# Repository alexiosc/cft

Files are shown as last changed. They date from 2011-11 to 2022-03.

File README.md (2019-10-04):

CFT Logo

# The CFT Home-Brew 16-bit Mini-Computer

The CFT is a home-designed, home-built mini-computer made from
scratch.

I've designed and built the instruction set, data path, processor,
computer, software stack, cross-assembler, emulator, software
toolchain and even some of the tools needed to do all this. You can
call this a ‘fantasy mini’.

This project has been going since approximately 2001, in my Copious
Free Time.

## Audience

There isn't one, so I couldn't tell you what it's like. This project
has been online since 2005 and it's been noticed by four or five
people. Not quite enough for statistics.

**This is a personal project, and the repository is made public as a
curiosity. Expect everything to be wrong, broken, or dangerous.**

## Why?

Because it's fun.

To see how it's done.

To recall Those Heady Times.

To prove to myself I can do this.

## What?

The CFT is a long-term project built in my Copious Free Time. (a term used, as
always, sarcastically, hence the name) It's a homebrew, self-designed,
self-built Sixties-style 16-bit mini computer built out of 74-family integrated
circuits. Check out the
[ChangeLog](https://github.com/alexiosc/cft/blob/master/Changelog) for the
current status.

There may possibly be more stuff to look at, at https://www.bedroomlan.org/cft.

The project consists of:

* The CFT processor.
* Peripherals and cards, some implementing extensions to the CFT instruction set.
* A front panel with blinkenlights.
* A case for the lot.
* Documentation for everything, including the website and this.
* A cross-toolchain for working on the computer from a PC.

### The CFT Processor

* A 4 MHz clock. (250ns processor cycle)
* 16-bit word length. No byte access.
* 24-bit memory address bus.
* 16-bit I/O bus shared with the address bus. (the lower 1,024 addresses are easier to use)
* All instructions are exactly one 16-bit word long.
* Some instructions follow the PDP-8 ‘microcoded’ format with bitfields cotrolling combinations of actions. Bitwise negation, two's complement negation and incrementation are the same instruction with slightly different options.
* A relatively simple instruction set inspired by the PDP-8. This has moved on
  to something slightly more reminiscent of a modern processor.
* Microcoded design.
* Accumulator based architecture.
* Four user-accessible 16-bit registers with increment and decrement. Only the
  Accumulator (AC) is general purpose.
* PDP-8 style magic addresses working like auto-increment or auto-decrement
  index registers, or stack pointers.

### Peripherals

I originally sat down with Eagle CAD and went *crazy* with it. I had 50 sheets
of schematics for boards, all with a three-letter designator:

* MEM: A memory board with 512 KWords of RAM and 512 KWords of ROM.
* TTY: A quadruple serial board including both DCE and DTE
  connections, and a TTL one for an FTDI USB adaptor.
* INT: 8-interrupt controller board.
* IDE: Twin IDE bus interface for up to four drives.
* RTC: A real-time card with some NVRAM and three or six programmable timers.
* ETH: An offloaded Ethernet interface using the WIZ812 chip.
* KBD: A PS/2 Keyboard interface in pure discrete logic.
* PSG: A sound board with one or two AY-3-8910 chips and a SpeakJet® speech synthesiser.
* PFP: A Programmer's Front Panel capable of debugging microcode as well as full machine code.
* DEB: A DEBugging card to help diagnose problems with the hardware
  using a remote controller. (this was basically a simple, slow, specialised logic analyser)
* FDC: A Floppy Drive Controller for up to four drives, including 8-inch 50-pin ones.
* GIO: General Purpose I/O board including some digital I/O, two
  Atari-style digital joystick ports, a unidirectional parallel
  printer port, four user-controllable LEDs on the front panel (the
  PFP already had 16) and (on a whim) a cassette tape interface.
* MBU: processor extension to allow 21-bit memory addressing (up to 2 MWords).
* µCB: processor extension to allow multiple versions of microcode to co-exist. (I had spare space in the Microcode ROMs)
* VDU: a graphics card that does text at 80×25 and 40×25, and graphics
  at combinations of 160, 320, 640 columns and 100, 200, 400 rows with
  64 colours.

The currently planned peripherals are much more modest in scope, but
they also morphed quite a bit. The processor can now do 24-bit
addressing natively, the current microcode uses all of the available
ROM space and a bunch of cards have joined forces. The current state
of affairs looks like this:

* MEM: (tentative design) 512 kWords or 1 MWord of RAM, 512 KWords of
  ROM. Multiple cards can be installed. If density allows, there'll be
  more chip sockets for RAM.
* INT: 8 interrupt controller board.
* DFP: a big card containing both a remote debugging system and front panel drivers.
* TTY: serial port card, possibly colocated with…
* IDE: one or two IDE sockets for two or four IDE drives. (or CF
  cards, but I like the possibility of having some clunky old drive)
* SND: MIDI sound output. Possibly collocated with…
* VDU: a graphics card that does text at 80×30 and 40×30, and graphics
  at combinations of 160, 320, 640 columns and 120, 240, 480 rows
  using 64 colours. The new VDU card fits inside a CPLD and also
  includes a PS/2 interface.
* RTC: Real-time clock, timers.

I've built the MEM and DFP boards to pre-2019 specs and the computer was
working on them.

The 2019 redesign goes for proper PCBs for everything, so things are
taking a little extra time.

### Front Panel

I was really proud of the front panel before the 2019 redesign, it
worked great and showed the computer's entire status. There's support
for up to 160 lights, 31 switches and two keylocks for that PDP-8
feel.

The downside was the wiring: there were no fewer than *five* 50-wire
ribbon cables going to this crazy bastard.

The 2019 redesign keeps the layout, but can no longer display as much
of the computer's status on the front panel. I'm working on it. On the
upside, it now serialises data transmission and only a single 40-pin
cable is needed.

To cut costs, the original front panel was made out of eight modules,
each with up to 20 LEDs. The new front panel is made out of four
modules, each with up to 40 LEDs. Each module daisy-chains to the
next.

Switches are mounted on a separate plate and wired to a break-out
board, or the closest front panel modules on the 2019 version.

### The Case

Two words: wood paneling. Well, and a black acrylic front piece. The
rest will depend on how big the card cage gets, but I'll scratch make
the case out of sheet aluminium and wood.

### Documentation

There's just too much of it. The documentation was initially in LaTeX
and got up to 500 pages before I gave that up and started converting
it to HTML.

The 2019 redesign will need a redo of most of this, sadly, but the
current documents for hardware that's currently around are available
at https://www.bedroomlan.org/hardware/cft/book/.

### Software and Hardware Tools

I had to make my own tools for some of this, and *wanted* to make my
own for some other parts.

Hardware tools include
[Flashprog](https://www.bedroomlan.org/hardware/flashprog/), a
zero-parts flash programmer with a modern serial interface. The
interface formed the basis of the DEB and DFP cards' remote debugging
interface and I'm quite happy with it.

Software tools include:

*  The [Microcode Assembler](https://www.bedroomlan.org/projects/mcasm/),
   also available on Github as https://github.com/alexiosc/mcasm.
*  The CFT Assembler, written purely in Python and roughly based on
   PDP-8 Assemblers, but with some modern extras like namespaces and
   simple macros.
*  Too many emulators to speak of!
   * A basic microcode-level emulator in Python to verify the original
          design. This one is dead and buried, but still in the repository.
   * A Verilog emulator used to verify the hardware.
   * A C emulator that's fast enough to run software on.
   * A [Javascript microcode-level emulator](https://www.bedroomlan.org/hardware/cft/microcode-emulator/)
          that runs on the web. It's very slow, but it shows how the front
          panel works.
   * A newer JS-based emulator meant to me much faster. Still
          largely in the works, because I prefer the C-based emulator for
          testing.
* A testing framework that can run test suites on any emulator we can use.
* A basic Operating System for the CFT.
* A self-documenting Forth interpreter written in Assembly and Forth.

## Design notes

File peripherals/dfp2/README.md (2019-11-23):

# DFP: Debugging Front Panel Version 2

This is the DFP 2, a combination of the Debugging Board (DEB) and
Programmer's Front Panel Board (PFP). It provides two-way bridging
between:

1. The CFT Computer or *parts* of the computer.
2. The Front Panel.
3. A remote computer (or human) performing tests and diagnostics.

The third component is optional.



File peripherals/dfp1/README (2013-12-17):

CFT COMBINATION FRONT PANEL AND REMOTE DEBUGGING / TESTING BOARD

==NAME/DESIGNATION==

To be decided.

==FEATURES==

The PFP combines and acts on instructions coming from three sources:

* The front panel switches.
* The debugging serial port.
* The CFT processor itself.

There are two modes of operation:

* Processor mode: the processor is present and is mostly used as the
  bus master by driving its control signals directly.

* Standalone mode: the processor is absent. The board drives the
  address and data buses directly.

==STATE==

===Power On State===

* Start on power on?
  - If FPRAM# switch in RAM position, start halted
  - Otherwise, start running

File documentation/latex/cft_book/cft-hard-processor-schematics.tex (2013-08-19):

The following page shows the full schematic drawings of the three processor boards.

\cleardoublepage
\phantomsection\stepcounter{section}%
\addcontentsline{toc}{section}{\protect\numberline{\thesection} Processor Board A Schematics}

\includeschns{2}{Clock Generation and control}{sch:clock}
\includeschns{3}{Reset Handling and Sequencing}{sch:reset}
\includeschns{4}{Microcode Sequencer}{sch:useq}
\includeschns{5}{Microcode Sequencer Signal Hold}{sch:useq-hold}
\includeschns{7}{Read and Write Unit Decoding}{sch:unit-decoders}
\includeschns{8}{Skip and Branch Logic}{sch:sbu}
\includeschns{9}{Address Generation Logic}{sch:agl}
\includeschns{10}{Instruction Register}{sch:ir}
\includeschns{11}{Interrupt State Machine}{sch:intsm}
\includeschns{12}{Data Bus Driver and Bus Termination}{sch:databus}
\includeschns{6}{Microcode Sequencer Front Panel Buffers and Connectors}{sch:useq-fp}

\phantomsection\stepcounter{section}%
\addcontentsline{toc}{section}{\protect\numberline{\thesection} Processor Board B Schematics}

\includeschns{13}{Address Register, Address Bus Drivers \& Termination, Autoindex Logic and Device Decoder}{sch:ar}
\includeschns{14}{Program Counter}{sch:pc}
\includeschns{15}{Data Register}{sch:dr}
\includeschns{16}{Accumulator, Zero Flag and Negative Flag}{sch:ac}

\phantomsection\stepcounter{section}%
\addcontentsline{toc}{section}{\protect\numberline{\thesection} Processor Board C Schematics}

\includeschns{17}{Link Register}{sch:l}
\includeschns{18}{Arithmetic/Logic Unit: Decoders and Buffers}{sch:aludecoder}
\includeschns{19}{ALU Binary Operators}{sch:alub}
\includeschns{20}{ALU Unary Operators and Constant Store}{sch:aluu}
\includeschns{21}{8 kW Bank Switching Memory Controller}{sch:mbu}

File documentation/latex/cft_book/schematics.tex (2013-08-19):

This chapter collects the full CFT schematics, in their latest
revision, including all peripherals. Please note that many schematics
are in various stages of incompleteness.

The state of each sheet of the schematics, including other details can
be found according to the key on the first sheet:

\begin{figure}[h!]
  \centering
  
  \caption{\label{fig:schematic-legend}Schematic legend, explaining
    various markings and notation.}
\end{figure}

\newpage

\phantomsection\stepcounter{section}%
\addcontentsline{toc}{section}{\protect\numberline{\thesection} Processor Board A Schematics}

%% %\includesch{1}{Schematic cover page}{sch2:cover}
%% \includesch{2}{Clock Generation and control}{sch2:clock}
%% \includesch{3}{Reset Handling and Sequencing}{sch2:reset}
%% \includesch{4}{Microcode Sequencer}{sch2:useq}
%% \includesch{5}{Microcode Sequencer Signal Hold}{sch2:useq-hold}
%% \includesch{6}{Microcode Sequencer Front Panel Buffers}{sch2:useq-fp}
%% \includesch{7}{Read and Write Unit Decoding}{sch2:unit-decoders}
%% \includesch{8}{Skip and Branch Logic}{sch2:sbu}
%% \includesch{9}{Address Generation Logic}{sch2:agl}
%% \includesch{10}{Instruction Register}{sch2:ir}
%% \includesch{11}{Interrupt State Machine}{sch2:intsm}
%% \includesch{12}{Data Bus Driver and Bus Termination}{sch2:databus}

\phantomsection\stepcounter{section}%
\addcontentsline{toc}{section}{\protect\numberline{\thesection} Processor Board B Schematics}

%% \includesch{13}{Address Register, Address Bus Drivers \& Termination, Autoindex Logic and Device Decoder}{sch2:ar}
%% \includesch{14}{Program Counter}{sch2:pc}
%% \includesch{15}{Data Register}{sch2:dr}
%% \includesch{16}{Accumulator, Zero Flag and Negative Flag}{sch2:ac}

\phantomsection\stepcounter{section}%
\addcontentsline{toc}{section}{\protect\numberline{\thesection} Processor Board C Schematics}

%% \includesch{17}{Link Register}{sch2:l}
%% \includesch{18}{Arithmetic/Logic Unit: Decoders and Buffers}{sch2:aludecoder}
%% \includesch{19}{ALU Binary Operators}{sch2:alub}
%% \includesch{20}{ALU Unary Operators and Constant Store}{sch2:aluu}
%% \includesch{21}{8 kW Bank Switching Memory Controller}{sch2:mbu}

\phantomsection\stepcounter{section}%
\addcontentsline{toc}{section}{\protect\numberline{\thesection} Peripheral Schematics}

\includesch{22}{Interrupt Controller}{sch2:intc}
\includesch{23}{Control Bus Connectors}{sch2:cbus}
%%%\includesch{24}{Memory (RAM and ROM)}{sch2:memory}
\includesch{25}{RS-232 and TTL Serial Ports}{sch2:tty}
\includesch{26}{IDE Bus Interface}{sch2:ide}
\includesch{27}{Clock, Timers and NVRAM}{sch2:rtc}
\includesch{28}{Ethernet Interface}{sch2:eth}
\includesch{29}{PS/2 Keyboard Controller}{sch2:kbd}
\includesch{30}{Audio Device, bus interface and SpeakJet™}{sch2:sjs}
\includesch{31}{Audio Device, AY-3-8910 PSG}{sch2:psg}
%%%\includesch{42}{Debugging Board}{sch2:deb}

\phantomsection\stepcounter{section}%
\addcontentsline{toc}{section}{\protect\numberline{\thesection} Front Panel Schematics}

\includesch{32}{Front Panel: LEDs}{sch2:fp-leds}
\includesch{33}{Front Panel: Switch Register and Switches}{sch2:fp-switches}
%\includesch{34}{Front Panel: Switch Register and Switches}{sch2:fp-switches2}
\includesch{35}{Front Panel: Step switch auto-repeat}{sch2:fp-step-autorepeat}
%\includesch{36}{Front Panel: Switch Register and Switches}{sch2:fp-switches3}
%\includesch{37}{Front Panel: LEDs}{sch2:fp-leds2a}
\includesch{38}{Front Panel: Multi-Function Display Buffers}{sch2:fp-mfd}
\includesch{39}{Front Panel: Interrupt LED}{sch2:fp-irq-led-delay}
\includesch{40}{Front Panel: Connectors}{sch2:fp-con}
\includesch{41}{Front Panel: System Device}{sch2:pfp}

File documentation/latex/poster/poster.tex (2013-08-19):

% -*- latex -*-
\documentclass[12pt,a4paper]{article}
\usepackage[a4paper,CJKbookmarks,bookmarks=true,bookmarksopen=true,pdfpagelabels,pdfstartpage=1]{hyperref}
\usepackage{pdftricks}
\usepackage{pdfpages}
\usepackage{ifthen}
\usepackage[includefoot]{geometry}
\usepackage{color}
\usepackage[absolute]{textpos}
\usepackage{fontspec}
\usepackage{layout}
\usepackage{calc}
\usepackage{rotating}
\usepackage{tikz}
\usetikzlibrary{arrows,positioning,automata,shadows,fit,shapes}
\usepackage{tikz-timing}[2009/07/28]
\usetikztiminglibrary{either}[2009/07/28]
\tikzset{timing/z/.append style={black},}
\tikzset{timing/.append style={x=1ex, y=2ex, line cap=round, line join=round, line width=1.3pt}}
\tikzset{timing/slope=0.33}
%\usepackage[tocindentauto]{tocstyle}

%\usepackage[cam,a4,center]{crop}

\definecolor{r0}{rgb}{0.33, 0.1, 0.1}
\definecolor{r1}{rgb}{1, 0.3, 0.3}

\definecolor{g0}{rgb}{0.1, 0.33, 0.1}
\definecolor{g1}{rgb}{0.3, 1, 0.3}

\definecolor{cftdark}{cmyk}{0,0.42,0.72,0.84}
\definecolor{cftoutline}{cmyk}{0,0.43,0.72,0.53}
\definecolor{cftlight}{cmyk}{0,0.43,0.72,0.22}
\definecolor{cfthl}{rgb}{.89,.698,.529}
\newcommand{\zebrarow}[1]{\rowcolors{#1}{cfthl!50}{cfthl!25}}
\newcommand\zebra{\zebrarow{2}}
\newcommand\zebrahdr{\zebrarow{1}}
%\newcommand\zebra*[1]{\rowcolors{#1}{gray!10}{white}}

\definecolor{darkblue}{RGB}{0,0,128}
\hypersetup{
    pdftitle={CFT Minicomputer Programming Guide},
    pdfauthor={Alexios Chouchoulas},
    pdfkeywords={},
    bookmarksnumbered,
    pagebackref=true,
    breaklinks=true,
%    pdfview=FitH,       % Or try pdfstartview={FitV}, This lead to uncorrect bookmarks
    urlcolor=darkblue,
    colorlinks=true,
    citecolor=cftoutline,          %citeref's color
    linkcolor=cftoutline,
        }

\geometry{a4paper, landscape, hoffset=0in, left=0mm, right=0mm,
  top=0mm, bottom=0mm, includefoot, footskip=0pt}

\setmainfont{Minion Pro}
\setsansfont{Myriad Pro}
\setmonofont[]{Inconsolata}

\begin{document}
\thispagestyle{empty}
\pagestyle{empty}

\definecolor{cff0000}{RGB}{255,0,0}
\definecolor{bgcolor}{RGB}{64, 64, 64}
\definecolor{ltcolor}{RGB}{128, 128, 128}
\definecolor{shcolor}{RGB}{0, 0, 0}
\color{ltcolor}
\sf

\newcommand\shadowtext[2]{%
  \foreach \n in {0,...,5}{
    \begin{scope}[xshift=1 * \n pt, yshift=-1 * \n pt, opacity=0.5 - 0.1 * \n]
      \node[#1]{#2};
    \end{scope}
  }
  \node[#1]{#2};
}

\begin{tikzpicture}[remember picture,overlay]
  \node[yshift=-\paperheight, draw opacity=0] at (current page.north west)
       {\begin{tikzpicture}[remember picture, overlay]
           \draw[fill=bgcolor] (0,0) rectangle
           (\paperwidth,\paperheight);
           \node[anchor=north west, xshift=0.05\textwidth,yshift=0.9\textheight]
                {};
                %
           \shadowtext{xshift=0.5\textwidth, yshift=0.5\textheight}{%
             \scalebox{2}{\Large\rm The CFT Project in Numbers}}
%           \shadowtext{xshift=0.5\textwidth, yshift=0.5\textwidth}{%
%             \scalebox{2}{\Large\rm\color{red}{The CFT Project in Numbers}}}

                %% \draw[fill=cftoutline] (0,1cm) rectangle
                %% (\paperwidth,0);
                %% \node[anchor=east,yshift=0.5\paperheight,xshift=.87\paperwidth,rectangle]
                %%      {\scalebox{2}{\color{white}foo bar}};
                %%      \node[anchor=east,yshift=0.43\paperheight,xshift=.87\paperwidth,rectangle]
                %%           {\scalebox{1.5}{\color{white} bar}};
         \end{tikzpicture}
       };
\end{tikzpicture}

\end{document}

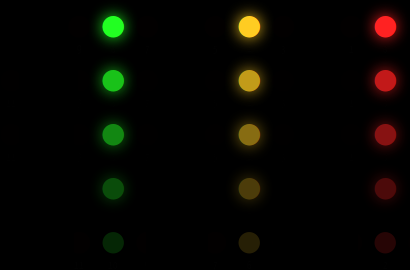
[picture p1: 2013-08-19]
js/v2/images/leds.png

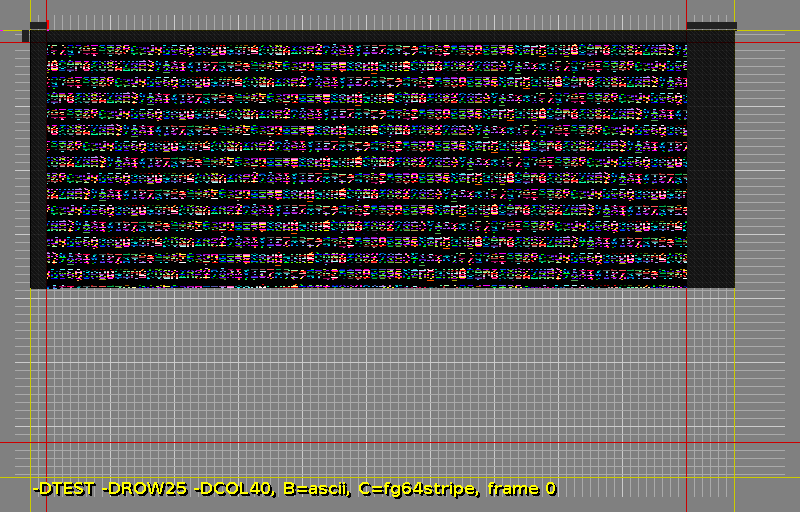
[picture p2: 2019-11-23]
peripherals/vdu/verilog/vdu-0.bmp

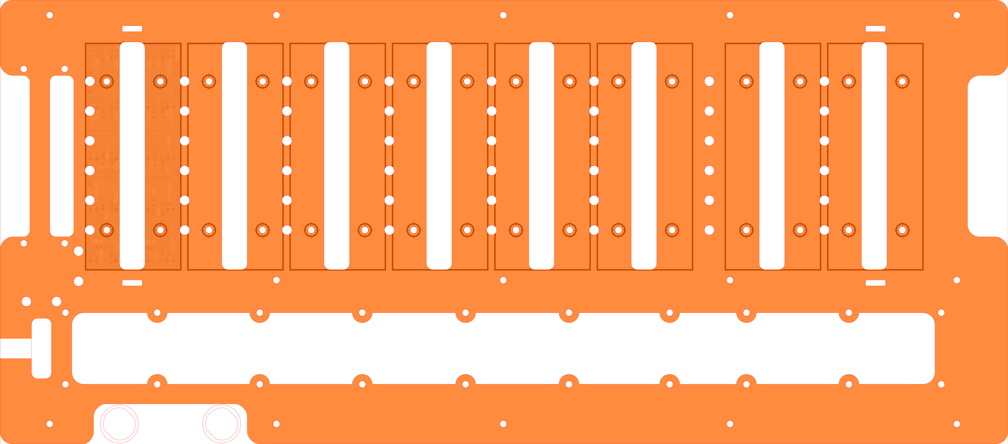
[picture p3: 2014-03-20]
documentation/case/textures/use38783.png

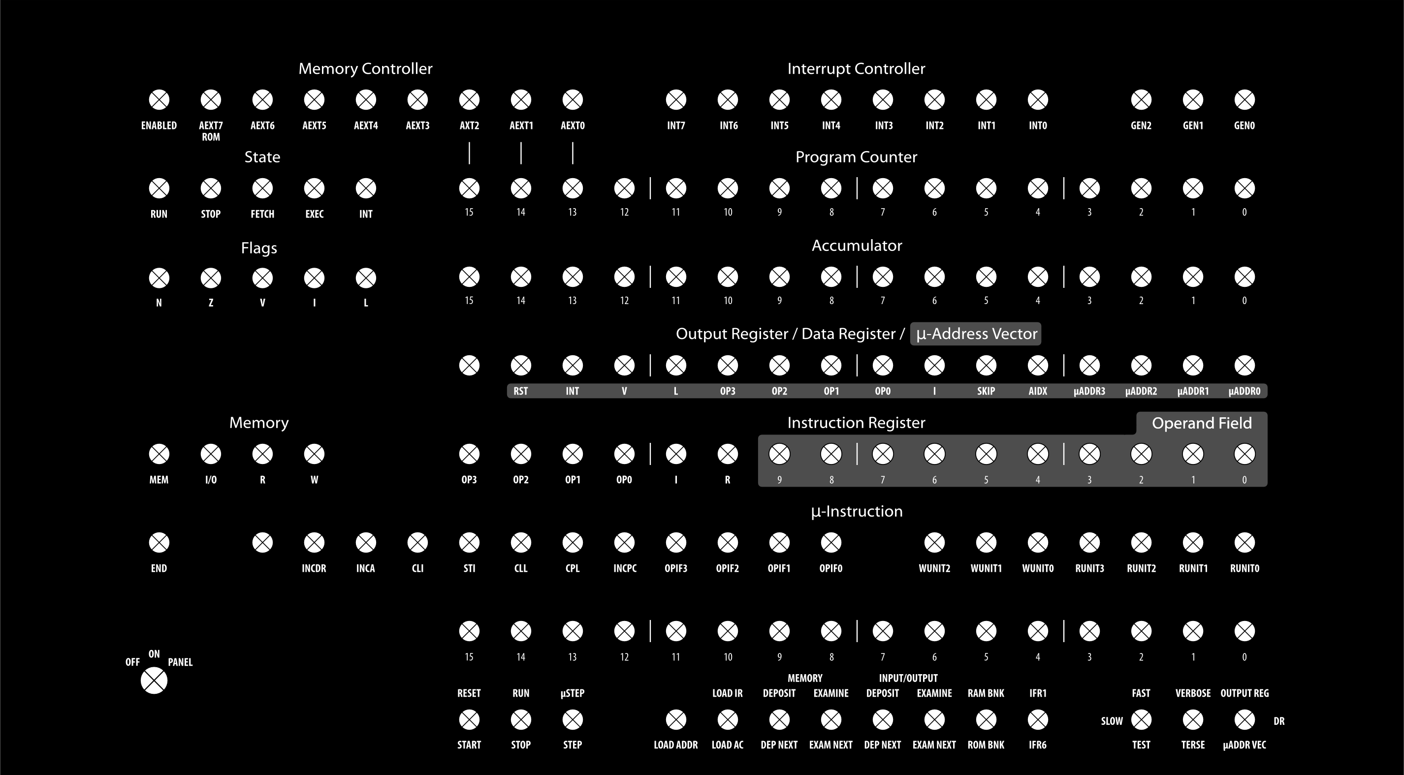
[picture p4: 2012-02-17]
documentation/panel/front-panel-no-lights.png

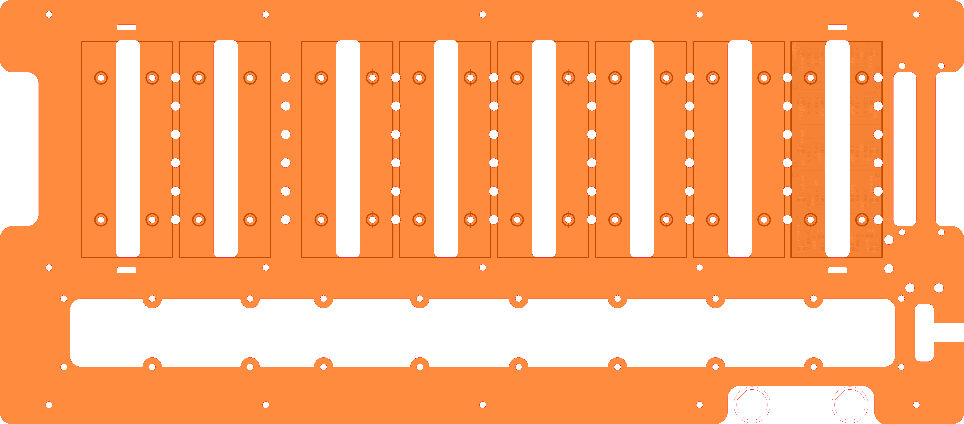
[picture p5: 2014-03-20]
documentation/case/textures/use38783-flipped.png

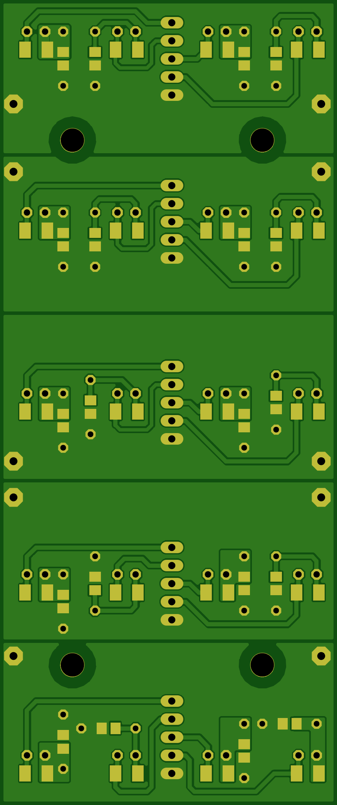
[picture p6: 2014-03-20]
documentation/case/textures/front-panel-module-revC-bottom.png

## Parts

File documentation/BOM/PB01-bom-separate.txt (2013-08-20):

Partlist exported from /home/alexios/eagle/CFT/CFT-PB0-revE-TSSOP.sch at 20 Aug 2013 00:50:35

Qty Value              Device             Parts
-28  0.1uF              C-EUC0805K        
-9   1uF                C-EUC0805K         C4, C8, C10, C15, C23, C32, C35, C36, C37
-17  4k7                R-EU_R0805         R1, R2, R5, R6, R8, R9, R10, R11, R14, R15, R16, R17, R18, R19, R20, R21, R22
-3   29F040             29F040PLCC32       IC4, IC6, IC7
-5   30R                R-EU_R0805         R3, R4, R7, R12, R13
-3   74AC16244DGG       74AC16244DGG       IC20, IC21, IC22
-2   74AHC1G32DBV       74AHC1G32DBV       IC1, IC13
-1   74HC74D            74HC74D            IC17
-3   74HC138D           74HC138D           IC9, IC10, IC14
-1   74HC157D           74HC157/ALT-D      IC18
-3   74HC175D           74HC175D           IC15, IC16, IC19
-2   74HC541DW          74HC541DW          IC11, IC12
-3   2540-5             2540-5             P1, P2, P3
-1   SN74ACT1071D       SN74ACT1071D       IC26
-3   SN74ACT1073        SN74ACT1073        IC23, IC24, IC25

2   47uF               CPOL-EUE2.5-5      667-ECE-A1AKG470

1                      VG96-3K            EXP
3   4k7                CTS742C083         RN12, RN13, RN14
6   10k                CTS742C083         RN16, RN17, RN18, RN19, RN20, RN21
12  30R                CTS742C083         RN1, RN2, RN3, RN4, RN5, RN6, RN7, RN8, RN9, RN10, RN11, RN15
1   74AHC1G00DBV       74AHC1G00DBV       IC5
1   74AHC1G04DBV       74AHC1G04DBV       IC8
1   74AHC1G08DBV       74AHC1G08DBV       IC2
1   74HC161D           74HC161D           IC3

Partlist exported from /home/alexios/eagle/CFT/CFT-PB1-revD-TSSOP.sch at 20 Aug 2013 00:50:49

Qty Value         Device          Parts
-37  0.1uF         C-EUC0805K      C1, C2, C3, C5, C6, C7, ...
-8   1uF           C-EUC0805K      C4, C9, C12, C30, C34, C39, C45, C54
-9   4k7           R-EU_R0805      R1, R2, R4, R5, R11, R12, R13, R40, R48
-1   16.000MHz     XO-08-SOCKET    XTAL1
-3   30R           R-EU_R0805      R14, R41, R51
-3   74AC1G11DBV   74AC1G11DBV     IC20, IC34, IC39
-2   74AHC1G32DBV  74AHC1G32DBV    IC30, IC32
-6   74HC541DW     74HC541DW       IC6, IC7, IC8, IC23, IC24, IC27
-3   2540-5        2540-5          P1, P2, P3
-2   SN74ACT1071D  SN74ACT1071D    IC41, IC42

1                  DIP8 socket   
1   1uF-47uF      CPOL-EUE2.5-5   667-ECE-A1AKG470
2   47uF          CPOL-EUE2.5-5   667-ECE-A1AKG470

3  1N4148         DIODE-SOD123    D1, D2, D3
1                 TAC_SWITCHPTH   611-PTS645SL43LFS
1                 VG96-3K         EXP1
2   4k7           CTS742C083      RN1, RN19
1   50k           R-EU_R0805      R9
1   74AC1G27DBV   74AC1G27DBV     IC38
2   74AC04D       74AC04D         IC9, IC37
1   74AHC1G04DBV  74AHC1G04DBV    IC17
1   74AHC1G08DBV  74AHC1G08DBV    IC29
1   74AHC1G14DBV  74AHC1G14DBV    IC4
1   74AHC1G86DBV  74AHC1G86DBV    IC15
1   74HC08D       74HC08D         IC13
2   74HC32D       74HC32D         IC14, IC16
3   74HC74D       74HC74D         IC21, IC33, IC40
1   74HC112D      74HC112D        IC31
1   74HC139D      74HC139D        IC3
1   74HC193D      74HC193D        IC2
2   74HC245DW     74HC245DW       IC35, IC36
2   74HC251D      74HC251D        IC18, IC19
1   74HC253D      74HC253D        IC1
2   74HC573D      74HC573D        IC25, IC26
1   74HC574D      74HC574D        IC22
1   74HC590D      74HC590D        IC5
4   330R          R-EU_R0805      R3, R10, R49, R50
4   LED-5MM-GREEN LEDCHIPLED_0805 LED1, LED2, LED3, LED4

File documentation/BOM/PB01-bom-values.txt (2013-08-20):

-65  0.1uF         C-EUC0805K      C1, C2, C3, C5, C6, C7, ...
-17  1uF           C-EUC0805K      C4, C9, C12, C30, C34, C39, C45, C54
-26  4k7           R-EU_R0805      R1, R2, R4, R5, R11, R12, R13, R40, R48
-1   16.000MHz     XO-08-SOCKET    XTAL1
-3   30R           R-EU_R0805      R14, R41, R51
-3   74AC1G11DBV   74AC1G11DBV     IC20, IC34, IC39
-4   74AHC1G32DBV  74AHC1G32DBV    IC30, IC32
-8   74HC541DW     74HC541DW       IC6, IC7, IC8, IC23, IC24, IC27
-6   2540-5        2540-5          P1, P2, P3
-3   SN74ACT1071D  SN74ACT1071D    IC41, IC42
-3   SN74ACT1073        SN74ACT1073        IC23, IC24, IC25

-3   29F040             29F040PLCC32       IC4, IC6, IC7
-5   30R                R-EU_R0805         R3, R4, R7, R12, R13
-3   74AC16244DGG       74AC16244DGG       IC20, IC21, IC22
-4   74HC74D            74HC74D            IC17
-3   74HC138D           74HC138D           IC9, IC10, IC14
-1   74HC157D           74HC157/ALT-D      IC18
-3   74HC175D           74HC175D           IC15, IC16, IC19

-------------------------------------------------------------------------------

1  +5   1uF-47uF      CPOL-EUE2.5-5   667-ECE-A1AKG470
     47uF          CPOL-EUE2.5-5   667-ECE-A1AKG470
     47uF          CPOL-EUE2.5-5   667-ECE-A1AKG470
2  +2                 VG96-3K         EXP
3  +5   4k7                CTS742C083         RN12, RN13, RN14
4  +6   10k                CTS742C083         RN16, RN17, RN18, RN19, RN20, RN21
5  +12  30R                CTS742C083         *** 33R
6  +4   330R          R-EU_R0805      R3, R10, R49, R50
7  +4   LED-5MM-GREEN LEDCHIPLED_0805 LED1, LED2, LED3, LED4
8  +3  1N4148         DIODE-SOD123    D1, D2, D3
9  +1                  DIP8 socket   
10 +1   74AHC1G00DBV       74AHC1G00DBV       *** LVC
11 +2   74AHC1G04DBV       74AHC1G04DBV       IC8
12 +2   74AHC1G08DBV       74AHC1G08DBV       IC2
13 +1   74HC161D           74HC161D           IC3
14 +1                 TAC_SWITCHPTH   611-PTS645SL43LFS
15 +1   50k           R-EU_R0805      ** 47k
16 +1   74AC1G27DBV   74AC1G27DBV     IC38
17 +2   74AC04D       74AC04D         IC9, IC37
18 +1   74AHC1G14DBV  74AHC1G14DBV    IC4
19 +1   74AHC1G86DBV  74AHC1G86DBV    IC15
20 +1   74HC08D       74HC08D         IC13
21 +2   74HC32D       74HC32D         IC14, IC16
22 +1   74HC112D      74HC112D        IC31
23 +1   74HC139D      74HC139D        IC3
24 +1   74HC193D      74HC193D        IC2
25 +2   74HC245DW     74HC245DW       IC35, IC36
26 +2   74HC251D      74HC251D        IC18, IC19
27 +1   74HC253D      74HC253D        IC1
28 +2   74HC573D      74HC573D        IC25, IC26
29 +1   74HC574D      74HC574D        IC22
30 +1   74HC590D      74HC590D        IC5

com 12  vkdg olympic isogeia ikea  8-13

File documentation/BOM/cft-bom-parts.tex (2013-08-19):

\schpt{C1}–\schpt{C3} & 0.1μF ceramic capacitor & Farnell US 1694337 (£0.019@100), RS 721-5240 (£0.051@50), Farnell 1694337 (£0.019@100) &  \\
\schpt{C4} & 10 µF electrolytic capacitor & Farnell 1902928 (£0.033), RS 440-6547 (£0.026@50) &  \\
\schpt{C5} & 0.1μF ceramic capacitor & Farnell US 1694337 (£0.019@100), RS 721-5240 (£0.051@50), Farnell 1694337 (£0.019@100) &  \\
\schpt{C6} & 10nF Ceramic Capacitor & Farnell US 1694335 (£0.016@10), Farnell 9411852 (£0.059@25) &  \\
\schpt{C7} & 1μF capacitor & Farnell US 1600879 (£0.041@25), Farnell 3322210 (£0.148), RS 538-1578 (£0.292), Farnell 1100398 (£0.38) &  \\
\schpt{C8} & 0.1μF ceramic capacitor & Farnell US 1694337 (£0.019@100), RS 721-5240 (£0.051@50), Farnell 1694337 (£0.019@100) &  \\
\schpt{C9} & 10 µF electrolytic capacitor & Farnell 1902928 (£0.033), RS 440-6547 (£0.026@50) &  \\
\schpt{C10} & 10nF Ceramic Capacitor & Farnell US 1694335 (£0.016@10), Farnell 9411852 (£0.059@25) &  \\
\schpt{C11}–\schpt{C16} & 0.1μF ceramic capacitor & Farnell US 1694337 (£0.019@100), RS 721-5240 (£0.051@50), Farnell 1694337 (£0.019@100) &  \\
\schpt{C17} & 1μF capacitor & Farnell US 1600879 (£0.041@25), Farnell 3322210 (£0.148), RS 538-1578 (£0.292), Farnell 1100398 (£0.38) &  \\
\schpt{C18}–\schpt{C23} & 0.1μF ceramic capacitor & Farnell US 1694337 (£0.019@100), RS 721-5240 (£0.051@50), Farnell 1694337 (£0.019@100) &  \\
\schpt{C24}–\schpt{C27} & 1μF capacitor & Farnell US 1600879 (£0.041@25), Farnell 3322210 (£0.148), RS 538-1578 (£0.292), Farnell 1100398 (£0.38) &  \\
\schpt{C28}–\schpt{C31} & 0.1μF ceramic capacitor & Farnell US 1694337 (£0.019@100), RS 721-5240 (£0.051@50), Farnell 1694337 (£0.019@100) &  \\
\schpt{C32} & 1μF capacitor & Farnell US 1600879 (£0.041@25), Farnell 3322210 (£0.148), RS 538-1578 (£0.292), Farnell 1100398 (£0.38) &  \\
\schpt{C33}–\schpt{C40} & 0.1μF ceramic capacitor & Farnell US 1694337 (£0.019@100), RS 721-5240 (£0.051@50), Farnell 1694337 (£0.019@100) &  \\
\schpt{C41} & 1μF capacitor & Farnell US 1600879 (£0.041@25), Farnell 3322210 (£0.148), RS 538-1578 (£0.292), Farnell 1100398 (£0.38) &  \\
\schpt{C42}–\schpt{C44} & 0.1μF ceramic capacitor & Farnell US 1694337 (£0.019@100), RS 721-5240 (£0.051@50), Farnell 1694337 (£0.019@100) &  \\
\schpt{C45} & 1μF capacitor & Farnell US 1600879 (£0.041@25), Farnell 3322210 (£0.148), RS 538-1578 (£0.292), Farnell 1100398 (£0.38) &  \\
\schpt{C46}–\schpt{C49} & 0.1μF ceramic capacitor & Farnell US 1694337 (£0.019@100), RS 721-5240 (£0.051@50), Farnell 1694337 (£0.019@100) &  \\
\schpt{C50} & 1μF capacitor & Farnell US 1600879 (£0.041@25), Farnell 3322210 (£0.148), RS 538-1578 (£0.292), Farnell 1100398 (£0.38) &  \\
\schpt{C51}–\schpt{C55} & 0.1μF ceramic capacitor & Farnell US 1694337 (£0.019@100), RS 721-5240 (£0.051@50), Farnell 1694337 (£0.019@100) &  \\
\schpt{C56} & 1μF capacitor & Farnell US 1600879 (£0.041@25), Farnell 3322210 (£0.148), RS 538-1578 (£0.292), Farnell 1100398 (£0.38) &  \\
\schpt{C57}–\schpt{C61} & 0.1μF ceramic capacitor & Farnell US 1694337 (£0.019@100), RS 721-5240 (£0.051@50), Farnell 1694337 (£0.019@100) &  \\
\schpt{C62} & 1μF capacitor & Farnell US 1600879 (£0.041@25), Farnell 3322210 (£0.148), RS 538-1578 (£0.292), Farnell 1100398 (£0.38) &  \\
\schpt{C63}–\schpt{C71} & 0.1μF ceramic capacitor & Farnell US 1694337 (£0.019@100), RS 721-5240 (£0.051@50), Farnell 1694337 (£0.019@100) &  \\
\schpt{C72} & 1μF capacitor & Farnell US 1600879 (£0.041@25), Farnell 3322210 (£0.148), RS 538-1578 (£0.292), Farnell 1100398 (£0.38) &  \\
\schpt{C73}–\schpt{C80} & 0.1μF ceramic capacitor & Farnell US 1694337 (£0.019@100), RS 721-5240 (£0.051@50), Farnell 1694337 (£0.019@100) &  \\
\schpt{C81} & 1μF capacitor & Farnell US 1600879 (£0.041@25), Farnell 3322210 (£0.148), RS 538-1578 (£0.292), Farnell 1100398 (£0.38) &  \\
\schpt{C82}–\schpt{C89} & 0.1μF ceramic capacitor & Farnell US 1694337 (£0.019@100), RS 721-5240 (£0.051@50), Farnell 1694337 (£0.019@100) &  \\
\schpt{C90} & 1μF capacitor & Farnell US 1600879 (£0.041@25), Farnell 3322210 (£0.148), RS 538-1578 (£0.292), Farnell 1100398 (£0.38) &  \\
\schpt{C91}–\schpt{C100} & 0.1μF ceramic capacitor & Farnell US 1694337 (£0.019@100), RS 721-5240 (£0.051@50), Farnell 1694337 (£0.019@100) &  \\
\schpt{C101} & 1μF capacitor & Farnell US 1600879 (£0.041@25), Farnell 3322210 (£0.148), RS 538-1578 (£0.292), Farnell 1100398 (£0.38) &  \\
\schpt{C102}–\schpt{C105} & 0.1μF ceramic capacitor & Farnell US 1694337 (£0.019@100), RS 721-5240 (£0.051@50), Farnell 1694337 (£0.019@100) &  \\
\schpt{C106} & 1μF capacitor & Farnell US 1600879 (£0.041@25), Farnell 3322210 (£0.148), RS 538-1578 (£0.292), Farnell 1100398 (£0.38) &  \\
\schpt{C107}–\schpt{C110} & 0.1μF ceramic capacitor & Farnell US 1694337 (£0.019@100), RS 721-5240 (£0.051@50), Farnell 1694337 (£0.019@100) &  \\
\schpt{C111} & 1μF capacitor & Farnell US 1600879 (£0.041@25), Farnell 3322210 (£0.148), RS 538-1578 (£0.292), Farnell 1100398 (£0.38) &  \\
\schpt{C112}–\schpt{C116} & 0.1μF ceramic capacitor & Farnell US 1694337 (£0.019@100), RS 721-5240 (£0.051@50), Farnell 1694337 (£0.019@100) &  \\
\schpt{C117}–\schpt{C120} & 1μF capacitor & Farnell US 1600879 (£0.041@25), Farnell 3322210 (£0.148), RS 538-1578 (£0.292), Farnell 1100398 (£0.38) &  \\
\schpt{C121}–\schpt{C123} & 0.1μF ceramic capacitor & Farnell US 1694337 (£0.019@100), RS 721-5240 (£0.051@50), Farnell 1694337 (£0.019@100) &  \\
\schpt{C124}–\schpt{C127} & 1μF capacitor & Farnell US 1600879 (£0.041@25), Farnell 3322210 (£0.148), RS 538-1578 (£0.292), Farnell 1100398 (£0.38) &  \\
\schpt{C128}–\schpt{C142} & 0.1μF ceramic capacitor & Farnell US 1694337 (£0.019@100), RS 721-5240 (£0.051@50), Farnell 1694337 (£0.019@100) &  \\
\schpt{C143} & 1μF capacitor & Farnell US 1600879 (£0.041@25), Farnell 3322210 (£0.148), RS 538-1578 (£0.292), Farnell 1100398 (£0.38) &  \\
\schpt{C144}–\schpt{C155} & 0.1μF ceramic capacitor & Farnell US 1694337 (£0.019@100), RS 721-5240 (£0.051@50), Farnell 1694337 (£0.019@100) &  \\
\schpt{C156} & 1μF capacitor & Farnell US 1600879 (£0.041@25), Farnell 3322210 (£0.148), RS 538-1578 (£0.292), Farnell 1100398 (£0.38) &  \\
\schpt{C157}–\schpt{C162} & 0.1μF ceramic capacitor & Farnell US 1694337 (£0.019@100), RS 721-5240 (£0.051@50), Farnell 1694337 (£0.019@100) &  \\
\schpt{C163}–\schpt{C167} & 1μF capacitor & Farnell US 1600879 (£0.041@25), Farnell 3322210 (£0.148), RS 538-1578 (£0.292), Farnell 1100398 (£0.38) &  \\
\schpt{C168}–\schpt{C169} & 0.1μF ceramic capacitor & Farnell US 1694337 (£0.019@100), RS 721-5240 (£0.051@50), Farnell 1694337 (£0.019@100) &  \\
\schpt{C170} & 1μF capacitor & Farnell US 1600879 (£0.041@25), Farnell 3322210 (£0.148), RS 538-1578 (£0.292), Farnell 1100398 (£0.38) &  \\
\schpt{C171} & 0.1μF ceramic capacitor & Farnell US 1694337 (£0.019@100), RS 721-5240 (£0.051@50), Farnell 1694337 (£0.019@100) &  \\
\schpt{C172}–\schpt{C173} & 1μF capacitor & Farnell US 1600879 (£0.041@25), Farnell 3322210 (£0.148), RS 538-1578 (£0.292), Farnell 1100398 (£0.38) &  \\
\schpt{C174}–\schpt{C185} & 1 μF electrolytic capacitor & Farnell 1236655 (£0.034) & Through hole \\
\schpt{C186}–\schpt{C188} & 10 µF electrolytic capacitor & Farnell 1902928 (£0.033), RS 440-6547 (£0.026@50) &  \\
\schpt{C189}–\schpt{C193} & 0.1μF ceramic capacitor & Farnell US 1694337 (£0.019@100), RS 721-5240 (£0.051@50), Farnell 1694337 (£0.019@100) &  \\
\schpt{C194}–\schpt{C195} & 1μF capacitor & Farnell US 1600879 (£0.041@25), Farnell 3322210 (£0.148), RS 538-1578 (£0.292), Farnell 1100398 (£0.38) &  \\
\schpt{C196}–\schpt{C210} & 0.1μF ceramic capacitor & Farnell US 1694337 (£0.019@100), RS 721-5240 (£0.051@50), Farnell 1694337 (£0.019@100) &  \\
\schpt{C211}–\schpt{C212} & 22 pF ceramic capacitor & Farnell 9411674 (£0.035@25) &  \\
\schpt{C213} & 1μF capacitor & Farnell US 1600879 (£0.041@25), Farnell 3322210 (£0.148), RS 538-1578 (£0.292), Farnell 1100398 (£0.38) &  \\
\schpt{C214}–\schpt{C221} & 0.1μF ceramic capacitor & Farnell US 1694337 (£0.019@100), RS 721-5240 (£0.051@50), Farnell 1694337 (£0.019@100) &  \\
\schpt{C222} & 1μF capacitor & Farnell US 1600879 (£0.041@25), Farnell 3322210 (£0.148), RS 538-1578 (£0.292), Farnell 1100398 (£0.38) &  \\
\schpt{C223}–\schpt{C229} & 0.1μF ceramic capacitor & Farnell US 1694337 (£0.019@100), RS 721-5240 (£0.051@50), Farnell 1694337 (£0.019@100) &  \\
\schpt{C230} & 1μF capacitor & Farnell US 1600879 (£0.041@25), Farnell 3322210 (£0.148), RS 538-1578 (£0.292), Farnell 1100398 (£0.38) &  \\
\schpt{C231} & 10 µF electrolytic capacitor & Farnell 1902928 (£0.033), RS 440-6547 (£0.026@50) &  \\
\schpt{C232}–\schpt{C236} & 0.1μF ceramic capacitor & Farnell US 1694337 (£0.019@100), RS 721-5240 (£0.051@50), Farnell 1694337 (£0.019@100) &  \\
\schpt{C237} & 100nF electrolytic capacitor & Farnell 1902938 (£0.033@10) &  \\
\schpt{C238}–\schpt{C240} & 0.1μF ceramic capacitor & Farnell US 1694337 (£0.019@100), RS 721-5240 (£0.051@50), Farnell 1694337 (£0.019@100) &  \\
\schpt{C241} & 10nF Ceramic Capacitor & Farnell US 1694335 (£0.016@10), Farnell 9411852 (£0.059@25) &  \\
\schpt{C242}–\schpt{C243} & 0.1μF ceramic capacitor & Farnell US 1694337 (£0.019@100), RS 721-5240 (£0.051@50), Farnell 1694337 (£0.019@100) &  \\
\schpt{C244} & 1μF capacitor & Farnell US 1600879 (£0.041@25), Farnell 3322210 (£0.148), RS 538-1578 (£0.292), Farnell 1100398 (£0.38) &  \\
\schpt{C245}–\schpt{C248} & 0.1μF ceramic capacitor & Farnell US 1694337 (£0.019@100), RS 721-5240 (£0.051@50), Farnell 1694337 (£0.019@100) &  \\
\schpt{C249} & 10 µF electrolytic capacitor & Farnell 1902928 (£0.033), RS 440-6547 (£0.026@50) &  \\
\schpt{C250}–\schpt{C253} & 0.1μF ceramic capacitor & Farnell US 1694337 (£0.019@100), RS 721-5240 (£0.051@50), Farnell 1694337 (£0.019@100) &  \\
\schpt{C254} & 1μF capacitor & Farnell US 1600879 (£0.041@25), Farnell 3322210 (£0.148), RS 538-1578 (£0.292), Farnell 1100398 (£0.38) &  \\
\schpt{C255}–\schpt{C256} & 0.1μF ceramic capacitor & Farnell US 1694337 (£0.019@100), RS 721-5240 (£0.051@50), Farnell 1694337 (£0.019@100) &  \\
\schpt{C257}–\schpt{C258} & 1 μF electrolytic capacitor & Farnell 1236655 (£0.034) & Through hole \\
\schpt{C259}–\schpt{C260} & 0.1μF ceramic capacitor & Farnell US 1694337 (£0.019@100), RS 721-5240 (£0.051@50), Farnell 1694337 (£0.019@100) &  \\
\schpt{C261} & 10 µF electrolytic capacitor & Farnell 1902928 (£0.033), RS 440-6547 (£0.026@50) &  \\
\schpt{C262} & 47nF ceramic capacitor & Farnell 1100530 (£0.055@5) &  \\
\schpt{C263} & 220µF electrolytic capacitor & Farnell 1902883 (£0.042@10) &  \\
\schpt{C264}–\schpt{C265} & 0.1μF ceramic capacitor & Farnell US 1694337 (£0.019@100), RS 721-5240 (£0.051@50), Farnell 1694337 (£0.019@100) &  \\
\schpt{C266} & 10 µF electrolytic capacitor & Farnell 1902928 (£0.033), RS 440-6547 (£0.026@50) &  \\
\schpt{C267} & 47nF ceramic capacitor & Farnell 1100530 (£0.055@5) &  \\
\schpt{C268} & 220µF electrolytic capacitor & Farnell 1902883 (£0.042@10) &  \\
\schpt{C269}–\schpt{C272} & 0.1μF ceramic capacitor & Farnell US 1694337 (£0.019@100), RS 721-5240 (£0.051@50), Farnell 1694337 (£0.019@100) &  \\
\schpt{C273} & 1μF capacitor & Farnell US 1600879 (£0.041@25), Farnell 3322210 (£0.148), RS 538-1578 (£0.292), Farnell 1100398 (£0.38) &  \\
\schpt{C274}–\schpt{C277} & 1μF electrolytic capacitor & Farnell 1236655 (£0.034) &  \\
\schpt{C278}–\schpt{C279} & 1μF capacitor & Farnell US 1600879 (£0.041@25), Farnell 3322210 (£0.148), RS 538-1578 (£0.292), Farnell 1100398 (£0.38) &  \\
\schpt{C280} & 0.1μF ceramic capacitor & Farnell US 1694337 (£0.019@100), RS 721-5240 (£0.051@50), Farnell 1694337 (£0.019@100) &  \\
\schpt{C281}–\schpt{C282} & 47µF electrolytic capacitor & Farnell 1902909 (£0.041@10) &  \\
\schpt{C283}–\schpt{C285} & 0.1μF ceramic capacitor & Farnell US 1694337 (£0.019@100), RS 721-5240 (£0.051@50), Farnell 1694337 (£0.019@100) &  \\
\schpt{C286}–\schpt{C293} & 1μF electrolytic capacitor & Farnell 1236655 (£0.034) &  \\
\schpt{C294}–\schpt{C295} & 0.1μF ceramic capacitor & Farnell US 1694337 (£0.019@100), RS 721-5240 (£0.051@50), Farnell 1694337 (£0.019@100) &  \\
\schpt{C296}–\schpt{C299} & 1μF electrolytic capacitor & Farnell 1236655 (£0.034) &  \\
\schpt{C300}–\schpt{C302} & 0.1μF ceramic capacitor & Farnell US 1694337 (£0.019@100), RS 721-5240 (£0.051@50), Farnell 1694337 (£0.019@100) &  \\
\schpt{C303} & 1μF capacitor & Farnell US 1600879 (£0.041@25), Farnell 3322210 (£0.148), RS 538-1578 (£0.292), Farnell 1100398 (£0.38) &  \\
\schpt{C304} & 0.1μF ceramic capacitor & Farnell US 1694337 (£0.019@100), RS 721-5240 (£0.051@50), Farnell 1694337 (£0.019@100) &  \\
\schpt{C305} & 1 μF electrolytic capacitor & Farnell 1236655 (£0.034) & Through hole \\
\schpt{C306}–\schpt{C312} & 0.1μF ceramic capacitor & Farnell US 1694337 (£0.019@100), RS 721-5240 (£0.051@50), Farnell 1694337 (£0.019@100) &  \\
\schpt{C313} & 1μF capacitor & Farnell US 1600879 (£0.041@25), Farnell 3322210 (£0.148), RS 538-1578 (£0.292), Farnell 1100398 (£0.38) &  \\
\schpt{C314}–\schpt{C317} & 0.1μF ceramic capacitor & Farnell US 1694337 (£0.019@100), RS 721-5240 (£0.051@50), Farnell 1694337 (£0.019@100) &  \\
\schpt{C318} & 1μF capacitor & Farnell US 1600879 (£0.041@25), Farnell 3322210 (£0.148), RS 538-1578 (£0.292), Farnell 1100398 (£0.38) &  \\
\schpt{C319}–\schpt{C322} & 10nF Ceramic Capacitor & Farnell US 1694335 (£0.016@10), Farnell 9411852 (£0.059@25) &  \\
\schpt{C323}–\schpt{C326} & 1 μF electrolytic capacitor & Farnell 1236655 (£0.034) & Through hole \\
\schpt{C327}–\schpt{C330} & 10nF Ceramic Capacitor & Farnell US 1694335 (£0.016@10), Farnell 9411852 (£0.059@25) &  \\
\schpt{C331}–\schpt{C334} & 1 μF electrolytic capacitor & Farnell 1236655 (£0.034) & Through hole \\
\schpt{C335} & 10μF/10V Electrolytic capacitor & \href{http://uk.farnell.com/jsp/search/productdetail.jsp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\%2FglobalsearchE14.jsp}{Farnell 1902928} &  \\
\schpt{C336}–\schpt{C345} & 0.1μF ceramic capacitor & Farnell US 1694337 (£0.019@100), RS 721-5240 (£0.051@50), Farnell 1694337 (£0.019@100) &  \\
\schpt{C346} & 1μF capacitor & Farnell US 1600879 (£0.041@25), Farnell 3322210 (£0.148), RS 538-1578 (£0.292), Farnell 1100398 (£0.38) &  \\
\schpt{C347}–\schpt{C351} & 0.1μF ceramic capacitor & Farnell US 1694337 (£0.019@100), RS 721-5240 (£0.051@50), Farnell 1694337 (£0.019@100) &  \\
\schpt{C352} & 1μF capacitor & Farnell US 1600879 (£0.041@25), Farnell 3322210 (£0.148), RS 538-1578 (£0.292), Farnell 1100398 (£0.38) &  \\
\schpt{C353}–\schpt{C362} & 0.1μF ceramic capacitor & Farnell US 1694337 (£0.019@100), RS 721-5240 (£0.051@50), Farnell 1694337 (£0.019@100) &  \\
\schpt{C363} & 1μF capacitor & Farnell US 1600879 (£0.041@25), Farnell 3322210 (£0.148), RS 538-1578 (£0.292), Farnell 1100398 (£0.38) &  \\
\schpt{C364}–\schpt{C367} & 10nF Ceramic Capacitor & Farnell US 1694335 (£0.016@10), Farnell 9411852 (£0.059@25) &  \\
\schpt{C368}–\schpt{C372} & 1 μF electrolytic capacitor & Farnell 1236655 (£0.034) & Through hole \\
\schpt{C373}–\schpt{C377} & 0.1μF ceramic capacitor & Farnell US 1694337 (£0.019@100), RS 721-5240 (£0.051@50), Farnell 1694337 (£0.019@100) &  \\
\schpt{C378}–\schpt{C379} & 33pF ceramic capacitor & Farnell 9411682 (£0.04@25) &  \\
\schpt{C380} & 1μF capacitor & Farnell US 1600879 (£0.041@25), Farnell 3322210 (£0.148), RS 538-1578 (£0.292), Farnell 1100398 (£0.38) &  \\
\schpt{C381} & 0.1μF ceramic capacitor & Farnell US 1694337 (£0.019@100), RS 721-5240 (£0.051@50), Farnell 1694337 (£0.019@100) &  \\
\schpt{C382} & 33pF ceramic capacitor & Farnell 9411682 (£0.04@25) &  \\
\schpt{C383} & 0.1μF ceramic capacitor & Farnell US 1694337 (£0.019@100), RS 721-5240 (£0.051@50), Farnell 1694337 (£0.019@100) &  \\
\schpt{C384}–\schpt{C385} & 22 pF ceramic capacitor & Farnell 9411674 (£0.035@25) &  \\
\schpt{C386} & 0.1μF ceramic capacitor & Farnell US 1694337 (£0.019@100), RS 721-5240 (£0.051@50), Farnell 1694337 (£0.019@100) &  \\
\schpt{C387} & 1 μF electrolytic capacitor & Farnell 1236655 (£0.034) & Through hole \\
\schpt{CON1}–\schpt{CON10} & 8x1 pin 2.54mm centre header & Farnell 1756826 (£0.122@10) + Farnell 3991271 (£0.179@10) & Molex KK® series header \\
\schpt{CON11}–\schpt{CON12} & DB9 male or 2×5 pin header & Farnell 1099289 (£0.48@5) &  \\
\schpt{CON13} & DB9 female or 2×5-pin header & Farnell 1099294 (£0.48@5) &  \\
\schpt{CON14}–\schpt{CON15} & 2x20 pin shrouded header & RS 670-1825 (£0.972@5), Farnell 1099261 (£1.07), Farnell US 1258972 (£0.66), Farnell US 2067726 (£0.913) & IDE socket \\
\schpt{CON16}–\schpt{CON22} & 8x1 pin 2.54mm centre header & Farnell 1756826 (£0.122@10) + Farnell 3991271 (£0.179@10) & Molex KK® series header \\
\schpt{CON23} & 9x1 pin 2.54mm centre header & \href{http://uk.farnell.com/jsp/search/productdetail.jsp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\%2FglobalsearchE14.jsp}{Farnell 1756827} & Molex KK® series header \\
\schpt{CON24}–\schpt{CON28} & 8x1 pin 2.54mm centre header & Farnell 1756826 (£0.122@10) + Farnell 3991271 (£0.179@10) & Molex KK® series header \\
\schpt{D1} & 1N5817 Schottky barrier rectifier & Farnell 1843507 (£0.023) &  \\
\schpt{D2} & 1N4002 diode & Farnell US 1924512 (£0.022@10), Farnell 1651083 (£0.056), Farnell 1651083 (£0.053@25) &  \\
\schpt{D3}–\schpt{D5} & 1N4148 diode & Farnell 9565124 (£0.011), RS 436-7341 (£0.003@100) & Or any fast signal diode \\
\schpt{EXP} & 96-pin (A+B+C) DIN-41612 Bauform ‘C’ plug & Farnell 1656159 (£1.84) & Right angle through hole \\
\schpt{EXP1} & 96-pin (A+B+C) DIN-41612 Bauform ‘C’ plug & Farnell 1656159 (£1.84) & Right angle through hole \\
\schpt{IC1} & LM556N Dual timer & Farnell 9488260 (£1.18), RS 536-0947 (£0.77@10) & May replace with 2×555 + 1×decoupling cap \\
\schpt{IC2} & Dual 4-to 1 line data SELECTOR/MULTIPLEXER, 3-state & Farnell 1740166 (£0.40) &  \\
\schpt{IC3} & 74HC253 Dual 4:1 multiplexer, 3-state & Farnell 1753491 (£0.28), RS 709-3046 (£0.147@10) &  \\
\schpt{IC4} & Presettable Synchronous Binary Up/Down Counter & Farnell 1470793 (£0.34), RS 527-372 (£0.29@25) &  \\
\schpt{IC5} & Dual 2-line to 4-line DECODER/DEMULTIPLEXER & Farnell 380556 (£0.35) &  \\
\schpt{IC6} & 74HC14N Hex inverting Schmitt trigger & Farnell 7455513 (£0.133@10), RS 714-0899 (£0.164@20) &  \\
\schpt{IC7} & 74HC05 6× open drain inverter & Farnell 1470855 (£0.54), RS 442-921 (£0.52) &  \\
\schpt{IC8} & 74HC590 8-bit registered binary counter & Farnell 1652001 (£0.52), RS 709-2523 (£0.236@5) &  \\
\schpt{IC9}–\schpt{IC10} & 74HC541N Octal 3-state buffer & RS 714-0953 (£0.18@20), Farnell 1470755 (£0.25@10) &  \\
\schpt{IC11} & 74HC00 4× NAND gate & RS 169-6012 (£0.26), Farnell 9590889 (£0.38) &  \\
\schpt{IC12} & 41xx DEVICE & Farnell 380600 (£0.48), 380600 (£0.36@10), RS 709-2113 (£0.143@10) &  \\
\schpt{IC13}–\schpt{IC15} & 29x040 4 MBit (512k x 8) Flash RAM & Farnell 8749493 (£2.84@1), Farnell 8749493 (£2.33@10), Farnell 1565992 (£1.18@10) & Socket: Farnell 1103872 (£0.48@10) \\
\schpt{IC16}–\schpt{IC21} & 74HC541N Octal 3-state buffer & RS 714-0953 (£0.18@20), Farnell 1470755 (£0.25@10) &  \\
\schpt{IC22}–\schpt{IC23} & 74HC540N Octal 3-state inverting buffer & Farnell US 1163595 (£0.482), Farnell 1753515 (£0.60), Farnell 1753515 (£0.46@10), RS 714-7932 (£0.195@20), RS 443-249 (£0.61) &  \\
\schpt{IC24} & 74HC04N Hex inverter & Farnell US 2374080 (£0.086), Farnell 9590951 (£0.38), Farnell 9590951 (£0.23@10), RS 714-0877 (£0.149@20), RS 662-9997 (£0.233@10) &  \\
\schpt{IC25}–\schpt{IC26} & 74HC138N 3-to-8 line Decoder & Farnell US 1318508 (£0.172@10), RS 663-0036 (£0.267@10), Farnell 1826779 (£0.29) &  \\
\schpt{IC27}–\schpt{IC28} & 74HC541N Octal 3-state buffer & RS 714-0953 (£0.18@20), Farnell 1470755 (£0.25@10) &  \\
\schpt{IC29} & 74HC32 4× OR gate & RS 709-3021 (£0.201@10), Farnell 1739939 (£0.27@10) &  \\
\schpt{IC30} & 74HC08 4× AND gate & RS 709-2845 (£0.201@10), Farnell 9665803 (£0.22@10) &  \\
\schpt{IC31} & Quad 2-input EXCLUSIVE-OR (XOR) gate & Farnell US 1075957 (£0.169), RS 169-7380 (£0.26) &  \\
\schpt{IC32} & 74HC32 4× OR gate & RS 709-3021 (£0.201@10), Farnell 1739939 (£0.27@10) &  \\
\schpt{IC33} & 74HC00 4× NAND gate & RS 169-6012 (£0.26), Farnell 9590889 (£0.38) &  \\
\schpt{IC34}–\schpt{IC35} & 1 of 8 data SELECTOR/MULTIPLEXER, 3-state & Farnell 9591320 (£0.22), Farnell 9591320 (£0.151@10), RS 663-0203 (£0.423@10) &  \\
\schpt{IC36} & Dual D type positive edge triggered FLIP FLOP, preset and clear & Farnell 1013916 (£0.103), RS 714-0975 (£0.15@20) &  \\
\schpt{IC37} & 74HC374 Octal D-type transparent latch, positive edge triggered & RS 714-0931 (£0.191@20), RS 169-6141 (£0.38), Farnell 380763 (£0.57), Farnell 380763 (£0.38@10) &  \\
\schpt{IC38}–\schpt{IC39} & 74HC541N Octal 3-state buffer & RS 714-0953 (£0.18@20), Farnell 1470755 (£0.25@10) &  \\
\schpt{IC40}–\schpt{IC41} & Octal D type FLIP FLOP, clear & Farnell 9591397 (£0.34), RS 714-0925 (£0.175@20) &  \\
\schpt{IC42}–\schpt{IC43} & 74HC541N Octal 3-state buffer & RS 714-0953 (£0.18@20), Farnell 1470755 (£0.25@10) &  \\
\schpt{IC44} & 74HC08 4× AND gate & RS 709-2845 (£0.201@10), Farnell 9665803 (£0.22@10) &  \\
\schpt{IC45} & 74HC32 4× OR gate & RS 709-3021 (£0.201@10), Farnell 1739939 (£0.27@10) &  \\
\schpt{IC46} & Dual J-K negative edge triggered FLIP FLOP, preset and clear & RS 663-1893 (£0.219@10), Farnell 1749804 (£0.39) &  \\
\schpt{IC47} & Dual D type positive edge triggered FLIP FLOP, preset and clear & Farnell 1013916 (£0.103), RS 714-0975 (£0.15@20) &  \\
\schpt{IC48} & 74HC08 4× AND gate & RS 709-2845 (£0.201@10), Farnell 9665803 (£0.22@10) &  \\
\schpt{IC49}–\schpt{IC50} & 74HC245 Octal bus transceiver, 3-state & RS 714-0916 (£0.18@20), RS 169-6113 (£0.38), Farnell 380714 (£0.49) &  \\
\schpt{IC51} & 74HC32 4× OR gate & RS 709-3021 (£0.201@10), Farnell 1739939 (£0.27@10) &  \\
\schpt{IC52} & 74HC04N Hex inverter & Farnell US 2374080 (£0.086), Farnell 9590951 (£0.38), Farnell 9590951 (£0.23@10), RS 714-0877 (£0.149@20), RS 662-9997 (£0.233@10) &  \\
\schpt{IC53}–\schpt{IC54} & 74HC541N Octal 3-state buffer & RS 714-0953 (£0.18@20), Farnell 1470755 (£0.25@10) &  \\
\schpt{IC55} & 74HC08 4× AND gate & RS 709-2845 (£0.201@10), Farnell 9665803 (£0.22@10) &  \\
\schpt{IC56}–\schpt{IC57} & Octal D type FLIP FLOP, clear & Farnell 9591397 (£0.34), RS 714-0925 (£0.175@20) &  \\
\schpt{IC58}–\schpt{IC59} & 74HC541N Octal 3-state buffer & RS 714-0953 (£0.18@20), Farnell 1470755 (£0.25@10) &  \\
\schpt{IC60} & 74HC688 8-bit magnitude/identity comparator & RS 709-2179 (£0.168@5), Farnell 9591672 (£0.67@10) &  \\
\schpt{IC61}–\schpt{IC62} & 74HC541N Octal 3-state buffer & RS 714-0953 (£0.18@20), Farnell 1470755 (£0.25@10) &  \\
\schpt{IC63} & Dual D type positive edge triggered FLIP FLOP, preset and clear & Farnell 1013916 (£0.103), RS 714-0975 (£0.15@20) &  \\
\schpt{IC64} & 74HC688 8-bit magnitude/identity comparator & RS 709-2179 (£0.168@5), Farnell 9591672 (£0.67@10) &  \\
\schpt{IC65} & 74HC138N 3-to-8 line Decoder & Farnell US 1318508 (£0.172@10), RS 663-0036 (£0.267@10), Farnell 1826779 (£0.29) &  \\
\schpt{IC66} & 74HC04N Hex inverter & Farnell US 2374080 (£0.086), Farnell 9590951 (£0.38), Farnell 9590951 (£0.23@10), RS 714-0877 (£0.149@20), RS 662-9997 (£0.233@10) &  \\
\schpt{IC67}–\schpt{IC70} & Presettable Synchronous Binary Up/Down Counter & Farnell 1470793 (£0.34), RS 527-372 (£0.29@25) &  \\
\schpt{IC71}–\schpt{IC74} & 74HC541N Octal 3-state buffer & RS 714-0953 (£0.18@20), Farnell 1470755 (£0.25@10) &  \\
\schpt{IC75}–\schpt{IC78} & Presettable Synchronous Binary Up/Down Counter & Farnell 1470793 (£0.34), RS 527-372 (£0.29@25) &  \\
\schpt{IC79}–\schpt{IC82} & 74HC541N Octal 3-state buffer & RS 714-0953 (£0.18@20), Farnell 1470755 (£0.25@10) &  \\
\schpt{IC83}–\schpt{IC86} & Presettable Synchronous Binary Up/Down Counter & Farnell 1470793 (£0.34), RS 527-372 (£0.29@25) &  \\
\schpt{IC87}–\schpt{IC88} & 74HC541N Octal 3-state buffer & RS 714-0953 (£0.18@20), Farnell 1470755 (£0.25@10) &  \\
\schpt{IC89}–\schpt{IC90} & 74HC688 8-bit magnitude/identity comparator & RS 709-2179 (£0.168@5), Farnell 9591672 (£0.67@10) &  \\
\schpt{IC91} & 74HC04N Hex inverter & Farnell US 2374080 (£0.086), Farnell 9590951 (£0.38), Farnell 9590951 (£0.23@10), RS 714-0877 (£0.149@20), RS 662-9997 (£0.233@10) &  \\
\schpt{IC92}–\schpt{IC93} & 74HC541N Octal 3-state buffer & RS 714-0953 (£0.18@20), Farnell 1470755 (£0.25@10) &  \\
\schpt{IC94} & 74HC08 4× AND gate & RS 709-2845 (£0.201@10), Farnell 9665803 (£0.22@10) &  \\
\schpt{IC95} & 74HC00 4× NAND gate & RS 169-6012 (£0.26), Farnell 9590889 (£0.38) &  \\
\schpt{IC96} & 74HC32 4× OR gate & RS 709-3021 (£0.201@10), Farnell 1739939 (£0.27@10) &  \\
\schpt{IC97} & Dual J-K negative edge triggered FLIP FLOP, preset and clear & RS 663-1893 (£0.219@10), Farnell 1749804 (£0.39) &  \\
\schpt{IC98}–\schpt{IC99} & 74HC574 8-bit D Flip Flop bus driver & RS 714-0950 (£0.18@20), Farnell 380830 (£0.42@10) &  \\
\schpt{IC100} & 74HC32 4× OR gate & RS 709-3021 (£0.201@10), Farnell 1739939 (£0.27@10) &  \\
\schpt{IC101} & 74HC253 Dual 4:1 multiplexer, 3-state & Farnell 1753491 (£0.28), RS 709-3046 (£0.147@10) &  \\
\schpt{IC102} & 74HC138N 3-to-8 line Decoder & Farnell US 1318508 (£0.172@10), RS 663-0036 (£0.267@10), Farnell 1826779 (£0.29) &  \\
\schpt{IC103}–\schpt{IC104} & 74HC541N Octal 3-state buffer & RS 714-0953 (£0.18@20), Farnell 1470755 (£0.25@10) &  \\
\schpt{IC105}–\schpt{IC107} & 29x040 4 MBit (512k x 8) Flash RAM & Farnell 8749493 (£2.84@1), Farnell 8749493 (£2.33@10), Farnell 1565992 (£1.18@10) & Socket: Farnell 1103872 (£0.48@10) \\
\schpt{IC108} & 74HC253 Dual 4:1 multiplexer, 3-state & Farnell 1753491 (£0.28), RS 709-3046 (£0.147@10) &  \\
\schpt{IC109} & Dual D type positive edge triggered FLIP FLOP, preset and clear & Farnell 1013916 (£0.103), RS 714-0975 (£0.15@20) &  \\
\schpt{IC110}–\schpt{IC112} & 29x040 4 MBit (512k x 8) Flash RAM & Farnell 8749493 (£2.84@1), Farnell 8749493 (£2.33@10), Farnell 1565992 (£1.18@10) & Socket: Farnell 1103872 (£0.48@10) \\
\schpt{IC113} & 74HC32 4× OR gate & RS 709-3021 (£0.201@10), Farnell 1739939 (£0.27@10) &  \\
\schpt{IC114}–\schpt{IC115} & 74HC138N 3-to-8 line Decoder & Farnell US 1318508 (£0.172@10), RS 663-0036 (£0.267@10), Farnell 1826779 (£0.29) &  \\
\schpt{IC116} & Dual D type positive edge triggered FLIP FLOP, preset and clear & Farnell 1013916 (£0.103), RS 714-0975 (£0.15@20) &  \\
\schpt{IC117}–\schpt{IC124} & 74HC574 8-bit D Flip Flop bus driver & RS 714-0950 (£0.18@20), Farnell 380830 (£0.42@10) &  \\
\schpt{IC125}–\schpt{IC127} & 74HC541N Octal 3-state buffer & RS 714-0953 (£0.18@20), Farnell 1470755 (£0.25@10) &  \\
\schpt{IC128} & Dual J-K negative edge triggered FLIP FLOP, preset and clear & RS 663-1893 (£0.219@10), Farnell 1749804 (£0.39) &  \\
\schpt{IC129} & 74HC138N 3-to-8 line Decoder & Farnell US 1318508 (£0.172@10), RS 663-0036 (£0.267@10), Farnell 1826779 (£0.29) &  \\
\schpt{IC130} & Dual J-K negative edge triggered FLIP FLOP, preset and clear & RS 663-1893 (£0.219@10), Farnell 1749804 (£0.39) &  \\
\schpt{IC131} & 74HC540N Octal 3-state inverting buffer & Farnell US 1163595 (£0.482), Farnell 1753515 (£0.60), Farnell 1753515 (£0.46@10), RS 714-7932 (£0.195@20), RS 443-249 (£0.61) &  \\
\schpt{IC132}–\schpt{IC134} & Dual J-K negative edge triggered FLIP FLOP, preset and clear & RS 663-1893 (£0.219@10), Farnell 1749804 (£0.39) &  \\
\schpt{IC135} & 74HC574 8-bit D Flip Flop bus driver & RS 714-0950 (£0.18@20), Farnell 380830 (£0.42@10) &  \\
\schpt{IC136} & 74HC08 4× AND gate & RS 709-2845 (£0.201@10), Farnell 9665803 (£0.22@10) &  \\
\schpt{IC137} & 74HC541N Octal 3-state buffer & RS 714-0953 (£0.18@20), Farnell 1470755 (£0.25@10) &  \\
\schpt{IC138} & 74HC08 4× AND gate & RS 709-2845 (£0.201@10), Farnell 9665803 (£0.22@10) &  \\
\schpt{IC139} & 74HC541N Octal 3-state buffer & RS 714-0953 (£0.18@20), Farnell 1470755 (£0.25@10) &  \\
\schpt{IC140} & 74HC138N 3-to-8 line Decoder & Farnell US 1318508 (£0.172@10), RS 663-0036 (£0.267@10), Farnell 1826779 (£0.29) &  \\
\schpt{IC141} & 29x040 4 MBit (512k x 8) Flash RAM & Farnell 8749493 (£2.84@1), Farnell 8749493 (£2.33@10), Farnell 1565992 (£1.18@10) & Socket: Farnell 1103872 (£0.48@10) \\
\schpt{IC142} & 4 MBit (512k x 8) Static RAM & Farnell 1562900 (£4.71) &  \\
\schpt{IC143} & 29x040 4 MBit (512k x 8) Flash RAM & Farnell 8749493 (£2.84@1), Farnell 8749493 (£2.33@10), Farnell 1565992 (£1.18@10) & Socket: Farnell 1103872 (£0.48@10) \\
\schpt{IC144} & 4 MBit (512k x 8) Static RAM & Farnell 1562900 (£4.71) &  \\
\schpt{IC145} & 74HC540N Octal 3-state inverting buffer & Farnell US 1163595 (£0.482), Farnell 1753515 (£0.60), Farnell 1753515 (£0.46@10), RS 714-7932 (£0.195@20), RS 443-249 (£0.61) &  \\
\schpt{IC146} & 74HC138N 3-to-8 line Decoder & Farnell US 1318508 (£0.172@10), RS 663-0036 (£0.267@10), Farnell 1826779 (£0.29) &  \\
\schpt{IC147} & 74HC05 6× open drain inverter & Farnell 1470855 (£0.54), RS 442-921 (£0.52) &  \\
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

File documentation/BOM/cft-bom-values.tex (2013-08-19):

250$\times$ & 0.1μF ceramic capacitor & \schpt{C1}–\schpt{C3}, \schpt{C5}, \schpt{C8}, \schpt{C11}–\schpt{C16}, \schpt{C18}–\schpt{C23}, \schpt{C28}–\schpt{C31}, \schpt{C33}–\schpt{C40}, \schpt{C42}–\schpt{C44}, \schpt{C46}–\schpt{C49}, \schpt{C51}–\schpt{C55}, \schpt{C57}–\schpt{C61}, \schpt{C63}–\schpt{C71}, \schpt{C73}–\schpt{C80}, \schpt{C82}–\schpt{C89}, \schpt{C91}–\schpt{C100}, \schpt{C102}–\schpt{C105}, \schpt{C107}–\schpt{C110}, \schpt{C112}–\schpt{C116}, \schpt{C121}–\schpt{C123}, \schpt{C128}–\schpt{C142}, \schpt{C144}–\schpt{C155}, \schpt{C157}–\schpt{C162}, \schpt{C168}–\schpt{C169}, \schpt{C171}, \schpt{C189}–\schpt{C193}, \schpt{C196}–\schpt{C210}, \schpt{C214}–\schpt{C221}, \schpt{C223}–\schpt{C229}, \schpt{C232}–\schpt{C236}, \schpt{C238}–\schpt{C240}, \schpt{C242}–\schpt{C243}, \schpt{C245}–\schpt{C248}, \schpt{C250}–\schpt{C253}, \schpt{C255}–\schpt{C256}, \schpt{C259}–\schpt{C260}, \schpt{C264}–\schpt{C265}, \schpt{C269}–\schpt{C272}, \schpt{C280}, \schpt{C283}–\schpt{C285}, \schpt{C294}–\schpt{C295}, \schpt{C300}–\schpt{C302}, \schpt{C304}, \schpt{C306}–\schpt{C312}, \schpt{C314}–\schpt{C317}, \schpt{C336}–\schpt{C345}, \schpt{C347}–\schpt{C351}, \schpt{C353}–\schpt{C362}, \schpt{C373}–\schpt{C377}, \schpt{C381}, \schpt{C383}, \schpt{C386} & Farnell US 1694337 (£0.019@100), RS 721-5240 (£0.051@50), Farnell 1694337 (£0.019@100) &  \\
53$\times$ & 1μF capacitor & \schpt{C7}, \schpt{C17}, \schpt{C24}–\schpt{C27}, \schpt{C32}, \schpt{C41}, \schpt{C45}, \schpt{C50}, \schpt{C56}, \schpt{C62}, \schpt{C72}, \schpt{C81}, \schpt{C90}, \schpt{C101}, \schpt{C106}, \schpt{C111}, \schpt{C117}–\schpt{C120}, \schpt{C124}–\schpt{C127}, \schpt{C143}, \schpt{C156}, \schpt{C163}–\schpt{C167}, \schpt{C170}, \schpt{C172}–\schpt{C173}, \schpt{C194}–\schpt{C195}, \schpt{C213}, \schpt{C222}, \schpt{C230}, \schpt{C244}, \schpt{C254}, \schpt{C273}, \schpt{C278}–\schpt{C279}, \schpt{C303}, \schpt{C313}, \schpt{C318}, \schpt{C346}, \schpt{C352}, \schpt{C363}, \schpt{C380} & Farnell US 1600879 (£0.041@25), Farnell 3322210 (£0.148), RS 538-1578 (£0.292), Farnell 1100398 (£0.38) &  \\
15$\times$ & 10nF Ceramic Capacitor & \schpt{C6}, \schpt{C10}, \schpt{C241}, \schpt{C319}–\schpt{C322}, \schpt{C327}–\schpt{C330}, \schpt{C364}–\schpt{C367} & Farnell US 1694335 (£0.016@10), Farnell 9411852 (£0.059@25) &  \\
4$\times$ & 22 pF ceramic capacitor & \schpt{C211}–\schpt{C212}, \schpt{C384}–\schpt{C385} & Farnell 9411674 (£0.035@25) &  \\
3$\times$ & 33pF ceramic capacitor & \schpt{C378}–\schpt{C379}, \schpt{C382} & Farnell 9411682 (£0.04@25) &  \\
2$\times$ & 47nF ceramic capacitor & \schpt{C262}, \schpt{C267} & Farnell 1100530 (£0.055@5) &  \\
16$\times$ & 1μF electrolytic capacitor & \schpt{C274}–\schpt{C277}, \schpt{C286}–\schpt{C293}, \schpt{C296}–\schpt{C299} & Farnell 1236655 (£0.034) &  \\
29$\times$ & 1 μF electrolytic capacitor & \schpt{C174}–\schpt{C185}, \schpt{C257}–\schpt{C258}, \schpt{C305}, \schpt{C323}–\schpt{C326}, \schpt{C331}–\schpt{C334}, \schpt{C368}–\schpt{C372}, \schpt{C387} & Farnell 1236655 (£0.034) & Through hole \\
9$\times$ & 10 µF electrolytic capacitor & \schpt{C4}, \schpt{C9}, \schpt{C186}–\schpt{C188}, \schpt{C231}, \schpt{C249}, \schpt{C261}, \schpt{C266} & Farnell 1902928 (£0.033), RS 440-6547 (£0.026@50) &  \\
2$\times$ & 47µF electrolytic capacitor & \schpt{C281}–\schpt{C282} & Farnell 1902909 (£0.041@10) &  \\
2$\times$ & 220µF electrolytic capacitor & \schpt{C263}, \schpt{C268} & Farnell 1902883 (£0.042@10) &  \\
1$\times$ & 100nF electrolytic capacitor & \schpt{C237} & Farnell 1902938 (£0.033@10) &  \\
1$\times$ & 10μF/10V Electrolytic capacitor & \schpt{C335} & \href{http://uk.farnell.com/jsp/search/productdetail.jsp?\_dyncharset=UTF-8&searchTerms=1902928&\_D%3AsearchTerms=+&%2Fpf%2Fsearch%2FTextSearchFormHandler.search=GO&\_D%3A%2Fpf%2Fsearch%2FTextSearchFormHandler.search=+&s=&%2Fpf%2Fsearch%2FTextSearchFormHandler.suggestions=false&\_D%3A%2Fpf%2Fsearch%2FTextSearchFormHandler.suggestions=+&%2Fpf%2Fsearch%2FTextSearchFormHandler.ref=globalsearch&\_D%3A%2Fpf%2Fsearch%2FTextSearchFormHandler.ref=+&\_D%3ArohsVal=+&%2Fpf%2Fsearch%2FTextSearchFormHandler.onlyRoHSProductsActive=true&\_D%3A%2Fpf%2Fsearch%2FTextSearchFormHandler.onlyRoHSProductsActive=+&\_DARGS=%2Fjsp%2Fcommonfragments\%2FglobalsearchE14.jsp}{Farnell 1902928} &  \\
22$\times$ & 8x1 pin 2.54mm centre header & \schpt{CON1}–\schpt{CON10}, \schpt{CON16}–\schpt{CON22}, \schpt{CON24}–\schpt{CON28} & Farnell 1756826 (£0.122@10) + Farnell 3991271 (£0.179@10) & Molex KK® series header \\
1$\times$ & 9x1 pin 2.54mm centre header & \schpt{CON23} & \href{http://uk.farnell.com/jsp/search/productdetail.jsp?\_dyncharset=UTF-8&searchTerms=1756827&\_D%3AsearchTerms=+&%2Fpf%2Fsearch%2FTextSearchFormHandler.search=GO&\_D%3A%2Fpf%2Fsearch%2FTextSearchFormHandler.search=+&s=&%2Fpf%2Fsearch%2FTextSearchFormHandler.suggestions=false&\_D%3A%2Fpf%2Fsearch%2FTextSearchFormHandler.suggestions=+&%2Fpf%2Fsearch%2FTextSearchFormHandler.ref=globalsearch&\_D%3A%2Fpf%2Fsearch%2FTextSearchFormHandler.ref=+&\_D%3ArohsVal=+&%2Fpf%2Fsearch%2FTextSearchFormHandler.onlyRoHSProductsActive=true&\_D%3A%2Fpf%2Fsearch%2FTextSearchFormHandler.onlyRoHSProductsActive=+&\_DARGS=%2Fjsp%2Fcommonfragments\%2FglobalsearchE14.jsp}{Farnell 1756827} & Molex KK® series header \\
1$\times$ & DB9 female or 2×5-pin header & \schpt{CON13} & Farnell 1099294 (£0.48@5) &  \\
2$\times$ & 2x20 pin shrouded header & \schpt{CON14}–\schpt{CON15} & RS 670-1825 (£0.972@5), Farnell 1099261 (£1.07), Farnell US 1258972 (£0.66), Farnell US 2067726 (£0.913) & IDE socket \\
2$\times$ & DB9 male or 2×5 pin header & \schpt{CON11}–\schpt{CON12} & Farnell 1099289 (£0.48@5) &  \\
3$\times$ & 1N4148 diode & \schpt{D3}–\schpt{D5} & Farnell 9565124 (£0.011), RS 436-7341 (£0.003@100) & Or any fast signal diode \\
1$\times$ & 1N5817 Schottky barrier rectifier & \schpt{D1} & Farnell 1843507 (£0.023) &  \\
1$\times$ & 1N4002 diode & \schpt{D2} & Farnell US 1924512 (£0.022@10), Farnell 1651083 (£0.056), Farnell 1651083 (£0.053@25) &  \\
2$\times$ & 96-pin (A+B+C) DIN-41612 Bauform ‘C’ plug & \schpt{EXP}, \schpt{EXP1} & Farnell 1656159 (£1.84) & Right angle through hole \\
2$\times$ & 16C2550 Dual 16550 UART & \schpt{IC148}–\schpt{IC149} & Farnell 1294794 (£4.21) &  \\
2$\times$ & 4 MBit (512k x 8) Static RAM & \schpt{IC142}, \schpt{IC144} & Farnell 1562900 (£4.71) &  \\
11$\times$ & 29x040 4 MBit (512k x 8) Flash RAM & \schpt{IC13}–\schpt{IC15}, \schpt{IC105}–\schpt{IC107}, \schpt{IC110}–\schpt{IC112}, \schpt{IC141}, \schpt{IC143} & Farnell 8749493 (£2.84@1), Farnell 8749493 (£2.33@10), Farnell 1565992 (£1.18@10) & Socket: Farnell 1103872 (£0.48@10) \\
1$\times$ & 74HC161 & \schpt{IC12} & Farnell 380600 (£0.48), 380600 (£0.36@10), RS 709-2113 (£0.143@10) &  \\
9$\times$ & 74HC00 4× NAND gate & \schpt{IC11}, \schpt{IC33}, \schpt{IC95}, \schpt{IC182}, \schpt{IC191}, \schpt{IC237}–\schpt{IC238}, \schpt{IC240}, \schpt{IC242} & RS 169-6012 (£0.26), Farnell 9590889 (£0.38) &  \\
2$\times$ & 74HC02N & \schpt{IC164}–\schpt{IC165} & Farnell US 1163587 (£0.322), Farnell 9665781 (£0.33) &  \\
2$\times$ & 74HC03N Quad 2-input NAND gate, open collector output & \schpt{IC203}, \schpt{IC213} & Farnell 1282849 (£0.17) &  \\
9$\times$ & 74HC04N Hex inverter & \schpt{IC24}, \schpt{IC52}, \schpt{IC66}, \schpt{IC91}, \schpt{IC194}, \schpt{IC204}, \schpt{IC209}–\schpt{IC210}, \schpt{IC212} & Farnell US 2374080 (£0.086), Farnell 9590951 (£0.38), Farnell 9590951 (£0.23@10), RS 714-0877 (£0.149@20), RS 662-9997 (£0.233@10) &  \\
5$\times$ & 74HC05 6× open drain inverter & \schpt{IC7}, \schpt{IC147}, \schpt{IC158}, \schpt{IC179}, \schpt{IC255} & Farnell 1470855 (£0.54), RS 442-921 (£0.52) &  \\
7$\times$ & 74HC08 4× AND gate & \schpt{IC30}, \schpt{IC44}, \schpt{IC48}, \schpt{IC55}, \schpt{IC94}, \schpt{IC136}, \schpt{IC138} & RS 709-2845 (£0.201@10), Farnell 9665803 (£0.22@10) &  \\
8$\times$ & 74HC112N & \schpt{IC46}, \schpt{IC97}, \schpt{IC128}, \schpt{IC130}, \schpt{IC132}–\schpt{IC134}, \schpt{IC239} & RS 663-1893 (£0.219@10), Farnell 1749804 (£0.39) &  \\
2$\times$ & 74HC125N & \schpt{IC247}–\schpt{IC248} & Farnell 9591036 (£0.48), RS 709-2009 (£0.21@10), RS 169-7403 (£0.32) &  \\
22$\times$ & 74HC138N 3-to-8 line Decoder & \schpt{IC25}–\schpt{IC26}, \schpt{IC65}, \schpt{IC102}, \schpt{IC114}–\schpt{IC115}, \schpt{IC129}, \schpt{IC140}, \schpt{IC146}, \schpt{IC153}, \schpt{IC157}, \schpt{IC160}, \schpt{IC171}, \schpt{IC175}, \schpt{IC184}–\schpt{IC186}, \schpt{IC215}, \schpt{IC227}, \schpt{IC230}–\schpt{IC231}, \schpt{IC252} & Farnell US 1318508 (£0.172@10), RS 663-0036 (£0.267@10), Farnell 1826779 (£0.29) &  \\
1$\times$ & 74HC139N & \schpt{IC5} & Farnell 380556 (£0.35) &  \\
5$\times$ & 74HC14N Hex inverting Schmitt trigger & \schpt{IC6}, \schpt{IC156}, \schpt{IC202}, \schpt{IC208}, \schpt{IC211} & Farnell 7455513 (£0.133@10), RS 714-0899 (£0.164@20) &  \\
2$\times$ & 74HC153N & \schpt{IC167}–\schpt{IC168} & RS 443-075 (£0.50), Farnell 1753485 (£0.56) &  \\
2$\times$ & 74HC164N & \schpt{IC180}–\schpt{IC181} & Farnell 1201282 (£0.46) &  \\
2$\times$ & 74HC166N & \schpt{IC192}–\schpt{IC193} & Farnell 1287502 (£0.39) &  \\
2$\times$ & 74HC174N & \schpt{IC187}, \schpt{IC196} & Farnell 1287531 (£0.32) &  \\
14$\times$ & 74HC193N & \schpt{IC4}, \schpt{IC67}–\schpt{IC70}, \schpt{IC75}–\schpt{IC78}, \schpt{IC83}–\schpt{IC86}, \schpt{IC190} & Farnell 1470793 (£0.34), RS 527-372 (£0.29@25) &  \\
2$\times$ & 74HC21N & \schpt{IC234}, \schpt{IC241} & Farnell 1740011 (£0.23), RS 709-2665 (£0.163@20) &  \\
5$\times$ & 74HC245 Octal bus transceiver, 3-state & \schpt{IC49}–\schpt{IC50}, \schpt{IC154}–\schpt{IC155}, \schpt{IC172} & RS 714-0916 (£0.18@20), RS 169-6113 (£0.38), Farnell 380714 (£0.49) &  \\
2$\times$ & 74HC251N & \schpt{IC34}–\schpt{IC35} & Farnell 9591320 (£0.22), Farnell 9591320 (£0.151@10), RS 663-0203 (£0.423@10) &  \\
3$\times$ & 74HC253 Dual 4:1 multiplexer, 3-state & \schpt{IC3}, \schpt{IC101}, \schpt{IC108} & Farnell 1753491 (£0.28), RS 709-3046 (£0.147@10) &  \\
4$\times$ & 74HC273N & \schpt{IC40}–\schpt{IC41}, \schpt{IC56}–\schpt{IC57} & Farnell 9591397 (£0.34), RS 714-0925 (£0.175@20) &  \\
8$\times$ & 74HC32 4× OR gate & \schpt{IC29}, \schpt{IC32}, \schpt{IC45}, \schpt{IC51}, \schpt{IC96}, \schpt{IC100}, \schpt{IC113}, \schpt{IC163} & RS 709-3021 (£0.201@10), Farnell 1739939 (£0.27@10) &  \\
1$\times$ & 74HC373 Octal D-type transparent latch, negative edge triggered & \schpt{IC205} & RS 714-0922 (£0.182@20), Farnell 1607705 (£0.52@10) &  \\
5$\times$ & 74HC374 Octal D-type transparent latch, positive edge triggered & \schpt{IC37}, \schpt{IC159}, \schpt{IC161}–\schpt{IC162}, \schpt{IC178} & RS 714-0931 (£0.191@20), RS 169-6141 (£0.38), Farnell 380763 (£0.57), Farnell 380763 (£0.38@10) &  \\
5$\times$ & 74HC540N Octal 3-state inverting buffer & \schpt{IC22}–\schpt{IC23}, \schpt{IC131}, \schpt{IC145}, \schpt{IC176} & Farnell US 1163595 (£0.482), Farnell 1753515 (£0.60), Farnell 1753515 (£0.46@10), RS 714-7932 (£0.195@20), RS 443-249 (£0.61) &  \\
52$\times$ & 74HC541N Octal 3-state buffer & \schpt{IC9}–\schpt{IC10}, \schpt{IC16}–\schpt{IC21}, \schpt{IC27}–\schpt{IC28}, \schpt{IC38}–\schpt{IC39}, \schpt{IC42}–\schpt{IC43}, \schpt{IC53}–\schpt{IC54}, \schpt{IC58}–\schpt{IC59}, \schpt{IC61}–\schpt{IC62}, \schpt{IC71}–\schpt{IC74}, \schpt{IC79}–\schpt{IC82}, \schpt{IC87}–\schpt{IC88}, \schpt{IC92}–\schpt{IC93}, \schpt{IC103}–\schpt{IC104}, \schpt{IC125}–\schpt{IC127}, \schpt{IC137}, \schpt{IC139}, \schpt{IC177}, \schpt{IC189}, \schpt{IC216}–\schpt{IC221}, \schpt{IC228}–\schpt{IC229}, \schpt{IC235}–\schpt{IC236}, \schpt{IC249} & RS 714-0953 (£0.18@20), Farnell 1470755 (£0.25@10) &  \\
15$\times$ & 74HC574 8-bit D Flip Flop bus driver & \schpt{IC98}–\schpt{IC99}, \schpt{IC117}–\schpt{IC124}, \schpt{IC135}, \schpt{IC188}, \schpt{IC197}, \schpt{IC232}–\schpt{IC233} & RS 714-0950 (£0.18@20), Farnell 380830 (£0.42@10) &  \\
1$\times$ & 74HC590 8-bit registered binary counter & \schpt{IC8} & Farnell 1652001 (£0.52), RS 709-2523 (£0.236@5) &  \\
5$\times$ & 74HC688 8-bit magnitude/identity comparator & \schpt{IC60}, \schpt{IC64}, \schpt{IC89}–\schpt{IC90}, \schpt{IC174} & RS 709-2179 (£0.168@5), Farnell 9591672 (£0.67@10) &  \\
7$\times$ & 74HC74N & \schpt{IC36}, \schpt{IC47}, \schpt{IC63}, \schpt{IC109}, \schpt{IC116}, \schpt{IC199}, \schpt{IC253} & Farnell 1013916 (£0.103), RS 714-0975 (£0.15@20) &  \\
1$\times$ & 74HC85N 4-bit Magnitude Comparator & \schpt{IC222} & Farnell US 1387859 (£0.543), Farnell 380489 (£0.61), RS 527-801 (£0.544@25) &  \\
1$\times$ & 74HC86N & \schpt{IC31} & Farnell US 1075957 (£0.169), RS 169-7380 (£0.26) &  \\
3$\times$ & 74HCT00N Quad 2-input NAND gate & \schpt{IC207}, \schpt{IC245}–\schpt{IC246} & RS 217-5702 (£0.14), Farnell US 2373749 (£0.125), Farnell 9591745 (£0.24) &  \\
1$\times$ & 74HCT253N & \schpt{IC2} & Farnell 1740166 (£0.40) &  \\
2$\times$ & 82C54 & \schpt{IC169}–\schpt{IC170} & Farnell 1018175 (£6.69), RS 496-688 (£6.71) &  \\
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

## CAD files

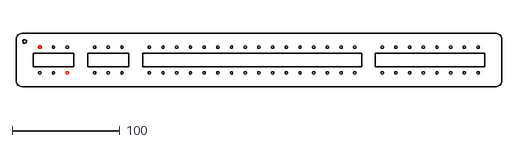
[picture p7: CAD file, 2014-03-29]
documentation/panel/panel-assembly-to-export-switches.dxf
450.0 x 50.0

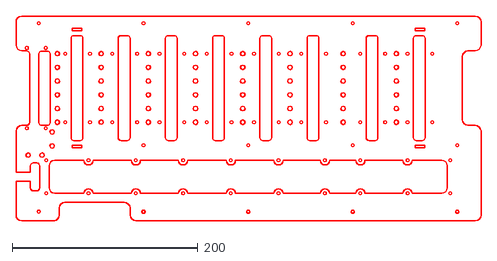
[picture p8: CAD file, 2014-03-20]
documentation/panel/panel-assembly-to-export.dxf
500.0 x 220.0

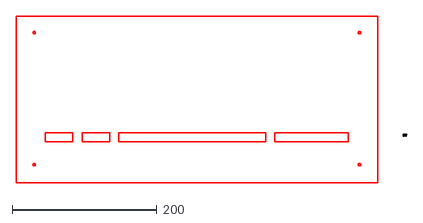
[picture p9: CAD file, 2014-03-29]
documentation/panel/front-panel-v6-export.dxf
539.7 x 230.0

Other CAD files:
documentation/case/PSU-ATX.skp

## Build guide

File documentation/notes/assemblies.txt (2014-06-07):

CFT ASSEMBLIES AND PARTS

* Power supply
  * PSU Fixing kit
* Backplane
  * 8× (?) M5 (?) spacers, nylon
  * 8× (?) M5 (?) screws, nylon
  * Power supply harness
    * 3× GND wires
    * +5V wire
    * +12V wire
    * +3.3V wire
    * 6× wire terminals, thick
  * DFP board 1
    * Serial connector
      * 3 way cable
      * Ferrite ring
      * 2× 5-pin 2.54mm connector
      * TTL-to-USB module
    * PSU connector: DONE
      * 2-5 way cable
      * 5-pin 2.54mm connector
      * 2× wire terminals, thin
  * DFP board 2
    * Cable to DFP board 1
      * 40-way ribbon cable
      * 2× 40-pin connectors
  * PB0 (Processor Board 0)
    * Cable to DFP board 1
      * 40-way ribbon cable
      * 2× 40-pin IDC connectors
  * PB1 (Processor Board 0)
    * Cable to DFP board 1
      * 40-way ribbon cable
      * 2× 40-pin IDC connectors
  * PB2 (Processor Board 0)
    * Cable #1 to DFP board 1
      * 40-way ribbon cable
      * 2× 40-pin IDC connectors
    * Cable #2 to DFP board 1
      * 40-way ribbon cable
      * 2× 40-pin IDC connectors
  * PB3 (Processor Board 0)
    * Cable to DFP board 1
      * 20-way ribbon cable
      * 2× 20-pin IDC connectors
* Control Bus part 1
    * 40-pin ribbon cable
    * 5× 40-pin connectors (DFP board 2, PB0–PB3)
* Control Bus part 2
    * 40-pin ribbon cable
    * 5× 40-pin connectors (DFP board 2, PB0–PB3)
* Front Panel
  * Base plastic
  * 8× LED modules
    * 4× spacers
    * 4× screws
  * Switch assembly
    * spacers
    * screws
    * 30× switches
      * 2× screws
      * 2× spacers (?)
    * 2× key switches
      * 1× key
      * 1× washer
    * Breakout board
    * Switch assembly cable
      * 50-pin ribbon cable
      * 2× 50-pin connectors
  * Light assembly cabling
    * 4× cables
      * 50-pin ribbon cable
      * 50-pin connector
      * 10× (max) 5-pin 2.54mm plugs
  * Fascia (laser-engraved acryllic)
    * 4–6× spacers (base to fascia)
    * 4–6× Thumb screws fitting spacers
* Base panel
  * 8× (?) M5 (?) screws for backplane
* Rear panel
  * Connector plates (modular?)
    * 2× USB (serial, panel)
    * 2× DCE RS232 (DB9)
    * DTE RS232 (DB9)
    * Parallel printer port (25-pin)
    * PS/2 keyboard
    * PS/2 mouse
    * Sun keyboard/mouse
    * Video out (DE15)
    * Audio out
    * Cassette Tape I/O
    * 50-pin floppy connector
    * 34-pin floppy connector
    * 2× joystick connector (DB9)
    * User I/O connector (to be decided)
    * Ethernet port
  * 3× fan grilles
    * 4× screws (self tapping?)
    * 4× nuts (?)
* 2× Side panels
  * 2× screws, black
* Top panel
  * TODO: 2× speaker assembly
    * Speaker
    * Fixings (?)
    * Speaker harness
  * Acryllic Window
  * 4× thumbscrews
* Card bar (notched, secures tops of cards)
* 3× 12cm fans (12V)
  * Wiring harness
* 2× 3.5" Disk bays (remove from old PC case)
* 4× case feet
* Internal frame (wood? To be decided)

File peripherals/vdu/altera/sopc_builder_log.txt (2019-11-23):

Info: Saving your IP search path in /home/alexios/.altera.quartus/ip/12.1/ip_search_path/user_components.ipx
Info: Using factories: CuspFactory, ImportFactory, DSPBuilderFactory, JarFactory, QvarFactory, TclModuleFactory, MegaVariationFactory, BeanElementFactory, LegacyFactory, DDRLegacyFactory, PresetFactory, EmbeddedSwTclDriverFactory, QsysFactory
Progress: (0) searching /home/alexios/PROJECTS/HARDWARE/cft/video-board/altera/12.1 (command line switch)
Info: /home/alexios/PROJECTS/HARDWARE/cft/video-board/altera/12.1 matched 1 files in 0.00 seconds
Info: Found 0 components

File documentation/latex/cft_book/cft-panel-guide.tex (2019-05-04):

\HtmlMetaDescription{How to use the CFT's Front Panel to operate, diagnose
and program the computer and its peripherals.}
%\HtmlMetaGoogleDescription{}
%\HtmlMetaBanner{}
%\HtmlMetaTags{}

%% \label{chap:pfp}
%%   \section*{History of Changes}

%%   {\bfseries 2011-12-19} Initial revision.

%%   {\bfseries 2012-01-04} Listed briefly the signal connections between front
%%   panel and processor boards.

%%   {\bfseries 2012-01-09} Added revision B schematics, bill of materials and parts index.

%%   {\bfseries 2012-01-15} Minor modifications to the schematics and matching
%%   description. Added discussion on configuring and tuning the front
%%   panel.

%%   {\bfseries 2012-01-18} Added front panel controller and started section of the
%%   front panel's theory of operation.

%%   {\bfseries 2012-01-20} Added theory of operation of sequencer and system device and
%%   updated rendered images of boards, schematics and bills of materials.

\section{Introduction}

The CFT minicomputer is intended to be similar to a 1960s
minicomputer, and it could never be similar enough without a
programmer's front panel.

The front panel is serves two purposes: to inspect the state of the
computer, and to modify the state of the computer. State inspection is
made possible via a number of lights corresponding to the binary state
of most of the computer's crucial signals. State modification is via a
number of switches which control the operation of the computer's main
units and provide user input.

The CFT front panel is expected to provide a number of services.

\begin{itemize}
\item During construction, it will provide a means of testing most of
  the computer's individual units on their own. With some rewiring or
  reconfiguration, all of the computer's features can be tested.

\item After construction, it will allow microcode to be inspected and
  thereby debugged.

\item It will also allow the computer to be programmed without a
  ROM. A front panel was usually the only built-in means of
  programming a minicomputer, and in many cases was the only way the
  computer could be booted up.

\item It will allow debugging of software and hardware by allowing the
  computer to be stopped, its state inspected and perhaps changed, and
  then resuming execution.

\item Finally, it will allow the state of the running computer to be
  inspected with varying degrees of success.\footnote{The human eye
    is, of course, incapable of registering light pulses with MHz
    frequencies, but the panel lights register these with varying
    intensities of light.}

\end{itemize}

\section{Layout of the Front Panel}

\begin{figure}[t]
\centering
\includelarge[width=0.8\textwidth]{../../panel/front-panel-v2-small.jpg}\\
\caption{\label{fig-panel}A first draft of the CFT front panel.}
\end{figure}

The CFT minicomputer is intended to be built into a 19-inch rack-mount case, 6U
in height, making it approximately 19" by 10.5" (482.6mm by 266.7mm) in size.

The panel displays the state of the computer on 118 console lights. For lower
consumption, convenience and longevity, these are light-emitting diodes (LEDs).

30 toggle switches allow the computer's state to be modified, and user input to
be provided.

Computer power and panel locking is controlled by a three-position key switch.

All lights and switches are displaying multi-bit quantities are arranged with
the most significant bit to the right, in the conventional notation of binary
numbers. Bit numbers start at 0, which is the least significant bit or
rightmost light. This follows the conventional notation of powers-of-two.

\subsection{Console Lights}

The console lights are arranged in six rows.

\subsubsection{Memory Controller}

The leftmost bank of lights on the top row displays the status of the banking
memory controller, if it is installed.

If banking has been enabled, a green light marked \lt{ENABLED} indicates
this. Eight yellow lights marked \lt{AEXT7}–\lt{AEXT0} indicate the bank
currently selected.

Conventionally, the memory controller addresses up to one MWord of ROM mapped
in the top MWord of the 21-bit address space (physical addresses
\hex{20:0000}–\hex{3F:FFFF}). Thus, light \lt{AEXT7} also indicates that a ROM
bank may be selected (this depends on the particular configuration of the
memory board or boards: please refer to~\ccf{chap:mem} for detailed
information). The light is thus marked \lt{AEXT7/ROM}).

If the memory controller board is not installed, these lights remain off.

\subsubsection{Interrupt Controller}

The middle bank of lights on the top row indicates the status of the optional
interrupt controller on eight lights marked \lt{INT7}–\lt{INT0}.

Each of these lights will indicate a number of different conditions depending
on its colour.

\begin{itemize}
  \item {\bfseries Off}: the computer is ignoring this interrupt line, and there is
    no interrupt activity.
  \item {\bfseries Green}: the interrupt line is being used by the computer, but
    there is no interrupt activity.
  \item {\bfseries Orange}: the interrupt line is being used by
    the computer, with interrupt activity.
  \item {\bfseries Red}: there is interrupt activity, but it is being ignored
    by the computer.
\end{itemize}

Because interrupt pulses are too short and relatively rare, in order to make
them visible to the naked eye, each interrupt pulse will illuminate the light
red or orange for approximately one tenth of a second.

\subsubsection{Miscellaneous Lights}

Three green lights marked \lt{GEN2}–\lt{GEN0} are located at the right of the
topmost row. These are reserved for generic use. Hardware may indicate its
status on any of them via physical two-wire connections.

\subsubsection{State}

The leftmost bank of lights on the second row from the top indicates the
processor's major operating states.

\begin{itemize}
\item \lt{RUN} (green) indicates the processor clock is running.
\item \lt{STOP} (red) when the \lt{RUN} light is off and this light is
  on, the processor clock is stopped and the front panel switches are
  active (provided the front panel is unlocked). When the \lt{RUN}
  light is on and this light flashes briefly, some device is
  introducing wait states by briefly halting the processor.
\item \lt{FETCH} (yellow) indicates the processor is in the Fetch state,
  retrieving its next instruction from memory.
\item \lt{EXEC} (yellow) indicates the processor is in the Execute state,
  performing the task identified by the previously retrieved instruction.
\item \lt{INT} (yellow) indicates the processor is handling a previously
  retrieved interrupt. Because interrupt states are too short and relatively
  rare, in order to make them visible to the naked eye, each interrupt pulse
  will illuminate this light for approximately one tenth of a second.
\end{itemize}

\subsubsection{Program Counter}

Sixteen red lights on the second row from the top indicate the current value of
the \PC. When the \lt{FETCH} light is illuminated, the \PC{} contains the
address in memory of the instructing being fetched. When the \lt{EXEC} light is
illuminated, the \PC{} indicates the address of the {\em next\/} instruction to
be executed (as long as no branching takes place in the current instruction).

\subsubsection{Flags}

Five green lights indicate the state of the five minor registers (flags) of the
processor.

\begin{itemize}
\item \lt{N} indicates bit 15 of the \A{} is set.
\item \lt{Z} indicates the \A{} is zero.
\item \lt{V} indicates an arithmetic overflow has been detected by the \ALU.
\item \lt{I} indicates that the processor allows interrupts.
\item \lt{L} indicates the state of the \Lreg{} register.
\end{itemize}

\subsubsection{Accumulator}

Immediately to the right of the \lt{L} light, on the second row from the top,
are 16 red lights representing the current value of the \A{} register. The
placement is such that the $(L,A)$ pair is easy to inspect when adding or
rotating.

\subsubsection{Multi-Function Display}

The Multi-Function Display occupies the third row of lights. Using a switch,
the user may choose to display the value of the Front Panel Output Register,
the Data Register (\DR), and the current micro-Address vector. In the latter
case, the meanings of each bit are marked below each light. The most
significant bit is not used in this case.

\subsubsection{Memory}

The status of the memory and I/O sequencing is shown on a bank of four lights,
on the fourth row from the top (second row from the bottom). The meanings of
these lights are as follows:

\begin{itemize}
\item \lt{MEM} (yellow) indicates memory space is being accessed.
\item \lt{IO} (yellow) indicates Input/Output space is being accessed.
\item \lt{R} (green) indicates a read cycle is in progress.
\item \lt{W} (red) indicates a write cycle is in progress.
\end{itemize}

These lights are pairwise mutually exclusive. The four combinations of them
describe the nature of the memory or I/O access (memory read, memory write, I/O
read, I/O write). Please note that these lights are, in essence, part of the
micro-instruction as described below.

\subsubsection{Instruction Register}

The contents of the \IR{} are displayed to the right of the memory lights. The
instruction fields (operation, I, R, and operand field) are indicated below the
lights. Alternating yellow and red lights are used for each field to aid
reading the IR.

Please note that the \lt{L} light indicates {\em exactly\/} the corresponding
field in an instruction: register mode is active when the light is {\em off}.

\subsubsection{Micro-Instruction}

The bottom row of lights indicates most of the control signals emanating from
the Microcode ROM (the memory control signals, described above, are the only
exception). These are useful in debugging the machine at the microcode level.

\subsection{Switches}

There are 30 switches and a key switch arranged in two rows below the
bottom-most row of lights. The top row is the Switch Register (16
switches), while the 

\subsubsection{Key Lock}

The key lock operates computer power and controls access to the front
panel.

Computer power is off with the key in the \sw{OFF} position.

Computer power is on with the key in the \sw{ON} position. In this position,
most panel switches are locked. These are the exceptions:

\begin{itemize}
\item The key switch may be operated.
\item The 16 Switch Register switches may be used to register 16-bit values
  read by the computer via the Front Panel System Device.
\item The \sw{VERBOSE}/\sw{TERSE} switch may be operated to enable or disable
  some front panel lights.
\item The Multi-Function Display Selector may be operated to change what is
  displayed on the Multi-Function Display.
\end{itemize}

With the key switch in the \sw{PANEL} position, all panel switches are unlocked
and enabled.

\subsubsection{Switch Register}

The switch register comprises 16 toggle switches located below the bottom-most
row of lights. These may be used to provide instructions or values to be stored
in processor registers when the computer is halted, or read directly by
computer programs via the Front Panel System Device when the computer is
running. This is the only form of user input of the unexpanded computer.

The switches are aligned with the corresponding bits of the various red
register lights and numbered in the same power-of-two convention as register
display lights. Switches are grouped in four four-bit groups for easier
reading.

Push a switch up to set the corresponding bit. Push it down to clear it.

\subsubsection{Run Control}

The Run Control switch group is located on the bottom row of switches,
below the Switch Register switches. It comprises three momentary
action switches with six functions. Switches may be pushed up or down
momentarily to activate their corresponding functions. These are:

\begin{description}
\item{\bfseries\sw{RESET}} Push the leftmost switch up to reset the
computer.
\item{\bfseries\sw{START}} Push the leftmost switch down to reset the
computer and start the processor clock.
\item{\bfseries\sw{RUN}} Push the middle switch up to enable the computer
  clock and allow the computer to continue executing.
\item{\bfseries\sw{STOP}} Push the middle switch down to disable the
  computer clock. This halts the computer and activates the controls
  of the front panel. Please note that the clock is halted
  immediately, possibly in the middle of executing a
  microprogram. Examine the \lt{FETCH}, \lt{EXEC} and
  \lt{μADDR3}–\lt{μADDR0} lights to determine exactly where the
  machine stopped.
\item{\bfseries\sw{uSTEP}} Push the rightmost switch up to trigger a single
  clock pulse, advancing to the next microinstruction.
\item{\bfseries\sw{STEP}} Push the rightmost switch down to advance to the
  first execution clock of the next instruction. The computer's clock
  is briefly enabled until the end of the first fetch cycle
  encountered after the activation of the switch, and immediately
  halted. At that point, the Instruction Register will display the
  instruction about to be executed and the Program Counter will
  display the address of the {\em next\/} instruction to be executed
  (barring jumps or skips). An optional auto-repeat mechanism allows
  the computer to step over multiple instructions while the \sw{STEP}
  switch is depressed. To activate the auto-repeat, press and hold the
  switch. A single step will be performed. Approximately two seconds
  after, and approximately every second after that, further step
  operations will be performed.
\end{description}

\subsubsection{State modification}

The state modification group resides centred below the switch
register. It comprises seven momentary action action switches and one
on-on toggle switch performing 15 actions:

\begin{description}
\item{\bfseries\sw{LOAD ADDR}} Operate the leftmost switch up or down to load the
  contents of the Switch Register into the Program Counter.
\item{\bfseries\sw{LOAD IR}} Push the second switch up to load the contents
  of the Switch Register into the Instruction Register.
\item{\bfseries\sw{LOAD AC}} Push the second switch up to load the contents
  of the Switch Register into the \gls{Accumulator}.
\item{\bfseries\sw{MEMORY DEPOSIT}} Push the third switch up to store the
  contents of the Switch Register onto the memory address displayed in
  the address (Program Counter) bank of lights.
\item{\bfseries\sw{MEMORY DEP NEXT}} Push the third switch down to store the
  contents of the Switch Register onto the memory address displayed in
  the address (Program Counter) bank of lights. The Program Counter
  address is incremented by one after this. Repeated activations of
  this switch can fill a region of memory with the value of the Switch
  Register.
\item{\bfseries\sw{MEMORY EXAMINE}} Push the fourth switch up to load a
  value from memory into the \gls{Accumulator}. The memory address used is
  that of the Program Counter (address) lights.
\item{\bfseries\sw{MEMORY EXAM NEXT}} Push the fourth switch down to load a
  value from memory, and increment the Program Counter by
  one. Repeated activations of this switch allow regions of memory to
  be examined one word at a time.
\item{\bfseries\sw{INPUT/OUTPUT DEPOSIT}} Push the fifth switch up to
  perform the same function as the \sw{MEMORY DEPOSIT} switch, but for
  I/O space.
\item{\bfseries\sw{INPUT/OUTPUT DEP NEXT}} Push the fifth switch down to
  perform the same function as the \sw{MEMORY DEP NEXT} switch, but
  for I/O space.
\item{\bfseries\sw{INPUT/OUTPUT EXAMINE}} Push the sixth switch up to
  perform the same function as the \sw{MEMORY EXAMINE} switch, but for
  I/O space.
\item{\bfseries\sw{INPUT/OUTPUT EXAM NEXT}} Push the sixth switch down to
  perform the same function as the \sw{MEMORY EXAM NEXT} switch, but
  for I/O space.

\item{\bfseries\sw{RAM BNK}} The seventh switch is an on-on toggle switch,
  not a momentary action switch. When in the upper (\sw {RAM BNK})
  position, it maps 32 kWords of RAM to the top of the CFT address
  space. This is useful when the computer must be booted from the
  control panel. This setting is only valid while the \lt{ENABLED}
  light of the Memory Controller group is extinguished. Once the
  computer activates banking, the mapping is under its control and the
  position of this switch is ignored.
\item{\bfseries\sw{ROM BNK}} Likewise, when the switch is in the \sw{ROM
  BNK} position, 32 kWords of ROM are mapped to the top of the CFT
  address space. This position is required to execute the ROM
  bootstrap code directly after starting the machine.

\item{\bfseries\sw{IFR1}} Push the eighth switch up to send an interrupt 1
  (relatively high priority) pulse to the interrupt controller. This
  is used to provide asynchronous input to the computer, as long as
  the monitor software is aware of it.
\item{\bfseries\sw{IFR6}} Likewise, push the eighth switch down to send an
  interrupt 6 (relatively low priority) pulse to the interrupt
  controller.

\end{description}

All of the above functions, including the {\sw{RAM BNK}/\sw{ROM BNK}}
switch but {\em excluding\/} the \sw{IFR1}/\sw{IFR6} switch, are
locked out unless the key switch is in the \sw{PANEL} position, and
the clock is halted (\lt{RUN} light off; \lt{STOP} light on).

\subsubsection{Convenience and Panel Control Switches}

The rightmost group provides convenience functions:

\begin{description}
\item{\bfseries\sw{FAST}/\sw{SLOW}/\sw{TEST}} This three position toggle
  switch controls the speed of the system clock. In the \sw{FAST}
  position, the clock runs at its nominal speed. In the \sw{SLOW}
  position, the processor executes at a significantly increased clock
  period, in the order of one microsecond\footnote{The exact clock
    speed depends on the system clock and an internally configured
    clock divider.}). This executes approximately 1,000 clock ticks a
  second, or (very approximately) 100 instructions per second, making
  instructions visible on the panel lights. In the \sw{TEST} position,
  the clock period is increased even further, so that
  microinstructions become visible and approximately 10 instructions
  per second are executed. This is intended to allow testing
  microcode. In order to avoid potential glitches that would
  destabilise the system, the setting of this switch is ignored if the
  system is running or if front panel is locked via the key switch.

\item{\bfseries\sw{VERBOSE}/\sw{TERSE}} In the upper position, this switch
  enables all front panel lights for full diagnostics. In the interest
  of reducing light pollution and visual overloading, the lower
  position (\sw{TERSE}) disables a number of lights:
\begin{itemize}
\item The Memory Controller group,
\item The Interrupt Controller Controller group,
\item The Instruction Register,
\item The Flag Display,
\item The Memory Display, and
\item The μ-Instruction Display.
\end{itemize}

Some of these displays may be excluded from terse mode using jumpers
on the LED board. A mock-up of the panel in \sw{TERSE} mode is
available as~\fcf{fig-panel-terse}. Please note that the terms
‘verbose’ and ‘terse’ are under review.

\item{\bfseries Multi-Function Display Selector Switch} The rightmost switch
  on the bottom row of the front panel selects what is displayed on
  the Multi-Function Display bank. There are three options:
  \begin{description}
  \item{\bfseries\sw{OUTPUT REG}} Displays the contents of the Output Register
    on the Multi-Function Display. This register is provided by the
    Front Panel System Device and may be written to
    programmatically. It is the main form of user output available to
    an unexpanded CFT computer. On an expanded computer, the monitor
    program may use this register to display its high-level state,
    error codes, et cetera.
  \item{\bfseries\sw{DR}} Displays the Data Register on the Multi-Function
    Display.
  \item{\bfseries\sw{uADDR VEC}} Displays the 15-bit microcode address
    vector on the Multi-Function Display. The vector is made up of a
    number of components (conditions), each of which is marked under
    the corresponding light of the Multi-Function Display. This
    setting is intended to allow microcode testing.
  \end{description}
\end{description}

\begin{figure}
\centering
\includelarge[width=0.8\columnwidth]{figs/front-panel-v2-terse-small.jpg}\\
\caption{\label{fig-panel-terse}A mock-up of the front panel running in \sw{TERSE} mode.}
\end{figure}

\subsection{Power}

A key switch at the lower right controls power. At the leftmost position, the
computer is off. When the key is turned one position to the right, the computer
is activated with most panel switches locked. With the key int he rightmost
position, all panel switches are unlocked and the panel may be used in its
entirety.

\section{Using the Front Panel}

This section describes how to use the computer via the front panel.

\subsection{Power}

Insert the key in the key switch. Turn the key to the \sw{PANEL}
position. The computer activates, performs power supply diagnostics,
goes through a reset cycle, and halts itself. The \lt{STOP} light
should illuminate at this point, and the Program Counter will indicate
a binary address of \bin{1111·1111·1111·0000}, or \hex{FFF0}.

\subsection{Boot from ROM}

With the computer freshly powered up and halted, or halted and reset,
move the \sw{ROM BNK}/\sw{RAM BNK} switch to the \sw{ROM BNK}
position.

Depress the \sw{RUN} or \sw{START} switch.

The computer boots from ROM address \hex{FFF0} and begins execution.

You may now secure the front panel by turning the key switch to the
\sw{ON} position.

\subsection{Toggle in Boot Code}

Ensure the computer is freshly powered up and halted, or halted and reset.

Set the Switch Register for a low value such as \bin{0000·0100·0000·0000}
(1kWord from start of memory). Depress \sw{SET ADDR}.

Set the Switch Register for the first value of the bootstrap
code. Depress \sw{MEMORY DEP NEXT}. Repeat as required.

Reset the Switch Register for the initial address of the bootstrap
program. Depress \sw{SET ADDR}.

Depress \sw{RUN}. The computer starts execution of the code from the
specified address.

You may now secure the front panel by turning the key switch to the
\sw{ON} position.

\subsection{Halting the Computer Forcibly}

With the key switch in the \sw{PANEL} position, depress \sw{STOP}. The
computer halts.

\subsection{Resetting the Computer}

With the key switch in the \sw{PANEL} position, depress \sw{RESET} or
\sw{START}. The computer resets. If the computer is running, ROM must
be fitted and the \sw{ROM BNK}/\sw{RAM BNK} switch must be in the
\sw{ROM BNK} position.

\subsection{Debugging with the Front Panel}

The front panel may be used to interrupt normal computer operation and
inspect or modify its state for debugging purposes. The computer can
then resume operation. The user should, however, be aware of a number
of considerations when using the front panel to do this:

\begin{itemize}
\item Operating the \sw{STOP} switch halts the computer
  mid-instruction. With a microprogram in execution, registers and
  control units may change. If necessary, the \sw{uSTEP} switch should
  be operated to complete the microprogram, that is until the
  \lt{FETCH} light illuminates. After which, if desired, the
  \sw{uSTEP} switch may be operated repeatedly until the \lt{EXECUTE}
  light illuminates, at which point an instruction has just been
  fetched and is about to be executed. It is safe to use the front
  panel for macro-debugging at this point.
\item Using the \sw{SET ADDR} switch modifies the \PC. When the
  computer resumes operation, this will effectively jump to the
  address set via the front panel. If this is not desired, the user
  must note the value of the \PC and manually restore it before
  continuing.
\item Using the memory and I/O functions also cause the \MAR{} to
  change. This is safe to do when using the \sw{STEP} switch, but not
  mid-microprogram.
\item Obviously, modifying the \IR{}, memory or I/O devices can have
  side effects on the running of the computer, but this is a desired
  feature of any control panel.
\end{itemize}

\section{Hardware Description}

\begin{figure*}
\centering
\includelarge[width=0.8\textwidth]{figs/front-panel-controller-dip.jpg}\\
\caption[Rendered view of an assembled Front Panel
  Controller board]{\label{fig-rendered-fpc-dip}Rendered view of an assembled Front Panel
  Controller board. This is the original, \abbr{DIP} attempt and is shown here for
  historical reasons.}
\end{figure*}

\begin{figure*}
\centering
\includelarge[width=0.8\textwidth]{figs/front-panel-controller-smd.jpg}\\
\caption{\label{fig-rendered-fpc-smd}Rendered view of the \abbr{SMD} revision of the
  Front Panel Controller board.}
\end{figure*}

The Front Panel comprises three distinct parts (though parts 2 and 3
may be implemented on the same physical board):

\begin{enumerate}
\item{\bfseries The Front Panel Controller Card} contains most of the front
  panel logic.
\item{\bfseries The Front Panel Driver and LED Board} hosts the LEDs and
  their drivers, as well as the Multi-Function display logic. The LED
  banks are connected directly to the corresponding processor hardware
  (e.g. the register card) using 8 or 9-conductor flat cables.
\item{\bfseries The Front Panel Debounce and Switch Board} hosts the switches
  and their debounce circuitry.
\end{enumerate}

\subsection{Connectors}

The Front Panel Controller Card connects to the switch and LED boards
via six 8-conductor cables.

\begin{table}[tb]
  \caption{\label{tab-connectors}Connections between the front panel
    and the processor.}
  \footnotesize
  \centering
  \zebra
  \begin{tabular}{llcll}
    \noalign{\smallskip}\hline\noalign{\smallskip}
    Function & Name & Conductors & From & To \\
    \noalign{\smallskip}\hline\noalign{\smallskip}
    Switch Register Low      & CON1  & 8 & Switch board & Front Panel Controller \\
    Switch Register High     & CON2  & 8 & Switch board & Front Panel Controller \\
    Memory Banking Status    & CON3  & 9 & Memory Banking board & Front Panel LED board \\
    \A{} Low                 & CON4  & 8 & Register or ALU board & Front Panel LED board \\
    \A{} High                & CON5  & 8 & Register or ALU board & Front Panel LED board \\
    \PC{} Low                & CON6  & 8 & Register board & Front Panel LED board \\
    \PC{} High               & CON7  & 8 & Register board & Front Panel LED board \\
    \IR{} Low                & CON8  & 8 & Control board & Front Panel LED board \\
    \IR{} High               & CON9  & 8 & Control board & Front Panel LED board \\
    Microcode Vector Low     & CON10 & 8 & Control board & Front Panel LED board \\
    Microcode Vector Medium  & CON11 & 8 & Control board & Front Panel LED board \\
    Microcode Vector High    & CON12 & 8 & Control board & Front Panel LED board \\
    Flags                    & CON13 & 5 & Control board \& ALU & Front Panel LED board \\
    Output Register Low      & CON14 & 8 & Front Panel Controller & Front Panel LED board \\
    Output Register High     & CON15 & 8 & Front Panel Controller & Front Panel LED board \\
    \DR{} Low                & CON16 & 8 & Register board & Front Panel LED board \\
    \DR{} High               & CON17 & 8 & Register board & Front Panel LED board \\
    Microcode Address Low    & CON18 & 8 & Control board & Front Panel LED board \\
    Microcode Address High   & CON19 & 7 & Control board & Front Panel LED board \\
    Interrupt Flag Status    & CON20 & 8 & Interrupt Controller board & Front Panel LED board \\
    Interrupt Enable Status  & CON21 & 8 & Interrupt Controller board & Front Panel LED board \\
    Control switches 1       & CON22 & 8 & Switch board & Front Panel Controller \\
    Control switches 2       & CON23 & 8 & Switch board & Front Panel Controller \\
    Miscellaneous signals    & CON24 & 9 & Switch board & (various cards) \\
    Miscellaneous LEDs (×3)  & SV1   & 6 & Any required & Front Panel LED board \\
    \noalign{\smallskip}\hline\noalign{\smallskip}
  \end{tabular}
\end{table}

\subsection{Front Panel Configuration}

The front panel is configurable using jumpers and trimmers.

\subsubsection{\sw{STEP} Autorepeat Tuning}

The autorepeat delay and repeat rate may be modified by varying the
trimmers \schpt{R1} (autorepeat delay) and \schpt{R4} (repeat
rate). Please ensure that the autorepeat rate is not faster than the
slowest CPU clock, otherwise the instruction stepping mechanism will
break.

\subsubsection{Fetch/Execute Decoder}

The fetch/execute decoder is used to control the \lt{FETCH} and
\lt{EXEC}. It also provides input to the Front Panel Controller so
that instruction stepping stops immediately after a fetch cycle. Fetch
decoding compares the least significant bits of the 4-bit μPC register
(the high order bit is assumed to be 0, since no microcode ROM is
expected to have an 8-step fetch cycle). The \abbr{DIP} switch block
\schpt{SW1} encodes (in binary) the value of the μPC for the first
step of the {\em Execute\/} cycle. For Microcodes up to version 3,
this value is 3 (\bin{011}).

\subsubsection{Light Control Jumpers}

A number of three-pin jumpers on the front panel control the behaviour
of many banks of console lights depending on the position of the
\sw{VERBOSE}/\sw{TERSE} switch. A jumper shunt may be placed across
pins 1–2 to leave a bank on regardless of the setting of the switch,
or across pins 2–3 to allow the bank to be turned off when the
\sw{VERBOSE}/\sw{TERSE} switch is in the \sw{TERSE} position.

If non-CMOS technology is used for the front panel LED buffers (e.g. 74LS541N
instead of 74HC541N), removing the jumper shunt altogether disables the light
bank. \caution{This setting can cause erratic behaviour and/or damage to CMOS
  light buffers.}

This is a list of light control jumpers:

\begin{description}
\item{\schpt{JP1}} — the Memory Banking display. 
\item{\schpt{JP2}} — the Instruction Register display.
\item{\schpt{JP3}} — the Microcode Vector display.
\item{\schpt{JP4}} — the Flag display.
\item{\schpt{JP5}} — the Interrupt Status display.
\end{description}

\subsection{Connections}

The front panel boards connect to the processor by means of numerous
8-way connectors, shown in~\tcf{tab-connectors}.

\section{Theory of Operation}

The front panel is an unexpectedly complex device with a number of
interwoven parts, and merits some description.

\subsection{Switches}

In their most general form, front panel switches connect between ground and the
input pin of a CMOS device. When switches are closed, they provide a logic 0 to
the attached circuitry. When they are opened, they float — this necessitates a
pull-up resistor for each switch to provide a logic 1. The pull-ups are placed
nearest the IC inputs, especially in cases where the switches are connected via
connectors that may malfunction or break.

\subsection{Switch Lock-Out}

Many switches can be secured against accidental or malicious operation. There
are two mechanisms to provide this feature:

\begin{itemize}
  \item The \ns{LOCK} signal. This is at +0V when the panel is unlocked, and a
    high-impedance line when the panel is locked.  The panel key switch
    physically connects the \ns{LOCK} signal to ground when the panel is
    unlocked, so the fan-out of this signal is not an issue.  Switches
    connecting to this signal rather than ground will only register when the
    \ns{LOCK} is at ground level, which will only happen when the key lock is
    in the \sw{PANEL} position.  This is used by the asynchronous action
    switches in the system, namely \sw{RUN}, \sw{STOP}, \sw{IFR1} and
    \sw{IFR6}.

  \item The \ns{SAFE} signal. This is generated by an open-drain NAND gate
    which combines the \ns{SWINHIBIT} and \ns{LOCK} signals. \ns{SWINHIBIT} is
    an input from the Front Panel Controller card, and is low when the system
    is running. When either \ns{SWINHIBIT} or \ns{LOCK} are low, the open drain
    NAND gate is in the high-Z state, effectively disconnecting \ns{SAFE} and
    rendering useless those switches that use it. When both \ns{SWINHIBIT} and
    \ns{LOCK} are high (inactive), the open drain NAND gate sinks current, and
    any switches using \ns{SAFE} can be operated. This is used for switches
    that should have no effect while the system is running, or the panel is
    locked.
\end{itemize}

Please consult~\tcf{tab-swlockout} for a listing of front panel switches and
how they are locked out.

\subsection{Switch Debouncing}

Switches are debounced using the fairly standard circuit illustrated
in~\fcf{fig-switch-debounce}. The passive components smooth the effect of the
switch bouncing and provide a fairly sluggish ramp up (or down). The Schmitt
trigger inverter converts this to the appropriate logic value. The values of
the resistors and capacitor may be changed to accommodate various types of
switch pathology. This debouncer is purposefully slow, since the front panel is
not meant to have sub-millisecond responses.

\begin{figure}
\centering
\includeimage[width=0.85\columnwidth]{figs/debouncing}\\
\caption{\label{fig-switch-debounce}Switch debouncing.}
\end{figure}

\begin{table}[tb]
  \footnotesize
  \caption[Front Panel switch lock-out]{\label{tab-swlockout}Switch lock-out. Switches locked out with
    \ns{SAFE} are enabled with the panel unlocked and the processor
    stopped. Switches locked out with \ns{LOCK} are enable with the panel
    unlocked.}  \centering
  \zebra
  \begin{tabular}{lp{0.4\textwidth}p{0.3\textwidth}}
    \noalign{\smallskip}\hline\noalign{\smallskip}
    Switch & Function & Lock out \\
    \noalign{\smallskip}\hline\noalign{\smallskip}
    \schpt{S1–S16} & Switch Register bits 0–15 & Not locked out. Read by software or actuation of other switches) \\
    \schpt{S17} & Key switch & Not locked out. Provides lock-out mechanism to other switches. \\
    \schpt{S18} & \sw{VERBOSE}\ /\ \sw{TERSE}       & Not locked out, only modifies front panel output.\\
    \schpt{S19} & \sw{ROM HI}\ /\ \sw{RAM HI}       & \ns{SAFE}.\\
    \schpt{S20} & \sw{FAST}\ /\ \sw{SLOW}\ /\ \sw{TEST} & \ns{SAFE}.\\
    \schpt{S21} & \sw{uSTEP}\ /\ \sw{STEP}          & \ns{SAFE}.\\
    \schpt{S22} & \sw{START}\ /\ \sw{RESET}         & \ns{LOCK}.\\
    \schpt{S23} & \sw{LOAD ADDR}                & \ns{SAFE}.\\
    \schpt{S24} & \sw{LOAD IR}\ /\ \sw{LOAD AC}      & \ns{SAFE}.\\
    \schpt{S25} & \sw{MEMORY DEPOSIT}\ /\ \sw{MEMORY DEP NEXT} & \ns{SAFE}.\\
    \schpt{S26} & \sw{MEMORY EXAMINE}\ /\ \sw{MEMORY EXAM NEXT} & \ns{SAFE}.\\
    \schpt{S27} & \sw{I/O DEPOSIT}\ /\ \sw{I/O DEP NEXT} & \ns{SAFE}.\\
    \schpt{S28} & \sw{I/O EXAMINE}\ /\ \sw{I/O EXAM NEXT} & \ns{SAFE}.\\
    \schpt{S29} & \sw{OUTPUT REG}\ /\ \sw{DR}\ /\ \sw{uADDR VEC} & Not locked out, only modifies front panel output.\\
    \schpt{S30} & \sw{RUN}\ /\ \sw{STOP}            & \ns{LOCK}.\\
    \schpt{S31} & \sw{IFR6}\ /\ \sw{IFR1}           & \ns{LOCK}.\\
    \noalign{\smallskip}\hline\noalign{\smallskip}
  \end{tabular}
\end{table}

\subsection{Sequencing}

A simple sequencer based on two dual 74LS123 multivibrator chips is used to
provide timing for the front panel's memory and I/O functionality. The
waveforms are neither as accurate nor as fast as the ones generated by the
control unit itself, but the front panel is a human interface device, so this
is not a requirement. The waveforms {\em are\/} properly interlocked to allow
read and write access to memory and I/O-space locations. 

The sequencer starts when any of the ‘exam’ or ‘deposit’ switches are actuated,
in either the normal or increment (‘next’) position. This includes eight
functions: \sw{MEMORY DEPOSIT}, \sw{MEMORY DEP NEXT}, \sw{MEMORY EXAMINE},
\sw{MEMORY EXAM NEXT}, \sw{INPUT/OUTPUT DEPOSIT}, \sw {INPUT/OUTPUT DEP NEXT},
\sw{INPUT/OUTPUT EXAMINE} and \sw{INPUT/OUTPUT EXAM NEXT}.

\begin{table}[tb]
  \caption[Internal wiring of the Memory and I/O switches]{\label{tab-fpcycles}The internal wiring of the eight memory and I/O
    switches (provided by four physical momentary switches with momentary up
    and down positions).}  \centering
  \footnotesize
  \zebra
  \begin{tabular}{lccccc}
    \noalign{\smallskip}\hline\noalign{\smallskip}
    Switch & \ns{FPWMEM} & \ns{FPRMEM} & \ns{FPWIO} & \ns{FPRIO} & \ns{FPINCADDR} \\
    \noalign{\smallskip}\hline\noalign{\smallskip}
    \sw{MEMORY DEPOSIT} & Assert & & & & \\
    \sw{MEMORY DEP NEXT} & Assert & & & & Assert \\
    \sw{MEMORY EXAMINE} & & Assert & & & \\
    \sw{MEMORY EXAM NEXT} & & Assert & & & Assert \\
    \sw{INPUT/OUTPUT DEPOSIT} & & & Assert & & \\
    \sw{INPUT/OUTPUT DEP NEXT} & & & Assert & & Assert \\
    \sw{INPUT/OUTPUT EXAMINE} & & & & Assert & \\
    \sw{INPUT/OUTPUT EXAM NEXT} & & & & Assert & Assert \\
    \noalign{\smallskip}\hline\noalign{\smallskip}
  \end{tabular}
\end{table}

Depending on whether it was a \sw{MEMORY} or \sw{INPUT/OUTPUT} switch, whether
it was a \sw{EXAMINE} (read) or \sw{DEPOSIT} (write) switch, and whether or not
the \sw{NEXT} (increment address) function was selected, the sequencer connects
its four outputs to appropriate bus lines to perform the requested cycle. 

consists of a tri-state buffer and
a pull-up resistor. The buffer's enable line is connected to the \ps{RUN}
signal. When the processor is running, the buffer tri-states its output. The
pull-up resistor ensures

The raw sequencer outputs are shown in~\fcf{fig-panel-mc}. Please note that, in
order to show the relationships of the timing rather than the widths of the
pulses, the waveforms are not to scale.

The sequencer starts on the falling edge of \ns{MCSTART}, obtained by ANDing
the front panel signals \ns{FPWMEM}, \ns{FPRMEM}, \ns{FPWIO} and \ns{FPRIO}.

Signals \ns{MC0} and \ns{MC1} are synchronised with the falling edge of
\ns{MCSTART}. Signals \ns{MC2} and \ns{MC3} are synchronised with the rising
edge of \ns{MC1}. This forms two separate sub-cycles in the waveform. The first
sub-cycle is used to load the \MAR{} register with the current address stored
in the \PC{} register. The second sub-cycle is responsible for the memory or
I/O operation, and is also responsible for incrementing \PC{} if the
\ns{FPINCADDR} signal has been asserted.

When the sequencer is idle, all of its outputs are tri-stated to avoid
contending with the control unit. The sequencer must not be started with the
processor operating. To avoid this, a safety interlock is in place. The buffer
lies between the output of the And gate and the \ps{MCSTART} signal. With the
buffer tri-stated, the pull-up resistor pulls \ps{MCSTART} high, disabling the
sequencer. When the buffer is enabled, the And gate is allowed to drive
\ps{MCSTART} low, starting the sequencer.

Please refer to~\fcf{fig-panel-mcw} for the write cycle waveform
and~\fcf{fig-panel-mcr} for the read cycle waveform. Both apply to memory and
I/O operations. \ns{INCPC} is only strobed if the respective switch was
operated in the ‘next’ position, i.e.\ \ns{FPINCADDR} strobed. Control signals
are tri-stated when \ns{MCSTART} is high, which implies that the front panel
switch must be held active by the operator until the end of the cycle. This is
not expected to be a problem, as the entire cycle typically lasts approximately
180–900~ns.

\subsubsection{Wait States and the Front Panel}

For simplicity, the front panel's sequencer ignores the \ns{WS} signal
entirely. Memory and I/O cycles cannot be prolonged
externally. However, since the front panel is operated by humans, its
memory and I/O cycles have a period in the order of milliseconds,
three orders of magnitude slower than the processor's otherwise
equivalent cycles. This accommodates even the slowest devices.

There may be exotic exceptions and subtle ways of abusing the
\gls{Wait State} mechanism which the front panel fails to activate or
take advantage of. This is a limitation of the design, but it keeps
the chip count low.

\subsubsection{Sequencer Glitch}

Due to the design of the sequencer, a cycle will be {\em aborted\/}
should the actuating switch be released during the course of the
cycle. This is an unlikely occurrence, since the cycle period is in
the order of milliseconds, but is worth noting.

\begin{figure}[tb]
\centering
\inputfigure{figure-panel-mc}
\caption[Waveforms generated by the front panel
  sequencer]{\label{fig-panel-mc}Waveforms generated by the front panel
  sequencer. The front panel controller connects these waveforms to different
  control unit signals to allow read and write access to memory and I/O space
  locations.}
\end{figure}

\begin{figure}[t]
\centering
\inputfigure{figure-panel-mcr}
\caption[Memory (or I/O) read cycle]{\label{fig-panel-mcr}
  Memory (or I/O) read cycle. \ns{INCPC} is only
  strobed if \ns{FPINCADDR} has been asserted.}
\end{figure}

\begin{figure}[t]
\centering
\inputfigure{figure-panel-mcw}
\caption[Memory (or I/O) write cycle]{\label{fig-panel-mcw} Memory (or
  I/O) write cycle. \ns{INCPC} is only strobed if \ns{FPINCADDR} has
  been asserted.}
\end{figure}

\subsection{The Front Panel System Device}

The front panel contains a System Device: hardware attached to the computer's
expansion bus and addressable by the processor by means of I/O
operations. System devices occupy I/O space addresses between
\hex{0000}–\hex{00FF} (inclusive). The processor provides the convenient signal \ns{SYSDEV}
on the bus, driven low when I/O addresses in this range are selected.

The Front Panel Controller uses this to decode I/O space addresses
\hex{0008}-\hex{000F} using a 74x688 comparator and two 74x138 demultiplexers
(one for reading, one for writing). Of the total sixteen control lines, four
are used to provide the following four CFT I/O addresses:

%% \extcmd{SR0}{IN R \&8}{4408}{-r-vehf}{008}%
%%        {PFP, Read Switch Register}%
%%        {%
%%          Reads 16 bits from the front panel Switch Register into the
%%          \gls{Accumulator}. This allows a program to read input from the panel operator.

%%          Verilog support for this is rudimentary.
%%        }

\extcmd{SR1}{IN R \&9}{4409}{-r-vehf}{009}%
       {PFP, Read DIP Switch Register}%
       {%
         Reads 16 bits from the Front Panel Controller DIP
         switches. This is used to provide a set of ‘turn-key’
         settings to the operating system, such as the address of a
         boot block, the base address of a console, serial parameters,
         et cetera. The semantics of the DIP switches have not yet
         been decided on. Two or three of them may be hard-wired to
         allow autodetection of the CFT platform (Verilog, Emulation
         or Hardware).

         Verilog support for this is rudimentary.
       }

\extcmd{FPOR}{OUT R \&a}{540a}{-r-vehf}{00a}%
       {PFP, Write Front Panel Output Register}%
       {%
         Writes 16 bits from the \gls{Accumulator} to the front panel
         Output Register. This may be used to output data to the panel operator.

         Verilog support for this is rudimentary.
       }

\extcmd{HALT}{OUT R \&a}{540a}{c-wvehf}{00a}%
       {PFP, Halt Processor}%
       {%
         Stops the computer, simulating the actuation of the front
         panel \sw{STOP} switch. The computer can only be resumed from
         the front panel.
       }

Most normal peripherals attach themselves to the Address Bus and Data Bus,
relying on the processor to connect the latter to the \IBUS{} when a memory or
I/O operation is taking place. The Front Panel System Device attaches to the
Address Bus and {\em \IBUS{}\/} instead. \caution{Note: this is a bug. It must
  be fixed, or bus contention may occur.}

\section{Front Panel Assembly Construction}

The following sections contain bills of materials, part indexes and schematics
for the Front Panel Assembly which contains the lights and switches of the
front panel.

%% \subsection{Bill of Materials}

%% This section provides a bill of materials for the front panel assembly. This
%% is meant for personal reference, and is not exhaustive by any means.

%% This project is not endorsed, funded or supported by Farnell or RS Components
%% in any way.

%% \bomv{front-panel}

%% \subsection{Part Index}

%% This section provides an index of parts used on the front panel. It is
%% provided for reference only, and is not necessarily correct.

%% This project is not endorsed, funded or supported by Farnell or RS Components
%% in any way.

%% \bomp{front-panel}

%
% Controller
%

\section{Front Panel Controller}

The following sections contain bills of materials, part indexes and schematics
for the Front Panel Controller board which interfaces the Front Panel Assembly
to the processor and computer at large.

%% \subsection{Bill of Materials}

%% This section provides a bill of materials for the front panel controller. This
%% is meant for personal reference, and is not exhaustive by any means.

%% This project is not endorsed, funded or supported by Farnell or RS Components
%% in any way.

%% \bomv{front-panel-controller}

%% \subsection{Part Index}

%% This section provides an index of parts used on the front panel controller. It is
%% provided for reference only, and is not necessarily correct.

%% This project is not endorsed, funded or supported by Farnell or RS Components
%% in any way.

%% \bomp{front-panel-controller}

%%  LocalWords:  documentclass CFT Alexios PDP autoindexing Von LSI Chouchoulas
%%  LocalWords:  Neumann microprograms microprogram microinstructions Bauform
%%  LocalWords:  et cetera kiloword KWord kilowords KWords Autoindex rp GND CLC
%%  LocalWords:  SUBRET JSR TRAPRET ISRRET ISR autoindex th FC FFF tl RSTIN tri
%%  LocalWords:  FFFF pagerel vlgrey linewidth fillstyle fillcolor de GPULSE lp
%%  LocalWords:  addr FFFE IOT LIA JMP bitwise ORred asm bitfield CLA DMA IRQ
%%  LocalWords:  CLL RBL RBR RNL RNR NOP linearc SNA SZA SSL SNN SNZ LEDs
%%  LocalWords:  SCL CLI STI SNP lll RET RTT SBL SBR SNL SNR TTY AEXT Debounce
%%  LocalWords:  disjuncted conjuncted ANDed MWord MEM uSTEP DEP BNK Autorepeat
%%  LocalWords:  microinstruction kWords IFR uADDR VEC kWord llcll SV SWINHIBIT
%%  LocalWords:  ALU Microcodes CMOS HC Farnell swlockout Debouncing

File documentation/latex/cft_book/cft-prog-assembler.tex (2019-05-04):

\HtmlMetaDescription{This chapter describes the CFT's Standard
  Assembler language, and how to use its advanced symbolic features to
  code complex projects in CFT Assembly.}
%\HtmlMetaGoogleDescription{}
%\HtmlMetaBanner{}
%\HtmlMetaTags{}

\section{Introduction}

  This document discusses the design and operation of the CFT Standard
  Assembler, introduced as the first and main implementation tool for
  writing CFT software. The CFT is a solid-state, 16-bit, microcoded
  architecture reminiscent, among others, of the DEC PDP-8. The
  computer incorporates a 16-bit word width with separate memory and
  input/output addressing spaces and a minimal, orthogonal instruction
  set that is still particularly versatile. The design includes
  separate internal (processor) and external (peripheral) buses and is
  extensible both via processor extensions and peripherals. The
  instruction set is extensible in the style of the PDP-8 using
  instruction-level aliasing (instruction macros) and assembler macros.

  The Standard Assembler is capable of producing optimised code for
  the CFT that takes advantage of the architecture's idiosyncrasies,
  and avoids the pitfalls of its many peculiarities.

  The Standard Assembler is a cross-compilation tool, written in
  Python to run on Unix and Unix-like computers. A possibly simplified
  version of the Standard Assembler is intended to be included as part
  of the CFT Forth Operating System, and possibly as a more
  full-featured stand-alone, native version.

\section{Architecture}

The Standard Assembler is a text-book multiple pass assembler with a
simple macro facility. It includes a ‘permanent’ symbol table with
macro definitions for the standard CFT instruction set as outlined in
the Programming Guide, in \cf{prog-guide}.

\subsection{The Cross Assembler}

The Cross Assembler is implemented in Python 2.6, but will probably run on
Python 2.4 or newer. It compiles the current version of ROM Forth in under two
seconds, which is quite acceptable performance. The choice of language also
makes it very easy to modify the assembler as necessary without much effort.

\section{Syntax}

Assembler syntax is simpler than the average assembler, to match the
simpler structure of the CFT.

Lines consisting of white space are ignored. Every other line must
contain one or more of the following:

\begin{itemize}
\item Comments.
\item Instructions.
\item Origin specifications.
\item Label declarations.
\item Assembler directives.
\item Macros.
\end{itemize}

\subsection{Comments}

Comments are introduced with the slash (\f{/}) or semicolon (\f{;})
characters. Conventional comments follow a C++-style (\f{//}) or Assembly
(\f{;;}) conventions, but this is not mandatory.

Any text after the first comment character is ignored, as expected.

\subsection{Instructions}

An instruction is one 16-bit value.

Each 16-bit instruction must be composed of one or more ‘fields’, each
separated by one or more spaces. All the values specified on a line get ORred
together to form an aggregate which is then assembled at the current address.

Each field must be one of the following things:

\begin{itemize}
  \item Symbols.
  \item Literal values.
  \item Expressions involving symbols and/or literal values.
\end{itemize}

\subsubsection{Symbols}

A symbol is a sequence of one or more symbol characters. The first character
must be an alphabetic character or an underscore (\f{\_}). Subsequent characters
may be alphanumeric or underscores.

Any symbol in the symbol table may be used as an instruction field, no matter
what its semantics are. Examples include opcodes such as \op{LOAD}, simple
field values such as \op{R}, labels, or other symbols.

Labels are treated specially if included in an instruction: the label's value (its
address), is masked by ANDing with value \hex{3FF}$_{16}$. In this format, a label
will fill the instruction's 10-bit operand field.

\subsubsection{Literal Values}

CFT Assembly supports 16-bit literal values in three formats:

\begin{description}
\item{\bfseries Decimal} A plain numerical value consisting of one to five digits
  between \f{0} and \f{9}.
\item{\bfseries Hexadecimal} The character \f{\&} or sequence \f{0x} followed by 1–4 digits,
  each between \f{0}–\f{9} or \f{A}–\f{F}. Lower case letters may also be used.
\item{\bfseries Binary} The character \f{\#} followed by 1–16 binary digits (\f{0} or
  \f{1}). To aid in defining readable bitfields, single quotes \f{'} and commas
  \f{,} are ignored. Additionally, dashes (\f{-}), periods (\f{.}) and
  underscores (\f{\_}) are treated as \f{0}. This allows bitfields to be
  defined as \f{\#----'0010}, clearly indicating ‘don't-care’ bits.
\end{description}

\subsubsection{Expressions}

Expressions perform simple arithmetic at assembly time. They come in three basic
formats:

\begin{description}

\item{\bfseries Current address}: \f{@}. A single at-sign (\f{@}) is replaced by the
  current address.

\item{\bfseries Relative address}: \f{@+{\bfseries value}} or \f{@-{\bfseries value}}. The value
  (which may be any parseable field value) is added or subtracted from the
  current address, and the result replaces the expression.

\item{\bfseries Full expression}: \f{@{\bfseries a op b}}. The operator {\bfseries op} is one of
  \f{+}, \f{-}, \f{*} (multiplication), \f{/} (division), \f{|} (bitwise OR),
  \f{\&} (bitwise AND), or \f{\char`\^} (bitwise XOR). There should {\em no space
    between the operator and the two operands}. For example, \f{@someLabel+\&80}
  is valid, while \f{@someLabel + \&80} is invalid. The two operands {\bfseries a} and
  {\bfseries b} are any parseable fields.

\end{description}

\subsection{Setting the Origin}

The origin is the next address to be assembled at. To set the origin, include a
literal value followed by a colon (\f{:}). For example, this sets the origin to
the CFT Reset vector at address \hex{FFF0}:

\begin{cftasmcode}
&FFF0:       ;; The CFT Reset Vector address
\end{cftasmcode}

\subsection{Labels}

Labels name a new symbol after the current address, so that the address can
then be referred to by name. Labels are essential in Assembly languages. They
simplify flow control and many other advanced tasks. A label is declared by
typing its name followed by a colon character (\f{:}). Multiple labels may be
set for the same address, one to a line. The origin may also be set. This is a
common idiom:

\begin{cftasmcode}
&FFF0:       ;; The CFT Reset Vector address
reset_vec:
reboot:
\end{cftasmcode}

Although declaring multiple labels for the same address is wasteful, it can
often lead to better readability.

\subsection{Directives}

A sequence of letters starting with a period (\f{.}) is a directive. Directives
control the asssembly process in a number of ways. They generally come in two
types: non-assembling directives modify the behaviour of the assembler by
defining new symbols, including files, declaring namespaces, etc. Assembling
directives cause one or more words to be assembled at the current location.

Conventionally, assembling directives are indented along with
code. Non-assembling directives are not indented, and are aligned with label
definitions.

\subsection{Namespaces}

Large assembly programs tend to define large numbers of symbols, and
this can lead to reduced code clarity, symbol naming clashes and bugs.

Namespaces help organise symbols into units, and aid in modular coding.

A namespace is defined by enclosing it in \f{.pushns} and \f{.popns}
directives:

\begin{cftasmcode}
.pushns foo
.equ bar &FFFF ; A definition
; ...
.popns
\end{cftasmcode}

All symbol definitions inside the namespaces are prefixed by the name
of the namespace (‘foo’ in this example), followed by a period. Inside
the namespace, \f{bar} can be used as is. Outside the namespace,
\f{foo.bar} must be used.

Namespaces can be nested. Code inside a namespace can access symbols
in nested namespaces, but not code outside its namespace.

\subsection{Scoping}

Most high level languages have the concept of scopes, which allows for
local variable definitions.

The Standard Assembler lacks local variables, and its scopes are very
similar to namespaces. In fact, scopes are essentially anonymous
namespaces. Their main purpose is to allow scope-local labels which
makes code significantly more readable. Scoping identify units
of functionality like algorithms.

Scopes can be used like this:

\begin{cftasmcode}
.scope
		LIA vectable
		STORE R &80
		LIA R ramvectable
		STORE R &81
loop:		LOAD I R &80
		SNZ
		JMP done
		STORE I R &81
		JMP loop
done:		
.endscope
\end{cftasmcode}

The labels \f{loop} and \f{again} will be undefined outside the scope.

Like namespaces and scopes in other languages, CFT Assembly scopes can
be nested. Symbols defined in a scope will be visible inside all
scopes nested within it.

\subsection{Defining Symbols}

\subsubsection{Defining Arbitrary Symbols with \f{.equ}}

The \f{.equ} directive defines a new symbol with an arbitrary value. The syntax is:

\begin{cftasmcode}
.equ symbol value
\end{cftasmcode}

Any valid symbol may be named, and any parseable value may be used:
instruction, label, or literal. The most common uses of \f{.equ} are in
defining instructions or constants. The following definitions are actually part
of the permanent symbol table of the CFT Standard Assembler and cover the basic
instruction set:

\begin{cftasmcode}
.equ TRAP  &0000
.equ IOT   &1000
.equ LOAD  &2000
.equ STORE &3000
.equ IN    &4000
.equ OUT   &5000
.equ JMP   &6000
.equ JSR   &7000
.equ ADD   &8000
.equ AND   &9000
.equ OR    &A000
.equ XOR   &B000
.equ OP1   &C000
.equ OP2   &D000
.equ ISZ   &E000
.equ LIA   &F000

.equ R     &0400
.equ I     &0800
\end{cftasmcode}

After definition, symbols may be used wherever parseable values may be used,
including in subsequent \f{.equ definitions}:

\begin{cftasmcode}
.equ LIA   &F000
.equ LI    LIA  R   ; &F000 | &0400
\end{cftasmcode}

This is exactly how the assembler defines the standard instruction macros, of
which \op{LI} is one.

\subsubsection{Declaring Registers with \f{.reg}}

The \f{.reg} directive works like the \f{.equ} directive, with one exception:
it declares a location in memory (usually Page 0) to be used as a register. For
example:

\begin{cftasmcode}
.reg  R0   R &10
.reg  R1   R &11
.reg  R2   R &12
.reg  R3   R &13

.reg  I0   R &80 ; Autoincrement registers
.reg  I1   R &81
.reg  I2   R &82
.reg  I3   R &83
\end{cftasmcode}

The difference between \f{.equ} and \f{.reg} is mainly one of semantics:
\f{.equ} can define such diverse entities as I/O locations, addresses, labels,
constants, flags, instructions, bit masks, et cetera — this sometimes makes it
difficult to divine the purpose of a symbol, even if good coding practices are
used. In contrast, \f{.reg} is meant only for register declaration, and this is
reflected in the various output files (map, symbol tables and graphical maps).

It is almost always useful to define registers with the \asm{R} field
set, as is done in the example above. This makes it simpler to
reference the registers without having to use \asm{R}, and reduces
bugs caused by the \asm{R} left out\footnote{Empirical evidence has
  shown that this is a very common and potentially insidious problem
  with CFT Assembly code.}.

\subsubsection{Declaring Register Arrays with \f{.regfill}}

Sometimes blocks of registers need to be declared — for example, to account for
a memory-mapped device with arrays of mapped values (such as a
framebuffer). The \op{.regfill} directive is used for that. It works exactly
like \op{.fill}, but also marks the filled area as a register array.

\subsection{Including Files}

The \f{.include} directive instructs the Assembler to read, process and
assemble an external file. It is used like this:

\begin{cftasmcode}
.include "some_file.asm"
\end{cftasmcode}

This (along with namespaces) may be used to break large programs into
manageable, semantically distinct blocks, or to allow libraries of
definitions or code to be defined and shared among programs.

\subsection{Directives that Assemble Data}

\subsubsection{Assembling Arbitrary Data with \f{.word}}

The \f{.word} directive assembles an arbitrary word at the current
address. Some examples of its syntax:

\begin{cftasmcode}
.word some_label  ; label address
.word @           ; assemble current address
.word @+10        ; current address + 10
.word STORE       ; assemble an instruction
.word 1 #10 &4 8  ; assemble decimal value 15
\end{cftasmcode}

Any parseable value may be assembled using the \f{.word} directive, including
instructions.

Unlike plain instruction assembly, \f{.word} does not treat labels specially:
when assembling the value of a label in an instruction, only the lower 10 bits
are used. With \f{.word}, all 16 bits are used. This makes \f{.word} invaluable
in generating vector tables and aiding in indirection.

\subsubsection{Filling Regions with a Value with \f{.fill}}

The \f{.fill} directive assembles a value and uses it to fill a block in the
object code starting with the current address. It syntax is:

\begin{cftasmcode}
.fill COUNT VALUE
\end{cftasmcode}

The \op{COUNT} must be a literal value. The \op{VALUE} may be any parseable
value, including symbols and instructions. For example, to assemble 50 copies
of the value \hex{0000}:

\begin{cftasmcode}
.fill 50 &0000
\end{cftasmcode}

To fill a region with an instruction:

\begin{cftasmcode}
.fill &10 HALT
\end{cftasmcode}

Please note that the value is calculated {\em once}, so relative addressing and
expressions will not have the expected effect. The following directive will
assemble 10 copies of the instruction \op{JMP 0}, {\em not\/} a chain of jumps
with increasing addresses, despite the use of \op{@}.

\begin{cftasmcode}
&1000:  .fill 10 JMP @
\end{cftasmcode}

\subsubsection{Unpacked Strings with \f{.str}}

An unpacked string is a block of memory which represents character text. Each
character occupies an entire word and has a 16-bit range. Unpacked strings can
contain Unicode characters in UCS-2 or UTF-16 encodings. They can, of course,
contain ASCII characters as well. Since the CFT is a word-addressed machine,
these are the easiest strings for the computer to handle.

The \f{.str} directive assembles a string of values starting at the current
address:

\begin{cftasmcode}
.str "Hello World!" 10 0
\end{cftasmcode}

Character data are enclosed in double quotes, but \f{.str} can handle multiple
fields including any parseable value from literals to instructions (of course,
the utility of assembling instructions with \f{.str} is very limited). This may
be used to embed non-printable values (and double quotes) in strings. In the
example above, there is an ASCII 10 (line feed, return or new line) after the
exclamation point, followed by an ASCII 0 (NUL), which is conventionally used
to terminate variable-length strings.

\subsubsection{Arbitrary Data Blocks with \f{.data}}

The \f{.data} directive works in exactly the same way as the \f{.str}
directive. They differ only in semantics. The latter is expected to be used for
character strings, the former for arbitrary data, which {\em does\/} include
character data. An example:

\begin{cftasmcode}
.data &1234 &5678 &9abc &def0 "ABCDEFG"
\end{cftasmcode}

\subsubsection{Negative-Terminated Strings with \f{.strn}}

Negative-terminated strings are unpacked strings in which end of string is
indicated by setting bit 15 on the last character. This allows characters with
codepoints between 0–32,767 to be used. If the upper 32,768 codepoints are not
necessary, this representation saves one word per string. The \f{.strn}
directive works in exactly the same way as the \f{.str} directive:

\begin{cftasmcode}
.strn "Hello World!" 10
\end{cftasmcode}

However, the last character of the string will be ORred with the value
\hex{8000}, to produce this sequence of values in memory:

\begin{intrcode}
0048 0065 006c 006c 006f 0020 0057 006f
0072 006c 0064 0021 800a
\end{intrcode}

Note that the terminating null conventionally added to the end of \f{.str}
directives is unnecessary here.

\subsubsection{Packed Strings with \f{.strp}}
\label{sec:asm-pstring}

Packed strings are the most compact means of encoding strings of 8-bit
characters (or Unicode characters encoded in UTF-8) on the CFT
architecture. Two characters are assembled per word, with the first character
in the lower eight bits. This byte order mirrors the way little-endian
byte-addressable machines work when dealing with strings, which makes CFT
binary files easier to examine on other computers\footnote{That is, the
  majority of computers owned by the author.}. The syntax of the \f{.strp} is
identical to that of \f{.str}:

\begin{cftasmcode}
.strp "Hello World!" 10 0
\end{cftasmcode}

This will generate the following sequence of words:

\begin{intrcode}
6548 6c6c 206f 6f57 6c72 2164 000a
\end{intrcode}

Obviously, strings with odd length will have 8 unused bits in the last
position. This string is even-length (the terminating null counts). This,
however, still makes the string much more compact than the equivalent unpacked
string. Unfortunately, it also makes it more difficult to handle in machine
code. CFT Forth makes heavy use of packed strings to keep the size of the
dictionary down.

\subsubsection{Multi-line Packed Strings with \f{.longstring}}
\label{sec:asm-longstring}

Packed strings spanning multiple lines of Assembly source code must be
declared as long strings. This mitigates the need for each line of a
multi-line string to contain even characters. Not doing that inserts
\hex{00} as the last character, since \f{.strp} must produce an integer
number of words. This inadvertently terminates the packed
string. Consider this (contrived) example:

\begin{cftasmcode}
.strp       "Hello"    ; 5 characters
.strp       " World!"  ; 7 characters
.strp       10         ; 1 character
\end{cftasmcode}

This will assemble to the following words, shown here broken up into
three lines corresponding to the \f{.strp} directives:

\begin{intrcode}
6548 6c6c 006f
5720 726f 646c 0021
000a
\end{intrcode}

Note the \hex{00} packed string terminator in the high order bits of
the last word of every line. To avoid this, use the \f{.longstring}
and \f{.endstring} directives like this:

\begin{cftasmcode}
.longstring "Hello "
.strp       "World!"
.strp       10
.endstring
\end{cftasmcode}

This will have the desired effect. The first line of the string may be
included on the \f{.longstring} line for brevity, or in subsequent
\f{.strp} lines for cleaner code. The \f{.endstring} directive accepts
no parameters.

\subsection{Controlling Paging}

Since the CFT is unable to reference ‘far’ addresses (across page
boundaries) without indirection, the vast majority of loops must not
cross page boundaries. Take this trivial loop, for example:

\begin{cftasmcode}
        LI 50
        NEG
        STORE R &10
loop:   ISZ R &10
        JMP loop
\end{cftasmcode}

Since addresses in instructions are 10 bits long, only the lower 10 bits of the
address of label \op{loop} are assembled in the \op{JMP} instruction. The upper
six bits are populated using the upper six bits of the current address
(i.e. the page). Now, assume \op{loop} is at address \hex{1FFF}. This places
\op{JMP} at address \hex{2000}, crossing a page boundary. The address in
\op{JMP} is still \hex{3FF} (the lower 10 bits of \hex{1FFF}, the address of
\op{loop}). However, the upper six bits are no longer \hex{1C00} (shifted) —
they are now \hex{2000}. Thus, the machine will jump to address \hex{23FF} and
the loop will fail. This is a problem common to all paged instruction sets.

The CFT Standard Assembler refuses to fix this automatically, instead producing a warning:

\begin{intrcode}
source.asm:5:warning: Label 'loop' on page 1c00,
  but page 2000 accessed instead.
\end{intrcode}

To solve this issue, code must be rearranged so that the loop does not cross
the page boundary. While developing, the easiest way to do this is to force
crossing the page boundary by changing the origin. This is the purpose of the
\f{.page} directive: it changes the origin to the first address of the next
page.

Please note that this should not be done inside subroutines, since a block of
unassembled values will be introduced. It should, instead, be placed just
before the entry point of a subroutine preceding the problem addresses.

The syntax is trivial:

\begin{cftasmcode}
.page
\end{cftasmcode}

A common issue is for \f{.page} directives to be left in the code while
developing, leading to large amounts of unused space. The assembler will let
the programmer know about potential cases of unnecessary \f{.page} directives
by issuing a warning:

\begin{intrcode}
file.asm:924:warning: .page generated 865 words of slack space.
\end{intrcode}

In such case, it is standard practice to comment out the directive (since
further coding is likely to push the problem code across another page boundary,
so the \f{.page} could be needed again).

\subsection{Instruction Macros}

The CFT instruction set contains sixteen main instructions, of which two allow
combinations of dozens of minor operations. Because of both the small size of
the instruction set and its versatility, many new instructions a programmer
would expect to have may be formed as combinations (or special cases) of other
instructions that are still technically one instruction.

For example, the CFT instruction set lacks shifts, but has rolls which rotate
the bits in the \AC{} register through the single-bit \Lreg{} register. An
unsigned shift may be implemented by clearing \Lreg{} before rolling, so that
the new instruction \op{SBL} is implemented by \op{OP1 CLL RBL}.

These instruction macros are defined inside the Standard Assembler using the
\f{.equ} directive and can be treated as {\em single} instructions. For example:

\begin{cftasmcode}
.equ   SBL   OP1 CLL RBL   ; Shift bit left
.equ   SBR   OP1 CLL RBR   ; Shift bit right
\end{cftasmcode}

\subsection{Assembler Macros}

In addition to defining instruction macros which expand the CFT {\em
  instruction set}, the Assembler also provides Assembler Macros which expand
the {\em assembly language}. Unlike instruction macros, assembler macros can
incorporate multiple instructions and are parametric. They are invaluable in
simplifying assembly listings and maintaining consistency.

\subsubsection{Defining New Macros}

New macros are defined with the \f{.macro} and \f{.end} directives. This is an
example of an ‘add with carry’ macro to provide addition with carry-in (which
cannot be implemented as a single CFT instruction):

\begin{cftasmcode}
.macro ADC (addr)
    OP1 IFL INC    ; Inc AC if L is set
    ADD %addr
.end
\end{cftasmcode}

The name of the macro is \op{ADC}, and this is how it will be called after its
definition. It accepts a single argument named \op{addr}. Please note that
macros without parameters {\em still} require the open and closing parentheses,
in the same way as C function definitions do.

Multiple arguments may be specified, separated by commas.

The code between \f{.macro} and \f{.end} is not assembled immediately — it is
stored for inclusion later.

Argument values may be used by prefixing their names with \f{\%}, hence the use
of \f{\%addr}.

\subsubsection{Calling Macros}

To call the \f{ADC()} macro, use this syntax:

\begin{cftasmcode}
ADC(R &10)
\end{cftasmcode}

The presence of the parentheses in an instruction line trigger a search for the
macro nominated before the opening parentheses. White space may be used between
the name and open parenthesis, but is not recommended to keep the code compact
and allow longer macro names.

Multiple argument values must be separated by commas.

The same number of values must be specified as there are arguments in the macro
definition. Macro calls may not have variable arguments lists. In the case of
\f{ADC}, exactly one argument may be specified. The value of the argument
depends on its use in the macro definition, but the vast majority are parseable
values.

\subsubsection{Unique Labels}

If a macro contains loops or declares labels and the macro is expanded multiple
times, some or all of those labels may need to be made unique. This may be done
by including the magic argument \f{\%\_} in any label names:

\begin{cftasmcode}
.macro MINILOOP(n, loopreg, op)
    LI %n
    NEG
    STORE %loopreg
miniloop%_:
    %op
    ISZ %loopreg
    JMP miniloop%_
.end
\end{cftasmcode}

Note the idiom of appending \f{\%\_} to the labels. The \f{\%\_} argument will
expand to a number to each macro expansion, making the label unique across the
assembly process. This is generally not recommended. If loops are necessary, it
may be better to implement them as subroutines.

\subsubsection{Advanced Use Patterns}

Because of the generality of the macro mechanism, some commonly performed
advanced tasks may be simplified greatly by using macros. A common use pattern
is to \asm{LOAD} a value, operate on it, then \asm{STORE} it back. This is a
side-effect of having a single-operand instruction set. Using advanced macros,
CFT Assembly may be expanded from single-operand to a more compact, more
readable three-operand format:

\begin{cftasmcode}
.macro RMOV(tgt, src) ; Move one register to another
	LOAD %src
	STORE %tgt
.end

.macro _RAPPLY(op, tgt, a, b) ; Apply an operation to a register
	LOAD %a
	%op %b
	STORE %tgt
.end

.macro RADD(tgt, a, b)
	_RAPPLY(ADD, %tgt, %a, %b)
.end

.macro RAND(tgt, a, b)
	_RAPPLY(AND, %tgt, %a, %b)
.end
\end{cftasmcode}

This now allows code to be written in this two- and three-operand idiom, very
reminiscent of RISC Assemblies like that of the MIPS Rx000.

\begin{cftasmcode}
        RMOV(R1, R3)            ;; mem[R1] = mem[R3]
        RMOV(R2, R4)            ;; mem[R2] = mem[R4]
        RADD(R0, R1, R2)        ;; mem[R0] = mem[R1] + mem[R2]
        RAND(R5, R1, R2)        ;; mem[R5] = mem[R1] & mem[R2]
\end{cftasmcode}

This is significantly more readable than the equivalent code without macros:

\begin{cftasmcode}
        LOAD R3                 ;; mem[R1] = mem[R3]
        STORE R1
        LOAD R4                 ;; mem[R2] = mem[R4]
        STORE R2
        LOAD R1                 ;; mem[R1] = mem[R2] + mem[R3]b
        ADD R2
        STORE R0
        LOAD R1                 ;; mem[R1] = mem[R2] + mem[R3]b
        AND R2
        STORE R5
\end{cftasmcode}

\section{Features}

The CFT Assembler includes various features to aid in debugging the object
code, simulating its execution in the CFT Emulator, as well as locating and
fixing issues with the Assembler itself.

\begin{figure}
\begin{cftasmcode}
&c000: &0cf7 ;         .word &0cf7             ; Magic (CFT)
&c001: &c000 ;         .word @-1               ; Origin addr.
&c002: &0001 ;         .word 1                 ; Number of programs
&c003: &0000 ;         .word 0                 ; Reserved
&c004:       ;         .strp "CFT Forth ROM 0.1            " 0
&c004: &4643 ; "CF" (U+0043 U+0046)
&c005: &2054 ; "T " (U+0054 U+0020)
&c006: &6f46 ; "Fo" (U+0046 U+006f)
&c007: &7472 ; "rt" (U+0072 U+0074)
&c008: &2068 ; "h " (U+0068 U+0020)
&c009: &4f52 ; "RO" (U+0052 U+004f)
&c00a: &204d ; "M " (U+004d U+0020)
&c00b: &2e30 ; "0." (U+0030 U+002e)
&c00c: &2031 ; "1 " (U+0031 U+0020)
&c00d: &2020 ; "  " (U+0020 U+0020)
&c00e: &2020 ; "  " (U+0020 U+0020)
&c00f: &2020 ; "  " (U+0020 U+0020)
&c010: &2020 ; "  " (U+0020 U+0020)
&c011: &2020 ; "  " (U+0020 U+0020)
&c012: &0020 ; " ." (U+0020 U+0000)
&c013: &c014 ;         .word init              ; Entry point
&c014: &70a1 ;         JSR init_tables
&c015: &707b ;         JSR init_serial
&c016: &707f ;         JSR init_isr
\end{cftasmcode}
\caption[Preprocessed Assembly Output Example]{\label{fig:pasm-file} Example of
  a Preprocessed Assembly file (\texttt{.pasm}). It shows the beginning of the
  ROM Forth, with ROM boilerplate and the beginning of the code. The file can
  be fed back to the assembler: it contains address/assembled value pairs with
  corresponding code in comments.}
\end{figure}

\begin{figure}
\begin{intrcode}
v_TFORTH                  0200  _generated_tables.asm:16
_vector_table             0200  forth.asm:66
v__NEXT                   0201  _generated_tables.asm:17
v__doLIST                 0202  _generated_tables.asm:18
v__doCOL                  0203  _generated_tables.asm:19
v__doVAR                  0204  _generated_tables.asm:20
v__doCONST                0205  _generated_tables.asm:21
v__do2CONST               0206  _generated_tables.asm:22
v__doUSER                 0207  _generated_tables.asm:23
v__doVOC                  0208  _generated_tables.asm:24
v__doDOES                 0209  _generated_tables.asm:25
v__EXIT                   020a  _generated_tables.asm:26
_vector_table_end         020b  forth.asm:71
_does_table               020b  forth.asm:72
_does_table_end           0300  forth.asm:74
UP0                       0300  forth.asm:211
user_area                 0400  forth.asm:224
data_stack                0500  forth.asm:227
\end{intrcode}
\caption[Map File Example]{\label{fig:map-file} Example of a Map File
  (\texttt{.map}). It shows labels, their values and the location of their
  definition in the source code.}
\end{figure}

\begin{figure}
\begin{intrcode}
Name                      Val   Type    Defined in
----------------------------------------------------------
PANEL                     0408  symbol  ../asm/io.asm:4
LSR                       4408  symbol  ../asm/io.asm:5
LDSR                      4409  symbol  ../asm/io.asm:6
SOR                       540a  symbol  ../asm/io.asm:7
HALT                      540f  symbol  ../asm/io.asm:8
TTY0                      0460  symbol  ../asm/io.asm:17
TTY1                      0468  symbol  ../asm/io.asm:18
TTY2                      0470  symbol  ../asm/io.asm:19
TTY3                      0478  symbol  ../asm/io.asm:20
TTYRHR                    0000  symbol  ../asm/io.asm:27
TTYTHR                    0000  symbol  ../asm/io.asm:28
\end{intrcode}
\caption[Symbol File Example]{\label{fig:sym-file} Example of a Symbol File
  (\texttt{.sym}). It tabulates the entire symbol table with name, value,
  symbol type, and location of definition.}
\end{figure}

\section{Output}

At the end of the assembly process, the Assembler outputs a number of files,
most of which are both machine and human-readable.

\subsection{Object Files}

The object code generated by the assembler is a pure binary file with no
headers or magic numbers. They are files containing 16-bit words, one per
assembled value, starting at the start address specified to the assembler, and
ending at the end address, also as specified to the assembler.

\subsection{Verilog List Files}

To help using the code with the Verilog-based hardware verification suite, the
Assembler also outputs a pair of {\ttfamily .list} files with suffixes {\ttfamily -00.list}
(low order bits) and {\ttfamily -01.list} (high order bits). These are encoded in
Verilog-compatible human-readable binary and represent low and high ROM images
for the assembled code.

\subsection{The Map File}

The map file is generated with a {\ttfamily .map} suffix, and contains a map of the
labels declared in the source code. It contains three columns:

\begin{enumerate}
\item Label Name.
\item Address in zero-padded hexadecimal.
\item Location of definition in the source code in {\ttfamily filename:line} format.
\end{enumerate}

Part of the map file for ROM Forth is shown in~\fcf{fig:map-file}.

\subsection{The Symbol Table File}

Similar to the map file, this file (with a {\ttfamily .sym} suffix) contains a dump
of the entire symbol table, not just labels. It has a two-line header for human
readability, and contains lines arranged in four columns:

\begin{enumerate}
\item Symbol Name.
\item Value in zero-padded hexadecimal.
\item Symbol type:
  \begin{itemize}
  \item \f{symbol}: a symbol declared by \f{.equ}.
  \item \f{label}: a label.
  \item \f{register}: a register declared by \f{.reg} or \f{.regfill}.
  \end{itemize}
  \item The location of the symbol definition in the source code in {\ttfamily filename:line} format.
\end{enumerate}

A partial example of a symbol file for ROM Forth is shown in~\fcf{fig:sym-file}.

\subsection{The Preprocessed Assembly File}

Files with a {\ttfamily .pasm} suffix are ‘preprocessed assembly’ files. They contain
a digested form of the program, which is valid input to the CFT assembler, but
much less human-readable. Each line contains an explicit address followed by
the exact hexadecimal value at that address. The original assembly line leading
to that value follows as a comment. Strings and other multi-word directives are
expanded to show what is assembled. Include directives and macros are
expanded. No labels or other symbols are used (but remain in the
comments). Lines without assembled values are excluded. For example, label
declarations on their own lines will be left out.

These files may be used as a kind of assembly-annotated hex dump of the object
file, and are also used by the CFT emulator to print out the assembly source it
is executing.

Part of the preprocessed output for ROM Forth is shown in~\fcf{fig:pasm-file}.

\subsection{Graphical Memory Maps}

These are bitmap images useful in visualising the memory map of the program,
and the layout of the object file. They are output in the {\ttfamily .xpm} format,
which {\em is\/} human readable, although these files are too large for a human
to visualise without software. Like all {\ttfamily .xpm} files, this file is also
valid C code. It may be viewed with most image viewers or converted to a binary
bitmap file to save space.

The memory map displays the 65,536 word address space of the CFT as an array of
256×256 locations, with rows representing higher order bits of the address, so
that address \hex{0000} is at the upper left, and address \hex{FFFF} is at the
lower right.

Grey represents unused locations. Black represents slack space left by
\f{.page} directives. Magenta areas are those declared with \f{.reg}, and those
are expected to be at or near the top, on page 0. Red represents assembled
instructions. Orange represents packed strings. Green is for unpacked
strings. Blue represents \f{.word} values, and cyan marks \f{.fill} areas.

\begin{figure}[t]
\centering
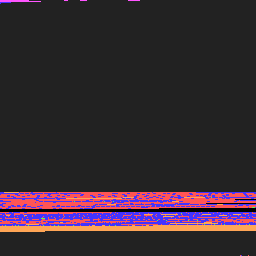
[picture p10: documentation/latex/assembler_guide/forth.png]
\\
\caption{\label{fig-graphical-map}A graphical memory map of a CFT assembly program.}
\end{figure}

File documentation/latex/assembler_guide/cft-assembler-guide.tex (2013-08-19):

\documentclass[11pt,a4paper,twocolumns]{article}
\usepackage[table]{xcolor}
\newcommand\zebra{\rowcolors{2}{gray!20}{white}}
%\newcommand\zebra*[1]{\rowcolors{#1}{gray!10}{white}}
\usepackage[all]{xy}
\usepackage{pdftricks}
\usepackage{epsfig}
\usepackage{lipsum}
\usepackage{float}
\usepackage{verbatim}
\usepackage{geometry}
\usepackage{graphicx}
\usepackage{color}
\usepackage{epic}
\usepackage{eepic}
\usepackage{fontspec}
\usepackage[a4paper,CJKbookmarks,bookmarks=true,bookmarksopen=true]{hyperref}
\begin{psinputs}
\usepackage{color}
\usepackage{pstcol}
\usepackage{pstricks}
\usepackage{pst-plot}
\usepackage{pst-tree}
\usepackage{pst-eps}
\usepackage{multido}
\usepackage{pst-node}
\usepackage{pst-eps}
\end{psinputs}

\usepackage{tikz}
\usetikzlibrary{arrows}

\definecolor{darkblue}{RGB}{0,0,128}
\hypersetup{
    pdftitle={CFT Minicomputer Assembler Guide},
    pdfauthor={Alexios Chouchoulas},
    pdfkeywords={},
    bookmarksnumbered,
    pagebackref=true,
    breaklinks=true,
%    pdfview=FitH,       % Or try pdfstartview={FitV}, This lead to uncorrect bookmarks
    urlcolor=darkblue,
    colorlinks=true,
    citecolor=blue,          %citeref's color
    linkcolor=blue,
        }
% Fonts
%\defaultfontfeatures{Mapping=tex-text}
\setmainfont{Minion Pro}
\setsansfont{Myriad Pro}
\setmonofont[]{Inconsolata}

%\renewcommand{\rmdefault}{put}

\geometry{a4paper, hoffset=0in, voffset=-.25in, left=1.5cm, right=1.5cm,
  top=2.5cm, bottom=2.5cm}
\sloppy

% Use hyperlinking when renderind PDFs
\newcommand{\cf}[2][section]{\hyperref[#2]{#1 \ref*{#2} (p.~\pageref*{#2})}}
\newcommand{\npcf}[2][section]{\hyperref[#2]{#1 \ref*{#2}}}
\newcommand{\appcf}[1]{\cf[appendix]{#1}}
\newcommand{\ccf}[1]{\cf[chapter]{#1}}
\newcommand{\fcf}[1]{\cf[figure]{#1}}
\newcommand{\tcf}[1]{\cf[table]{#1}}
\newcommand{\ecf}[1]{\cf[equation]{#1}}
\newcommand{\algcf}[1]{\cf[algorithm]{#1}}
\newcommand{\npappcf}[1]{\npcf[appendix]{#1}}
\newcommand{\npccf}[1]{\npcf[chapter]{#1}}
\newcommand{\npfcf}[1]{\npcf[figure]{#1}}
\newcommand{\nptcf}[1]{\npcf[table]{#1}}
\newcommand{\npecf}[1]{\npcf[equation]{#1}}
\newcommand{\npalgcf}[1]{\npcf[algorithm]{#1}}

\setlength\columnsep{7mm}

\newcommand\hyperemail[1]{\sf\href{mailto:#1}{#1}}
\newcommand\link[1]{\sf\href{http://#1}{#1}}

\newcommand\op[1]{\texttt{#1}}
\newcommand\f[1]{{\color{black}\texttt{#1}}}
\newcommand\hex[1]{\textsf{#1}}
\newcommand\bus[1]{{#1}}
\newcommand\unit[1]{{#1}}
\newcommand\IBUS{\bus{IBUS}}
\newcommand\ALU{\unit{ALU}}
\newcommand\AGL{\unit{AGL}}
\newcommand\register[1]{\textsf{#1}}
\newcommand\A{\register{AC}}
\newcommand\Areg{\A}
\newcommand\Lreg{\register{L}}
\newcommand\Ireg{\register{I}}
\newcommand\Zreg{\register{Z}}
\newcommand\Vreg{\register{V}}
\newcommand\Nreg{\register{N}}
\newcommand\AR{\register{AR}}
\newcommand\MAR{\AR}
\newcommand\DR{\register{DR}}
\newcommand\PC{\register{PC}}
\newcommand\IR{\register{IR}}

\begin{document}
\thispagestyle{empty}
\pagestyle{plain}
\twocolumn[
\centering
\vspace{2em}\\
{\LARGE\bf CFT Minicomputer Assembler Guide}
\vspace{10pt}

{\Large Alexios Chouchoulas}\\\vspace{5pt}
{\large \hyperemail{alexios@bedroomlan.org}}

\vspace{20pt}

\begin{minipage}{.75\textwidth}
  \begin{abstract}
    \small
    
  This document discusses the design and operation of the CFT Standard
  Assembler, introduced as the first and main implementation tool for
  writing CFT software. The CFT is a solid-state, 16-bit, microcoded
  architecture reminiscent, among others, of the DEC PDP-8. The
  computer incorporates a 16-bit word width with separate memory and
  input/output addressing spaces and a minimal, orthogonal instruction
  set that is still particularly versatile. The design includes
  separate internal (processor) and external (peripheral) buses and is
  extensible both via processor extensions and peripherals. The
  instruction set is extensible in the style of the PDP-8 using
  instruction-level aliasing (instruction macros) and assembler macros.

  The Standard Assembler is capable of producing optimised code for
  the CFT that takes advantage of the architecture's idiosyncrasies,
  and avoids the pitfalls of its many peculiarities.
    
  \end{abstract}
  
  \section*{History of Changes}
  \small

  {\bf 2012-05-16} First draft outline.

  \vspace{5ex}
  
\end{minipage}
] % End of \twocolumn

%% \tikzset{boxes/.style={line width=2pt}}
%% \begin{figure*}[t!]
%%   \centering
%%   \begin{tikzpicture}[boxes]
%%     \begin{scope}[yshift=0cm]
%%       \draw[boxes, fill=red!30](0,0) rectangle (8,1);
%%       \draw (4,0.5) node {Microcode};
%%     \end{scope}

%%     \begin{scope}[yshift=1cm]
%%       \draw[boxes, fill=orange!30](0,0) rectangle (8,1);
%%       \draw (4,0.5) node {Instruction Set};
%%     \end{scope}

%%     \begin{scope}[yshift=2cm]
%%       \draw[boxes, fill=orange!30](0,0) rectangle (8,1);
%%       \draw (4,0.5) node {Instruction Macros and Extensions};
%%     \end{scope}

%%     \begin{scope}[yshift=3cm]
%%       \draw[boxes, fill=yellow!30](0,0) rectangle (8,1);
%%       \draw (4,0.5) node {Assembler Macros};
%%     \end{scope}

%%     \begin{scope}[yshift=4cm]
%%       \draw[boxes, fill=yellow!30](0,0) rectangle (8,1);
%%       \draw (4,0.5) node {Assembly Sub-programs};
%%     \end{scope}

%%     \begin{scope}[yshift=5cm]
%%       \draw[boxes, fill=green!30](0,0) rectangle (8,1);
%%       \draw (4,0.5) node {Forth Code Words};
%%     \end{scope}

%%     \begin{scope}[yshift=6cm]
%%       \draw[boxes, fill=cyan!30](0,0) rectangle (8,1);
%%       \draw (4,0.5) node {Native Forth Words};
%%     \end{scope}

%%     %% \begin{scope}[yshift=7cm]
%%     %%   \draw[boxes, fill=blue!30](0,0) rectangle (8,1);
%%     %%   \draw (4,0.5) node {Forth Applications};
%%     %% \end{scope}

%%     %% \begin{scope}[yshift=8cm]
%%     %%   \draw[boxes, fill=magenta!30](0,0) rectangle (8,1);
%%     %%   \draw (4,0.5) node {Higher Levels...};
%%     %% \end{scope}

%%   \end{tikzpicture}

%%   \caption{\label{fig-progmodel}Various levels of the CFT Programming Model.}

%% \end{figure*}

\section{Introduction}

  This document discusses the design and operation of the CFT Standard
  Assembler, introduced as the first and main implementation tool for
  writing CFT software. The CFT is a solid-state, 16-bit, microcoded
  architecture reminiscent, among others, of the DEC PDP-8. The
  computer incorporates a 16-bit word width with separate memory and
  input/output addressing spaces and a minimal, orthogonal instruction
  set that is still particularly versatile. The design includes
  separate internal (processor) and external (peripheral) buses and is
  extensible both via processor extensions and peripherals. The
  instruction set is extensible in the style of the PDP-8 using
  instruction-level aliasing (instruction macros) and assembler macros.

  The Standard Assembler is capable of producing optimised code for
  the CFT that takes advantage of the architecture's idiosyncrasies,
  and avoids the pitfalls of its many peculiarities.

  The Standard Assembler is a cross-compilation tool, written in
  Python to run on Unix and Unix-like computers. A possibly simplified
  version of the Standard Assembler is intended to be included as part
  of the CFT Forth Operating System, and possibly as a more
  full-featured stand-alone, native version.

\section{Architecture}

The Standard Assembler is a text-book multiple pass assembler with a
simple macro facility. It includes a ‘permanent’ symbol table with
macro definitions for the standard CFT instruction set as outlined in
the Programming Guide, in \cf{prog-guide}.

\subsection{The Cross Assembler}

The Cross Assembler is implemented in Python 2.6, but will probably
run on Python 2.4 or newer. 

\section{Syntax}

Assembler syntax is simpler than the average assembler, to match the
simpler structure of the CFT.

Lines consisting of white space are ignored. Every other line must
contain one or more of the following:

\begin{itemize}
\item Comments.
\item Instructions.
\item Origin specifications.
\item Label declarations.
\item Assembler directives.
\item Macros.
\end{itemize}

\subsection{Comments}

Comments are introduced with the slash (\f{/}) or semicolon (\f{;})
characters. Conventional comments follow a C++-style (\f{//}) or Assembly
(\f{;;}) conventions, but this is not mandatory.

Any text after the first comment character is ignored, as expected.

\subsection{Instructions}

An instruction is one 16-bit value.

Each 16-bit instruction must be composed of one or more ‘fields’, each
separated by one or more spaces. All the values specified on a line get ORred
together to form an aggregate which is then assembled at the current address.

Each field must be one of the following things:

\begin{itemize}
  \item Symbols.
  \item Literal values.
  \item Expressions involving symbols and/or literal values.
\end{itemize}

\subsubsection{Symbols}

A symbol is a sequence of one or more symbol characters. The first character
must be an alphabetic character or an underscore (\f{\_}). Subsequent characters
may be alphanumeric or underscores.

Any symbol in the symbol table may be used as an instruction field, no matter
what its semantics are. Examples include opcodes such as \op{LOAD}, simple
field values such as \op{R}, labels, or other symbols.

Labels are treated specially if included in an instruction: the label's value (its
address), is masked by ANDing with value \hex{3FF}$_{16}$. In this format, a label
will fill the instruction's 10-bit operand field.

\subsubsection{Literal Values}

CFT Assembly supports 16-bit literal values in three formats:

\begin{description}
\item{\bf Decimal} A plain numerical value consisting of one to five digits
  between \f{0} and \f{9}.
\item{\bf Hexadecimal} The character \f{\&} or sequence \f{0x} followed by 1–4 digits,
  each between \f{0}–\f{9} or \f{A}–\f{F}. Lower case letters may also be used.
\item{\bf Binary} The character \f{\#} followed by 1–16 binary digits (\f{0} or
  \f{1}). To aid in defining readable bitfields, single quotes \f{'} and commas
  \f{,} are ignored. Additionally, dashes (\f{-}), periods (\f{.}) and
  underscores (\f{\_}) are treated as \f{0}. This allows bitfields to be
  defined as \f{\#----'0010}, clearly indicating ‘don't-care’ bits.
\end{description}

\subsubsection{Expressions}

Expressions perform simple arithmetic at assembly time. They come in three basic
formats:

\begin{description}

\item{\bf Current address}: \f{@}. A single at-sign (\f{@}) is replaced by the
  current address.

\item{\bf Relative address}: \f{@+{\bf value}} or \f{@-{\bf value}}. The value
  (which may be any parseable field value) is added or subtracted from the
  current address, and the result replaces the expression.

\item{\bf Full expression}: \f{@{\bf a op b}}. The operator {\bf op} is one of
  \f{+}, \f{-}, \f{*} (multiplication), \f{/} (division), \f{|} (bitwise OR),
  \f{\&} (bitwise AND), or \f{\^} (bitwise XOR). There should {\em no space
    between the operator and the two operands}. For example, \f{@someLabel+\&80}
  is valid, while \f{@someLabel + \&80} is invalid. The two operands {\bf a} and
  {\bf b} are any parseable fields.

\end{description}

\subsection{Setting the Origin}

The origin is the next address to be assembled at. To set the origin, include a
literal value followed by a colon (\f{:}). For example, this sets the origin to
the CFT Reset vector at address \hex{FFF0}:

\begin{verbatim}
&FFF0:       ;; The CFT Reset Vector address
\end{verbatim}

\subsection{Labels}

Labels name a new symbol after the current address, so that the address can
then be referred to by name. Labels are essential in Assembly languages. They
simplify flow control and many other advanced tasks. A label is declared by
typing its name followed by a colon character (\f{:}). Multiple labels may be
set for the same address, one to a line. The origin may also be set. This is a
common idiom:

\begin{verbatim}
&FFF0:       ;; The CFT Reset Vector address
reset_vec:
reboot:
\end{verbatim}

Although declaring multiple labels for the same address is wasteful, it can
often lead to better readability.

\subsection{Directives}

A sequence of letters starting with a period (\f{.}) is a directive. Directives
assemble special values and modify the behaviour of the assembler. They are
similar in spirit to C preprocessor directives.

\subsubsection{Defining Arbitrary Symbols with \f{.equ}}

The \f{.equ} directive defines a new symbol with an arbitrary value. The syntax is:

\begin{verbatim}
.equ symbol value
\end{verbatim}

Any valid symbol may be named, and any parseable value may be used:
instruction, label, or literal. The most common uses of \f{.equ} are in
defining instructions or constants. The following definitions are actually part
of the permanent symbol table of the CFT Standard Assembler and cover the basic
instruction set:

\begin{verbatim}
.equ TRAP  0x0000
.equ IOT   0x1000
.equ LOAD  0x2000
.equ STORE 0x3000
.equ IN    0x4000
.equ OUT   0x5000
.equ JMP   0x6000
.equ JSR   0x7000
.equ ADD   0x8000
.equ AND   0x9000
.equ OR    0xA000
.equ XOR   0xB000
.equ OP1   0xC000
.equ OP2   0xD000
.equ ISZ   0xE000
.equ LIA   0xF000

.equ R     0x0400
.equ I     0x0800
\end{verbatim}

After definition, symbols may be used wherever parseable values may be used,
including in subsequent \f{.equ definitions}:

\begin{verbatim}
.equ LIA   &F000
.equ LI    LIA  R   ; &F000 | &0400
\end{verbatim}

This is exactly how the assembler defines the standard instruction macros, of
which \op{LI} is one.

\subsubsection{Declaring Registers with \f{.reg}}

The \f{.reg} directive works like the \f{.equ} directive, with one exception:
it declares a location in memory (usually Page 0) to be used as a register. For
example:

\begin{verbatim}
.reg  R0   R &10
.reg  R1   R &11
.reg  R2   R &12
.reg  R3   R &13

.reg  I0   R &81 ; Autoincrement registers
.reg  I1   R &82
.reg  I2   R &83
.reg  I3   R &84
\end{verbatim}

The difference between \f{.equ} and \f{.reg} is mainly one of semantics:
\f{.equ} can define such diverse entities as I/O locations, addresses, labels,
constants, flags, instructions, bit masks, et cetera — this sometimes makes it
difficult to divine the purpose of a symbol, even if good coding practices are
used. In contrast, \f{.reg} is meant only for register declaration, and this is
reflected in the various output files (map, symbol tables and graphical maps).

\subsubsection{Including Assembly Files with \f{.include}}

The \f{.include} directive instructs the Assembler to read, process and
assemble an external file. It used like this:

\begin{verbatim}
.include "some_file.asm"
\end{verbatim}

This may be used to break large programs into manageable, semantically distinct
blocks, or to allow libraries of definitions or code to be defined and shared
among programs.

\subsubsection{Assembling Arbitrary Data with \f{.word}}

The \f{.word} directive assembles an arbitrary word at the current
address. Some examples of its syntax:

\begin{verbatim}
.word some_label  ; label address
.word @           ; assemble current address
.word @+10        ; current address + 10
.word STORE       ; assemble an instruction
.word 1 #10 &4 8  ; assemble decimal value 15
\end{verbatim}

Any parseable value may be assembled using the \f{.word} directive, including
instructions.

Unlike plain instruction assembly, \f{.word} does not treat labels specially:
when assembling the value of a label in an instruction, only the lower 10 bits
are used. With \f{.word}, all 16 bits are used. This makes \f{.word} invaluable
in generating vector tables and aiding in indirection.

\subsubsection{Filling Regions with a Value with \f{.fill}}

The \f{.fill} directive assembles a value and uses it to fill a block in the
object code starting with the current address. It syntax is:

\begin{verbatim}
.fill COUNT VALUE
\end{verbatim}

The \op{COUNT} must be a literal value. The \op{VALUE} may be any parseable
value, including symbols and instructions. For example, to assemble 50 copies
of the value \hex{0000}:

\begin{verbatim}
.fill 50 &0000
\end{verbatim}

To fill a region with an instruction:

\begin{verbatim}
.fill &10 HALT
\end{verbatim}

Please note that the value is calculated {\em once}, so relative addressing and
expressions will not have the expected effect. The following directive will
assemble 10 copies of the instruction \op{JMP 0}, {\em not\/} a chain of jumps
with increasing addresses, despite the use of \op{@}.

\begin{verbatim}
&1000:  .fill 10 JMP @
\end{verbatim}

\subsubsection{Declaring Register Arrays with \f{.regfill}}

Sometimes blocks of registers need to be declared — for example, to account for
a memory-mapped device with arrays of mapped values (such as a
framebuffer). The \op{.regfill} directive is used for that. It works exactly
like \op{.fill}, but also marks the filled area as a register array.

\subsubsection{Unpacked Strings with \f{.str} or \f{.data}}

An unpacked string is a block of memory which represents character text. Each
character occupies an entire word and has a 16-bit range. Unpacked strings can
contain Unicode characters in UCS-2 or UTF-16 encodings. They can, of course,
contain ASCII characters as well. Since the CFT is a word-addressed machine,
these are the easiest strings for the computer to handle.

The \f{.str} directive assembles a string of values starting at the current
address:

\begin{verbatim}
.str "Hello World!" 10 0
\end{verbatim}

Character data are enclosed in double quotes, but \f{.str} can handle multiple
fields including any parseable value from literals to instructions (of course,
the utility of assembling instructions with \f{.str} is very limited). This may
be used to embed non-printable values (and double quotes) in strings. In the
example above, there is an ASCII 10 (line feed, return or new line) after the
exclamation point, followed by an ASCII 0 (NUL), which is conventionally used
to terminate variable-length strings.

\subsubsection{Negative-Terminated Strings with \f{.strn}}

Negative-terminated strings are unpacked strings in which end of string is
indicated by setting bit 15 on the last character. This allows characters with
codepoints between 0–32,767 to be used. If the upper 32,767 codepoints are not
necessary, this representation saves one word per string. The \f{.strn}
directive works in exactly the same way as the \f{.str} directive:

\begin{verbatim}
.strn "Hello World!" 10
\end{verbatim}

However, the last character of the string will be ORred with the value
\hex{8000}, to produce this sequence of values in memory:

\begin{verbatim}
0048 0065 006c 006c 006f 0020 0057 006f
0072 006c 0064 0021 800a
\end{verbatim}

Note that the terminating null conventionally added to the end of \f{.str}
directives is unnecessary here.

\subsubsection{Packed Strings with \f{.strp}}

Packed strings are the most compact means of encoding strings of 8-bit
characters (or Unicode characters encoded in UTF-8) on the CFT
architecture. Two characters are assembled per word, with the first character
in the lower eight bits. This byte order mirrors the way byte-addressable
machines work when dealing with strings, which makes CFT binary files easier to
examine on other computers. The syntax of the \f{.strp} is identical to that of \f{.str}:

\begin{verbatim}
.strp "Hello World!" 10 0
\end{verbatim}

This will generate the following sequence of words:

\begin{verbatim}
6548 6c6c 206f 6f57 6c72 2164 000a
\end{verbatim}

Obviously, strings with odd length will have 8 unused bits in the last
position. This string is even-length (the terminating null counts). This,
however, still makes the string much more compact than the equivalent unpacked
string. Unfortunately, it also makes it more difficult to handle in machine
code. CFT Forth makes heavy use of packed strings to keep the size of the
dictionary down.

\subsubsection{Skipping to the Next Page with \f{.page}}

Since CFT is unable to reference ‘far’ addresses (across page boundaries)
without indirection, the vast majority of loops must not cross page
boundaries. Take this trivial loop, for example:

\begin{verbatim}
        LI 50
        NEG
        STORE R &10
loop:   ISZ R &10
        JMP loop
\end{verbatim}

Since addresses in instructions are 10 bits long, only the lower 10 bits of the
address of label \op{loop} are assembled in the \op{JMP} instruction. The upper
six bits are populated using the upper six bits of the current address
(i.e. the page). Now, assume \op{loop} is at address \hex{1FFF}. This places
\op{JMP} at address \hex{2000}, crossing a page boundary. The address in
\op{JMP} is still \hex{3FF} (the lower 10 bits of \hex{1FFF}, the address of
\op{loop}). However, the upper six bits are no longer \hex{1C00} (shifted) —
they are now \hex{2000}. Thus, the machine will jump to address \hex{23FF} and
the loop will fail. This is a problem common will all paged instruction sets.

The CFT Standard Assembler refuses to fix this automatically, instead producing a warning:

\begin{verbatim}
source.asm:5:warning: Label 'loop' on
  page 1c00, but page 2000 accessed instead.
\end{verbatim}

To solve this issue, code must be rearranged so that the loop does not cross
the page boundary. While developing, the easiest way to do this is to force
crossing the page boundary by changing the origin. This is the purpose of the
\f{.page} directive: it changes the origin to the first address of the next
page.

Please note that this should not be done inside subroutines, since a block of
unassembled values will be introduced. It should, instead, be placed just
before the entry point of a subroutine preceding the problem addresses.

The syntax is trivial:

\begin{verbatim}
.page
\end{verbatim}

A common issue is for \f{.page} directives to be left in the code while
developing, leading to large amounts of unused space. The assembler will let
the programmer know about potential cases of unnecessary \f{.page} directives
by issuing a warning:

\begin{verbatim}
file.asm:924:warning: .page generated
  865 words of slack space.
\end{verbatim}

In such case, it is standard practice to comment out the directive (since
further coding is likely to push the problem code across another page boundary,
so the \f{.page} could be needed again).

\subsection{Instruction Macros}

The CFT instruction set contains sixteen main instructions, of which two allow
combinations of up to 24 minor operations. Because of both the small size of
the instruction set and its versatility, many new instructions a programmer
would expect to have may be formed as combinations (or special cases) of other
instructions that are still technically one instruction.

For example, the CFT instruction set lacks shifts, but has rolls which roll the
bits in the \Areg register through the single-bit \Lreg register. A shift may
be implemented by clearing \Lreg before rolling, so that the new instruction
\op{SBL} is implemented by \op{OP1 CLL RBL}.

These instruction macros are defined inside the Standard Assembler using the
\f{.equ} directive and can be treated as {\em single} instructions. For example:

\begin{verbatim}
.equ   SBL   OP1 CLL RBL   ; Shift bit left
.equ   SBR   OP1 CLL RBR   ; Shift bit right
\end{verbatim}

\subsection{Assembler Macros}

In addition to defining instruction macros which expand the CFT {\em
  instruction set}, the Assembler also provides Assembler Macros which expand
the {\em assembly language}. Unlike instruction macros, assembler macros can
incorporate multiple instructions and are parametric. They are invaluable in
simplifying assembly listings and maintaining consistency.

\subsubsection{Defining New Macros}

New macros are defined with the \f{.macro} and \f{.end} directives. This is an
example of an ‘add with carry’ macro to provide addition with carry-in (which
cannot be implemented as a single CFT instruction):

\begin{verbatim}
.macro ADC (addr)
    OP1 IFL INC    ; Inc AC if L is set
    ADD %addr
.end
\end{verbatim}

The name of the macro is \op{ADC}, and this is how it will be called after its
definition. It accepts a single argument named \op{addr}. Please note that
macros without parameters {\em still} require the open and closing parentheses,
in the same way as C function definitions do.

Multiple arguments may be specified, separated by commas.

The code between \f{.macro} and \f{.end} is not assembled immediately — it is
stored for inclusion later.

Argument values may be used by prefixing their names with \f{\%}, hence the use
of \f{\%addr}.

\subsubsection{Calling Macros}

To call the \f{ADC()} macro, use this syntax:

\begin{verbatim}
ADC(R &10)
\end{verbatim}

The presence of the parentheses in an instruction line trigger a search for the
macro nominated before the opening parentheses. White space may be used between
the name and open parenthesis, but is not recommended to keep the code compact
and allow longer macro names.

Multiple argument values must be separated by commas.

The same number of values must be specified as there are arguments in the macro
definition. Macro calls may not have variable arguments lists. In the case of
\f{ADC}, exactly one argument may be specified. The value of the argument
depends on its use in the macro definition, but the vast majority are parseable
values.

\subsubsection{Unique Labels}

If a macro contains loops or declares labels and the macro is expanded multiple
times, some or all of those labels may need to be made unique. This may be done
by including the magic argument \f{\%\_} in any label names:

\begin{verbatim}
.macro MINILOOP(n, loopreg, op)
    LI %n
    NEG
    STORE %loopreg
miniloop%_:
    %op
    ISZ %loopreg
    JMP miniloop%_
.end
\end{verbatim}

Note the idiom of appending \f{\%\_} to the labels. The \f{\%\_} argument will
expand to a number to each macro expansion, making the label unique across the
assembly process. This is generally not recommended. If loops are necessary, it
may be better to implement them as subroutines.

\section{Features}

The CFT Assembler includes various features to aid in debugging the object
code, simulating its execution in the CFT Emulator, as well as locating and
fixing issues with the Assembler itself.

\section{Output}

At the end of the assembly process, the Assembler outputs a number of files,
most of which are both machine and human-readable.

\subsection{Object Files}

The object code generated by the assembler is a pure binary file with no
headers or magic numbers. They are files containing 16-bit words, one per
assembled value, starting at the start address specified to the assembler, and
ending at the end address, also as specified to the assembler.

\subsection{Verilog List Files}

To help using the code with the Verilog-based hardware verification suite, the
Assembler also outputs a pair of {\tt .list} files with suffixes {\tt -00.list}
(low order bits) and {\tt -01.list} (high order bits). These are encoded in
Verilog-compatible human-readable binary and represent low and high ROM images
for the assembled code.

\subsection{The Map File}

The map file is generated with a {\tt .map} suffix, and contains a map of the
labels declared in the source code. It contains three columns:

\begin{enumerate}
\item Label Name.
\item Address in zero-padded hexadecimal.
\item Location of definition in the source code in {\tt filename:line} format.
\end{enumerate}

\subsection{The Symbol Table File}

Similar to the map file, this file (with a {\tt .sym} suffix) contains a dump
of the entire symbol table, not just labels. It has a two-line header for human
readability, and contains lines arranged in four columns:

\begin{enumerate}
\item Symbol Name.
\item Value in zero-padded hexadecimal.
\item Symbol type:
  \begin{itemize}
  \item \f{symbol}: a symbol declared by \f{.equ}.
  \item \f{label}: a label.
  \item \f{register}: a register declared by \f{.reg} or \f{.regfill}.
  \end{itemize}
  \item The location of the symbol definition in the source code in {\tt filename:line} format.
\end{enumerate}

\subsection{The Preprocessed Assembly File}

Files with a {\tt .pasm} suffix are ‘preprocessed assembly’ files. They contain
a digested form of the program, which is valid input to the CFT assembler, but
much less human-readable. Each line contains an explicit address followed by
the exact hexadecimal value at that address. The original assembly line leading
to that value follows as a comment. Strings and other multi-word directives are
expanded to show what is assembled. Include directives and macros are
expanded. No labels or other symbols are used (but remain in the
comments). Lines without assembled values are excluded. For example, label
declarations on their own lines will be left out.

These files may be used as a kind of assembly-annotated hex dump of the object
file, and are also used by the CFT emulator to print out the assembly source it
is executing.

\subsection{Graphical Memory Maps}

These are bitmap images useful in visualising the memory map of the program,
and the layout of the object file. They are output in the {\tt .xpm} format,
which {\em is\/} human readable, although these files are too large for a human
to visualise without software. Like all {\tt .xpm} files, this file is also
valid C code. It may be viewed with most image viewers or converted to a binary
bitmap file to save space.

The memory map displays the 65,536 word address space of the CFT as an array of
256×256 locations, with rows representing higher order bits of the address, so
that address \hex{0000} is at the upper left, and address \hex{FFFF} is at the
lower right.

Grey represents unused locations. Black represents slack space left by
\f{.page} directives. Magenta areas are those declared with \f{.reg}, and those
are expected to be at or near the top, on page 0. Red represents assembled
instructions. Orange represents packed strings. Green is for unpacked
strings. Blue represents \f{.word} values, and cyan marks \f{.fill} areas.

\begin{figure}[t]
\centering
\\
\caption{\label{fig-graphical-map}A graphical memory map of a CFT assembly program.}
\end{figure}

\section{Further reading}

For further information on the CFT computer, please consult the
following URL:

\begin{center}
\link{www.bedroomlan.org/hardware/cft}
\end{center}

\end{document}

%%  LocalWords:  documentclass CFT Alexios PDP autoindexing Von LSI prog equ
%%  LocalWords:  Neumann microprograms microprogram microinstructions ANDing
%%  LocalWords:  et cetera kiloword KWord kilowords KWords Autoindex bitfields
%%  LocalWords:  SUBRET JSR TRAPRET ISRRET ISR autoindex th FC FFF tl regfill
%%  LocalWords:  FFFF pagerel vlgrey linewidth fillstyle fillcolor de str UCS
%%  LocalWords:  addr FFFE IOT LIA JMP bitwise ORred asm bitfield CLA UTF NUL
%%  LocalWords:  CLL RBL RBR RNL RNR NOP linearc SNA SZA SSL SNN SNZ parseable
%%  LocalWords:  SCL CLI STI SNP lll RET RTT SBL SBR SNL SNR TTY someLabel sym
%%  LocalWords:  disjuncted conjuncted ANDed preprocessor framebuffer strn xpm
%%  LocalWords:  codepoints strp Verilog filename Preprocessed pasm
%%  LocalWords:  preprocessed

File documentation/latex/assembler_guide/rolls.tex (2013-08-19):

  \begin{tikzpicture}
    \newcommand\xxroll[2]{
      \begin{scope}[#1]
        
        \foreach \x in {0, -2} {
          \begin{scope}[yshift=\x cm]
            \draw[line width=2pt](0,0) rectangle (6,0.6);
            \draw[line width=2pt](-0.25,0) rectangle (-0.625,0.6);
            \foreach \x in {0.375, 0.75, ..., 5.625} {
              \draw[thin] (\x cm, 0) -- (\x cm, 0.6cm);
            }
          \end{scope}
        }
        
        \fill (-0.4375, 0.3) circle (1.5pt);
        \foreach \x in { 0.1875, 0.5625, ..., 5.8125 } \fill (\x, 0.3) circle (1.5pt);
        \draw (5.75, 0.6) node[above] { \op{#2}};
        \draw (-0.4375, 0.6) node[above] { \Lreg };
        \draw (-0.1, 0.6) node[above right=0/0.25cm] { \Areg };
        \draw (6,-2) node[below] { \footnotesize 0 };
        \draw (0,-2) node[below right] { \footnotesize 15 };
      \end{scope}
    }

    % RBL
    \begin{scope}
      \xxroll{}{RBL}
      \draw[thick, -stealth] (.1875, 0.3) -- (-.4375, -1.7);
      \foreach \x in {0.1875, 0.5625, ..., 5.4375} {
        \draw[thick, -stealth] (\x + 0.375, 0.3) -- (\x, -1.7);
      }
      \draw[thick, -stealth, rounded corners=3mm] (-0.4375, 0.3) -- (-0.4375, -0.7) -- (5.8125, -0.7) -- (5.8125, -1.7);
    \end{scope}

    % RBR
    \begin{scope}[yshift=-4cm]
      \xxroll{}{RBR}
      \draw[thick, -stealth] (-0.4375, 0.3) -- (.1875, -1.7);
      \foreach \x in {0.1875, 0.5625, ..., 5.4375} {
        \draw[thick, -stealth] (\x, 0.3) -- (\x + 0.375, -1.7);
      }
      \draw[thick, -stealth, rounded corners=3mm] (5.8125, 0.3) -- (5.8125, -0.7) -- (-0.4375, -0.7) -- (-0.4375, -1.7);
    \end{scope}

    % RNL
    \begin{scope}[xshift=8cm]
      \xxroll{}{RNL}
      \begin{scope}[thick,-stealth]
        \draw (0.1875 + 3 * 0.375, 0.3) -- (-.4375, -1.7);
        \foreach \x in {4, ..., 15} {
          \draw (0.1875 + 0.375 * \x, 0.3) -- ++(-4 * 0.375, -2);
        }
        \begin{scope}[rounded corners=3mm]
          \draw (-.4375, 0.3) -- (-.4375, -.25 - .18 * 4) -- 
          ( 0.1875 + 0.375 * 12, -.25 - .18 * 4) -- (0.1875 + 0.375 * 12, -1.7);
          \draw (0.1875, 0.3) -- (0.1875, -.25 - .18 * 3) -- 
          ( 0.1875 + 0.375 * 13, -.25 - .18 * 3) -- (0.1875 + 0.375 * 13, -1.7);
          \draw (0.1875 + 0.375, 0.3) -- (0.1875 + 0.375, -.25 - .18 * 2) -- 
          ( 0.1875 + 0.375 * 14, -.25 - .18 * 2) -- (0.1875 + 0.375 * 14, -1.7);
          \draw (0.1875 + 0.375 * 2, 0.3) -- (0.1875 + 0.375 * 2, -.25 - .18) -- 
          ( 0.1875 + 0.375 * 15, -.25 - .18) -- (0.1875 + 0.375 * 15, -1.7);
        \end{scope}
      \end{scope}
    \end{scope}

    % RNR
    \begin{scope}[xshift=8cm, yshift=-4cm]
      \xxroll{}{RNR}
      \begin{scope}[thick,-stealth]
        \draw (-.4375, 0.3) -- (0.1875 + 3 * 0.375, -1.7);
        \foreach \x in {0, ..., 11} {
          \draw (0.1875 + 0.375 * \x, 0.3) -- ++(4 * 0.375, -2);
        }
        \begin{scope}[rounded corners=3mm]
          \draw (0.1875 + 0.375 * 12, 0.3) -- (0.1875 + 0.375 * 12, -.25 - .18 * 1) -- ( -.4375, -.25 - .18 * 1) -- (-.4375, -1.7);
          \draw (0.1875 + 0.375 * 13, 0.3) -- (0.1875 + 0.375 * 13, -.25 - .18 * 2) -- ( 0.1875, -.25 - .18 * 2) -- (0.1875, -1.7);
          \draw (0.1875 + 0.375 * 14, 0.3) -- (0.1875 + 0.375 * 14, -.25 - .18 * 3) -- ( 0.1875 + 0.375, -.25 - .18 * 3) -- (0.1875 + 0.375, -1.7);
          \draw (0.1875 + 0.375 * 15, 0.3) -- (0.1875 + 0.375 * 15, -.25 - .18 * 4) -- ( 0.1875 + 0.375 * 2, -.25 - .18 * 4) -- (0.1875 + 0.375 * 2, -1.7);
        \end{scope}
      \end{scope}
    \end{scope}
  \end{tikzpicture}

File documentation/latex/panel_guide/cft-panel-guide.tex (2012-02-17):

\documentclass[11pt,a4paper,twocolumns]{article}
\usepackage[table]{xcolor}
\newcommand\zebra{\rowcolors{2}{gray!10}{white}}
\newcommand\zebrarow[1]{\rowcolors{#1}{gray!10}{white}}
\usepackage[all]{xy}
\usepackage{tikz-timing}[2009/07/28]
\usetikztiminglibrary{either}[2009/07/28]
\tikzset{timing/z/.style={black},}
\usepackage{pdftricks}
\usepackage{epsfig}
\usepackage{lipsum}
\usepackage{float}
\usepackage{verbatim}
\usepackage{geometry}
\usepackage{graphicx}
\usepackage{afterpage}
\usepackage{color}
\usepackage{epic}
\usepackage{eepic}
\usepackage{fontspec}
\usepackage[dvipdfm,a4paper,CJKbookmarks,bookmarks=true,bookmarksopen=true]{hyperref}
\usepackage{colortbl}
\usepackage{longtable}
\usepackage{array}
%\usepackage{layout}
\newcolumntype{P}[1]{>{\raggedright\arraybackslash}p{#1}}

\begin{psinputs}
\usepackage{color}
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
\newcommand\UOE{\ns{UOE}}
\newcommand\SKIP{\ns{SKIP}}
\newcommand\AINDEX{\ps{AINDEX}}
\newcommand\CLL{\ns{CLL}}
\newcommand\CPL{\ns{CPL}}
\newcommand\CLI{\ns{CLI}}
\newcommand\STI{\ns{STI}}
\newcommand\IRn[1]{\ps{IR{#1}}}
\newcommand\PCn[1]{\ps{PC{#1}}}
\newcommand\IBUSn[1]{\ps{IBUS#1}}
\newcommand\DBUSn[1]{\ps{DB#1}}
\newcommand\ABUSn[1]{\ps{AB#1}}
\newcommand\AEXTn[1]{\ps{AEXT#1}}
\newcommand\ISROLL{\ps{ISROLL}}
\newcommand\RAC{\ns{RAC}}
\newcommand\RAGL{\ns{RAGL}}
\newcommand\RDR{\ns{RDR}}
\newcommand\RPC{\ns{RPC}}
\newcommand\INCAC{\ns{INCAC}}
\newcommand\INCDR{\ns{INCDR}}
\newcommand\INCPC{\ns{INCPC}}
\newcommand\MEM{\ns{MEM}}
\newcommand\IO{\ns{IO}}
\newcommand\R{\ns{R}}
\newcommand\WRITE{\ns{W}}
\newcommand\READ{\ns{R}}
\newcommand\FL{\ps{FL}}
\newcommand\FV{\ps{FV}}
\newcommand\FZERO{\ps{FZERO}}
\newcommand\FNEG{\ps{FNEG}}
\newcommand\RESET{\ns{RESET}}
\newcommand\abbr[1]{#1}

\newcommand\caution[1]{\textcolor{caution}{\bf{#1}}}

\newcommand\NB{\textbf{Nota Bene:\ }}

%%%%%%%%%%%%%%%%%%%%%%%%%%%%%%%%%%%%%%%%%%%%%%%%%%%%%%%%%%%%%%%%%%%%%%%%%%%%%%%
%
% BILL OF MATERIALS (AUTOMATICALLY GENERATED)
%
%%%%%%%%%%%%%%%%%%%%%%%%%%%%%%%%%%%%%%%%%%%%%%%%%%%%%%%%%%%%%%%%%%%%%%%%%%%%%%%

\newcommand\bomv[1]{%
  \footnotesize
  \zebrarow{10}
  \begin{longtable}{r%
      %@{{\scriptsize(line \number\rownum)\ }}%
      P{0.2\textwidth}P{0.2\textwidth}P{0.15\textwidth}P{0.2\textwidth}}
    %
    % First header
    %
    \hiderowcolors
    \noalign{\smallskip}\hline\noalign{\smallskip}
    {\bf Qty} & {\bf Description} & {\bf Parts} & {\bf Order No} & {\bf Notes} \\
    \noalign{\smallskip}\hline\noalign{\smallskip}
    \noalign{\global\rownum 0\relax}\showrowcolors
    \endfirsthead
    %
    % Subsequent headers
    %
    \hiderowcolors
    \multicolumn{5}{l}{\em Continued from previous page.}\\
    \noalign{\smallskip\smallskip}\hline\noalign{\smallskip}
    {\bf Qty} & {\bf Description} & {\bf Parts} & {\bf Order No} & {\bf Notes} \\
    \noalign{\smallskip}\hline\noalign{\smallskip}
    \noalign{\global\rownum 1\relax}\showrowcolors
    \endhead
    %
    % Footer
    %
    \hiderowcolors
    \noalign{\smallskip\smallskip}
    \multicolumn{5}{l}{\em Continued on next page.}\\
    \endfoot
    %
    % Last footer
    %
    \hiderowcolors
    \noalign{\smallskip}\hline\noalign{\smallskip}
    \endlastfoot
    %
    % Content
    %
    \showrowcolors
    \input{../generated/#1-bom-values}
  \end{longtable}
}

%%%%%%%%%%%%%%%%%%%%%%%%%%%%%%%%%%%%%%%%%%%%%%%%%%%%%%%%%%%%%%%%%%%%%%%%%%%%%%%
%
% INDEX OF PARTS (AUTOMATICALLY GENERATED)
%
%%%%%%%%%%%%%%%%%%%%%%%%%%%%%%%%%%%%%%%%%%%%%%%%%%%%%%%%%%%%%%%%%%%%%%%%%%%%%%%

\newcommand\bomp[1]{%
  \footnotesize
  \zebra
  \begin{longtable}{P{0.15\textwidth}P{0.3\textwidth}P{0.2\textwidth}P{0.2\textwidth}}
    %
    % First header
    %
    \hiderowcolors
    \noalign{\smallskip}\hline\noalign{\smallskip}
    {\bf Part} & {\bf Description} & {\bf Order No} & {\bf Notes}\\
    \noalign{\smallskip}\hline\noalign{\smallskip}
    \noalign{\global\rownum 1\relax}\showrowcolors
    \endfirsthead
    %
    % Subsequent headers
    %
    \hiderowcolors
    \multicolumn{4}{l}{\em Continued from previous page.}\\
    \noalign{\smallskip\smallskip}\hline\noalign{\smallskip}
    {\bf Part} & {\bf Description} & {\bf Order No} & {\bf Notes}\\
    \noalign{\smallskip}\hline\noalign{\smallskip}
    \noalign{\global\rownum 1\relax}\showrowcolors
    \endhead
    %
    % Footer
    %
    \hiderowcolors
    \noalign{\smallskip\smallskip}
    \multicolumn{4}{l}{\em Continued on next page.}\\
    \endfoot
    %
    % Last footer
    %
    \hiderowcolors
    \noalign{\smallskip}\hline\noalign{\smallskip}
    \endlastfoot
    %
    % Content
    %
    \showrowcolors
    \input{../generated/#1-bom-parts}
  \end{longtable}
}

%%%%%%%%%%%%%%%%%%%%%%%%%%%%%%%%%%%%%%%%%%%%%%%%%%%%%%%%%%%%%%%%%%%%%%%%%%%%%%%
%
% DOCUMENT STARTS HERE
%
%%%%%%%%%%%%%%%%%%%%%%%%%%%%%%%%%%%%%%%%%%%%%%%%%%%%%%%%%%%%%%%%%%%%%%%%%%%%%%%

\begin{document}
%\layout
\thispagestyle{empty}
\pagestyle{plain}
\twocolumn[
\centering
\vspace{2em}\\
{\LARGE\bf CFT Minicomputer Front Panel Operation}
\vspace{10pt}

{\Large Alexios Chouchoulas}\\\vspace{5pt}
{\large \hyperemail{alexios@bedroomlan.org}}

\vspace{20pt}

\begin{minipage}{.75\textwidth}
  \begin{abstract}
    \small
    
  This document discusses tentative design and implementational
  details of the CFT computer's front panel and its intended
  operation. The front panel was designed last but is meant to be
  built first to aid in building, testing and operating the CFT
  computer during and after its construction. It also provides a
  traditional minicomputer programming interface, albeit a modernised
  LED-based one.
    
  \end{abstract}
  
  \section*{History of Changes}
  \small

  {\bf 2011-12-19} Initial revision.

  {\bf 2012-01-04} Listed briefly the signal connections between front
  panel and processor boards.

  {\bf 2012-01-09} Added revision B schematics, bill of materials and parts index.

  {\bf 2012-01-15} Minor modifications to the schematics and matching
  description. Added discussion on configuring and tuning the front
  panel.

  {\bf 2012-01-18} Added front panel controller and started section of the
  front panel's theory of operation.

  {\bf 2012-01-20} Added theory of operation of sequencer and system device and
  updated rendered images of boards, schematics and bills of materials.

  \vspace{5ex}
  
\end{minipage}
] % End of \twocolumn
\section{Introduction}

The CFT minicomputer is intended to be similar to a 1960s
minicomputer, and it could never be similar enough without a
programmer's front panel.

The front panel is serves two purposes: to inspect the state of the
computer, and to modify the state of the computer. State inspection is
made possible via a number of lights corresponding to the binary state
of most of the computer's crucial signals. State modification is via a
number of switches which control the operation of the computer's main
units and provide user input.

The CFT front panel is expected to provide a number of services.

\begin{itemize}
\item During construction, it will provide a means of testing most of
  the computer's individual units on their own. With some rewiring or
  reconfiguration, all of the computer's features can be tested.

\item After construction, it will allow microcode to be inspected and
  thereby debugged.

\item It will also allow the computer to be programmed without a
  ROM. A front panel was usually the only built-in means of
  programming a minicomputer, and in many cases was the only way the
  computer could be booted up.

\item It will allow debugging of software and hardware by allowing the
  computer to be stopped, its state inspected and perhaps changed, and
  then resuming execution.

\item Finally, it will allow the state of the running computer to be
  inspected with varying degrees of success.\footnote{The human eye
    is, of course, incapable of registering light pulses with MHz
    frequencies, but the panel lights register these with varying
    intensities of light.}

\end{itemize}

\section{Layout of the Front Panel}

\begin{figure*}[t]
\centering
\\
\caption{\label{fig-panel}A first draft of the CFT front panel.}
\end{figure*}

The CFT minicomputer is intended to be built into a 19-inch rack-mount case, 6U
in height, making it approximately 19" by 10.5" (482.6mm by 266.7mm) in size.

The panel displays the state of the computer on 118 console lights. For lower
consumption, convenience and longevity, these are light-emitting diodes (LEDs).

30 toggle switches allow the computer's state to be modified, and user input to
be provided.

Computer power and panel locking is controlled by a three-position key switch.

All lights and switches are displaying multi-bit quantities are arranged with
the most significant bit to the right, in the conventional notation of binary
numbers. Bit numbers start at 0, which is the least significant bit or
rightmost light. This follows the conventional notation of powers-of-two.

\subsection{Console Lights}

The console lights are arranged in six rows.

\subsubsection{Memory Controller}

The leftmost bank of lights on the top row displays the status of the banking
memory controller, if it is installed.

If banking has been enabled, a green light marked \lt{ENABLED} indicates
this. Eight yellow lights marked \lt{AEXT7}–\lt{AEXT0} indicate the bank
currently selected.

Conventionally, the memory controller addresses up to one MWord of ROM mapped
in the top MWord of the 21-bit address space (physical addresses {\sf
  20:0000}–{\sf 3F:FFFF}). Thus, light \lt{AEXT7} also indicates that a ROM
bank is selected. The light is thus marked \lt{AEXT7/ROM}).

If the memory controller board is not installed, these lights remain off.

\subsubsection{Interrupt Controller}

The middle bank of lights on the top row indicates the status of the optional
interrupt controller on eight lights marked \lt{INT7}–\lt{INT0}.

Each of these lights will indicate a number of different conditions depending
on its colour.

\begin{itemize}
  \item {\bf Off}: the computer is ignoring this interrupt line, and there is
    no interrupt activity.
  \item {\bf Green}: the interrupt line is being used by the computer, but
    there is no interrupt activity.
  \item {\bf Orange}: the interrupt line is being used by
    the computer, with interrupt activity.
  \item {\bf Red}: there is interrupt activity, but it is being ignored
    by the computer.
\end{itemize}

Because interrupt pulses are too short and relatively rare, in order to make
them visible to the naked eye, each interrupt pulse will illuminate the light
red or orange for approximately one tenth of a second.

\subsubsection{Miscellaneous Lights}

Three green lights marked \lt{GEN2}–\lt{GEN0} are located at the right of the
topmost row. These are reserved for generic use. Hardware may indicate its
status on any of them via physical two-wire connections.

\subsubsection{State}

The leftmost bank of lights on the second row from the top indicates the
processor's major operating states.

\begin{itemize}
\item \lt{RUN} (green) indicates the processor clock is running.
\item \lt{STOP} (red) when the \lt{RUN} light is off and this light is
  on, the processor clock is stopped and the front panel switches are
  active (provided the front panel is unlocked). When the \lt{RUN}
  light is on and this light flashes briefly, some device is
  introducing wait states by briefly halting the processor.
\item \lt{FETCH} (yellow) indicates the processor is in the Fetch state,
  retrieving its next instruction from memory.
\item \lt{EXEC} (yellow) indicates the processor is in the Execute state,
  performing the task identified by the previously retrieved instruction.
\item \lt{INT} (yellow) indicates the processor is handling a previously
  retrieved interrupt. Because interrupt states are too short and relatively
  rare, in order to make them visible to the naked eye, each interrupt pulse
  will illuminate this light for approximately one tenth of a second.
\end{itemize}

\subsubsection{Program Counter}

Sixteen red lights on the second row from the top indicate the current value of
the \PC. When the \lt{FETCH} light is illuminated, the \PC{} contains the
address in memory of the instructing being fetched. When the \lt{EXEC} light is
illuminated, the \PC{} indicates the address of the {\em next\/} instruction to
be executed (as long as no branching takes place in the current instruction).

\subsubsection{Flags}

Five green lights indicate the state of the five minor registers (flags) of the
processor.

\begin{itemize}
\item \lt{N} indicates bit 15 of the \A{} is set.
\item \lt{Z} indicates the \A{} is zero.
\item \lt{V} indicates an arithmetic overflow has been detected by the \ALU.
\item \lt{I} indicates that the processor allows interrupts.
\item \lt{L} indicates the state of the \Lreg{} register.
\end{itemize}

\subsubsection{Accumulator}

Immediately to the right of the \lt{L} light, on the second row from the top,
are 16 red lights representing the current value of the \A{} register. The
placement is such that the $(L,A)$ pair is easy to inspect when adding or
rotating.

\subsubsection{Multi-Function Display}

The Multi-Function Display occupies the third row of lights. Using a switch,
the user may choose to display the value of the Front Panel Output Register,
the Data Register (\DR), and the current micro-Address vector. In the latter
case, the meanings of each bit are marked below each light. The most
significant bit is not used in this case.

\subsubsection{Memory}

The status of the memory and I/O sequencing is shown on a bank of four lights,
on the fourth row from the top (second row from the bottom). The meanings of
these lights are as follows:

\begin{itemize}
\item \lt{MEM} (yellow) indicates memory space is being accessed.
\item \lt{IO} (yellow) indicates Input/Output space is being accessed.
\item \lt{R} (green) indicates a read cycle is in progress.
\item \lt{W} (red) indicates a write cycle is in progress.
\end{itemize}

These lights are pairwise mutually exclusive. The four combinations of them
describe the nature of the memory or I/O access (memory read, memory write, I/O
read, I/O write). Please note that these lights are, in essence, part of the
micro-instruction as described below.

\subsubsection{Instruction Register}

The contents of the \IR{} are displayed to the right of the memory lights. The
instruction fields (operation, I, R, and operand field) are indicated below the
lights. Alternating yellow and red lights are used for each field to aid
reading the IR.

Please note that the \lt{L} light indicates {\em exactly\/} the corresponding
field in an instruction: register mode is active when the light is {\em off}.

\subsubsection{Micro-Instruction}

The bottom row of lights indicates most of the control signals emanating from
the Microcode ROM (the memory control signals, described above, are the only
exception). These are useful in debugging the machine at the microcode level.

\subsection{Switches}

There are 30 switches and a key switch arranged in two rows below the
bottom-most row of lights. The top row is the Switch Register (16
switches), while the 

\subsubsection{Key Lock}

The key lock operates computer power and controls access to the front
panel.

Computer power is off with the key in the \sw{OFF} position.

Computer power is on with the key in the \sw{ON} position. In this position,
most panel switches are locked. These are the exceptions:

\begin{itemize}
\item The key switch may be operated.
\item The 16 Switch Register switches may be used to register 16-bit values
  read by the computer via the Front Panel System Device.
\item The \sw{VERBOSE}/\sw{TERSE} switch may be operated to enable or disable
  some front panel lights.
\item The Multi-Function Display Selector may be operated to change what is
  displayed on the Multi-Function Display.
\end{itemize}

With the key switch in the \sw{PANEL} position, all panel switches are unlocked
and enabled.

\subsubsection{Switch Register}

The switch register comprises 16 toggle switches located below the bottom-most
row of lights. These may be used to provide instructions or values to be stored
in processor registers when the computer is halted, or read directly by
computer programs via the Front Panel System Device when the computer is
running. This is the only form of user input of the unexpanded computer.

The switches are aligned with the corresponding bits of the various red
register lights and numbered in the same power-of-two convention as register
display lights. Switches are grouped in four four-bit groups for easier
reading.

Push a switch up to set the corresponding bit. Push it down to clear it.

\subsubsection{Run Control}

The Run Control switch group is located on the bottom row of switches,
below the Switch Register switches. It comprises three momentary
action switches with six functions. Switches may be pushed up or down
momentarily to activate their corresponding functions. These are:

\begin{description}
\item{\bf\sw{RESET}} Push the leftmost switch up to reset the
computer.
\item{\bf\sw{START}} Push the leftmost switch down to reset the
computer and start the processor clock.
\item{\bf\sw{RUN}} Push the middle switch up to enable the computer
  clock and allow the computer to continue executing.
\item{\bf\sw{STOP}} Push the middle switch down to disable the
  computer clock. This halts the computer and activates the controls
  of the front panel. Please note that the clock is halted
  immediately, possibly in the middle of executing a
  microprogram. Examine the \lt{FETCH}, \lt{EXEC} and
  \lt{μADDR3}–\lt{μADDR0} lights to determine exactly where the
  machine stopped.
\item{\bf\sw{uSTEP}} Push the rightmost switch up to trigger a single
  clock pulse, advancing to the next microinstruction.
\item{\bf\sw{STEP}} Push the rightmost switch down to advance to the
  first execution clock of the next instruction. The computer's clock
  is briefly enabled until the end of the first fetch cycle
  encountered after the activation of the switch, and immediately
  halted. At that point, the Instruction Register will display the
  instruction about to be executed and the Program Counter will
  display the address of the {\em next\/} instruction to be executed
  (barring jumps or skips). An optional auto-repeat mechanism allows
  the computer to step over multiple instructions while the \sw{STEP}
  switch is depressed. To activate the auto-repeat, press and hold the
  switch. A single step will be performed. Approximately two seconds
  after, and approximately every second after that, further step
  operations will be performed.
\end{description}

\subsubsection{State modification}

The state modification group resides centred below the switch
register. It comprises seven momentary action action switches and one
on-on toggle switch performing 15 actions:

\begin{description}
\item{\bf\sw{LOAD ADDR}} Activate this leftmost switch up or down to load the
  contents of the Switch Register into the Program Counter.
\item{\bf\sw{LOAD IR}} Push the second switch up to load the contents
  of the Switch Register into the Instruction Register.
\item{\bf\sw{LOAD AC}} Push the second switch up to load the contents
  of the Switch Register into the Accumulator.
\item{\bf\sw{MEMORY DEPOSIT}} Push the third switch up to store the
  contents of the Switch Register onto the memory address displayed in
  the address (Program Counter) bank of lights.
\item{\bf\sw{MEMORY DEP NEXT}} Push the third switch down to store the
  contents of the Switch Register onto the memory address displayed in
  the address (Program Counter) bank of lights. The Program Counter
  address is incremented by one after this. Repeated activations of
  this switch can fill a region of memory with the value of the Switch
  Register.
\item{\bf\sw{MEMORY EXAMINE}} Push the fourth switch up to load a
  value from memory into the Accumulator. The memory address used is
  that of the Program Counter (address) lights.
\item{\bf\sw{MEMORY EXAM NEXT}} Push the fourth switch down to load a
  value from memory, and increment the Program Counter by
  one. Repeated activations of this switch allow regions of memory to
  be examined one word at a time.
\item{\bf\sw{INPUT/OUTPUT DEPOSIT}} Push the fifth switch up to
  perform the same function as the \sw{MEMORY DEPOSIT} switch, but for
  I/O space.
\item{\bf\sw{INPUT/OUTPUT DEP NEXT}} Push the fifth switch down to
  perform the same function as the \sw{MEMORY DEP NEXT} switch, but
  for I/O space.
\item{\bf\sw{INPUT/OUTPUT EXAMINE}} Push the sixth switch up to
  perform the same function as the \sw{MEMORY EXAMINE} switch, but for
  I/O space.
\item{\bf\sw{INPUT/OUTPUT EXAM NEXT}} Push the sixth switch down to
  perform the same function as the \sw{MEMORY EXAM NEXT} switch, but
  for I/O space.
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

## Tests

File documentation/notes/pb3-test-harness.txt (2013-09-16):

Inputs

Name       Src      30Ω When floating
-------------------------------------------------------------------------------
CLK4       PB1/CG    -  Bus hold (PB0)
CLK3       PB1/CG    -  Bus hold (PB0)
CLK1       PB1/CG    -  Bus hold (PB0)
WS#        Bus       -  Pulled up (PB0)
ENDEXT#    Bus       -  Pulled up (PB0)
HALT#      Bus       -  Pulled up (PB0)
RESET#     Bus       -  Pulled up (PB0)
AINDEX#    PB1/AIL   ?  Pulled up (PB0)
SKIP#      PB1/SBL   -  Pulled up (PB0)
IR11-15    PB1/IR    -  Pulled down (PB0)
FL         PB3/L     ?  Pulled down (PB0)
FV         PB3/ALU   ?  Pulled down (PB0)
RSTHOLD#   PB1/RST   ?  Pulled up (PB0)
IRQS#      PB1/ISM   -  -
SYSDEV#    PB1/IOD   -  Bus hold (PB0)
W#         PB1/IOD   -  Bus hold (PB0)
AB0-15     Bus       -  Bus hold (PB0)
-------------------------------------------------------------------------------
FPCLKEN    PFP       -  Pulled up (PB1)
FPUSTEP    PFP       -  Pulled down (PB1)
NFPRESET   PFP       -  Pulled up (PB1), diode AD (OD) -> RESET#
POWEROK    PFP       -  Pulled up (PB1), diode AD (OD) -> RESET#
FNEG       PB2       ?  -
FZERO      PB2       ?  -
FL         PB3       ?  -
FV         PB3       ?  -
SKIPEXT#   Bus       -  Pulled up (PB1)
RAGL#      PB0/RUD   Y  Pulled up (PB0)
END#       PB0/uC    Y  -
WIR#       PB0/WUD   Y  -
STI#       PB0/uC    Y  -
CLI#       PB0/uC    -	-
IRQ#	   Bus	     -	-
WS#	   Bus	     -	-
MEM#	   PB0/uC    Y	-
IO#	   PB0/uC    Y	-
R#	   PB0/uC    Y  -
WEN#	   PB0/uC    Y	-	
T34#	   PB1/CG    -	Bus hold (PB0)	
CLK2	   PB1/CG    -  Bus hold (PB0)
CLK4	   PB1/CG    -  Bus hold (PB0)
-------------------------------------------------------------------------------
-------------------------------------------------------------------------------
RESET#     
-------------------------------------------------------------------------------

Patches required:

* Pull up SKIPMUXLO and SKIPMUXHI via 4.7kΩ resistor.

* Use '125 buffer to ensure W# is at high impedance when UCE# is
  asserted. When UCE# is asserted, WEN# goes high, and write pulses
  should only be generated when WEN# is low. Take advantage of this
  (use WEN# as buffer enable?).

Passive tests:

* High impedance between VCC and GND.
* FPRESET# pulled up.
* POWEROK pulled up.
* RSTHOLD-SHORT# pulled down without a jumper.
* SKIPEXT# pulled up.
* IRQ# pulled up.
* Outputs of JP3 pulled down without a jumper.
* AGL PAGE0-PAGE5 pulled down.

Active tests:

* CLOCK GENERATOR
  * CLK[1-4], T12, T34 waveform is nominal.
  * Clock stops when FPCLKEN is driven low.
  * With FPCLKEN low, strobing FPUSTEP should advance the clock.
  * Clock restarts when FPCLKEN is left floating or driven high.
  * Resetting restarts the clock phase.

* RESET
  * Driving RESET# low resets.
  * Driving FPRESET# low resets.
  * Driving POWEROK low resets.
  * Pressing reset buttont resets.
  * Reset sets RSTHOLD#.
  * RSTHOLD# waveform is nominal.
  * RSTHOLD# goes up in phase with clock.
  * Reset vector is driven onto IBUS while RSTHOLD# is low.

* SBU

  * Difficult to test through harness.
  * TBD.

* AGL

  * TBD.

* ISM

  * Interrupts lights off on reset.
  * Strobing IRQ# does nothing after reset.
  * Strobing STI# turns "interrupts allowed" light on.
  * Strobing IRQ# turns "interrupt seen" light on.
  * Strobing IRQ# drives IRQS# low.
  * Strobing CLI# or RESET# clears IRQS# and extinguishes both lights.

* Wait states

  * Difficult to test.
  * TBD.

* Data bus transceiver

  * TBD.

* Write strobe generator.

  * Calibrate.

Test harness:

  * Pull RESET# up.
  * Pull down IR0-4.
  * Pull down FV.
  * Pull down FNEG.
  * Pull down FZERO.
  * Pull down FL.
  * Pull down FV.
  * Pull up RAGL#.
  * Pull up END#.
  * Pull up WIR#.
  * Pull up STI#.
  * Pull up CLI#.
  * Pull up WS#.
  * Pull up MEM#.
  * Pull up IO#.
  * Pull up R#.
  * Pull up WEN#.
  * Pull up WEN#.

Lights:

  * IR0-3
  * IR4
  * SKIP (for skip experimentation)

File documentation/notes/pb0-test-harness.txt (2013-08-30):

Inputs

Name       Src      Conditioning
-------------------------------------------------------------------------------
CLK4       PB1/CG   Bus hold (PB0)
CLK3       PB1/CG   Bus hold (PB0)
CLK1       PB1/CG   Bus hold (PB0)
WS#        *        Pulled up (PB0)
ENDEXT#    *        Pulled up (PB0)
HALT#      *        Pulled up (PB0)
RESET#     *        Pulled up (PB0)
AINDEX#    PB1/AIL  Pulled up (PB0)
SKIP#      PB1/SBL  Pulled up (PB0)
IR11-15    PB1/IR   Pulled down (PB0)
FL         PB3/L    Pulled down (PB0)
FV         PB3/ALU  Pulled down (PB0)
RSTHOLD#   PB1/RST  Pulled up (PB0)
IRQS#      PB1/ISM  -
SYSDEV#    PB1/IOD  Bus hold (PB0)
W#         PB1/IOD  Bus hold (PB0)
AB0-15     *        Bus hold (PB0)
-------------------------------------------------------------------------------

Passive tests:

* High impedance between VCC and GND.
* RESET# pulled up.
* WS# pulled up.
* ENDEXT# pulled up.
* HALT# pulled up.
* RESET# pulled up.
* [R1]# pulled up.
* RAGL# pulled up.
* RPC# pulled up.
* RDR# pulled up.
* RAC# pulled up.
* [R6]# pulled up.
* [R7]# pulled up.
* [W1]# pulled up.
* WAR# pulled up.
* WPC# pulled up.
* WIR# pulled up.
* WDR# pulled up.
* WAC# pulled up.
* WALU# pulled up.
* RUNIT0-3 pulled down.
* WUNIT0-2 pulled down.
* OPIF0-3 pulled down.
* IR11-15 pulled down.
* FL pulled down.
* FV pulled down.

Active tests:

* UPC: µPC counts up (note: with microcode ROMs installed it will
  reset before it hits 16).
* UPC: µPC stops counting on HALT# or RESET#.
* UPC: µPC resets to zero on RESET#.
* RUNIT: changes to indicate register reads.
* WUNIT: changes to indicate register writes.
* MEM#: should strobe to indicate memory reads.
* R#: should strobe to indicate memory reads.
* UCB: UCB0-3 reset to 0000.
* UCB: UCBA/UCBB# clear on reset.
* UCB0-3: stay at 0000 while the board runs.
* Front panel pins reflect machine state.

Test harness:

11 input signals need to be driven.

* CLK4 ticking clocks toe µPC counter.
* CLK1 = 1 to enable RUNIT decoders.
* CLK3 = 0 to enable WUNIT decoders.
* IR11-IR15 select microprogram to test (optional)
* RSTHOLD# is 0 to test reset microprogram. Disconnect = 1 = instruction test.
* IRQS# = 1.
* SYSDEV# = 1.
* W# = 1.

Lights:

Row 1: uPC
Row 2: LSB to MSB: INCPC#, 0, R#, END#
Row 3: RUNIT
Row 4: WUNIT

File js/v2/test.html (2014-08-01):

# CFT Emulator

## Browser Edition (v.2)

Curious? Got here by accident? Find out more about this emulator and the CFT! (http://www.bedroomlan.org/cft-mini-computer/javascript-emulator)

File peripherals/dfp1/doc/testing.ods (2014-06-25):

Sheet: Sheet1
Signal | Connector & PIN |  | LED | Notes | Status
PB0-DEC# | P4 | 1 | A-2-2 | Inverted | OK
PB0-MEM# | P4 | 2 | A-1-4 | Inverted | OK
PB0-UCB0 | P4 | 3 | E-2-3 |  | OK
PB0-IO# | P4 | 4 | A-2-1 | Inverted | OK
PB0-UCB1 | P4 | 5 | E-2-2 |  | OK
PB0-R# | P4 | 6 | A-1-3 | Inverted | OK
PB0-UCB2 | P4 | 7 | E-2-1 |  | OK
N/A | P4 | 8 |  |  | -
PB0-UCB3 | P4 | 9 | E-1-4 |  | OK
PB0-WEN# | P4 | 10 | A-1-2 | Inverted | OK
PB0-CLI# | P4 | 11 | A-3-2 | Inverted | OK
PB0-END# | P4 | 12 | A-1-1 | Inverted | OK
PB0-CLL# | P4 | 13 | A-3-4 | Inverted | OK
PB0-STI# | P4 | 14 | A-3-3 | Inverted | OK
N/A | P4 | 15 |  |  | -
N/A | P4 | 16 |  |  | -
PB0-INCPC# | P4 | 17 | A-3-1 | Inverted | OK
PB0-STPAC# | P4 | 18 | A-2-3 | Inverted | OK
PB0-STPDR# | P4 | 19 | A-2-4 | Inverted | OK
PB0-CPL# | P4 | 20 | A-4-1 | Inverted | OK
PB0-OPIF3 | P4 | 21 | A-4-2 |  | OK
PB0-OPIF2 | P4 | 22 | A-4-3 |  | OK
PB0-OPIF1 | P4 | 23 | A-4-4 |  | OK
UPC0 | P4 | 24 | D-6-4 | With MFD set to µADDR | OK
UPC1 | P4 | 25 | D-6-3 | With MFD set to µADDR | OK
PB0-RSTHOLD# | P4 | 26 | D-3-2 | With MFD set to µADDR | OK
PB0-IRQSUC# | P4 | 27 | D-3-3 | With MFD set to µADDR | OK
UPC2 | P4 | 28 | D-6-2 | With MFD set to µADDR | OK
PB0-AINDEX# | P4 | 29 | D-5-4 | With MFD set to µADDR | OK
UPC3 | P4 | 30 | D-6-1 | With MFD set to µADDR | OK
WUNIT2 | P4 | 31 | A-5-2 |  | OK
PB0-SKIP# | P4 | 32 | D-5-3 |  | OK
WUNIT1 | P4 | 33 | A-5-3 |  | OK
PB0-FV | P4 | 34 | C-2-1, D-3-4 | Second LED when MFD set to µADDR | OK, OK
PB0-RUNIT3 | P4 | 35 | A-6-1 |  | OK
WUNIT0 | P4 | 36 | A-5-4 |  | OK
PB0-RUNIT2 | P4 | 37 | A-6-2 |  | OK
PB0-OPIF0 | P4 | 38 |  | PB0 bug: not output (see FPOPIF0) | -
PB0-RUNIT0 | P4 | 39 | A-6-4 |  | OK
PB0-RUNIT1 | P4 | 40 | A-6-3 |  | OK
FPIR15 | P5 | 1 | E-3-1, D-4-2 | Second LED when MFD set to µADDR | OK
N/A | P5 | 2 |  |  | -
FPIR14 | P5 | 3 | E-3-2, D-4-3 | Second LED when MFD set to µADDR | OK
N/A | P5 | 4 |  |  | -
FPIR13 | P5 | 5 | E-3-3, D-4-4 | Second LED when MFD set to µADDR | OK
N/A | P5 | 6 |  |  | -
FPIR12 | P5 | 7 | E-3-4, D-5-1 | Second LED when MFD set to µADDR | OK
N/A | P5 | 8 |  |  | -
FPIR11 | P5 | 9 | E-4-1, D-5-2 | Second LED when MFD set to µADDR | OK
N/A | P5 | 10 |  |  | -
FPIR10 | P5 | 11 | E-4-2 |  | OK
N/A | P5 | 12 |  |  | -
FPIR9 | P5 | 13 | E-4-3 |  | OK
N/A | P5 | 14 |  |  | -
FPIR8 | P5 | 15 | E-4-4 |  | OK
N/A | P5 | 16 |  |  | -
FPIR7 | P5 | 17 | E-5-1 |  | OK
N/A | P5 | 18 |  |  | -
FPIR6 | P5 | 19 | E-5-2 |  | OK
FPCLKEN→ | P5 | 20 |  | Full speed clock enable | UNCHECKED
FPIR5 | P5 | 21 | E-5-3 |  | OK
FPUSTEP→ | P5 | 22 |  | Microstep in / slow clock to PB1 | UNCHECKED
FPIR4 | P5 | 23 | E-5-4 |  | OK
N/A | P5 | 24 |  |  | -
FPIR3 | P5 | 25 | E-6-1 |  | OK
N/A | P5 | 26 |  |  | -
FPIR2 | P5 | 27 | E-6-2 |  | OK
FPRESET#→ | P5 | 28 |  | Reset in to PB1 | UNCHECKED
FPIR1 | P5 | 29 | E-6-3 |  | OK
POWEROK→ | P5 | 30 |  | From PSU to PB1 | UNCHECKED
FPIR0 | P5 | 31 | E-6-4 |  | OK
N/A | P5 | 32 |  |  | -
N/A | P5 | 33 |  |  | -
N/A | P5 | 34 |  |  | -
BFIRQ | P5 | 35 | C-2-2 |  | Bad (off)
N/A | P5 | 36 |  |  | -
BFNEG | P5 | 37 | C-1-3 |  | OK
N/A | P5 | 38 |  |  | -
BFZERO | P5 | 39 | C-1-4 |  | OK
N/A | P5 | 40 |  |  | -
N/A | P6 | 1 |  |  | -
N/A | P6 | 2 |  |  | -
N/A | P6 | 3 |  |  | -
N/A | P6 | 4 |  |  | -
N/A | P6 | 5 |  |  | -
N/A | P6 | 6 |  |  | -
N/A | P6 | 7 |  |  | -
N/A | P6 | 8 |  |  | -
N/A | P6 | 9 |  |  | -
N/A | P6 | 10 |  |  | -
N/A | P6 | 11 |  |  | -
N/A | P6 | 12 |  |  | -
N/A | P6 | 13 |  |  | -
N/A | P6 | 14 |  |  | -
N/A | P6 | 15 |  |  | -
N/A | P6 | 16 |  |  | -
N/A | P6 | 17 |  |  | -
N/A | P6 | 18 |  |  | -
N/A | P6 | 19 |  |  | -
N/A | P6 | 20 |  |  | -
FPAC8 | P6 | 21 | C-4-4 |  | OK
FPAC9 | P6 | 22 | C-4-3 |  | OK
FPAC10 | P6 | 23 | C-4-2 |  | OK
FPAC11 | P6 | 24 | C-4-1 |  | OK
FPAC12 | P6 | 25 | C-3-4 |  | OK
FPAC13 | P6 | 26 | C-3-3 |  | OK
FPAC14 | P6 | 27 | C-3-2 |  | OK
FPAC15 | P6 | 28 | C-3-1 |  | OK
FPAC0 | P6 | 29 | C-6-4 |  | OK
FPAC1 | P6 | 30 | C-6-3 |  | OK
FPAC2 | P6 | 31 | C-6-2 |  | OK
FPAC3 | P6 | 32 | C-6-1 |  | OK
FPAC4 | P6 | 33 | C-5-4 |  | OK
FPAC5 | P6 | 34 | C-5-3 |  | OK
FPAC6 | P6 | 35 | C-5-2 |  | OK
FPAC7 | P6 | 36 | C-5-1 |  | OK
N/A | P6 | 37 |  |  | -
N/A | P6 | 38 |  |  | -
N/A | P6 | 39 |  |  | -
N/A | P6 | 40 |  |  | -
DR15 | P7 | 1 | D-3-1 | With MFD set to DR | OK
DR14 | P7 | 2 | D-3-2 | With MFD set to DR | OK
DR13 | P7 | 3 | D-3-3 | With MFD set to DR | OK
DR12 | P7 | 4 | D-3-4 | With MFD set to DR | OK
DR11 | P7 | 5 | D-4-1 | With MFD set to DR | OK
DR10 | P7 | 6 | D-4-2 | With MFD set to DR | OK
DR9 | P7 | 7 | D-4-3 | With MFD set to DR | OK
DR8 | P7 | 8 | D-4-4 | With MFD set to DR | OK
DR0 | P7 | 9 | D-6-4 | With MFD set to DR | OK
DR1 | P7 | 10 | D-6-3 | With MFD set to DR | OK
DR2 | P7 | 11 | D-6-2 | With MFD set to DR | OK
DR3 | P7 | 12 | D-6-1 | With MFD set to DR | OK
DR4 | P7 | 13 | D-5-4 | With MFD set to DR | OK
DR5 | P7 | 14 | D-5-3 | With MFD set to DR | OK
DR6 | P7 | 15 | D-5-2 | With MFD set to DR | OK
DR7 | P7 | 16 | D-5-1 | With MFD set to DR | OK
N/A | P7 | 17 |  |  | -
N/A | P7 | 18 |  |  | -
N/A | P7 | 19 |  |  | -
N/A | P7 | 20 |  |  | -
N/A | P7 | 21 |  |  | -
N/A | P7 | 22 |  |  | -
N/A | P7 | 23 |  |  | -
N/A | P7 | 24 |  |  | -
FPPC15 | P7 | 25 | B-3-1 |  | OK
FPPC14 | P7 | 26 | B-3-2 |  | OK
FPPC13 | P7 | 27 | B-3-3 |  | OK
FPPC12 | P7 | 28 | B-3-4 |  | OK
FPPC11 | P7 | 29 | B-4-1 |  | OK
FPPC10 | P7 | 30 | B-4-2 |  | OK
FPPC9 | P7 | 31 | B-4-3 |  | OK
FPPC8 | P7 | 32 | B-4-4 |  | OK
FPPC7 | P7 | 33 | B-5-1 |  | OK
FPPC6 | P7 | 34 | B-5-2 |  | OK
FPPC5 | P7 | 35 | B-5-3 |  | OK
FPPC4 | P7 | 36 | B-5-4 |  | OK
FPPC3 | P7 | 37 | B-6-1 |  | OK
FPPC2 | P7 | 38 | B-6-2 |  | OK
FPPC1 | P7 | 39 | B-6-3 |  | OK
FPPC0 | P7 | 40 | B-6-4 |  | OK
FPWS | X4 | 9 | D-1-4 |  | OK
FPOPIF0 | X4 | 39 | A-5-1 | Bug fix | OK
FPFL | X4 | 37 | C-2-3, D-4-1 | (D-4-1 when MFD set to µADDR) | OK
BAEXT0 | P9 | 2 | B-1-1 |  | OK
BAEXT1 | P9 | 4 | B-1-2 |  | OK
BAEXT2 | P9 | 6 | B-1-3 |  | OK
BAEXT3 | P9 | 8 | B-1-4 |  | OK
BAEXT4 | P9 | 10 | B-2-1 |  | OK
BAEXT5 | P9 | 12 | B-2-2 |  | OK
BAEXT6 | P9 | 14 | B-2-3 |  | OK
BAEXT7 | P9 | 16 | B-2-4 |  | OK
MBEN | P9 | 18 | C-1-1 |  | OK
FPRAM#→ | P9 | 20 |  | Output from RAM/ROM switch to MBU (PB3) | OK
FPRUN | IC35 | 6 | D-1-1 | Run light from output shift register | OK
FPSTOP | IC35 | 7 | D-1-2 | Stop light from output shift register | OK
FPFETCH | IC37 | 7 | D-1-4 |  | UNCHECKED
FPEXEC | - | - | D-2-1 | Diode logic OR from IC37, pins 5 & 6 | UNCHECKED
PB0-IRQSUC# | IC48 | 12 | D-2-3, D-3-3 | Inverted PB0-IRQSUC# | OK
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

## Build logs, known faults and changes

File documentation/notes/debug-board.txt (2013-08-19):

DEBUG BOARD NOTES

* Serial over USB
* Generic FTDI cable to begin with. Replace with permanently installed,
  custom-programmed cable/module later.

TESTING LANGUAGE

* Based on flashprog code
* Hayes-like ATx commands
* Features
** Drive RESET#, HALT#.
** Read from memory (text/binary)
** Write to memory (text/binary)
** IO from I/O space (text/binary)
** OUT to I/O space (text/binary)
** Set up GPIO #2
** Read from GPIO #2
** Write to GPIO #2
** Test LEDs
** Flash low/high ROM (sector by sector)

TEST PROCESS

* ATR1 (assert RESET#)
* ATA0 (starting address 0)
* ATW65536 (read 65,536 words from serial, write to RAM)
* ATG0 (Go. Deasserts RESET#, waits for HALT#)

Card reports CFT test results asynchronously (even mid-command). ATG0 waits for
HALT# before asserting test success to the testing computer. ATGn waits for
HALT# or a timeout of n seconds.

CFT PROTOCOL

An interrupt (PD2/INT0) indicates the DEB device has been written to. Read the
second port of GPIO #0 (Address Bus low), bits 0–3 to determine the command issued.

Read the first port of GPIOs #0 and #1 (Data Bus low, Data Bus high) to get the
parameter/value sent to the DEB device.

DEBCONT# (PD3) = 0
DEBCONT# (PD3) = 1

CFT WS# is cleared, computer continues execution.

Execute command(parameter) pair or queue it for execution if it reports serial data.

COMMANDS

OPCODES &00–&0F:

Do nothing on the Version 1 hardware DEB board.

OPCODE &10: .equ PRINTA     OUT DEBUG &10	; Print out an address

Send "PRINTA: xxxx\n\r" where xxxx is the command argument in hex.

OPCODE &11: .equ PRINTC     OUT DEBUG &11	; Print out a character

if 32 <= arg <= 96:
  Send "PRINTC: x\n\r" where x is the ASCII character represented by arg.
else;
  Send "PRINTc: xxx\n\r" where x is argument AND &ff in decimal 

OPCODE &12: .equ PRINTD     OUT DEBUG &12	; Print out a decimal number in A

Send "PRINTD: xxxxx\n\r" where xxxxx is the command argument in signed twos
complement decimal (-32768 to 32767)

OPCODE &13: .equ PRINTU     OUT DEBUG &13	; Print out a decimal number in A

Send "PRINTU: xxxxx\n\r" where xxxxx is the command argument in unsigned
decimal (0 to 65535)

OPCODE &14: .equ PRINTH     OUT DEBUG &14	; Print out a hex number in A

Send "PRINTH: xxxx\n\r" where xxxx is the command argument in hex.

OPCODE &15: .equ PRINTB     OUT DEBUG &15	; Print out a binary number in A

Send "PRINTB: xxxx\n\r" where xxxx is the command argument in binary
(zero-padded to 16 characters).

OPCODE &16: .equ PRINTSP    OUT DEBUG &16	; Print out a space

Send "PRINTc: 32\n\r".

OPCODE &17: .equ PRINTNL    OUT DEBUG &17	; Print out a newline

Send "PRINTc: 10\n\r".

OPCODE &18: .equ DEBUGON    OUT DEBUG &18	; Emulator: start debugging
OPCODE &19: .equ DEBUGOFF   OUT DEBUG &19	; Emulator: stop debugging
OPCODE &1A: .equ DUMP       OUT DEBUG &1a	; Emulator: dump current state

Does nothing on the Version 1 hardware DEB board.

OPCODE &1B: .equ PRINTHI    OUT DEBUG &1b	; Set a HI word for later printing.

Stores the command argument in the high word variable.

OPCODE &1C: .equ PRINTLO    OUT DEBUG &1c	; Emulator: print out HI:LO words

Send "PRINTL: xxxxxxxx\n\r" where xxxxxxxx is the 32-bit double-word value made
up of the high word variable (bits 8-15) and the command argument (bits 0-7).

OPCODE &1D:

Reserved.

OPCODE &1E: .equ SUCCESS    OUT DEBUG &1e	; Assert: true

Send "ASSERT: TRUE\n\r". Indicate using light pattern (TBD).

OPCODE &1F: .equ FAIL       OUT DEBUG &1f	; Assert: false

Keep the system in WS (for potential state inspection). Send "ASSERT:
FALSE\n\r". Indicate using light pattern (TBD).

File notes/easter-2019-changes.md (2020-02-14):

## Architecture

### Buses

* 24-bit address bus. Upgraded from 16 bits (and from 21 bits with SMB).
* 16-bit data bus.

### Timing

Timing simplified with more things registered. Clocks are still four phase. The
negative edge of each phase signals the following:

## CLK1

The microcode address vector is loaded from various sources:

* µPC
* IDX[1:0]
* COND
* reserved input
* IR[15:7]
* IRQSUC

RSTHOLD is asynchronous and is not registered. This causes no hazards becausae
the RSTHOLD microprogram takes no other inputs into consideration.

Preconditions:

* µPC has incremented and stabilised before CLK1.
* All control store inputs have stabilised by end of CLK4.

Once the address vector is set, the microcode store fetches the control
vector. This takes 70ns, which is longer than one clock phase.

## CLK2

Control vector fetch continues. Around 70ns after the address vector is set,
the microcode store will have fetched the control vector and the control store
will have valid outputs.

## CLK3

The control vector is registered and output to the processor. Bus transactions
begin here.

This happens ~125ns after the address vector has been set, so enough time for
the control store to fetch the control vector and avoid any chance of
metastability.

## CLK4

Bus transactions continue. The rising edge of CLK4 signals writes. This implies
WSTB and its complex generating circuitry is no longer required and may be
dropped.

## Timing diagram and pipelining

              T4 T1 T2 T3 T4 T1 T2 T3 T4 T1 T2 T3 T4 T1 T2 T3 T4 T1 T2 T3 T4 T1 

µC Address    ---00000000000011111111111122222222222233333333333344444444444455
µC Control    ---------00000000000011111111111122222222222233333333333344444444
Address       ---------000000000---111111111---222222222---333333333---44444444
Read          -----------000000000---111111111---222222222---333333333---444444
Write         ---------------000---------111---------222---------333---------44

### Registers

* PC
* AC
* DR
* Flags
* 8×8-bit bank registers for extending addresses.

### Memory Bank Registers

* MB0:   MBP: program bank.
* MB1:   MBD: data bank.
* MB2:   MBS: stack bank.
* MB3:   MBZ: page zero bank.
* MB4–7: MBZ: user defined.

8-bit address extension. 16 MW total memory space.

* Switch to 1 MW RAM chips, up to 4 per card. We'll never need all of them.
* Allow some devices to be memory mapped. E.g. VDU card should be
  memory mapped too. It'll just take one 64 KW bank anyway.
  
The MBU has very complex access patterns unfortunately:

| Addr | Sel | Notes |
|---|---|---|
| I/O = 008–00F | AB[2:0]  | Read/write registers programmatically |
| WADDR = 0110x | Always 0 | Write MBP from microcode |
| WADDR = 01111, IR=…00:00:00000000 | IR[2:0]  | |

### I/O Space Mapped stuff

A number of units can me moved from microcode to I/O space.

* The bank registers (already there!)
* The SBL minor instructions (use an IN or OUT, not IOT, but modify microcode)
* It would be great if we could do the same for the ALU. ALU unary ops
  can move to I/O space, but not binary ones.
* Load flags (L & V currently. Popping the AC from stack restores N & Z).
* Store flags (L & V currently. Popping the AC from stack restores N & Z).

### Magic Page Zero locations

Magic addresses:

* Some auto-increment
* Some auto-decrement
* Some index based on MB0–MB7.
* Partial overlap of each group.

Current scheme:

* &0080–&00FF: autoindex

Suggested scheme:

* &0000–&003F: page zero ‘registers’.
* &0040–&0080: indexes. &0041 is the Call stack pointer.
* &0080–&00BF: auto-increment.
* &00C0–&00FF: auto-decrement.
* &0b100—&01FF: clear interrupt flag if LJMP I x involves an address in
  this range. No effect on other instructions.

### Boot Vectors

Boot vector &FF:FFF8?
Interrupt vector &FF:FFF0?

If &FF is used, ROM must be mapped *downwards* from bank &ff. But,
really, who cares? We're only ever going to have one ROM bank.

## Microcode

* Add `r_mem` to perform a memory read cycle.
* Add `r_io` to perform an I/O read cyrle.
* Add `w_mem` to perform a memory write cycle.
* Add `w_io` to perform an I/O write cycle.

## Instruction Set

### Issue One: long jumps & re-entrancy

To support both long jumps and re-entrancy, RET can no longer be an
alias of JMP. We need short and long returns with actual
microprograms.

| Instruction | Needs I | Notes |
|---|---|---|
| TRAP | | Replace with LJMP or LJSR |
| TRAP I | | Replace with LJMP or LJSR |
| IOT | | |
| IOT I | | |
| LOAD | | |
| LOAD I | | |
| STORE | | |
| STORE I | | |
| IN | | |
| IN I | | |
| OUT | | |
| OUT I | | |
| JMP | | |
| JMP I | | |
| ADD | | |
| ADD I | | |
| AND | | |
| AND I | | |
| OR | | |
| OR I | | |
| XOR | | |
| XOR I | | |
| OP1 | No | |
| Reserved? | No | |
| OP2 | No | |
| POP | No | |
| JMPII | | Candidate for removal? |

Since RET takes no arguments, we can use OP2 for it. Current state:

| Bitfield | OP2 Instruction | Notes |
|---|---|---|
| -----01--- | SNA — Skip if AC negative (G1) | These can be replaced by an I/O mapped unit. |
| -----0-1-- | SZA — Skip if AC zero (G1) | |
| -----0--1- | SSL — Skip if L set (G1) | |
| -----0---1 | SSV — Skip if V set (G1) | |
| -----10000 | SKIP — Always skip (G2) | |
| -----11--- | SNN — Skip if AC non-negative (G2) | |
| -----1-1-- | SNZ — Skip if AC non-zero (G2) | |
| -----1--1- | SCL — Skip if L clear (G2) | |
| -----1---1 | SCV — Skip if V clear (G2) | |
| --1------- | CLA — Clear AC | Remove |
| ---1------ | asm:CLI — Clear I flag | Relegate to I/O space macros. |
| ----1----- | asm:STI — Set I flag | Keep! |

New state:

| Bitfield | OP2 Instruction | Notes |
|---|---|---|
| 010------- | RET — Return from subroutine | |
| 110------- | LRET — Long return from subroutine | |
| 111------- | RTI — Return from interrupt | |
| 001------- | STI — Set interrupt flag | |
| 100------- | pops from stack onto code bank | |
| -----01--- | SNA — Skip if AC negative (G1) | |
| -----0-1-- | SZA — Skip if AC zero (G1) | |
| -----0--1- | SSL — Skip if L set (G1) | |
| -----0---1 | SSV — Skip if V set (G1) | |
| -----10000 | SKIP — Always skip (G2) | |
| -----11--- | SNN — Skip if AC non-negative (G2) | |
| -----1-1-- | SNZ — Skip if AC non-zero (G2) | |
| -----1--1- | SCL — Skip if L clear (G2) | |
| -----1---1 | SCV — Skip if V clear (G2) | |

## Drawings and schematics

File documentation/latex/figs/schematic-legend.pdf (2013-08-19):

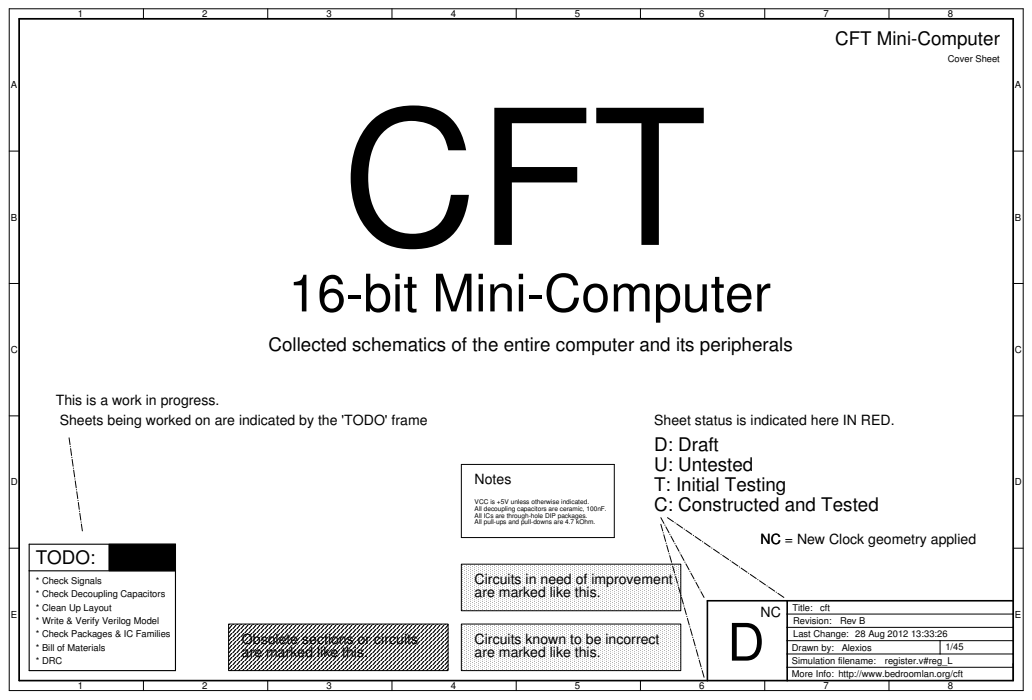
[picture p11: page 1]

Collected schematics of the entire computer and its peripherals

VCC is +5V unless otherwise indicated. Notes

All decoupling capacitors are ceramic, 100nF. All ICs are through-hole DIP packages.

All pull-ups and pull-downs are 4.7 kOhm. Obsolete sections or circuits

NC = New Clock geometry applied

are marked like this. Circuits in need of improvement
are marked like this.

* Check Signals
* Check Decoupling Capacitors
* Clean Up Layout * Write & Verify Verilog Model * Check Packages & IC Families

Circuits known to be incorrect

http://www.bedroomlan.org/cft

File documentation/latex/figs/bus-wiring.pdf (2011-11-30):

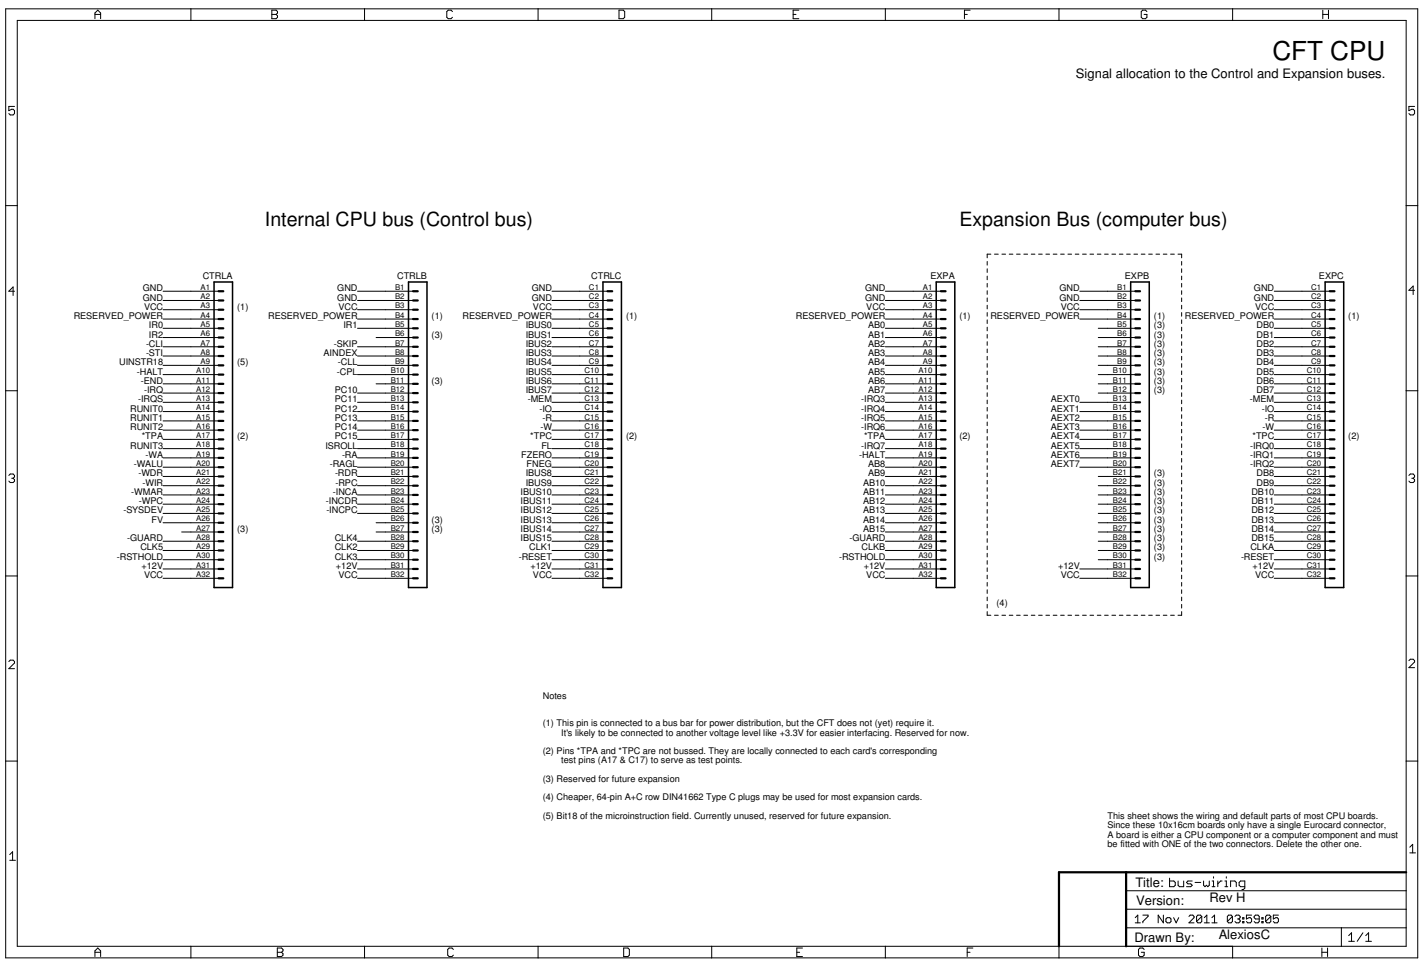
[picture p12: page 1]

Signal allocation to the Control and Expansion buses.

Internal CPU bus (Control bus)

Expansion Bus (computer bus)

(1) This pin is connected to a bus bar for power distribution, but the CFT does not (yet) require it.
It's likely to be connected to another voltage level like +3.3V for easier interfacing. Reserved for now.
(2) Pins *TPA and *TPC are not bussed. They are locally connected to each card's corresponding
test pins (A17 & C17) to serve as test points.
(3) Reserved for future expansion
(4) Cheaper, 64-pin A+C row DIN41662 Type C plugs may be used for most expansion cards.
(5) Bit18 of the microinstruction field. Currently unused, reserved for future expansion.

This sheet shows the wiring and default parts of most CPU boards. Since these 10x16cm boards only have a single Eurocard connector, A board is either a CPU component or a computer component and must be fitted with ONE of the two connectors. Delete the other one.

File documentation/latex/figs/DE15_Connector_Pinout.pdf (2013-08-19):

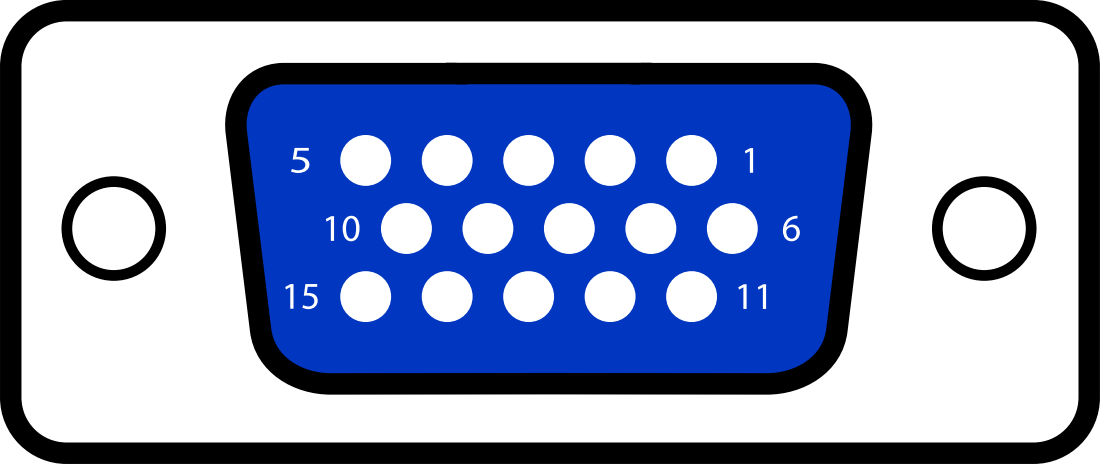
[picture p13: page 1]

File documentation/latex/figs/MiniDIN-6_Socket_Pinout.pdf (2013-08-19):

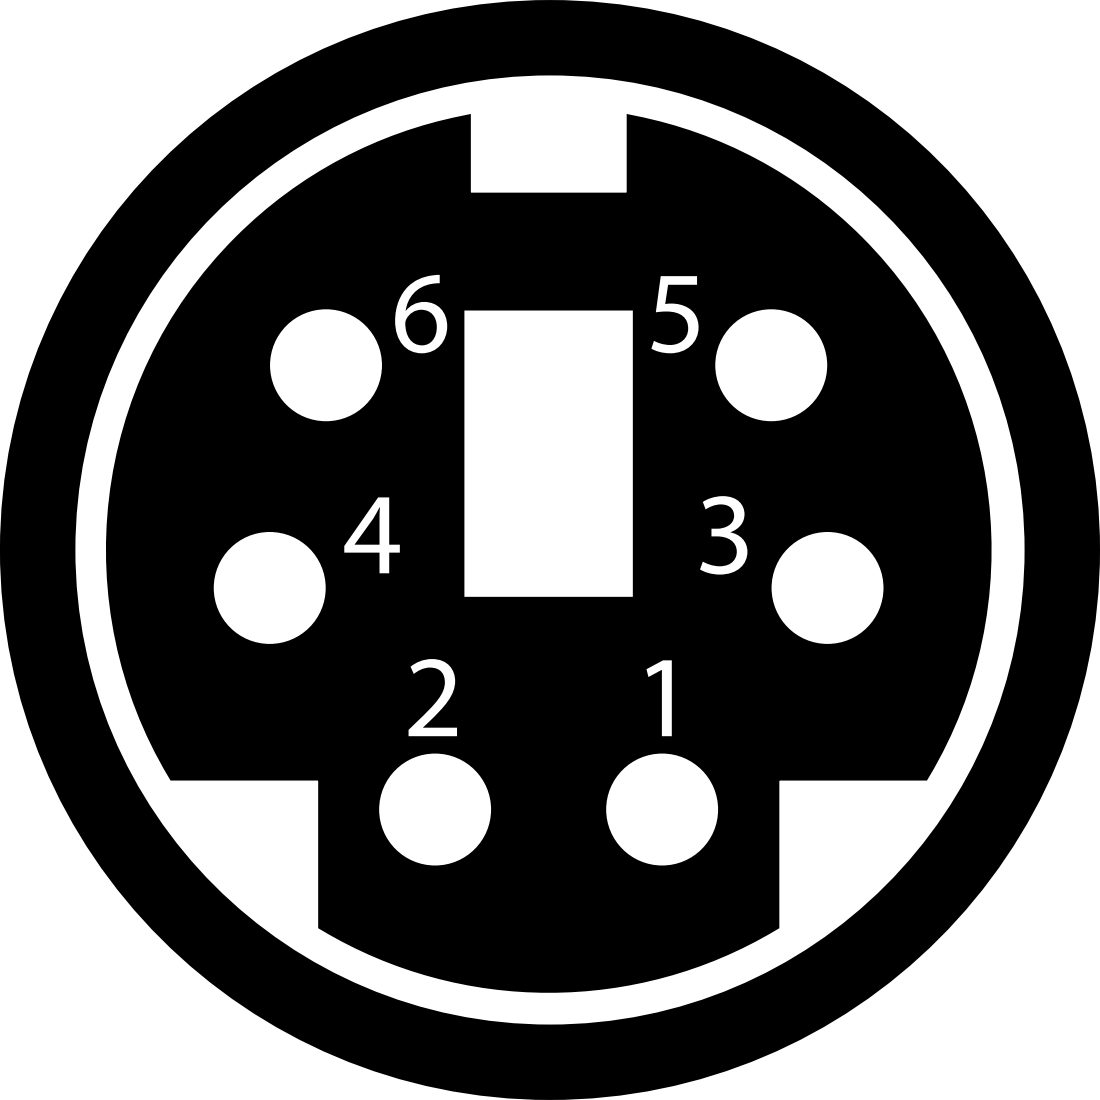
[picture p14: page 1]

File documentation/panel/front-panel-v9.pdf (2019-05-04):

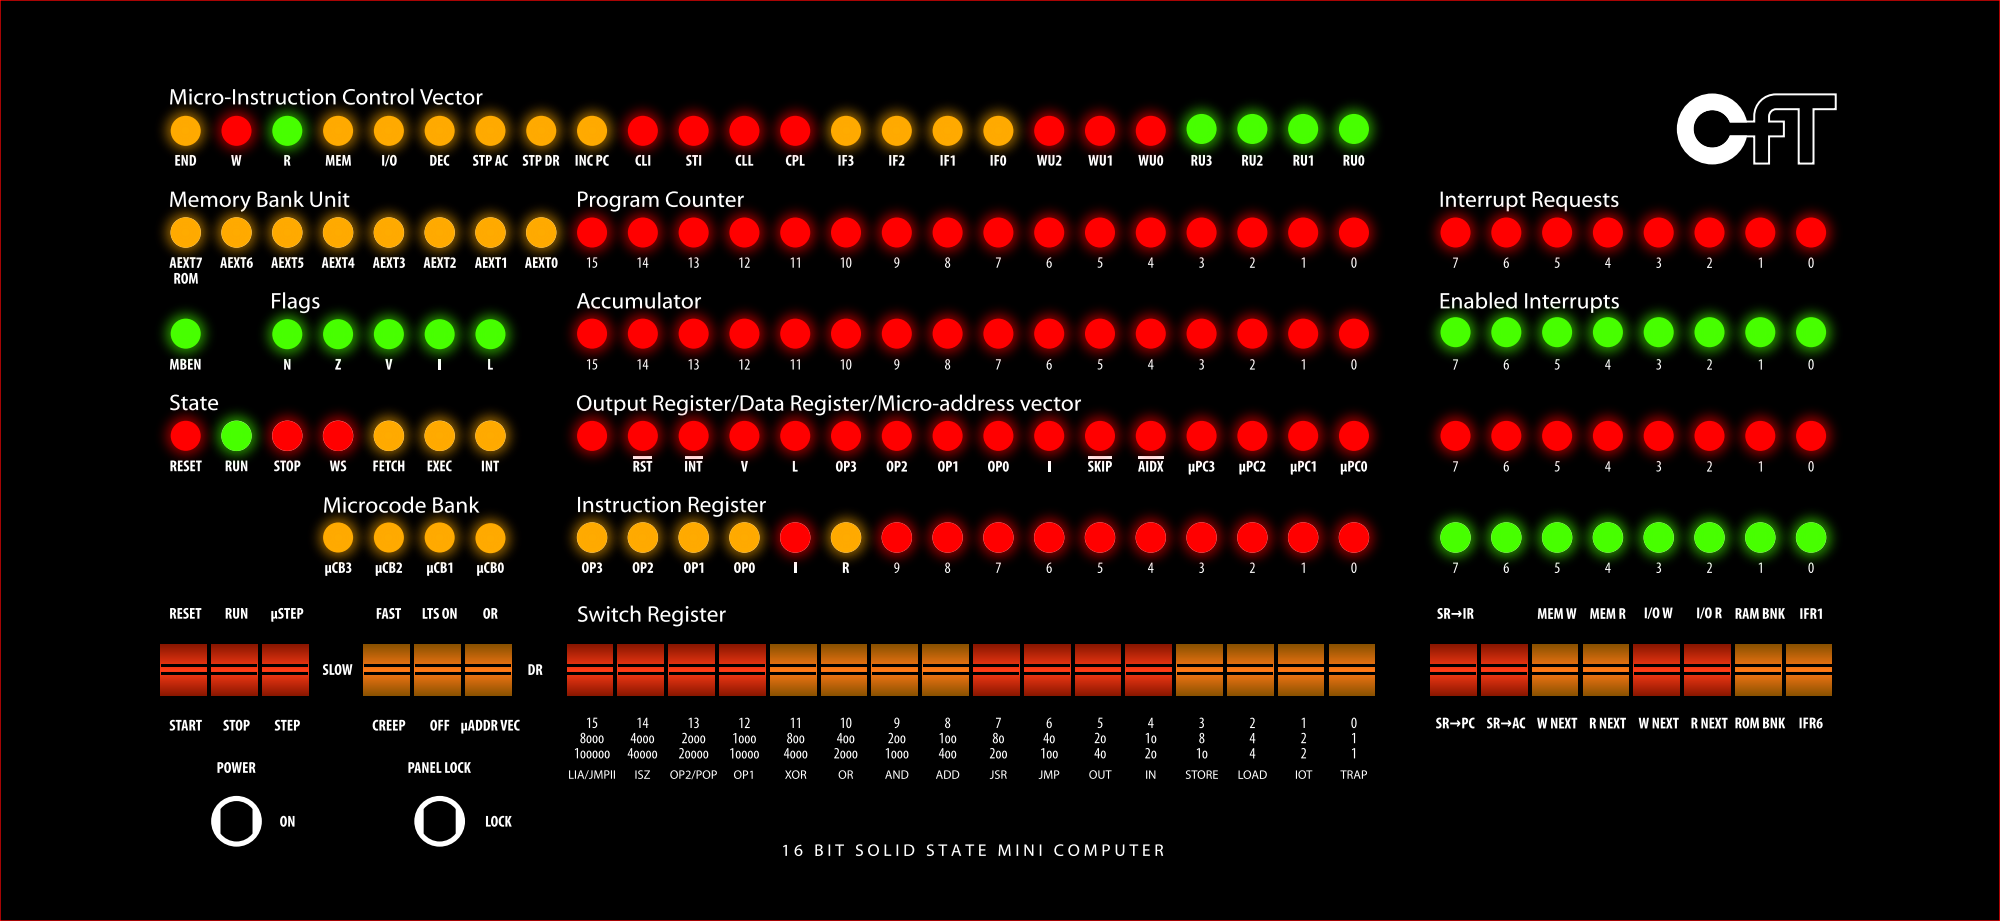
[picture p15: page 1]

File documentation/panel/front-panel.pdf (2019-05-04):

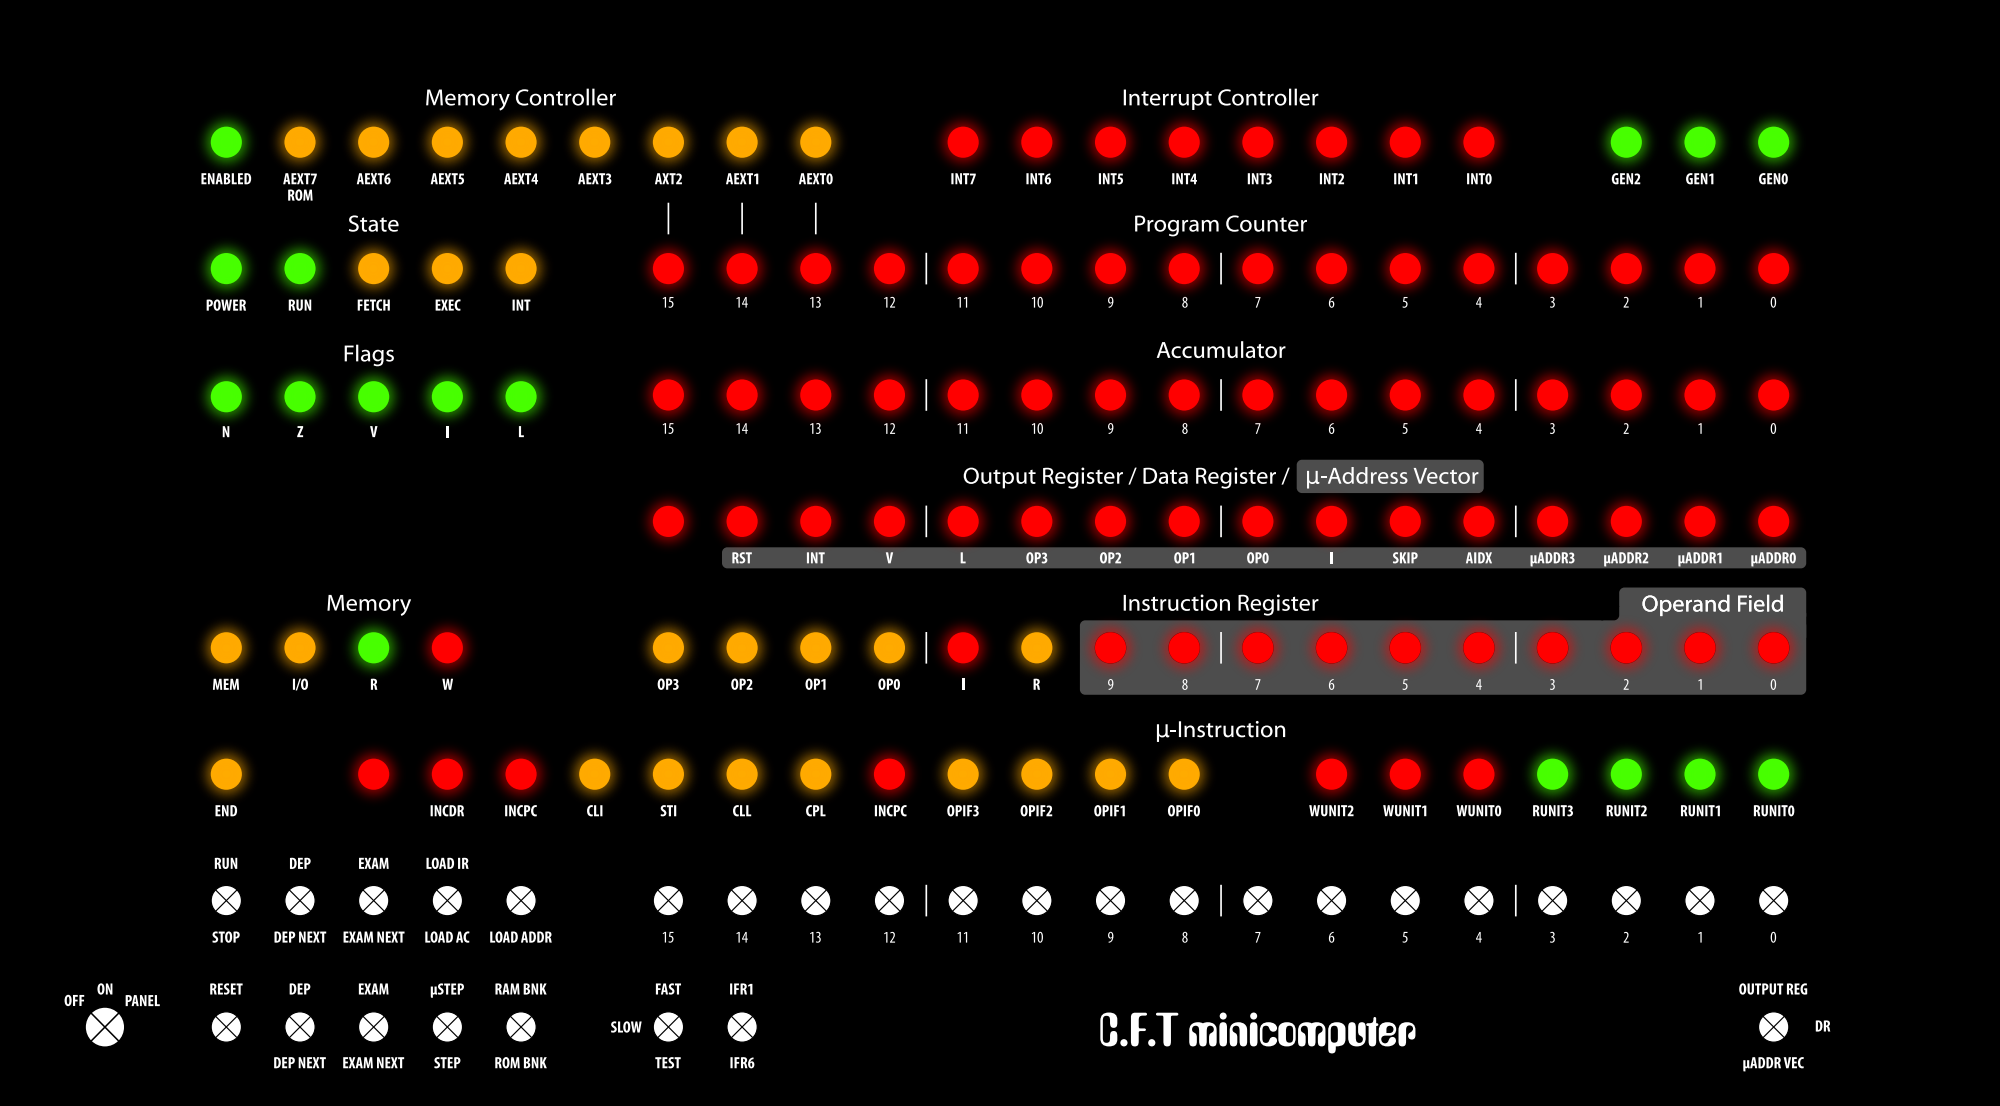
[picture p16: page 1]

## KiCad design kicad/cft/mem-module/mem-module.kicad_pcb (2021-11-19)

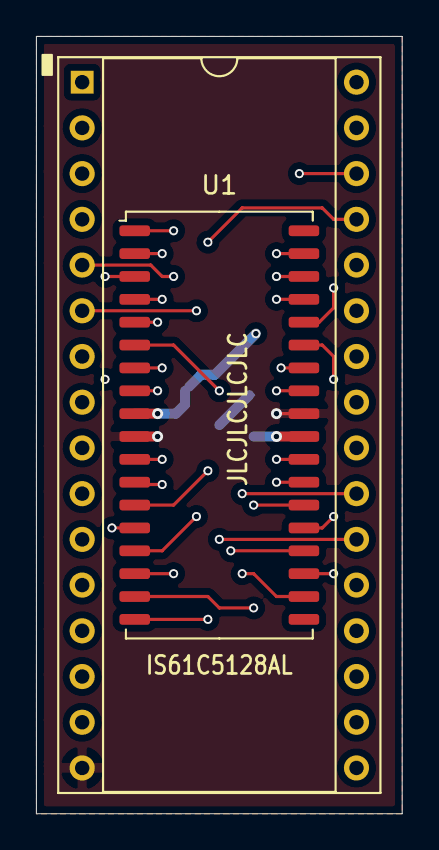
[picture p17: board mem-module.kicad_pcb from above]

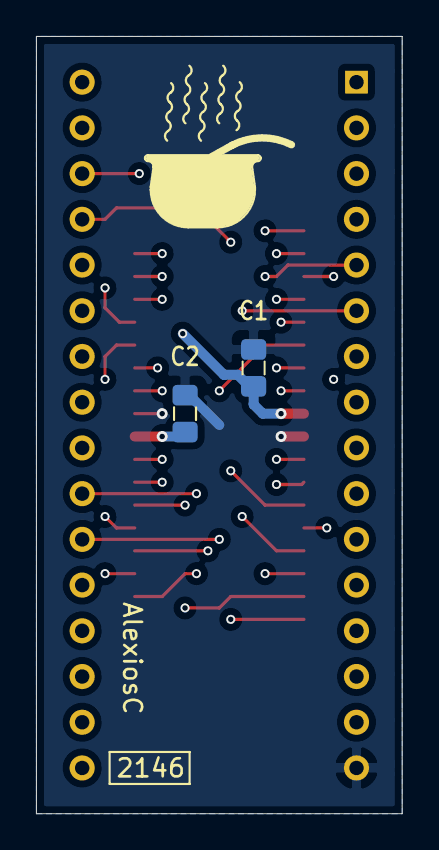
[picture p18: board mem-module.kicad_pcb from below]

Board: 4 copper layers, 20.3 x 43.2 mm, 4 parts (2 on the bottom side), 32 nets.

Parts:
C1, C2: 100nF; SMD_0805_2012Metric_Pad1.15x1.40mm_HandSolder
U1: IS61C5128AL; SOJ-36_10.16x23.49mm_P1.27mm
U2: AS6C4008-55PCN; DIP-32_W15.24mm_Socketed_IC

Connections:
+5V: C1.1, C2.1, U1.9, U1.27, U2.32
/AB0: U1.1, U2.12
/AB1: U1.2, U2.11
/AB2: U1.3, U2.10
/AB3: U1.4, U2.9
/AB4: U1.5, U2.8
/AB5: U1.14, U2.7
/AB6: U1.15, U2.6
/AB7: U1.16, U2.5
/AB8: U1.17, U2.27
/AB9: U1.18, U2.26
/AB10: U1.20, U2.23
/AB11: U1.21, U2.25
/AB12: U1.22, U2.4
/AB13: U1.23, U2.28
/AB14: U1.24, U2.3
/AB15: U1.32, U2.31
/AB16: U1.33, U2.2
/AB17: U1.34, U2.30
/AB18: U1.35, U2.1
/DB8: U1.7, U2.13
/DB9: U1.8, U2.14
/DB10: U1.11, U2.15
/DB11: U1.12, U2.17
/DB12: U1.25, U2.18
/DB13: U1.26, U2.19
/DB14: U1.29, U2.20
/DB15: U1.30, U2.21
/~CE: U1.6, U2.22
/~R: U1.31, U2.24
/~W: U1.13, U2.29
GND: C1.2, C2.2, U1.10, U1.28, U2.16

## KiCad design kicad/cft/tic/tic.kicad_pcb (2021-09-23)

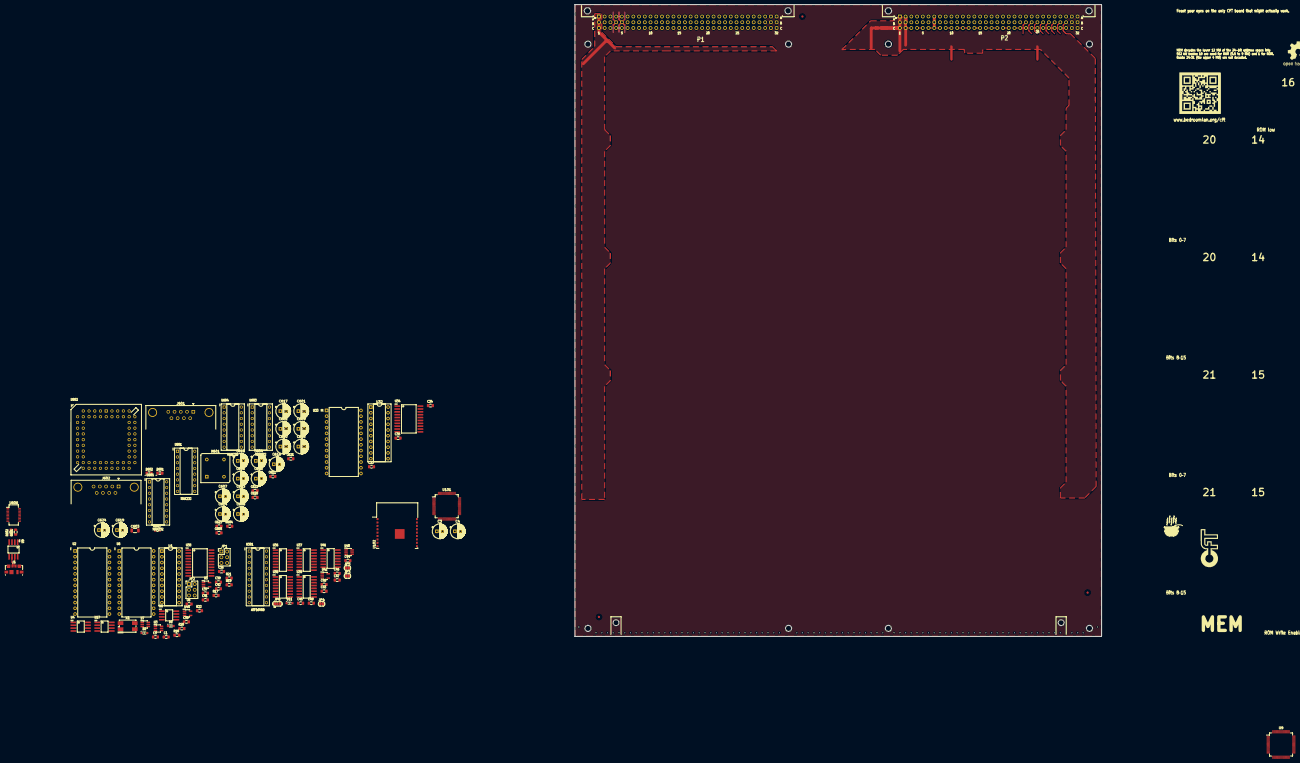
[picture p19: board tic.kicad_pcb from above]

Board: 2 copper layers, 233.4 x 280.0 mm, 105 parts (0 on the bottom side), 175 nets.

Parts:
C1, C5, C6, C33, C34, C35, C36, C37, C38, C39, C41, C42, C43, C44, C45, C46, C47, C48, C49, C605, C611, C620, C621: 100nF; C_SMD_0805_2012Metric_Pad1.15x1.40mm_HandSolder
C3, C4: 47µF; CP_Radial_D6.3mm_P2.50mm
C601, C602, C604, C606, C607, C608, C609, C610, C612, C613, C614, C615, C616, C617, C618, C619: 1μF; CP_Radial_D6.3mm_P2.50mm
C603: 1nF 3kV; C_1206_3216Metric
C622, C623: 47pF; C_SMD_0805_2012Metric_Pad1.15x1.40mm_HandSolder
C624: 4.7µF; CP_Radial_D6.3mm_P2.50mm
D1, D2, D11: CUS520; SOD-323
D601, D602: LED_ALT; LED_0805_2012Metric_Pad1.15x1.40mm_HandSolder
J1: USB_B_Micro; USB_Micro-B_Molex_47346-0001
J601, J602: DE9-Female-with-Shield; DSUB-9_Female_Horizontal_P2.77x2.84mm_EdgePinOffset4.94mm_H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
JP1, JP2: Conn_02x03_Odd_Even; PinHeader_2x03_P2.54mm_Vertical
JP3, JP4, JP5: SolderJumper_2_Open; SolderJumper-2_P1.3mm_Open_RoundedPad1.0x1.5mm
JP6: SolderJumper_3_Open; SolderJumper-3_P1.3mm_Bridged12_RoundedPad1.0x1.5mm
P1, P2: CFT-2021-Processor-Bus; DIN41612_B_3x32_Horizontal
R17, R18, R19, R20, R21, R22: 4.7kΩ; R_SMD_0805_2012Metric_Pad1.15x1.40mm_HandSolder
R601, R602: 27Ω; R_SMD_0805_2012Metric_Pad1.15x1.40mm_HandSolder
R603, R604: 560Ω; R_SMD_0805_2012Metric_Pad1.15x1.40mm_HandSolder
U1: 74HCT245; DIP-20_W7.62mm_Socket
U2, U6: 8254; DIP-24_W15.24mm_socket
U3, U7: 74LVC1G10; SOT-23-6_Handsoldering
U4, U8, U9, U17: USB6B1; SOIC-8
U5, U44: 74LVC1G08; SOT-23-5_HandSoldering
U9#2, U101: W5100; LQFP-80_10x10mm_P0.4mm
U32: 74HC574; DIP-20_W7.62mm_Socket
U33: M48T02-70PC1; eDIP-24_W15.24mm
U34, U35: 74HC541; SOIC-20W
U36, U39: 74HC139; SOIC-16
U37, U38: 74HC138; SOIC-16
U40: 74LVC1G11; SOT-23-6_Handsoldering
U41: 74HC74; SOIC-14
U42: 74LVC1G07; SOT-23-5_HandSoldering
U102: ESP-WROOM-02
U301: ATF16V8B; DIP-20_W7.62mm_Socket
U601, U603, U604, U605: MAX232; DIP-16_W7.62mm_Socket
U602: STC16C554; PLCC68
U606: FT231XS; SSOP-20_3.9x8.7mm_P0.635mm
X1: 32.768 kHz; Crystal_SMD_7050-4Pin_7.0x5.0mm
X601: 7.3728 MHz; Oscillator_DIP-8

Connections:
+5V: C1.1, C3.1, C4.1, C5.1, C6.1, C33.1, C34.1, C35.1, C36.1, C37.1, C38.1, C39.1, C41.1, C42.1, C43.1, C44.1, C45.1, C46.1, C47.1, C48.1, C49.1, C605.1, C611.1, P1.A1, P1.B1, P1.C1, P2.A1, P2.A2, P2.B1, P2.B2, P2.C1, P2.C2, R17.1, R18.1, R19.1, R20.1, R21.1, R22.1, U1.20, U2.24, U3.5, U4.1, U5.5, U6.24, U7.5, U8.1, U17.1, U32.20, U33.19, U33.22, U33.23, U33.24, U34.2, U34.3, U34.4, U34.5, U34.20, U35.2, U35.3, U35.4, U35.5, U35.20, U36.16, U37.16, U38.6, U38.16, U39.16, U40.5, U41.1, U41.13, U41.14, U42.5, U44.5, U601.16, U602.13, U602.30, U602.47, U602.54, U602.64, U603.16, U604.16, U605.16, X1.1, X1.4, X601.1, X601.8
+12V: P2.A7, P2.B7, P2.C7
/AB0: P2.C4, U2.19, U6.19, U602.32
/AB1: P2.A5, U2.20, U6.20, U36.2, U36.14, U39.2, U39.14, U301.1, U602.33
/AB2: P2.A6, U38.1, U301.2, U602.34
/AB3: P2.C6, U38.2, U301.3, U602.20
/AB4: P2.C8, U37.6, U38.3, U301.4, U602.50
/AB5: P2.C9, U37.2, U301.5
/AB6: P2.C10, U37.1, U301.6
/AB7: P2.C11, U37.5, U301.7
/Bus Interface/~IRCCS: U36.3, U36.13, U38.11
/Bus Interface/~SEL: U40.4, U41.2
/CLK3: U41.3, U41.11
/DB0: P2.A15, U1.9, U32.9, U33.9, U602.66
/DB1: P2.A16, U1.8, U32.8, U33.10, U602.67
/DB2: P2.A17, U1.7, U32.7, U33.11, U602.68
/DB3: P2.A18, U1.6, U32.6, U33.13, U602.1
/DB4: P2.A19, U1.5, U32.5, U33.14, U602.2
/DB5: P2.A20, U1.4, U32.4, U33.15, U602.3
/DB6: P2.A21, U1.3, U32.3, U33.16, U602.4
/DB7: P2.A22, U1.2, U32.2, U33.17, U602.5
/Quad Serial Board/CTSC: U602.45, U606.2
/Quad Serial Board/D'+: C623.1, R601.1, U9.2
/Quad Serial Board/D'-: C622.1, R602.1, U9.3
/Quad Serial Board/D+: J1.3, U9.7
/Quad Serial Board/D-: J1.2, U9.6
/Quad Serial Board/DSRC: U602.43, U602.44, U606.1
/Quad Serial Board/DTRC: U602.46, U606.7, U606.8
/Quad Serial Board/RS-CTSA: J601.7, U601.8
/Quad Serial Board/RS-CTSB: J602.7, U604.8
/Quad Serial Board/RS-DCDA: J601.1, U603.8
/Quad Serial Board/RS-DCDB: J602.1, U605.8
/Quad Serial Board/RS-DSRA: J601.6, U603.13
/Quad Serial Board/RS-DSRB: J602.6, U605.13
/Quad Serial Board/RS-DTRA: J601.4, U603.14
/Quad Serial Board/RS-DTRB: J602.4, U605.14
/Quad Serial Board/RS-RIA: J601.9, U603.7
/Quad Serial Board/RS-RIB: J602.9, U605.7
/Quad Serial Board/RS-RTSA: J601.8, U601.7
/Quad Serial Board/RS-RTSB: J602.8, U604.7
/Quad Serial Board/RS-RXA: J601.3, U601.13
/Quad Serial Board/RS-RXB: J602.3, U604.13
/Quad Serial Board/RS-TXA: J601.2, U601.14
/Quad Serial Board/RS-TXB: J602.2, U604.14
/Quad Serial Board/RTSC: U602.48, U606.9
/Quad Serial Board/RX0: U601.12, U602.7
/Quad Serial Board/RX1: U602.29, U604.12
/Quad Serial Board/RXC: U602.41, U606.20
/Quad Serial Board/TX0: U601.11, U602.17
/Quad Serial Board/TX1: U602.19, U604.11
/Quad Serial Board/TXC: U602.51, U606.4
/Quad Serial Board/USBD+: R601.2, U606.11
/Quad Serial Board/USBD-: R602.2, U606.12
/Quad Serial Board/~CD0: U602.9, U603.9
/Quad Serial Board/~CD1: U602.27, U605.9
/Quad Serial Board/~CTS0: U601.9, U602.11
/Quad Serial Board/~CTS1: U602.25, U604.9
/Quad Serial Board/~DSR0: U602.10, U603.12
/Quad Serial Board/~DSR1: U602.26, U605.12
/Quad Serial Board/~DTR0: U602.12, U603.11
/Quad Serial Board/~DTR1: U602.24, U605.11
/Quad Serial Board/~RI0: U602.8, U603.10
/Quad Serial Board/~RI1: U602.28, U605.10
/Quad Serial Board/~RTS0: U601.10, U602.14
/Quad Serial Board/~RTS1: U602.22, U604.10
/Quad Serial Board/~RXLED: R604.1, U606.10
/Quad Serial Board/~TXLED: R603.1, U606.17
/Real Time Clock/DB8: P2.A23, U34.18, U35.18
/Real Time Clock/DB9: P2.A24, U34.17, U35.17
/Real Time Clock/DB10: P2.A25, U34.16, U35.16
/Real Time Clock/DB11: P2.A26, U34.15, U35.15
/Real Time Clock/DB12: P2.A27, U34.14, U35.14
/Real Time Clock/DB13: P2.A28, U34.13, U35.13
/Real Time Clock/DB14: P2.A29, U34.12, U35.12
/Real Time Clock/DB15: P2.A30, U34.11, U35.11
/Real Time Clock/RTCA0: U32.12, U33.8
/Real Time Clock/RTCA1: U32.13, U33.7
/Real Time Clock/RTCA2: U32.14, U33.6
/Real Time Clock/RTCA3: U32.15, U33.5
/Real Time Clock/RTCA4: U32.16, U33.4
/Real Time Clock/RTCA5: U32.17, U33.3
/Real Time Clock/RTCA6: U32.18, U33.2
/Real Time Clock/RTCA7: U32.19, U33.1
/Timers/G0-0: R17.2, U2.11, U4.2
/Timers/G0-1: R18.2, U2.14, U4.3
/Timers/G0-2: R19.2, U2.16, U8.2
/Timers/G1-0: R20.2, U6.11, U8.3
/Timers/G1-1: R21.2, U6.14, U17.3
/Timers/G1-2: R22.2, U6.16, U17.2
/Timers/OUT0-0: U2.10, U3.6
/Timers/OUT0-1: U2.13, U3.3
/Timers/OUT0-2: U2.17, U3.1
/Timers/OUT1-0: U6.10, U7.6
/Timers/OUT1-1: U6.13, U7.3
/Timers/OUT1-2: U6.17, U7.1
/Timers/TCLK: U2.9, U2.15, U2.18, U6.9, U6.15, U6.18, X1.3
/Timers/TD0: U1.11, U2.8, U6.8
/Timers/TD1: U1.12, U2.7, U6.7
/Timers/TD2: U1.13, U2.6, U6.6
/Timers/TD3: U1.14, U2.5, U6.5
/Timers/TD4: U1.15, U2.4, U6.4
/Timers/TD5: U1.16, U2.3, U6.3
/Timers/TD6: U1.17, U2.2, U6.2
/Timers/TD7: U1.18, U2.1, U6.1
/Timers/~CS: U1.19, U5.4
/~IRQ0i: JP1.2, JP2.2
/~IRQ1i: JP1.4, JP2.4
/~IRQ2i: JP1.6, JP2.6
/~R: P2.C12, U1.1, U2.22, U6.22, U35.19, U36.1, U301.9, U602.52
/~RESET: P2.A3, U41.4, U41.10
/~RSTHOLD: P2.C3, U602.37, U606.14
/~RTCAW: U32.11, U39.12
/~RTCCS: JP5.1, U33.18, U34.19, U38.7, U39.3, U39.13
/~RTCR: U33.20, U34.1, U39.5
/~RTCW: U33.21, U39.11
/~SYSDEV: U37.4, U38.4
/~T0CS: JP3.1, U2.21, U5.2, U35.6, U38.10, U44.2
/~T1CS: JP4.1, U5.1, U6.21, U35.7, U38.9, U44.1
/~W: P2.C13, U2.23, U6.23, U36.15, U39.15, U301.8, U602.18
/~WS: D11.2, P2.C5, U42.4
Earth: C603.1, J1.6, J601.0, J602.0
GND: C1.2, C3.2, C4.2, C5.2, C6.2, C33.2, C34.2, C35.2, C36.2, C37.2, C38.2, C39.2, C41.2, C42.2, C43.2, C44.2, C45.2, C46.2, C47.2, C48.2, C49.2, C601.1, C602.1, C603.2, C604.1, C605.2, C608.1, C611.2, C612.1, C613.1, C616.1, C617.1, C620.2, C621.2, C622.2, C623.2, C624.2, J1.5, J601.5, J602.5, P1.A31, P1.A32, P1.B4, P1.B5, P1.B31, P1.B32, P1.C31, P1.C32, P2.A31, P2.A32, P2.B31, P2.B32, P2.C31, P2.C32, U1.10, U2.12, U3.2, U4.4, U5.3, U6.12, U7.2, U8.4, U9.4, U9.5, U17.4, U32.1, U32.10, U33.12, U34.6, U34.7, U34.8, U34.9, U34.10, U35.8, U35.9, U35.10, U36.8, U37.3, U37.8, U38.8, U39.8, U40.2, U41.7, U42.3, U44.3, U601.15, U602.6, U602.23, U602.31, U602.40, U602.57, U602.65, U603.15, U604.15, U605.15, U606.6, U606.16, X1.2, X601.4
unnamed: C601.2, U601.2
unnamed: C602.2, U601.6
unnamed: C604.2, U603.6
unnamed: C606.1, U601.1
unnamed: C606.2, U601.3
unnamed: C607.1, U601.4
unnamed: C607.2, U601.5
unnamed: C608.2, U603.2
unnamed: C609.1, U603.1
unnamed: C609.2, U603.3
unnamed: C610.1, U603.4
unnamed: C610.2, U603.5
unnamed: C612.2, U604.6
unnamed: C613.2, U604.2
unnamed: C614.1, U604.1
unnamed: C614.2, U604.3
unnamed: C615.1, U604.4
unnamed: C615.2, U604.5
unnamed: C616.2, U605.6
unnamed: C617.2, U605.2
unnamed: C618.1, U605.1
unnamed: C618.2, U605.3
unnamed: C619.1, U605.4
unnamed: C619.2, U605.5
unnamed: C620.1, U606.13
unnamed: C621.1, C624.1, D601.1, D602.1, U9.1, U606.3, U606.15
unnamed: D1.1, U3.4
unnamed: D1.2, JP1.1, JP1.3, JP1.5
unnamed: D2.1, U7.4
unnamed: D2.2, JP2.1, JP2.3, JP2.5
unnamed: D11.1, JP6.2, U42.2
unnamed: D601.2, R603.2
unnamed: D602.2, R604.2
unnamed: J1.1, U9.8
unnamed: JP3.2, U40.3
unnamed: JP4.2, U40.1
unnamed: JP5.2, U40.6
unnamed: JP6.1, U41.5, U41.12
unnamed: JP6.3, U41.9
unnamed: U9#2.7, U9#2.74
unnamed: U9#2.4, U9#2.10, U9#2.77
unnamed: U9#2.12, U9#2.18, U9#2.44
unnamed: U9#2.13, U9#2.14, U9#2.17, U9#2.32, U9#2.43, U9#2.68
unnamed: U9#2.15, U9#2.16, U9#2.33, U9#2.69
unnamed: U35.1, U44.4
unnamed: U37.15, U38.5
unnamed: U101.7, U101.74
unnamed: U101.4, U101.10, U101.77
unnamed: U101.12, U101.18, U101.44
unnamed: U101.13, U101.14, U101.17, U101.32, U101.43, U101.68
unnamed: U101.15, U101.16, U101.33, U101.69
unnamed: U102.9, U102.13, U102.18, U102.19
unnamed: U602.35, X601.5

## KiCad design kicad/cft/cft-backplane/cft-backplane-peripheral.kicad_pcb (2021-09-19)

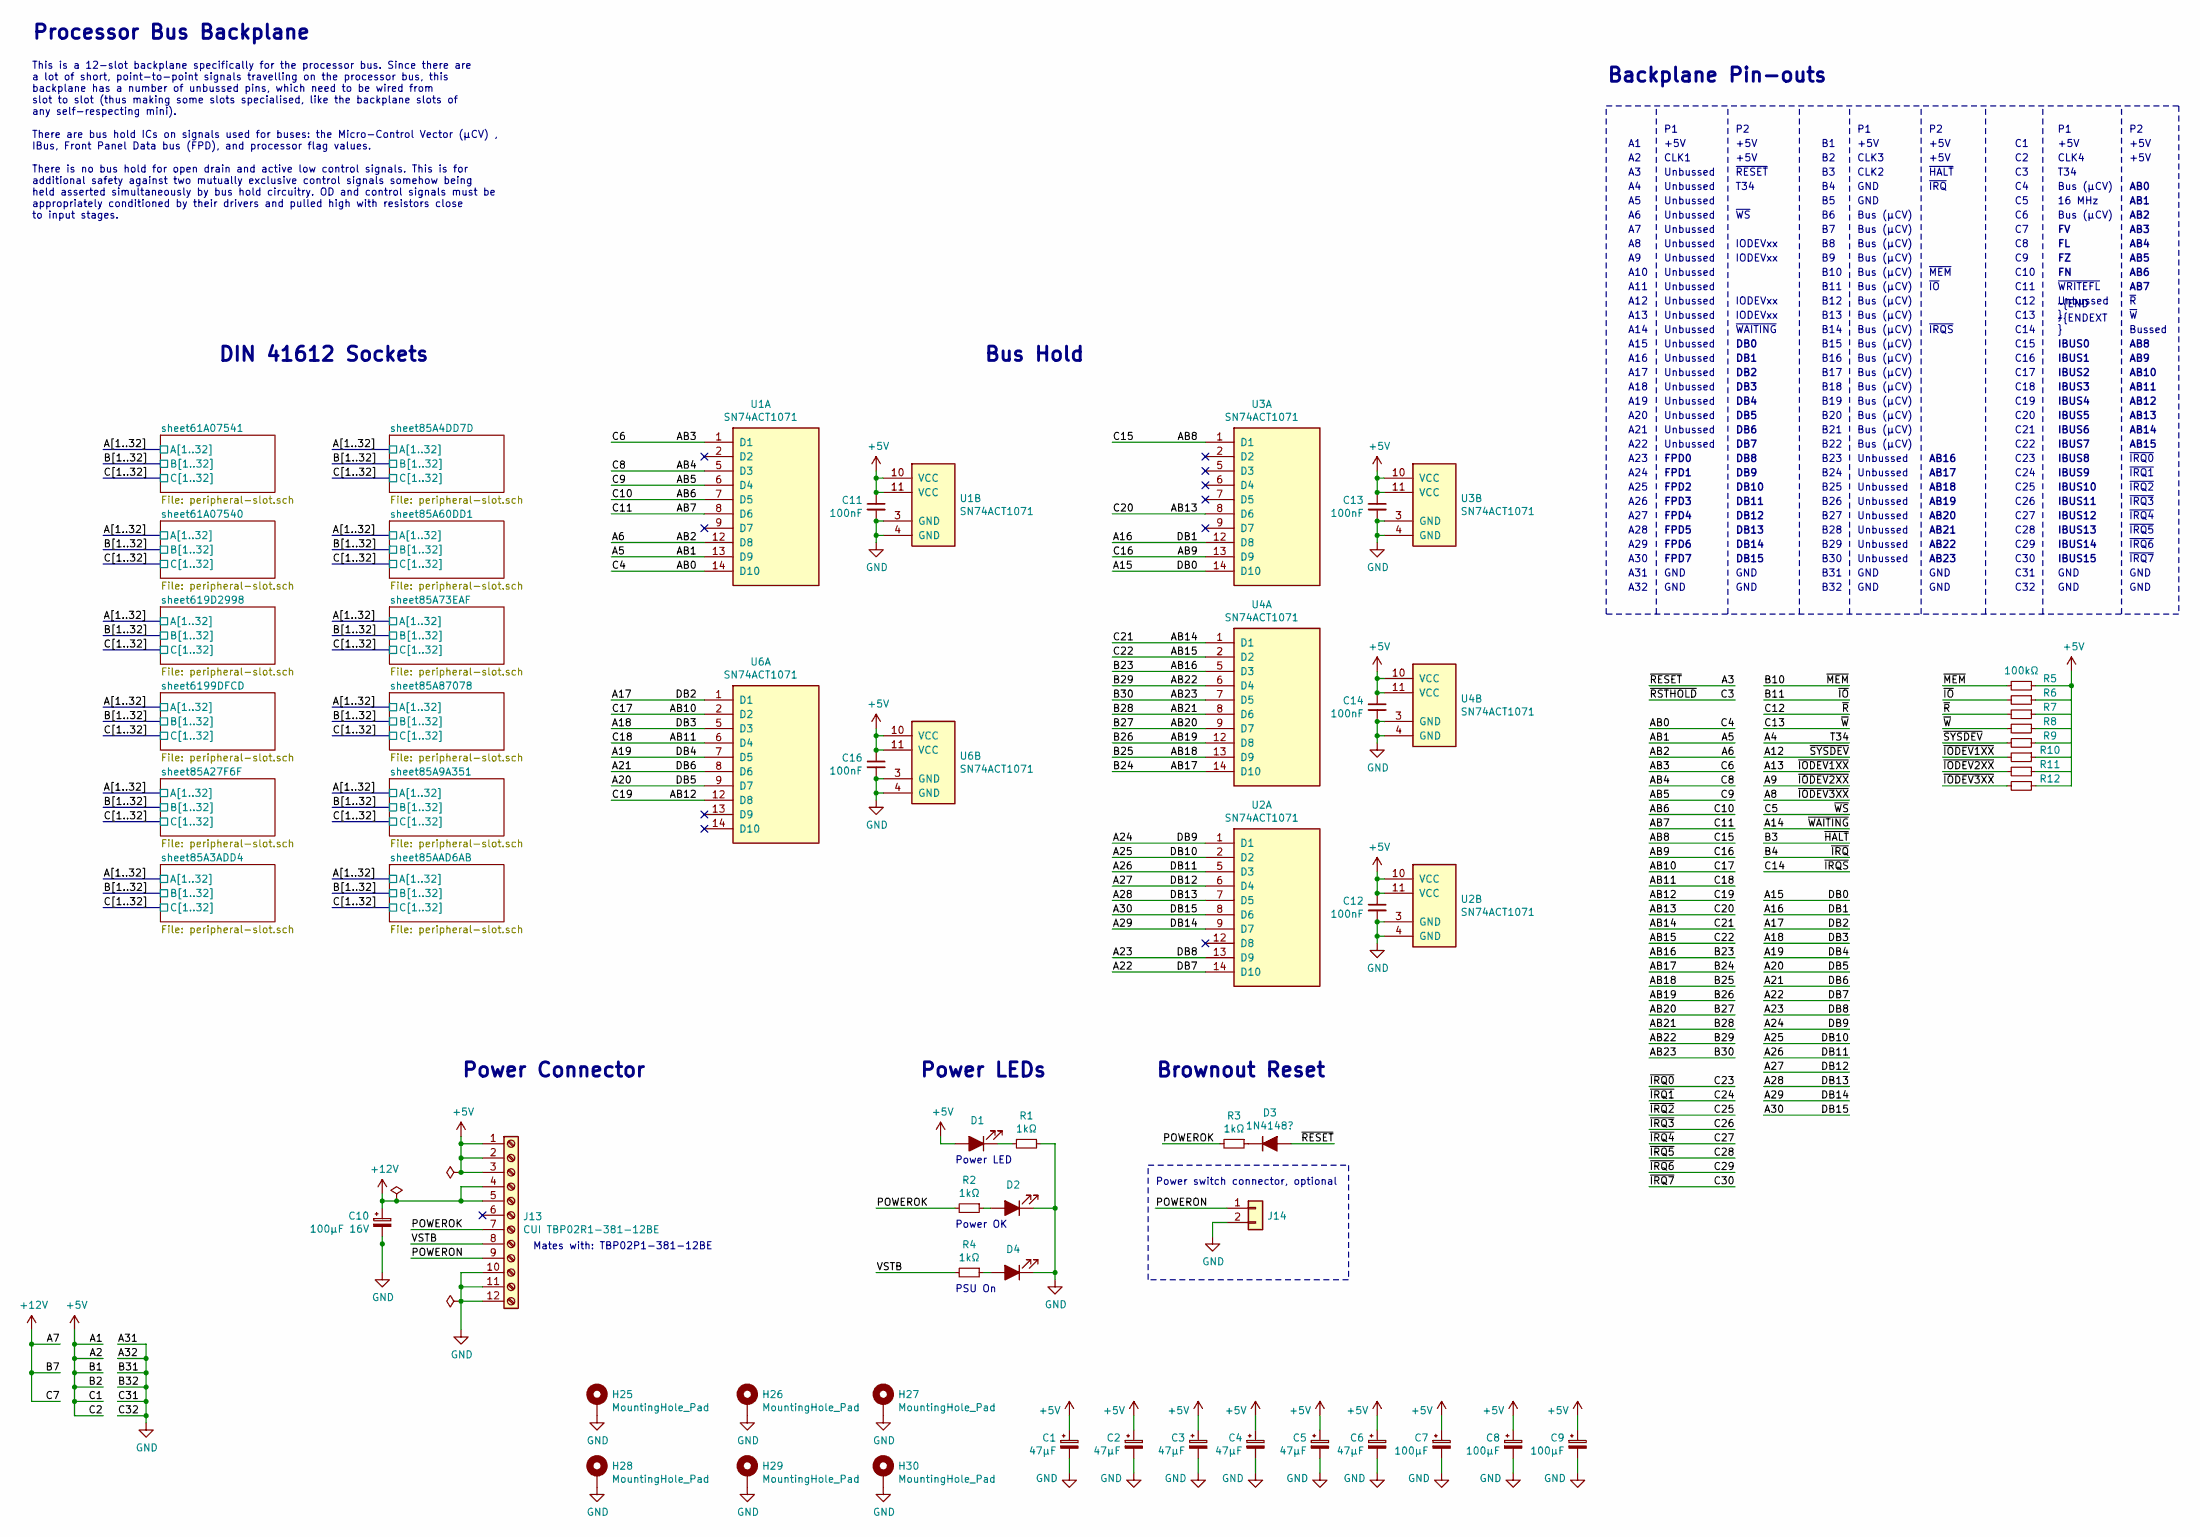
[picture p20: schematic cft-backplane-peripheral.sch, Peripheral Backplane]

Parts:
C1, C2, C3, C4, C5, C6: 47µF; CP_Radial_D6.3mm_P2.50mm
C7, C8, C9: 100µF; CP_Radial_D6.3mm_P2.50mm
C10: 100µF 16V; CP_Radial_D6.3mm_P2.50mm
C11, C12, C13, C14, C16: 100nF; C_SMD_0805_2012Metric_Pad1.15x1.40mm_HandSolder
D1, D2, D4: LED_ALT; LED_0805_2012Metric_Pad1.15x1.40mm_HandSolder
D3: 1N4148?; SOD-323
H25, H26, H27, H28, H29, H30: MountingHole_Pad; MountingHole_2.7mm_M2.5_ISO14580_Pad
J13: CUI TBP02R1-381-12BE; CUI-TBP02R1-381-12BE
J14: 2.54mm header; PinHeader_2x01_P2.54mm_Vertical
R1, R2, R3, R4: 1kΩ; R_SMD_0805_2012Metric_Pad1.15x1.40mm_HandSolder
R5, R6, R7, R8, R9, R10, R11, R12: 100kΩ; R_SMD_0805_2012Metric_Pad1.15x1.40mm_HandSolder
U1, U2, U3, U4, U6: SN74ACT1071; SOIC-14

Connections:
+5V: C1.1, C2.1, C3.1, C4.1, C5.1, C6.1, C7.1, C8.1, C9.1, C11.1, C12.1, C13.1, C14.1, C16.1, D1.2 (A), J13.1, J13.2, J13.3, R5.1, R6.1, R7.1, R8.1, R9.1, R10.1, R11.1, R12.1, U1.10 (VCC), U1.11 (VCC), U2.10 (VCC), U2.11 (VCC), U3.10 (VCC), U3.11 (VCC), U4.10 (VCC), U4.11 (VCC), U6.10 (VCC), U6.11 (VCC); also elsewhere on the board
+12V: C10.1, J13.4, J13.5; also elsewhere on the board
/A3: D3.2 (A); also elsewhere on the board
/A5: U1.13 (D9); also elsewhere on the board
/A6: U1.12 (D8); also elsewhere on the board
/A8: R12.2; also elsewhere on the board
/A9: R11.2; also elsewhere on the board
/A12: R9.2; also elsewhere on the board
/A13: R10.2; also elsewhere on the board
/A15: U3.14 (D10); also elsewhere on the board
/A16: U3.12 (D8); also elsewhere on the board
/A17: U6.1 (D1); also elsewhere on the board
/A18: U6.5 (D3); also elsewhere on the board
/A19: U6.7 (D5); also elsewhere on the board
/A20: U6.9 (D7); also elsewhere on the board
/A21: U6.8 (D6); also elsewhere on the board
/A22: U2.14 (D10); also elsewhere on the board
/A23: U2.13 (D9); also elsewhere on the board
/A24: U2.1 (D1); also elsewhere on the board
/A25: U2.2 (D2); also elsewhere on the board
/A26: U2.5 (D3); also elsewhere on the board
/A27: U2.6 (D4); also elsewhere on the board
/A28: U2.7 (D5); also elsewhere on the board
/A29: U2.9 (D7); also elsewhere on the board
/A30: U2.8 (D6); also elsewhere on the board
/AB0: U1.14 (D10); also elsewhere on the board
/AB3: U1.1 (D1); also elsewhere on the board
/AB4: U1.5 (D3); also elsewhere on the board
/AB5: U1.6 (D4); also elsewhere on the board
/AB6: U1.7 (D5); also elsewhere on the board
/AB7: U1.8 (D6); also elsewhere on the board
/AB8: U3.1 (D1); also elsewhere on the board
/AB9: U3.13 (D9); also elsewhere on the board
/AB10: U6.2 (D2); also elsewhere on the board
/AB11: U6.6 (D4); also elsewhere on the board
/AB12: U6.12 (D8); also elsewhere on the board
/AB13: U3.8 (D6); also elsewhere on the board
/AB14: U4.1 (D1); also elsewhere on the board
/AB15: U4.2 (D2); also elsewhere on the board
/AB16: U4.5 (D3); also elsewhere on the board
/AB17: U4.14 (D10); also elsewhere on the board
/AB18: U4.13 (D9); also elsewhere on the board
/AB19: U4.12 (D8); also elsewhere on the board
/AB20: U4.9 (D7); also elsewhere on the board
/AB21: U4.8 (D6); also elsewhere on the board
/AB22: U4.6 (D4); also elsewhere on the board
/AB23: U4.7 (D5); also elsewhere on the board
/B10: R5.2; also elsewhere on the board
/B11: R6.2; also elsewhere on the board
/C12: R7.2; also elsewhere on the board
/C13: R8.2; also elsewhere on the board
/POWEROK: J13.7, R2.2, R3.2
/POWERON: J13.9, J14.1
/VSTB: J13.8, R4.2
GND: C1.2, C2.2, C3.2, C4.2, C5.2, C6.2, C7.2, C8.2, C9.2, C10.2, C11.2, C12.2, C13.2, C14.2, C16.2, D2.1 (K), D4.1 (K), H25.1, H26.1, H27.1, H28.1, H29.1, H30.1, J13.10, J13.11, J13.12, J14.2, R1.1, U1.3 (GND), U1.4 (GND), U2.3 (GND), U2.4 (GND), U3.3 (GND), U3.4 (GND), U4.3 (GND), U4.4 (GND), U6.3 (GND), U6.4 (GND); also elsewhere on the board
unnamed: D1.1 (K), R1.2
unnamed: D2.2 (A), R2.1
unnamed: D3.1 (K), R3.1
unnamed: D4.2 (A), R4.1

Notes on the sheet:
Processor Bus Backplane
This is a 12-slot backplane specifically for the processor bus. Since there are a lot of short, point-to-point signals travelling on the processor bus, this backplane has a number of unbussed pins, which need to be wired from slot to slot (thus making some slots specialised, like the backplane slot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
A10
A11
A12
A13
A14
A17
A18
A19
A20
A21
A22
A23
A24
A25
A26
A27
A28
A29
A30
A31
A32
C32
C31
C30
C29
C28
C27
C26
C25
C24
C23
C22
C21
C20
C19
C18
C17
C16

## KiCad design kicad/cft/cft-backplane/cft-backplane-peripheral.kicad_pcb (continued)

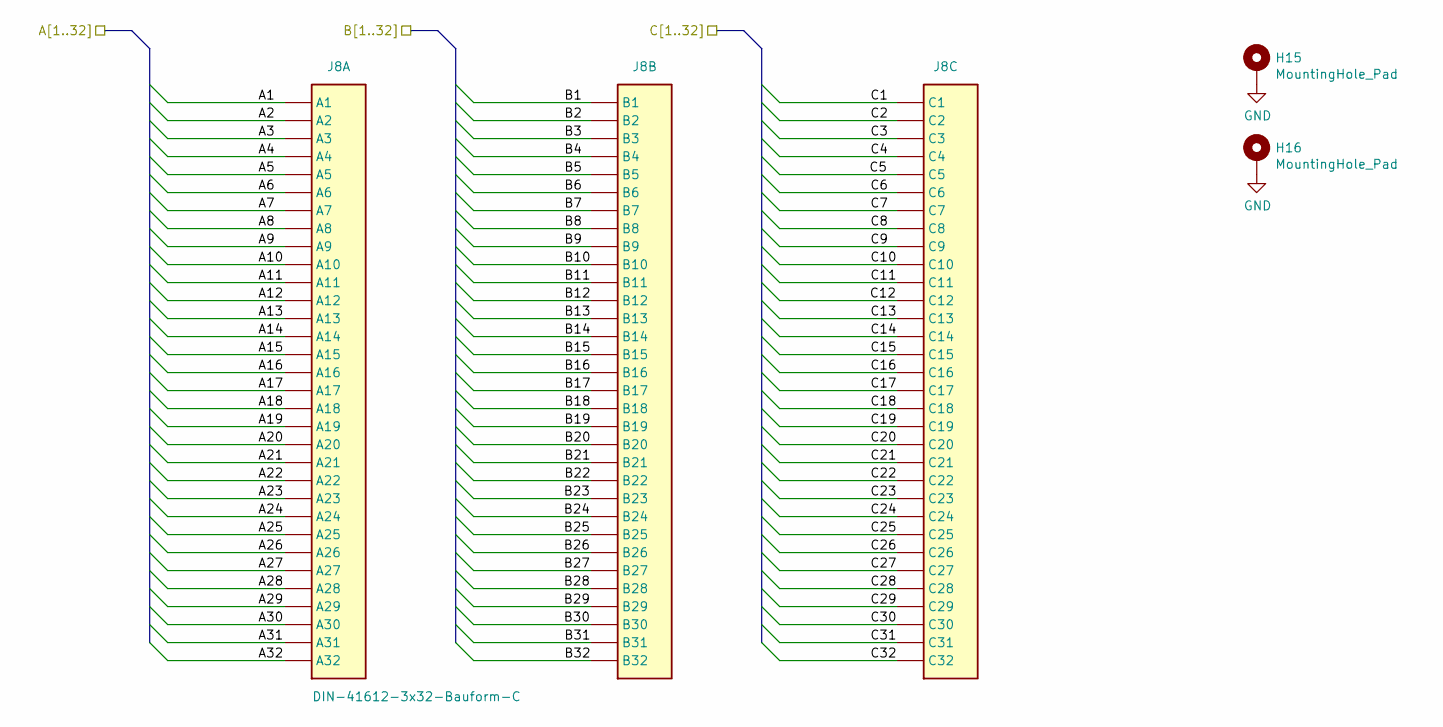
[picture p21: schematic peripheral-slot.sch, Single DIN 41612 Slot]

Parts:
H1, H2: MountingHole_Pad; MountingHole_2.7mm_M2.5_ISO14580_Pad
J5: DIN-41612-3x32-Bauform-C; DIN41612_C_3x32_Female_Vertical_THT

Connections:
+5V: J5.A1, J5.A2, J5.B1, J5.B2, J5.C1, J5.C2; also elsewhere on the board
+12V: J5.A7, J5.B7, J5.C7; also elsewhere on the board
/A3: J5.A3; also elsewhere on the board
/A4: J5.A4; also elsewhere on the board
/A5: J5.A5; also elsewhere on the board
/A6: J5.A6; also elsewhere on the board
/A8: J5.A8; also elsewhere on the board
/A9: J5.A9; also elsewhere on the board
/A12: J5.A12; also elsewhere on the board
/A13: J5.A13; also elsewhere on the board
/A14: J5.A14; also elsewhere on the board
/A15: J5.A15; also elsewhere on the board
/A16: J5.A16; also elsewhere on the board
/A17: J5.A17; also elsewhere on the board
/A18: J5.A18; also elsewhere on the board
/A19: J5.A19; also elsewhere on the board
/A20: J5.A20; also elsewhere on the board
/A21: J5.A21; also elsewhere on the board
/A22: J5.A22; also elsewhere on the board
/A23: J5.A23; also elsewhere on the board
/A24: J5.A24; also elsewhere on the board
/A25: J5.A25; also elsewhere on the board
/A26: J5.A26; also elsewhere on the board
/A27: J5.A27; also elsewhere on the board
/A28: J5.A28; also elsewhere on the board
/A29: J5.A29; also elsewhere on the board
/A30: J5.A30; also elsewhere on the board
/AB0: J5.C4; also elsewhere on the board
/AB3: J5.C6; also elsewhere on the board
/AB4: J5.C8; also elsewhere on the board
/AB5: J5.C9; also elsewhere on the board
/AB6: J5.C10; also elsewhere on the board
/AB7: J5.C11; also elsewhere on the board
/AB8: J5.C15; also elsewhere on the board
/AB9: J5.C16; also elsewhere on the board
/AB10: J5.C17; also elsewhere on the board
/AB11: J5.C18; also elsewhere on the board
/AB12: J5.C19; also elsewhere on the board
/AB13: J5.C20; also elsewhere on the board
/AB14: J5.C21; also elsewhere on the board
/AB15: J5.C22; also elsewhere on the board
/AB16: J5.B23; also elsewhere on the board
/AB17: J5.B24; also elsewhere on the board
/AB18: J5.B25; also elsewhere on the board
/AB19: J5.B26; also elsewhere on the board
/AB20: J5.B27; also elsewhere on the board
/AB21: J5.B28; also elsewhere on the board
/AB22: J5.B29; also elsewhere on the board
/AB23: J5.B30; also elsewhere on the board
/B3: J5.B3; also elsewhere on the board
/B4: J5.B4; also elsewhere on the board
/B10: J5.B10; also elsewhere on the board
/B11: J5.B11; also elsewhere on the board
/C3: J5.C3; also elsewhere on the board
/C5: J5.C5; also elsewhere on the board
/C12: J5.C12; also elsewhere on the board
/C13: J5.C13; also elsewhere on the board
/C14: J5.C14; also elsewhere on the board
/C23: J5.C23; also elsewhere on the board
/C24: J5.C24; also elsewhere on the board
/C25: J5.C25; also elsewhere on the board
/C26: J5.C26; also elsewhere on the board
/C27: J5.C27; also elsewhere on the board
/C28: J5.C28; also elsewhere on the board
/C29: J5.C29; also elsewhere on the board
/C30: J5.C30; also elsewhere on the board
/sheet6199DFCD/A10: J5.A10; also elsewhere on the board
/sheet6199DFCD/A11: J5.A11; also elsewhere on the board
/sheet6199DFCD/B5: J5.B5; also elsewhere on the board
/sheet6199DFCD/B6: J5.B6; also elsewhere on the board
/sheet6199DFCD/B8: J5.B8; also elsewhere on the board
/sheet6199DFCD/B9: J5.B9; also elsewhere on the board
/sheet6199DFCD/B12: J5.B12; also elsewhere on the board
/sheet6199DFCD/B13: J5.B13; also elsewhere on the board
/sheet6199DFCD/B14: J5.B14; also elsewhere on the board
/sheet6199DFCD/B15: J5.B15; also elsewhere on the board
/sheet6199DFCD/B16: J5.B16; also elsewhere on the board
/sheet6199DFCD/B17: J5.B17; also elsewhere on the board
/sheet6199DFCD/B18: J5.B18; also elsewhere on the board
/sheet6199DFCD/B19: J5.B19; also elsewhere on the board
/sheet6199DFCD/B20: J5.B20; also elsewhere on the board
/sheet6199DFCD/B21: J5.B21; also elsewhere on the board
/sheet6199DFCD/B22: J5.B22; also elsewhere on the board
GND: H1.1, H2.1, J5.A31, J5.A32, J5.B31, J5.B32, J5.C31, J5.C32; also elsewhere on the board

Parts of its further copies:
H3, H4, H5, H6, H7, H8, H9, H10, H11, H12, H13, H14, H15, H16, H17, H18, H19, H20, H21, H22, H23, H24: MountingHole_Pad; MountingHole_2.7mm_M2.5_ISO14580_Pad
J1, J2, J3, J4, J6, J7, J8, J9, J10, J11, J12: DIN-41612-3x32-Bauform-C; DIN41612_C_3x32_Female_Vertical_THT

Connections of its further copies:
+5V: J1.A1, J1.A2, J1.B1, J1.B2, J1.C1, J1.C2, J2.A1, J2.A2, J2.B1, J2.B2, J2.C1, J2.C2, J3.A1, J3.A2, J3.B1, J3.B2, J3.C1, J3.C2, J4.A1, J4.A2, J4.B1, J4.B2, J4.C1, J4.C2, J6.A1, J6.A2, J6.B1, J6.B2, J6.C1, J6.C2, J7.A1, J7.A2, J7.B1, J7.B2, J7.C1, J7.C2, J8.A1, J8.A2, J8.B1, J8.B2, J8.C1, J8.C2, J9.A1, J9.A2, J9.B1, J9.B2, J9.C1, J9.C2, J10.A1, J10.A2, J10.B1, J10.B2, J10.C1, J10.C2, J11.A1, J11.A2, J11.B1, J11.B2, J11.C1, J11.C2, J12.A1, J12.A2, J12.B1, J12.B2, J12.C1, J12.C2; also elsewhere on the board
+12V: J1.A7, J1.B7, J1.C7, J2.A7, J2.B7, J2.C7, J3.A7, J3.B7, J3.C7, J4.A7, J4.B7, J4.C7, J6.A7, J6.B7, J6.C7, J7.A7, J7.B7, J7.C7, J8.A7, J8.B7, J8.C7, J9.A7, J9.B7, J9.C7, J10.A7, J10.B7, J10.C7, J11.A7, J11.B7, J11.C7, J12.A7, J12.B7, J12.C7; also elsewhere on the board
/A3: J1.A3, J2.A3, J3.A3, J4.A3, J6.A3, J7.A3, J8.A3, J9.A3, J10.A3, J11.A3, J12.A3; also elsewhere on the board
/A4: J1.A4, J2.A4, J3.A4, J4.A4, J6.A4, J7.A4, J8.A4, J9.A4, J10.A4, J11.A4, J12.A4; also elsewhere on the board
/A5: J1.A5, J2.A5, J3.A5, J4.A5, J6.A5, J7.A5, J8.A5, J9.A5, J10.A5, J11.A5, J12.A5; also elsewhere on the board
/A6: J1.A6, J2.A6, J3.A6, J4.A6, J6.A6, J7.A6, J8.A6, J9.A6, J10.A6, J11.A6, J12.A6; also elsewhere on the board
/A8: J1.A8, J2.A8, J3.A8, J4.A8, J6.A8, J7.A8, J8.A8, J9.A8, J10.A8, J11.A8, J12.A8; also elsewhere on the board
/A9: J1.A9, J2.A9, J3.A9, J4.A9, J6.A9, J7.A9, J8.A9, J9.A9, J10.A9, J11.A9, J12.A9; also elsewhere on the board
/A12: J1.A12, J2.A12, J3.A12, J4.A12, J6.A12, J7.A12, J8.A12, J9.A12, J10.A12, J11.A12, J12.A12; also elsewhere on the board
/A13: J1.A13, J2.A13, J3.A13, J4.A13, J6.A13, J7.A13, J8.A13, J9.A13, J10.A13, J11.A13, J12.A13; also elsewhere on the board
/A14: J1.A14, J2.A14, J3.A14, J4.A14, J6.A14, J7.A14, J8.A14, J9.A14, J10.A14, J11.A14, J12.A14; also elsewhere on the board
/A15: J1.A15, J2.A15, J3.A15, J4.A15, J6.A15, J7.A15, J8.A15, J9.A15, J10.A15, J11.A15, J12.A15; also elsewhere on the board
/A16: J1.A16, J2.A16, J3.A16, J4.A16, J6.A16, J7.A16, J8.A16, J9.A16, J10.A16, J11.A16, J12.A16; also elsewhere on the board
/A17: J1.A17, J2.A17, J3.A17, J4.A17, J6.A17, J7.A17, J8.A17, J9.A17, J10.A17, J11.A17, J12.A17; also elsewhere on the board
/A18: J1.A18, J2.A18, J3.A18, J4.A18, J6.A18, J7.A18, J8.A18, J9.A18, J10.A18, J11.A18, J12.A18; also elsewhere on the board
/A19: J1.A19, J2.A19, J3.A19, J4.A19, J6.A19, J7.A19, J8.A19, J9.A19, J10.A19, J11.A19, J12.A19; also elsewhere on the board
/A20: J1.A20, J2.A20, J3.A20, J4.A20, J6.A20, J7.A20, J8.A20, J9.A20, J10.A20, J11.A20, J12.A20; also elsewhere on the board
/A21: J1.A21, J2.A21, J3.A21, J4.A21, J6.A21, J7.A21, J8.A21, J9.A21, J10.A21, J11.A21, J12.A21; also elsewhere on the board
/A22: J1.A22, J2.A22, J3.A22, J4.A22, J6.A22, J7.A22, J8.A22, J9.A22, J10.A22, J11.A22, J12.A22; also elsewhere on the board
/A23: J1.A23, J2.A23, J3.A23, J4.A23, J6.A23, J7.A23, J8.A23, J9.A23, J10.A23, J11.A23, J12.A23; also elsewhere on the board
/A24: J1.A24, J2.A24, J3.A24, J4.A24, J6.A24, J7.A24, J8.A24, J9.A24, J10.A24, J11.A24, J12.A24; also elsewhere on the board
/A25: J1.A25, J2.A25, J3.A25, J4.A25, J6.A25, J7.A25, J8.A25, J9.A25, J10.A25, J11.A25, J12.A25; also elsewhere on the board
/A26: J1.A26, J2.A26, J3.A26, J4.A26, J6.A26, J7.A26, J8.A26, J9.A26, J10.A26, J11.A26, J12.A26; also elsewhere on the board
/A27: J1.A27, J2.A27, J3.A27, J4.A27, J6.A27, J7.A27, J8.A27, J9.A27, J10.A27, J11.A27, J12.A27; also elsewhere on the board
/A28: J1.A28, J2.A28, J3.A28, J4.A28, J6.A28, J7.A28, J8.A28, J9.A28, J10.A28, J11.A28, J12.A28; also elsewhere on the board
/A29: J1.A29, J2.A29, J3.A29, J4.A29, J6.A29, J7.A29, J8.A29, J9.A29, J10.A29, J11.A29, J12.A29; also elsewhere on the board
/A30: J1.A30, J2.A30, J3.A30, J4.A30, J6.A30, J7.A30, J8.A30, J9.A30, J10.A30, J11.A30, J12.A30; also elsewhere on the board
/AB0: J1.C4, J2.C4, J3.C4, J4.C4, J6.C4, J7.C4, J8.C4, J9.C4, J10.C4, J11.C4, J12.C4; also elsewhere on the board
/AB3: J1.C6, J2.C6, J3.C6, J4.C6, J6.C6, J7.C6, J8.C6, J9.C6, J10.C6, J11.C6, J12.C6; also elsewhere on the board
/AB4: J1.C8, J2.C8, J3.C8, J4.C8, J6.C8, J7.C8, J8.C8, J9.C8, J10.C8, J11.C8, J12.C8; also elsewhere on the board
/AB5: J1.C9, J2.C9, J3.C9, J4.C9, J6.C9, J7.C9, J8.C9, J9.C9, J10.C9, J11.C9, J12.C9; also elsewhere on the board
/AB6: J1.C10, J2.C10, J3.C10, J4.C10, J6.C10, J7.C10, J8.C10, J9.C10, J10.C10, J11.C10, J12.C10; also elsewhere on the board
/AB7: J1.C11, J2.C11, J3.C11, J4.C11, J6.C11, J7.C11, J8.C11, J9.C11, J10.C11, J11.C11, J12.C11; also elsewhere on the board
/AB8: J1.C15, J2.C15, J3.C15, J4.C15, J6.C15, J7.C15, J8.C15, J9.C15, J10.C15, J11.C15, J12.C15; also elsewhere on the board
/AB9: J1.C16, J2.C16, J3.C16, J4.C16, J6.C16, J7.C16, J8.C16, J9.C16, J10.C16, J11.C16, J12.C16; also elsewhere on the board
/AB10: J1.C17, J2.C17, J3.C17, J4.C17, J6.C17, J7.C17, J8.C17, J9.C17, J10.C17, J11.C17, J12.C17; also elsewhere on the board
/AB11: J1.C18, J2.C18, J3.C18, J4.C18, J6.C18, J7.C18, J8.C18, J9.C18, J10.C18, J11.C18, J12.C18; also elsewhere on the board
/AB12: J1.C19, J2.C19, J3.C19, J4.C19, J6.C19, J7.C19, J8.C19, J9.C19, J10.C19, J11.C19, J12.C19; also elsewhere on the board
/AB13: J1.C20, J2.C20, J3.C20, J4.C20, J6.C20, J7.C20, J8.C20, J9.C20, J10.C20, J11.C20, J12.C20; also elsewhere on the board
/AB14: J1.C21, J2.C21, J3.C21, J4.C21, J6.C21, J7.C21, J8.C21, J9.C21, J10.C21, J11.C21, J12.C21; also elsewhere on the board
/AB15: J1.C22, J2.C22, J3.C22, J4.C22, J6.C22, J7.C22, J8.C22, J9.C22, J10.C22, J11.C22, J12.C22; also elsewhere on the board
/AB16: J1.B23, J2.B23, J3.B23, J4.B23, J6.B23, J7.B23, J8.B23, J9.B23, J10.B23, J11.B23, J12.B23; also elsewhere on the board
/AB17: J1.B24, J2.B24, J3.B24, J4.B24, J6.B24, J7.B24, J8.B24, J9.B24, J10.B24, J11.B24, J12.B24; also elsewhere on the board
/AB18: J1.B25, J2.B25, J3.B25, J4.B25, J6.B25, J7.B25, J8.B25, J9.B25, J10.B25, J11.B25, J12.B25; also elsewhere on the board
/AB19: J1.B26, J2.B26, J3.B26, J4.B26, J6.B26, J7.B26, J8.B26, J9.B26, J10.B26, J11.B26, J12.B26; also elsewhere on the board
/AB20: J1.B27, J2.B27, J3.B27, J4.B27, J6.B27, J7.B27, J8.B27, J9.B27, J10.B27, J11.B27, J12.B27; also elsewhere on the board
/AB21: J1.B28, J2.B28, J3.B28, J4.B28, J6.B28, J7.B28, J8.B28, J9.B28, J10.B28, J11.B28, J12.B28; also elsewhere on the board
/AB22: J1.B29, J2.B29, J3.B29, J4.B29, J6.B29, J7.B29, J8.B29, J9.B29, J10.B29, J11.B29, J12.B29; also elsewhere on the board
/AB23: J1.B30, J2.B30, J3.B30, J4.B30, J6.B30, J7.B30, J8.B30, J9.B30, J10.B30, J11.B30, J12.B30; also elsewhere on the board
/B3: J1.B3, J2.B3, J3.B3, J4.B3, J6.B3, J7.B3, J8.B3, J9.B3, J10.B3, J11.B3, J12.B3; also elsewhere on the board
/B4: J1.B4, J2.B4, J3.B4, J4.B4, J6.B4, J7.B4, J8.B4, J9.B4, J10.B4, J11.B4, J12.B4; also elsewhere on the board
/B10: J1.B10, J2.B10, J3.B10, J4.B10, J6.B10, J7.B10, J8.B10, J9.B10, J10.B10, J11.B10, J12.B10; also elsewhere on the board
/B11: J1.B11, J2.B11, J3.B11, J4.B11, J6.B11, J7.B11, J8.B11, J9.B11, J10.B11, J11.B11, J12.B11; also elsewhere on the board
/C3: J1.C3, J2.C3, J3.C3, J4.C3, J6.C3, J7.C3, J8.C3, J9.C3, J10.C3, J11.C3, J12.C3; also elsewhere on the board
/C5: J1.C5, J2.C5, J3.C5, J4.C5, J6.C5, J7.C5, J8.C5, J9.C5, J10.C5, J11.C5, J12.C5; also elsewhere on the board
/C12: J1.C12, J2.C12, J3.C12, J4.C12, J6.C12, J7.C12, J8.C12, J9.C12, J10.C12, J11.C12, J12.C12; also elsewhere on the board
/C13: J1.C13, J2.C13, J3.C13, J4.C13, J6.C13, J7.C13, J8.C13, J9.C13, J10.C13, J11.C13, J12.C13; also elsewhere on the board
/C14: J1.C14, J2.C14, J3.C14, J4.C14, J6.C14, J7.C14, J8.C14, J9.C14, J10.C14, J11.C14, J12.C14; also elsewhere on the board
/C23: J1.C23, J2.C23, J3.C23, J4.C23, J6.C23, J7.C23, J8.C23, J9.C23, J10.C23, J11.C23, J12.C23; also elsewhere on the board
/C24: J1.C24, J2.C24, J3.C24, J4.C24, J6.C24, J7.C24, J8.C24, J9.C24, J10.C24, J11.C24, J12.C24; also elsewhere on the board
/C25: J1.C25, J2.C25, J3.C25, J4.C25, J6.C25, J7.C25, J8.C25, J9.C25, J10.C25, J11.C25, J12.C25; also elsewhere on the board
/C26: J1.C26, J2.C26, J3.C26, J4.C26, J6.C26, J7.C26, J8.C26, J9.C26, J10.C26, J11.C26, J12.C26; also elsewhere on the board
/C27: J1.C27, J2.C27, J3.C27, J4.C27, J6.C27, J7.C27, J8.C27, J9.C27, J10.C27, J11.C27, J12.C27; also elsewhere on the board
/C28: J1.C28, J2.C28, J3.C28, J4.C28, J6.C28, J7.C28, J8.C28, J9.C28, J10.C28, J11.C28, J12.C28; also elsewhere on the board
/C29: J1.C29, J2.C29, J3.C29, J4.C29, J6.C29, J7.C29, J8.C29, J9.C29, J10.C29, J11.C29, J12.C29; also elsewhere on the board
/C30: J1.C30, J2.C30, J3.C30, J4.C30, J6.C30, J7.C30, J8.C30, J9.C30, J10.C30, J11.C30, J12.C30; also elsewhere on the board
/sheet6199DFCD/A10: J1.A10, J2.A10, J3.A10, J4.A10, J6.A10, J7.A10, J8.A10, J9.A10, J10.A10, J11.A10, J12.A10; also elsewhere on the board
/sheet6199DFCD/A11: J1.A11, J2.A11, J3.A11, J4.A11, J6.A11, J7.A11, J8.A11, J9.A11, J10.A11, J11.A11, J12.A11; also elsewhere on the board
/sheet6199DFCD/B5: J1.B5, J2.B5, J3.B5, J4.B5, J6.B5, J7.B5, J8.B5, J9.B5, J10.B5, J11.B5, J12.B5; also elsewhere on the board
/sheet6199DFCD/B6: J1.B6, J2.B6, J3.B6, J4.B6, J6.B6, J7.B6, J8.B6, J9.B6, J10.B6, J11.B6, J12.B6; also elsewhere on the board
/sheet6199DFCD/B8: J1.B8, J2.B8, J3.B8, J4.B8, J6.B8, J7.B8, J8.B8, J9.B8, J10.B8, J11.B8, J12.B8; also elsewhere on the board
/sheet6199DFCD/B9: J1.B9, J2.B9, J3.B9, J4.B9, J6.B9, J7.B9, J8.B9, J9.B9, J10.B9, J11.B9, J12.B9; also elsewhere on the board
/sheet6199DFCD/B12: J1.B12, J2.B12, J3.B12, J4.B12, J6.B12, J7.B12, J8.B12, J9.B12, J10.B12, J11.B12, J12.B12; also elsewhere on the board
/sheet6199DFCD/B13: J1.B13, J2.B13, J3.B13, J4.B13, J6.B13, J7.B13, J8.B13, J9.B13, J10.B13, J11.B13, J12.B13; also elsewhere on the board
/sheet6199DFCD/B14: J1.B14, J2.B14, J3.B14, J4.B14, J6.B14, J7.B14, J8.B14, J9.B14, J10.B14, J11.B14, J12.B14; also elsewhere on the board
/sheet6199DFCD/B15: J1.B15, J2.B15, J3.B15, J4.B15, J6.B15, J7.B15, J8.B15, J9.B15, J10.B15, J11.B15, J12.B15; also elsewhere on the board
/sheet6199DFCD/B16: J1.B16, J2.B16, J3.B16, J4.B16, J6.B16, J7.B16, J8.B16, J9.B16, J10.B16, J11.B16, J12.B16; also elsewhere on the board
/sheet6199DFCD/B17: J1.B17, J2.B17, J3.B17, J4.B17, J6.B17, J7.B17, J8.B17, J9.B17, J10.B17, J11.B17, J12.B17; also elsewhere on the board
/sheet6199DFCD/B18: J1.B18, J2.B18, J3.B18, J4.B18, J6.B18, J7.B18, J8.B18, J9.B18, J10.B18, J11.B18, J12.B18; also elsewhere on the board
/sheet6199DFCD/B19: J1.B19, J2.B19, J3.B19, J4.B19, J6.B19, J7.B19, J8.B19, J9.B19, J10.B19, J11.B19, J12.B19; also elsewhere on the board
/sheet6199DFCD/B20: J1.B20, J2.B20, J3.B20, J4.B20, J6.B20, J7.B20, J8.B20, J9.B20, J10.B20, J11.B20, J12.B20; also elsewhere on the board
/sheet6199DFCD/B21: J1.B21, J2.B21, J3.B21, J4.B21, J6.B21, J7.B21, J8.B21, J9.B21, J10.B21, J11.B21, J12.B21; also elsewhere on the board
/sheet6199DFCD/B22: J1.B22, J2.B22, J3.B22, J4.B22, J6.B22, J7.B22, J8.B22, J9.B22, J10.B22, J11.B22, J12.B22; also elsewhere on the board
GND: H3.1, H4.1, H5.1, H6.1, H7.1, H8.1, H9.1, H10.1, H11.1, H12.1, H13.1, H14.1, H15.1, H16.1, H17.1, H18.1, H19.1, H20.1, H21.1, H22.1, H23.1, H24.1, J1.A31, J1.A32, J1.B31, J1.B32, J1.C31, J1.C32, J2.A31, J2.A32, J2.B31, J2.B32, J2.C31, J2.C32, J3.A31, J3.A32, J3.B31, J3.B32, J3.C31, J3.C32, J4.A31, J4.A32, J4.B31, J4.B32, J4.C31, J4.C32, J6.A31, J6.A32, J6.B31, J6.B32, J6.C31, J6.C32, J7.A31, J7.A32, J7.B31, J7.B32, J7.C31, J7.C32, J8.A31, J8.A32, J8.B31, J8.B32, J8.C31, J8.C32, J9.A31, J9.A32, J9.B31, J9.B32, J9.C31, J9.C32, J10.A31, J10.A32, J10.B31, J10.B32, J10.C31, J10.C32, J11.A31, J11.A32, J11.B31, J11.B32, J11.C31, J11.C32, J12.A31, J12.A32, J12.B31, J12.B32, J12.C31, J12.C32; also elsewhere on the board

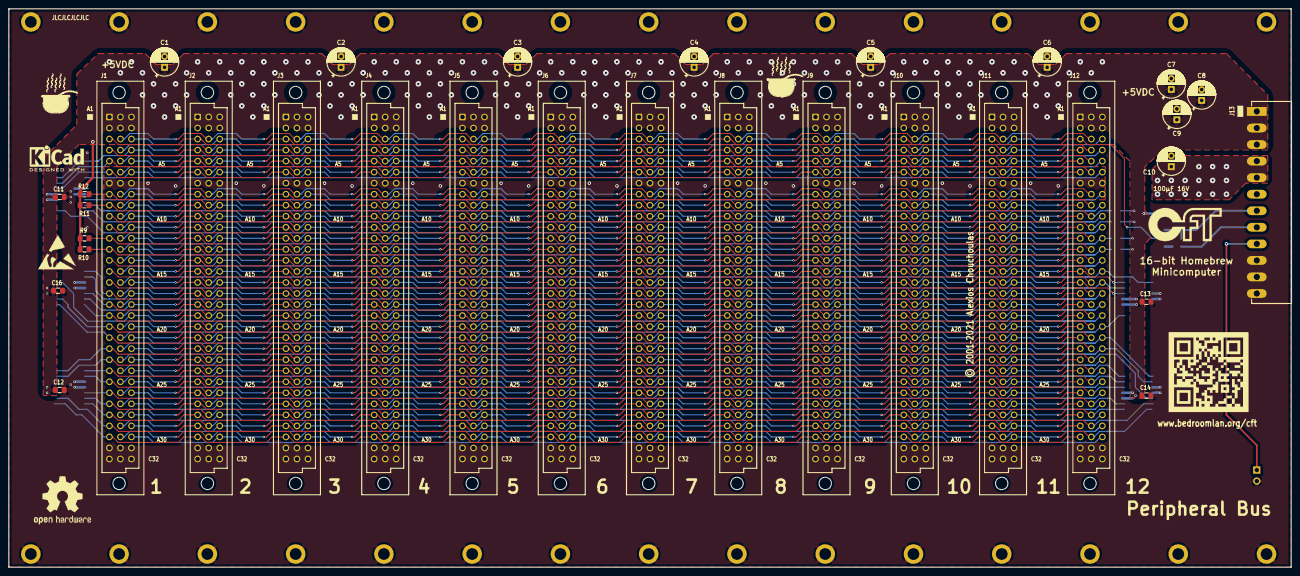
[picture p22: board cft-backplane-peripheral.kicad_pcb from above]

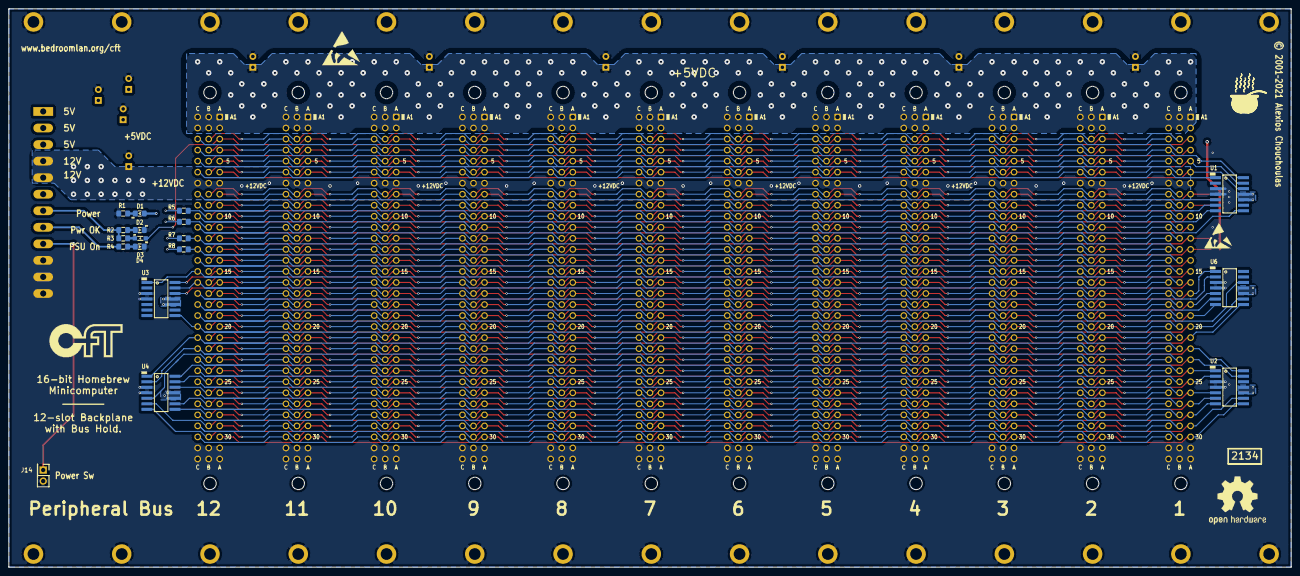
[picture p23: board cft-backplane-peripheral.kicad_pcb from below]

Board: 2 copper layers, 295.2 x 128.6 mm, 80 parts (18 on the bottom side), 91 nets.

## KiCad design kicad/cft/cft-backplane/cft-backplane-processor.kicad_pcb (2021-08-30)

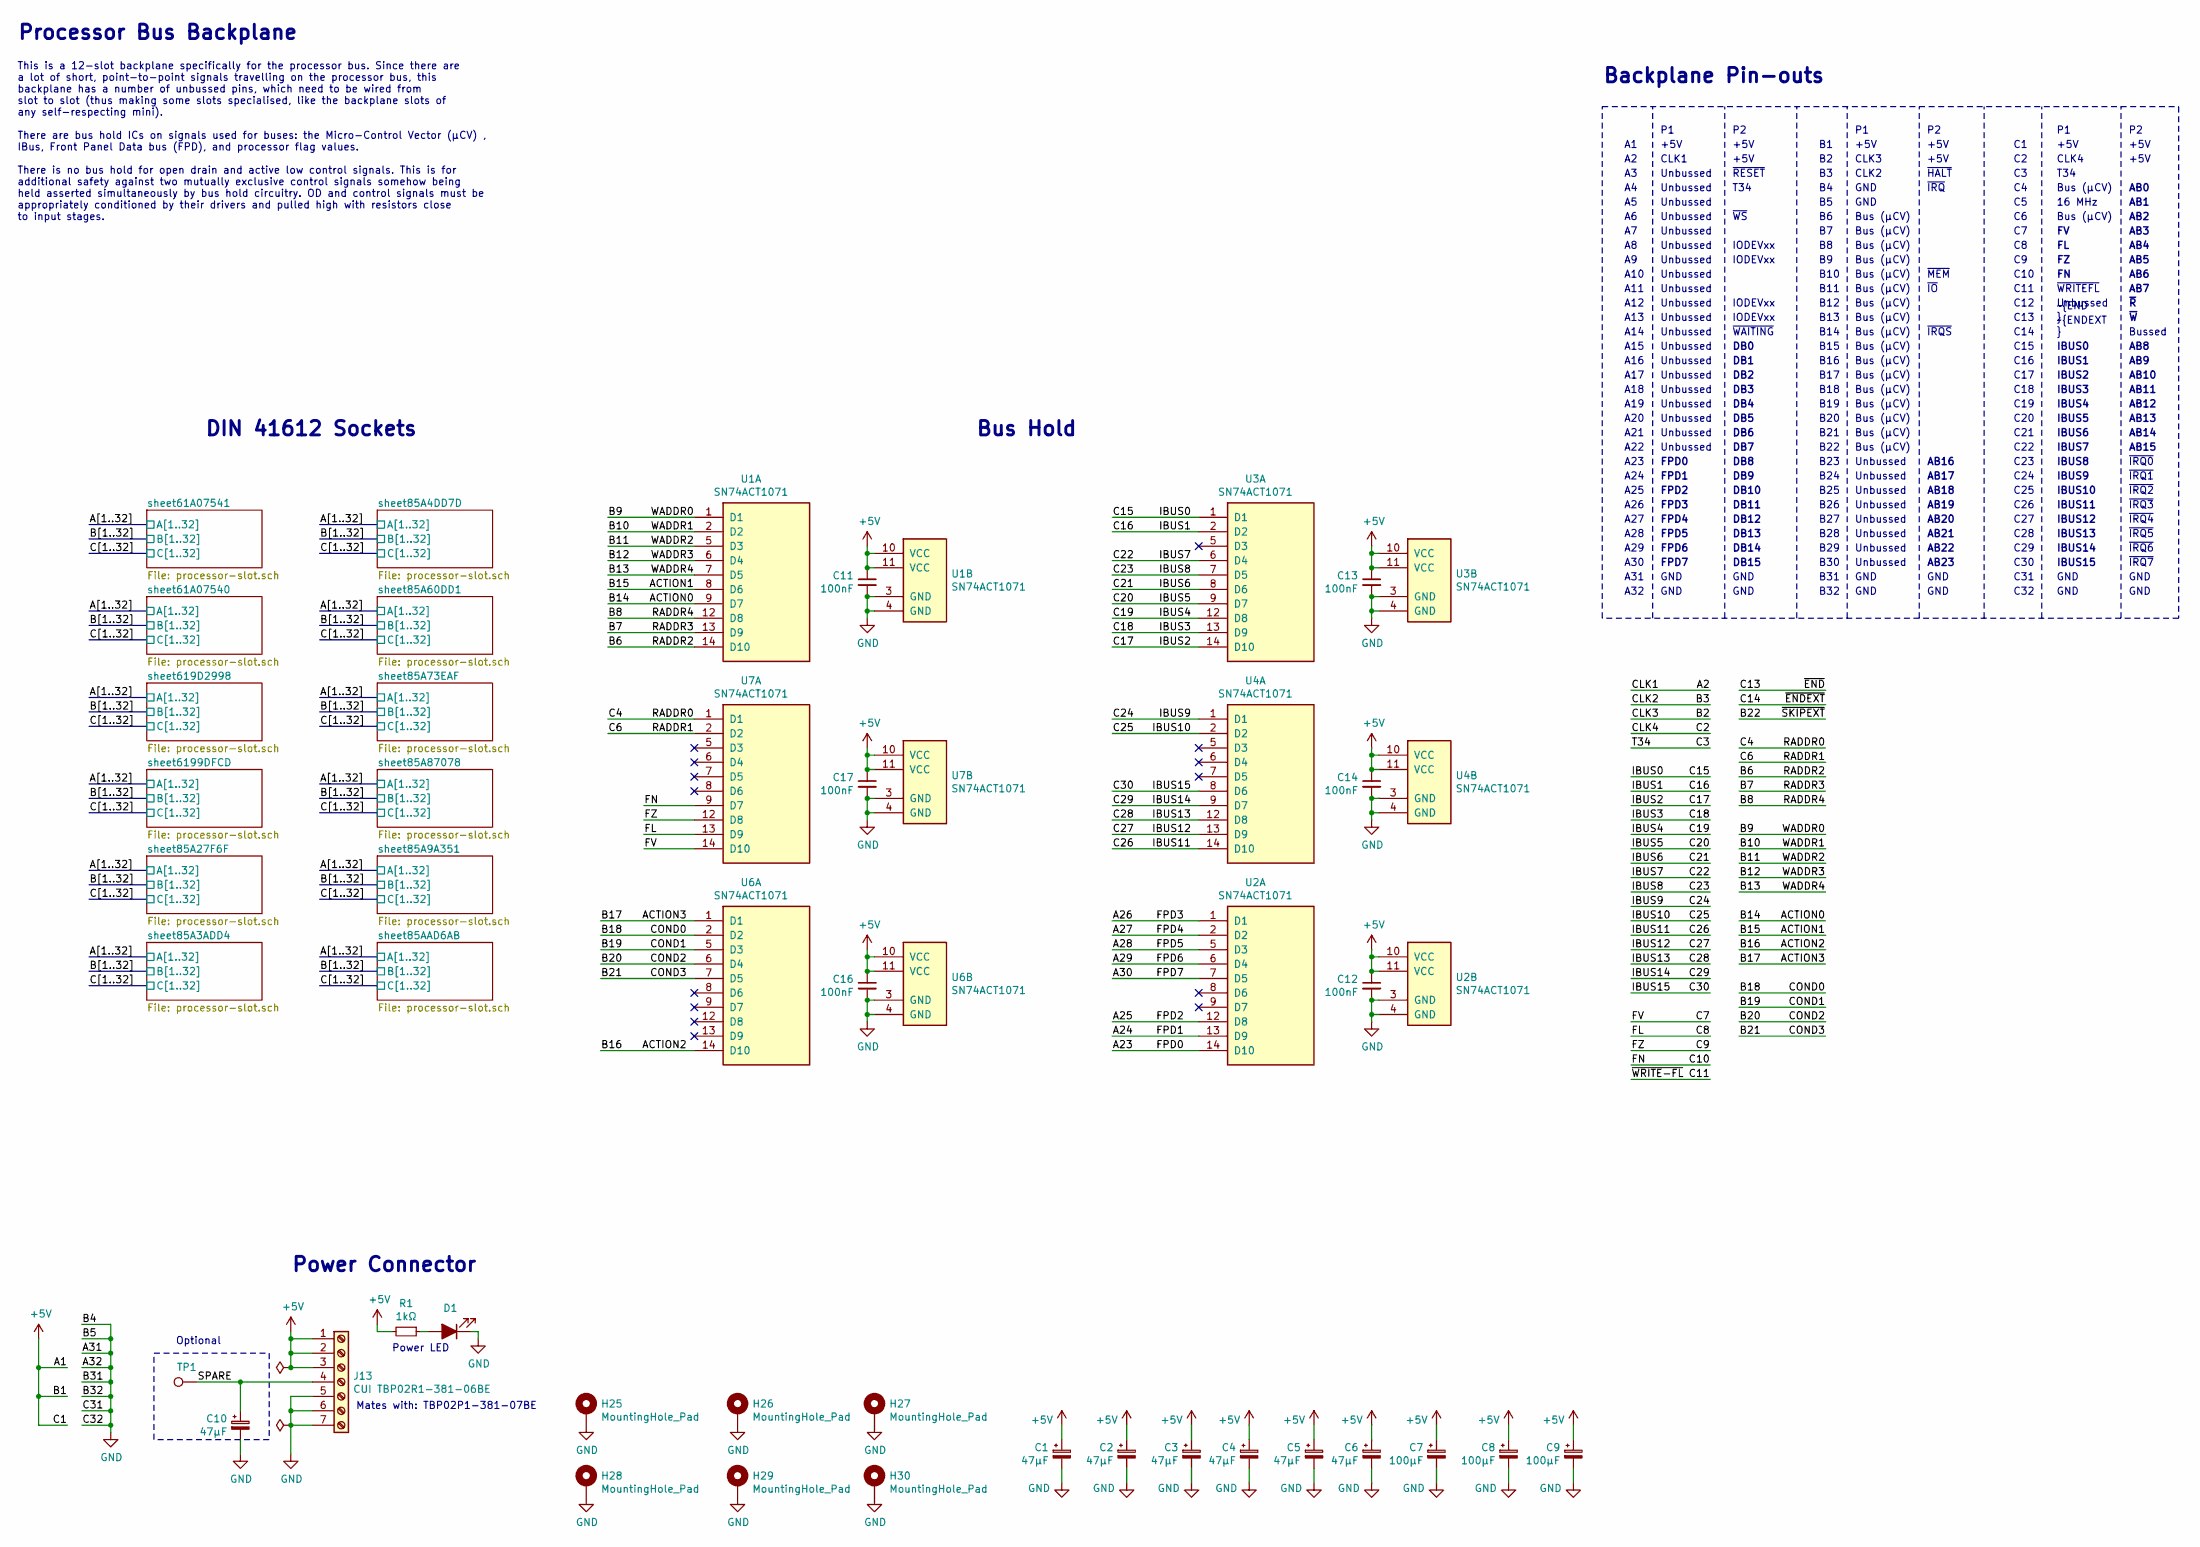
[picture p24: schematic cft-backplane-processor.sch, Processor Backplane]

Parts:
C1, C2, C3, C4, C5, C6, C10: 47µF; CP_Radial_D6.3mm_P2.50mm
C7, C8, C9: 100µF; CP_Radial_D6.3mm_P2.50mm
C11, C12, C13, C14, C16, C17: 100nF; C_SMD_0805_2012Metric_Pad1.15x1.40mm_HandSolder
D1: LED_ALT; LED_0805_2012Metric_Pad1.15x1.40mm_HandSolder
H25, H26, H27, H28, H29, H30: MountingHole_Pad; MountingHole_2.7mm_M2.5_ISO14580_Pad
J13: CUI TBP02R1-381-06BE; CUI-TBP02R1-381-07BE
R1: 1kΩ; R_SMD_0805_2012Metric_Pad1.15x1.40mm_HandSolder
TP1: TestPoint; TestPoint_THTPad_2.0x2.0mm_Drill1.0mm
U1, U2, U3, U4, U6, U7: SN74ACT1071; SOIC-14

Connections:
+5V: C1.1, C2.1, C3.1, C4.1, C5.1, C6.1, C7.1, C8.1, C9.1, C11.1, C12.1, C13.1, C14.1, C16.1, C17.1, J13.1, J13.2, J13.3, R1.2, U1.10 (VCC), U1.11 (VCC), U2.10 (VCC), U2.11 (VCC), U3.10 (VCC), U3.11 (VCC), U4.10 (VCC), U4.11 (VCC), U6.10 (VCC), U6.11 (VCC), U7.10 (VCC), U7.11 (VCC); also elsewhere on the board
/A23: U2.14 (D10); also elsewhere on the board
/A24: U2.13 (D9); also elsewhere on the board
/A25: U2.12 (D8); also elsewhere on the board
/A26: U2.1 (D1); also elsewhere on the board
/A27: U2.2 (D2); also elsewhere on the board
/A28: U2.5 (D3); also elsewhere on the board
/A29: U2.6 (D4); also elsewhere on the board
/A30: U2.7 (D5); also elsewhere on the board
/ACTION0: U1.9 (D7); also elsewhere on the board
/ACTION1: U1.8 (D6); also elsewhere on the board
/ACTION2: U6.14 (D10); also elsewhere on the board
/ACTION3: U6.1 (D1); also elsewhere on the board
/B6: U1.14 (D10); also elsewhere on the board
/B7: U1.13 (D9); also elsewhere on the board
/B8: U1.12 (D8); also elsewhere on the board
/B9: U1.1 (D1); also elsewhere on the board
/B10: U1.2 (D2); also elsewhere on the board
/B11: U1.5 (D3); also elsewhere on the board
/B12: U1.6 (D4); also elsewhere on the board
/B13: U1.7 (D5); also elsewhere on the board
/B18: U6.2 (D2); also elsewhere on the board
/B19: U6.5 (D3); also elsewhere on the board
/B20: U6.6 (D4); also elsewhere on the board
/B21: U6.7 (D5); also elsewhere on the board
/C4: U7.1 (D1); also elsewhere on the board
/C6: U7.2 (D2); also elsewhere on the board
/C7: U7.14 (D10); also elsewhere on the board
/C8: U7.13 (D9); also elsewhere on the board
/C9: U7.12 (D8); also elsewhere on the board
/C10: U7.9 (D7); also elsewhere on the board
/C15: U3.1 (D1); also elsewhere on the board
/C16: U3.2 (D2); also elsewhere on the board
/C17: U3.14 (D10); also elsewhere on the board
/C18: U3.13 (D9); also elsewhere on the board
/C19: U3.12 (D8); also elsewhere on the board
/C20: U3.9 (D7); also elsewhere on the board
/C21: U3.8 (D6); also elsewhere on the board
/C22: U3.6 (D4); also elsewhere on the board
/C23: U3.7 (D5); also elsewhere on the board
/C24: U4.1 (D1); also elsewhere on the board
/C25: U4.2 (D2); also elsewhere on the board
/C26: U4.14 (D10); also elsewhere on the board
/C27: U4.13 (D9); also elsewhere on the board
/C28: U4.12 (D8); also elsewhere on the board
/C29: U4.9 (D7); also elsewhere on the board
/C30: U4.8 (D6); also elsewhere on the board
/SPARE: C10.1, J13.4, TP1.1
GND: C1.2, C2.2, C3.2, C4.2, C5.2, C6.2, C7.2, C8.2, C9.2, C10.2, C11.2, C12.2, C13.2, C14.2, C16.2, C17.2, D1.1 (K), H25.1, H26.1, H27.1, H28.1, H29.1, H30.1, J13.5, J13.6, J13.7, U1.3 (GND), U1.4 (GND), U2.3 (GND), U2.4 (GND), U3.3 (GND), U3.4 (GND), U4.3 (GND), U4.4 (GND), U6.3 (GND), U6.4 (GND), U7.3 (GND), U7.4 (GND); also elsewhere on the board
unnamed: D1.2 (A), R1.1

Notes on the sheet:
Processor Bus Backplane
This is a 12-slot backplane specifically for the processor bus. Since there are a lot of short, point-to-point signals travelling on the processor bus, this backplane has a number of unbussed pins, which need to be wired from slot to slot (thus making some slots specialised, like the backplane slot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
A10
A11
A12
A13
A14
A17
A18
A19
A20
A21
A22
A23
A24
A25
A26
A27
A28
A29
A30
A31
A32
C32
C31
C30
C29
C28
C27
C26
C25
C24
C23
C22
C21
C20
C19
C18
C17
C16

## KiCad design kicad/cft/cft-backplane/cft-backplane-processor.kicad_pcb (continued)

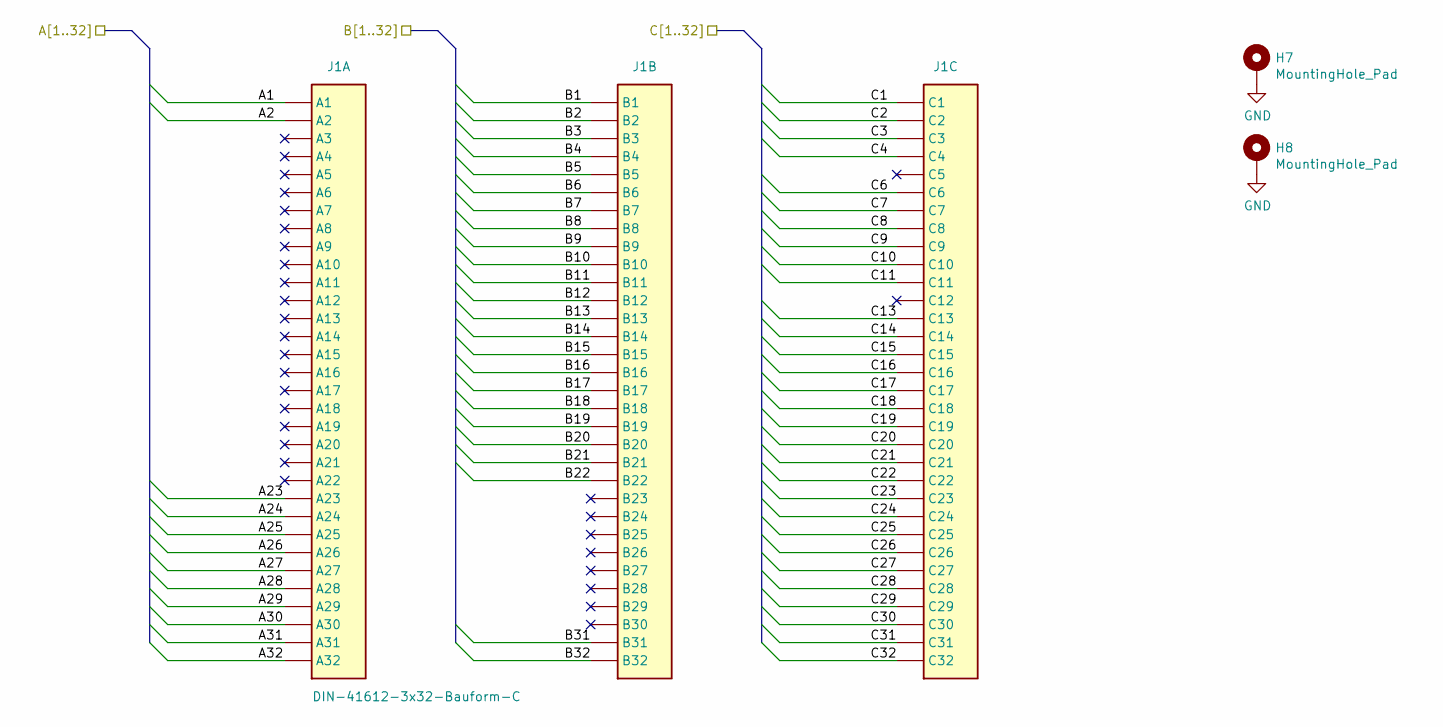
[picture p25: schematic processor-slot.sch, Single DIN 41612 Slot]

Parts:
H1, H2: MountingHole_Pad; MountingHole_2.7mm_M2.5_ISO14580_Pad
J5: DIN-41612-3x32-Bauform-C; DIN41612_C_3x32_Female_Vertical_THT

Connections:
+5V: J5.A1, J5.B1, J5.C1; also elsewhere on the board
/A2: J5.A2; also elsewhere on the board
/A23: J5.A23; also elsewhere on the board
/A24: J5.A24; also elsewhere on the board
/A25: J5.A25; also elsewhere on the board
/A26: J5.A26; also elsewhere on the board
/A27: J5.A27; also elsewhere on the board
/A28: J5.A28; also elsewhere on the board
/A29: J5.A29; also elsewhere on the board
/A30: J5.A30; also elsewhere on the board
/ACTION0: J5.B14; also elsewhere on the board
/ACTION1: J5.B15; also elsewhere on the board
/ACTION2: J5.B16; also elsewhere on the board
/ACTION3: J5.B17; also elsewhere on the board
/B2: J5.B2; also elsewhere on the board
/B3: J5.B3; also elsewhere on the board
/B6: J5.B6; also elsewhere on the board
/B7: J5.B7; also elsewhere on the board
/B8: J5.B8; also elsewhere on the board
/B9: J5.B9; also elsewhere on the board
/B10: J5.B10; also elsewhere on the board
/B11: J5.B11; also elsewhere on the board
/B12: J5.B12; also elsewhere on the board
/B13: J5.B13; also elsewhere on the board
/B18: J5.B18; also elsewhere on the board
/B19: J5.B19; also elsewhere on the board
/B20: J5.B20; also elsewhere on the board
/B21: J5.B21; also elsewhere on the board
/B22: J5.B22; also elsewhere on the board
/C2: J5.C2; also elsewhere on the board
/C3: J5.C3; also elsewhere on the board
/C4: J5.C4; also elsewhere on the board
/C6: J5.C6; also elsewhere on the board
/C7: J5.C7; also elsewhere on the board
/C8: J5.C8; also elsewhere on the board
/C9: J5.C9; also elsewhere on the board
/C10: J5.C10; also elsewhere on the board
/C11: J5.C11; also elsewhere on the board
/C13: J5.C13; also elsewhere on the board
/C14: J5.C14; also elsewhere on the board
/C15: J5.C15; also elsewhere on the board
/C16: J5.C16; also elsewhere on the board
/C17: J5.C17; also elsewhere on the board
/C18: J5.C18; also elsewhere on the board
/C19: J5.C19; also elsewhere on the board
/C20: J5.C20; also elsewhere on the board
/C21: J5.C21; also elsewhere on the board
/C22: J5.C22; also elsewhere on the board
/C23: J5.C23; also elsewhere on the board
/C24: J5.C24; also elsewhere on the board
/C25: J5.C25; also elsewhere on the board
/C26: J5.C26; also elsewhere on the board
/C27: J5.C27; also elsewhere on the board
/C28: J5.C28; also elsewhere on the board
/C29: J5.C29; also elsewhere on the board
/C30: J5.C30; also elsewhere on the board
GND: H1.1, H2.1, J5.A31, J5.A32, J5.B4, J5.B5, J5.B31, J5.B32, J5.C31, J5.C32; also elsewhere on the board

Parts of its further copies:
H3, H4, H5, H6, H7, H8, H9, H10, H11, H12, H13, H14, H15, H16, H17, H18, H19, H20, H21, H22, H23, H24: MountingHole_Pad; MountingHole_2.7mm_M2.5_ISO14580_Pad
J1, J2, J3, J4, J6, J7, J8, J9, J10, J11, J12: DIN-41612-3x32-Bauform-C; DIN41612_C_3x32_Female_Vertical_THT

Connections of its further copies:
+5V: J1.A1, J1.B1, J1.C1, J2.A1, J2.B1, J2.C1, J3.A1, J3.B1, J3.C1, J4.A1, J4.B1, J4.C1, J6.A1, J6.B1, J6.C1, J7.A1, J7.B1, J7.C1, J8.A1, J8.B1, J8.C1, J9.A1, J9.B1, J9.C1, J10.A1, J10.B1, J10.C1, J11.A1, J11.B1, J11.C1, J12.A1, J12.B1, J12.C1; also elsewhere on the board
/A2: J1.A2, J2.A2, J3.A2, J4.A2, J6.A2, J7.A2, J8.A2, J9.A2, J10.A2, J11.A2, J12.A2; also elsewhere on the board
/A23: J1.A23, J2.A23, J3.A23, J4.A23, J6.A23, J7.A23, J8.A23, J9.A23, J10.A23, J11.A23, J12.A23; also elsewhere on the board
/A24: J1.A24, J2.A24, J3.A24, J4.A24, J6.A24, J7.A24, J8.A24, J9.A24, J10.A24, J11.A24, J12.A24; also elsewhere on the board
/A25: J1.A25, J2.A25, J3.A25, J4.A25, J6.A25, J7.A25, J8.A25, J9.A25, J10.A25, J11.A25, J12.A25; also elsewhere on the board
/A26: J1.A26, J2.A26, J3.A26, J4.A26, J6.A26, J7.A26, J8.A26, J9.A26, J10.A26, J11.A26, J12.A26; also elsewhere on the board
/A27: J1.A27, J2.A27, J3.A27, J4.A27, J6.A27, J7.A27, J8.A27, J9.A27, J10.A27, J11.A27, J12.A27; also elsewhere on the board
/A28: J1.A28, J2.A28, J3.A28, J4.A28, J6.A28, J7.A28, J8.A28, J9.A28, J10.A28, J11.A28, J12.A28; also elsewhere on the board
/A29: J1.A29, J2.A29, J3.A29, J4.A29, J6.A29, J7.A29, J8.A29, J9.A29, J10.A29, J11.A29, J12.A29; also elsewhere on the board
/A30: J1.A30, J2.A30, J3.A30, J4.A30, J6.A30, J7.A30, J8.A30, J9.A30, J10.A30, J11.A30, J12.A30; also elsewhere on the board
/ACTION0: J1.B14, J2.B14, J3.B14, J4.B14, J6.B14, J7.B14, J8.B14, J9.B14, J10.B14, J11.B14, J12.B14; also elsewhere on the board
/ACTION1: J1.B15, J2.B15, J3.B15, J4.B15, J6.B15, J7.B15, J8.B15, J9.B15, J10.B15, J11.B15, J12.B15; also elsewhere on the board
/ACTION2: J1.B16, J2.B16, J3.B16, J4.B16, J6.B16, J7.B16, J8.B16, J9.B16, J10.B16, J11.B16, J12.B16; also elsewhere on the board
/ACTION3: J1.B17, J2.B17, J3.B17, J4.B17, J6.B17, J7.B17, J8.B17, J9.B17, J10.B17, J11.B17, J12.B17; also elsewhere on the board
/B2: J1.B2, J2.B2, J3.B2, J4.B2, J6.B2, J7.B2, J8.B2, J9.B2, J10.B2, J11.B2, J12.B2; also elsewhere on the board
/B3: J1.B3, J2.B3, J3.B3, J4.B3, J6.B3, J7.B3, J8.B3, J9.B3, J10.B3, J11.B3, J12.B3; also elsewhere on the board
/B6: J1.B6, J2.B6, J3.B6, J4.B6, J6.B6, J7.B6, J8.B6, J9.B6, J10.B6, J11.B6, J12.B6; also elsewhere on the board
/B7: J1.B7, J2.B7, J3.B7, J4.B7, J6.B7, J7.B7, J8.B7, J9.B7, J10.B7, J11.B7, J12.B7; also elsewhere on the board
/B8: J1.B8, J2.B8, J3.B8, J4.B8, J6.B8, J7.B8, J8.B8, J9.B8, J10.B8, J11.B8, J12.B8; also elsewhere on the board
/B9: J1.B9, J2.B9, J3.B9, J4.B9, J6.B9, J7.B9, J8.B9, J9.B9, J10.B9, J11.B9, J12.B9; also elsewhere on the board
/B10: J1.B10, J2.B10, J3.B10, J4.B10, J6.B10, J7.B10, J8.B10, J9.B10, J10.B10, J11.B10, J12.B10; also elsewhere on the board
/B11: J1.B11, J2.B11, J3.B11, J4.B11, J6.B11, J7.B11, J8.B11, J9.B11, J10.B11, J11.B11, J12.B11; also elsewhere on the board
/B12: J1.B12, J2.B12, J3.B12, J4.B12, J6.B12, J7.B12, J8.B12, J9.B12, J10.B12, J11.B12, J12.B12; also elsewhere on the board
/B13: J1.B13, J2.B13, J3.B13, J4.B13, J6.B13, J7.B13, J8.B13, J9.B13, J10.B13, J11.B13, J12.B13; also elsewhere on the board
/B18: J1.B18, J2.B18, J3.B18, J4.B18, J6.B18, J7.B18, J8.B18, J9.B18, J10.B18, J11.B18, J12.B18; also elsewhere on the board
/B19: J1.B19, J2.B19, J3.B19, J4.B19, J6.B19, J7.B19, J8.B19, J9.B19, J10.B19, J11.B19, J12.B19; also elsewhere on the board
/B20: J1.B20, J2.B20, J3.B20, J4.B20, J6.B20, J7.B20, J8.B20, J9.B20, J10.B20, J11.B20, J12.B20; also elsewhere on the board
/B21: J1.B21, J2.B21, J3.B21, J4.B21, J6.B21, J7.B21, J8.B21, J9.B21, J10.B21, J11.B21, J12.B21; also elsewhere on the board
/B22: J1.B22, J2.B22, J3.B22, J4.B22, J6.B22, J7.B22, J8.B22, J9.B22, J10.B22, J11.B22, J12.B22; also elsewhere on the board
/C2: J1.C2, J2.C2, J3.C2, J4.C2, J6.C2, J7.C2, J8.C2, J9.C2, J10.C2, J11.C2, J12.C2; also elsewhere on the board
/C3: J1.C3, J2.C3, J3.C3, J4.C3, J6.C3, J7.C3, J8.C3, J9.C3, J10.C3, J11.C3, J12.C3; also elsewhere on the board
/C4: J1.C4, J2.C4, J3.C4, J4.C4, J6.C4, J7.C4, J8.C4, J9.C4, J10.C4, J11.C4, J12.C4; also elsewhere on the board
/C6: J1.C6, J2.C6, J3.C6, J4.C6, J6.C6, J7.C6, J8.C6, J9.C6, J10.C6, J11.C6, J12.C6; also elsewhere on the board
/C7: J1.C7, J2.C7, J3.C7, J4.C7, J6.C7, J7.C7, J8.C7, J9.C7, J10.C7, J11.C7, J12.C7; also elsewhere on the board
/C8: J1.C8, J2.C8, J3.C8, J4.C8, J6.C8, J7.C8, J8.C8, J9.C8, J10.C8, J11.C8, J12.C8; also elsewhere on the board
/C9: J1.C9, J2.C9, J3.C9, J4.C9, J6.C9, J7.C9, J8.C9, J9.C9, J10.C9, J11.C9, J12.C9; also elsewhere on the board
/C10: J1.C10, J2.C10, J3.C10, J4.C10, J6.C10, J7.C10, J8.C10, J9.C10, J10.C10, J11.C10, J12.C10; also elsewhere on the board
/C11: J1.C11, J2.C11, J3.C11, J4.C11, J6.C11, J7.C11, J8.C11, J9.C11, J10.C11, J11.C11, J12.C11; also elsewhere on the board
/C13: J1.C13, J2.C13, J3.C13, J4.C13, J6.C13, J7.C13, J8.C13, J9.C13, J10.C13, J11.C13, J12.C13; also elsewhere on the board
/C14: J1.C14, J2.C14, J3.C14, J4.C14, J6.C14, J7.C14, J8.C14, J9.C14, J10.C14, J11.C14, J12.C14; also elsewhere on the board
/C15: J1.C15, J2.C15, J3.C15, J4.C15, J6.C15, J7.C15, J8.C15, J9.C15, J10.C15, J11.C15, J12.C15; also elsewhere on the board
/C16: J1.C16, J2.C16, J3.C16, J4.C16, J6.C16, J7.C16, J8.C16, J9.C16, J10.C16, J11.C16, J12.C16; also elsewhere on the board
/C17: J1.C17, J2.C17, J3.C17, J4.C17, J6.C17, J7.C17, J8.C17, J9.C17, J10.C17, J11.C17, J12.C17; also elsewhere on the board
/C18: J1.C18, J2.C18, J3.C18, J4.C18, J6.C18, J7.C18, J8.C18, J9.C18, J10.C18, J11.C18, J12.C18; also elsewhere on the board
/C19: J1.C19, J2.C19, J3.C19, J4.C19, J6.C19, J7.C19, J8.C19, J9.C19, J10.C19, J11.C19, J12.C19; also elsewhere on the board
/C20: J1.C20, J2.C20, J3.C20, J4.C20, J6.C20, J7.C20, J8.C20, J9.C20, J10.C20, J11.C20, J12.C20; also elsewhere on the board
/C21: J1.C21, J2.C21, J3.C21, J4.C21, J6.C21, J7.C21, J8.C21, J9.C21, J10.C21, J11.C21, J12.C21; also elsewhere on the board
/C22: J1.C22, J2.C22, J3.C22, J4.C22, J6.C22, J7.C22, J8.C22, J9.C22, J10.C22, J11.C22, J12.C22; also elsewhere on the board
/C23: J1.C23, J2.C23, J3.C23, J4.C23, J6.C23, J7.C23, J8.C23, J9.C23, J10.C23, J11.C23, J12.C23; also elsewhere on the board
/C24: J1.C24, J2.C24, J3.C24, J4.C24, J6.C24, J7.C24, J8.C24, J9.C24, J10.C24, J11.C24, J12.C24; also elsewhere on the board
/C25: J1.C25, J2.C25, J3.C25, J4.C25, J6.C25, J7.C25, J8.C25, J9.C25, J10.C25, J11.C25, J12.C25; also elsewhere on the board
/C26: J1.C26, J2.C26, J3.C26, J4.C26, J6.C26, J7.C26, J8.C26, J9.C26, J10.C26, J11.C26, J12.C26; also elsewhere on the board
/C27: J1.C27, J2.C27, J3.C27, J4.C27, J6.C27, J7.C27, J8.C27, J9.C27, J10.C27, J11.C27, J12.C27; also elsewhere on the board
/C28: J1.C28, J2.C28, J3.C28, J4.C28, J6.C28, J7.C28, J8.C28, J9.C28, J10.C28, J11.C28, J12.C28; also elsewhere on the board
/C29: J1.C29, J2.C29, J3.C29, J4.C29, J6.C29, J7.C29, J8.C29, J9.C29, J10.C29, J11.C29, J12.C29; also elsewhere on the board
/C30: J1.C30, J2.C30, J3.C30, J4.C30, J6.C30, J7.C30, J8.C30, J9.C30, J10.C30, J11.C30, J12.C30; also elsewhere on the board
GND: H3.1, H4.1, H5.1, H6.1, H7.1, H8.1, H9.1, H10.1, H11.1, H12.1, H13.1, H14.1, H15.1, H16.1, H17.1, H18.1, H19.1, H20.1, H21.1, H22.1, H23.1, H24.1, J1.A31, J1.A32, J1.B4, J1.B5, J1.B31, J1.B32, J1.C31, J1.C32, J2.A31, J2.A32, J2.B4, J2.B5, J2.B31, J2.B32, J2.C31, J2.C32, J3.A31, J3.A32, J3.B4, J3.B5, J3.B31, J3.B32, J3.C31, J3.C32, J4.A31, J4.A32, J4.B4, J4.B5, J4.B31, J4.B32, J4.C31, J4.C32, J6.A31, J6.A32, J6.B4, J6.B5, J6.B31, J6.B32, J6.C31, J6.C32, J7.A31, J7.A32, J7.B4, J7.B5, J7.B31, J7.B32, J7.C31, J7.C32, J8.A31, J8.A32, J8.B4, J8.B5, J8.B31, J8.B32, J8.C31, J8.C32, J9.A31, J9.A32, J9.B4, J9.B5, J9.B31, J9.B32, J9.C31, J9.C32, J10.A31, J10.A32, J10.B4, J10.B5, J10.B31, J10.B32, J10.C31, J10.C32, J11.A31, J11.A32, J11.B4, J11.B5, J11.B31, J11.B32, J11.C31, J11.C32, J12.A31, J12.A32, J12.B4, J12.B5, J12.B31, J12.B32, J12.C31, J12.C32; also elsewhere on the board

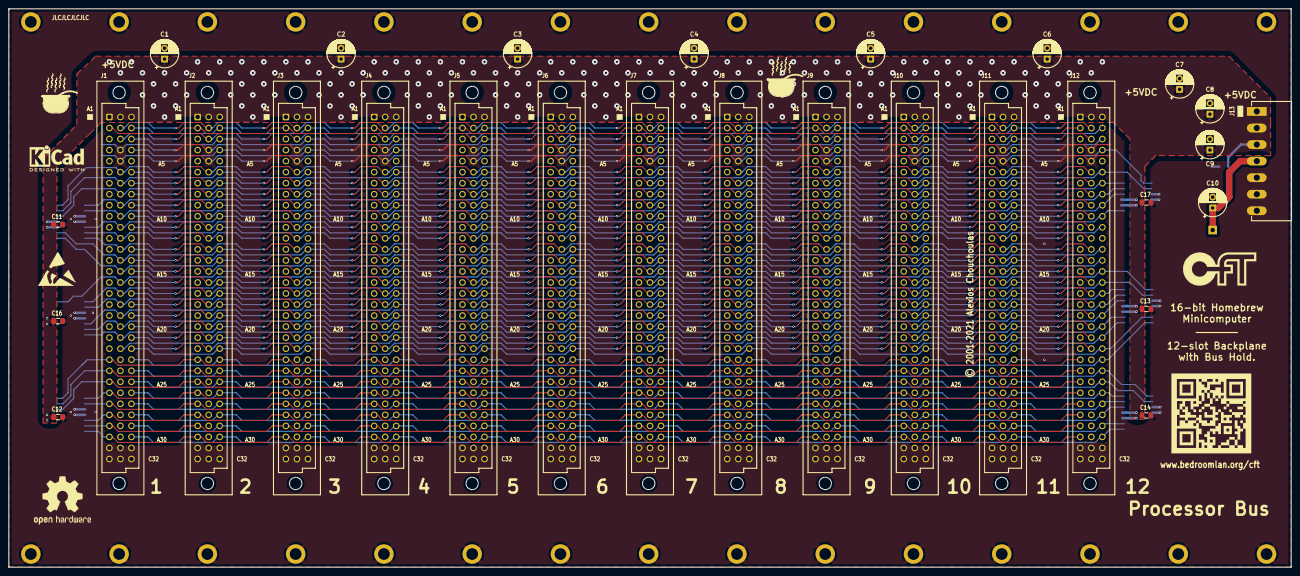
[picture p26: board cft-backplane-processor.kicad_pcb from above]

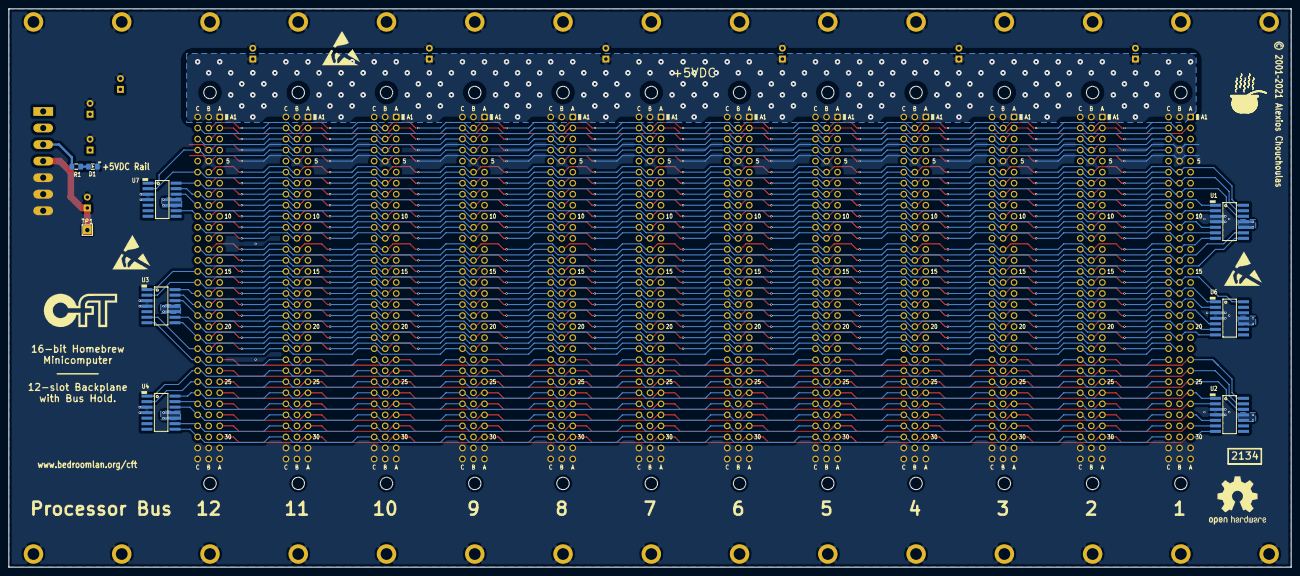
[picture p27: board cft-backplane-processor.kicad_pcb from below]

Board: 2 copper layers, 295.2 x 128.6 mm, 68 parts (9 on the bottom side), 59 nets.

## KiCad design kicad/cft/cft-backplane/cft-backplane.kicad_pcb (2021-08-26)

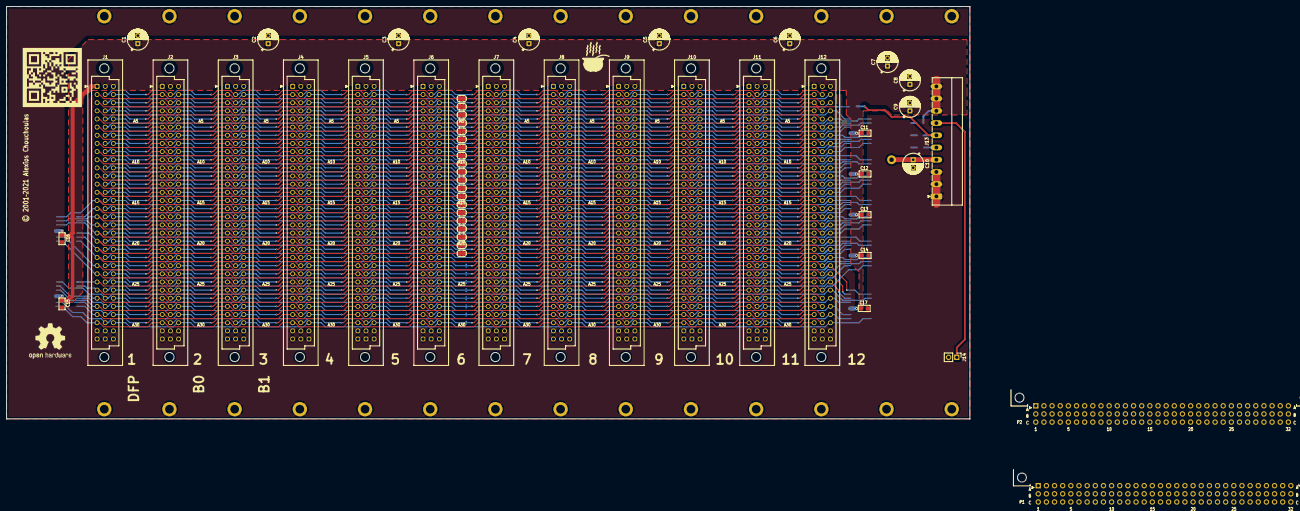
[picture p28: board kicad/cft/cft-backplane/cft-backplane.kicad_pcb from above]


Board: 2 copper layers, 300.3 x 128.6 mm, 76 parts (15 on the bottom side), 97 nets.

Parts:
C1, C2, C3, C4, C5, C6, C7, C8, C9, C10: 47µF; CP_Radial_D6.3mm_P2.50mm
C11, C12, C13, C14, C15, C16, C17: 100nF; C_SMD_0805_2012Metric_Pad1.15x1.40mm_HandSolder
D1, D2, D3: LED_ALT; LED_0805_2012Metric_Pad1.15x1.40mm_HandSolder
D4: D_Schottky_ALT; SOD-323
H1, H2, H3, H4, H5, H6, H7, H8, H9, H10, H11, H12, H13, H14, H15, H16, H17, H18, H19, H20, H21, H22, H23, H23#2, H23#3, H24, H24#2, H24#3: MountingHole_Pad; MountingHole_2.7mm_M2.5_ISO14580_Pad
J1, J2, J3, J4, J5, J6, J7, J8, J9, J10, J11, J12: DIN-41612-3x32-Bauform-C; DIN41612_C_3x32_Female_Vertical_THT
J13: Phoenix 1766204; PhoenixContact_MC_1,5_10-G-3.81_1x10_P3.81mm_Horizontal
J14: Conn_01x02; PinHeader_1x02_P2.54mm_Vertical
P1: CFT-2021-Processor-Bus; DIN41612_B_3x32_Horizontal
P2: CFT-2021-Peripheral-Bus; DIN41612_B_3x32_Horizontal
R1, R2, R3: 1kΩ; R_SMD_0805_2012Metric_Pad1.15x1.40mm_HandSolder
TP1: TestPoint; TestPoint_Loop_D3.50mm_Drill1.4mm_Beaded
U1, U2, U3, U4, U5, U6, U7: SN74ACT1071; SOIC-14

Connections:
+5V: C1.1, C2.1, C3.1, C4.1, C5.1, C6.1, C7.1, C8.1, C9.1, C11.1, C12.1, C13.1, C14.1, C15.1, C16.1, C17.1, J1.A1, J1.B1, J1.C1, J2.A1, J2.B1, J2.C1, J3.A1, J3.B1, J3.C1, J4.A1, J4.B1, J4.C1, J5.A1, J5.B1, J5.C1, J6.A1, J6.B1, J6.C1, J7.A1, J7.B1, J7.C1, J8.A1, J8.B1, J8.C1, J9.A1, J9.B1, J9.C1, J10.A1, J10.B1, J10.C1, J11.A1, J11.B1, J11.C1, J12.A1, J12.B1, J12.C1, J13.8, J13.9, J13.10, P1.A1, P1.B1, P1.C1, P2.A1, P2.A2, P2.B1, P2.B2, P2.C1, P2.C2, R1.2, U1.10, U1.11, U2.10, U2.11, U3.10, U3.11, U4.10, U4.11, U5.10, U5.11, U6.10, U6.11, U7.10, U7.11
/A3: D4.1, J1.A3, J2.A3, J3.A3, J4.A3, J5.A3, J6.A3, J7.A3, J8.A3, J9.A3, J10.A3, J11.A3, J12.A3
/A15: J1.A15, J2.A15, J3.A15, J4.A15, J5.A15, J6.A15, J7.A15, J8.A15, J9.A15, J10.A15, J11.A15, J12.A15, U7.14
/A16: J1.A16, J2.A16, J3.A16, J4.A16, J5.A16, J6.A16, J7.A16, J8.A16, J9.A16, J10.A16, J11.A16, J12.A16, U7.1
/A17: J1.A17, J2.A17, J3.A17, J4.A17, J5.A17, J6.A17, J7.A17, J8.A17, J9.A17, J10.A17, J11.A17, J12.A17, U7.13
/A18: J1.A18, J2.A18, J3.A18, J4.A18, J5.A18, J6.A18, J7.A18, J8.A18, J9.A18, J10.A18, J11.A18, J12.A18, U7.2
/A19: J1.A19, J2.A19, J3.A19, J4.A19, J5.A19, J6.A19, J7.A19, J8.A19, J9.A19, J10.A19, J11.A19, J12.A19, U7.12
/A20: J1.A20, J2.A20, J3.A20, J4.A20, J5.A20, J6.A20, J7.A20, J8.A20, J9.A20, J10.A20, J11.A20, J12.A20, U7.5
/A21: J1.A21, J2.A21, J3.A21, J4.A21, J5.A21, J6.A21, J7.A21, J8.A21, J9.A21, J10.A21, J11.A21, J12.A21, U7.6
/A22: J1.A22, J2.A22, J3.A22, J4.A22, J5.A22, J6.A22, J7.A22, J8.A22, J9.A22, J10.A22, J11.A22, J12.A22, U7.7
/A23: J1.A23, J2.A23, J3.A23, J4.A23, J5.A23, J6.A23, J7.A23, J8.A23, J9.A23, J10.A23, J11.A23, J12.A23, U7.9
/A24: J1.A24, J2.A24, J3.A24, J4.A24, J5.A24, J6.A24, J7.A24, J8.A24, J9.A24, J10.A24, J11.A24, J12.A24, U7.8
/A25: J1.A25, J2.A25, J3.A25, J4.A25, J5.A25, J6.A25, J7.A25, J8.A25, J9.A25, J10.A25, J11.A25, J12.A25, U6.1
/A26: J1.A26, J2.A26, J3.A26, J4.A26, J5.A26, J6.A26, J7.A26, J8.A26, J9.A26, J10.A26, J11.A26, J12.A26, U6.2
/A27: J1.A27, J2.A27, J3.A27, J4.A27, J5.A27, J6.A27, J7.A27, J8.A27, J9.A27, J10.A27, J11.A27, J12.A27, U6.13
/A28: J1.A28, J2.A28, J3.A28, J4.A28, J5.A28, J6.A28, J7.A28, J8.A28, J9.A28, J10.A28, J11.A28, J12.A28, U6.12
/A29: J1.A29, J2.A29, J3.A29, J4.A29, J5.A29, J6.A29, J7.A29, J8.A29, J9.A29, J10.A29, J11.A29, J12.A29, U6.7
/A30: J1.A30, J2.A30, J3.A30, J4.A30, J5.A30, J6.A30, J7.A30, J8.A30, J9.A30, J10.A30, J11.A30, J12.A30, U6.8
/B6: J1.B6, J2.B6, J3.B6, J4.B6, J5.B6, J6.B6, J7.B6, J8.B6, J9.B6, J10.B6, J11.B6, J12.B6, U1.13
/B7: J1.B7, J2.B7, J3.B7, J4.B7, J5.B7, J6.B7, J7.B7, J8.B7, J9.B7, J10.B7, J11.B7, J12.B7, U1.12
/B8: J1.B8, J2.B8, J3.B8, J4.B8, J5.B8, J6.B8, J7.B8, J8.B8, J9.B8, J10.B8, J11.B8, J12.B8, U1.9
/B9: J1.B9, J2.B9, J3.B9, J4.B9, J5.B9, J6.B9, J7.B9, J8.B9, J9.B9, J10.B9, J11.B9, J12.B9, U1.8
/B10: J1.B10, J2.B10, J3.B10, J4.B10, J5.B10, J6.B10, J7.B10, J8.B10, J9.B10, J10.B10, J11.B10, J12.B10, U2.1
/B11: J1.B11, J2.B11, J3.B11, J4.B11, J5.B11, J6.B11, J7.B11, J8.B11, J9.B11, J10.B11, J11.B11, J12.B11, U2.2
/B12: J1.B12, J2.B12, J3.B12, J4.B12, J5.B12, J6.B12, J7.B12, J8.B12, J9.B12, J10.B12, J11.B12, J12.B12, U2.12
/B13: J1.B13, J2.B13, J3.B13, J4.B13, J5.B13, J6.B13, J7.B13, J8.B13, J9.B13, J10.B13, J11.B13, J12.B13, U2.9
/B14: J1.B14, J2.B14, J3.B14, J4.B14, J5.B14, J6.B14, J7.B14, J8.B14, J9.B14, J10.B14, J11.B14, J12.B14, U2.8
/B15: J1.B15, J2.B15, J3.B15, J4.B15, J5.B15, J6.B15, J7.B15, J8.B15, J9.B15, J10.B15, J11.B15, J12.B15, U3.1
/B16: J1.B16, J2.B16, J3.B16, J4.B16, J5.B16, J6.B16, J7.B16, J8.B16, J9.B16, J10.B16, J11.B16, J12.B16, U3.2
/B17: J1.B17, J2.B17, J3.B17, J4.B17, J5.B17, J6.B17, J7.B17, J8.B17, J9.B17, J10.B17, J11.B17, J12.B17, U3.12
/B18: J1.B18, J2.B18, J3.B18, J4.B18, J5.B18, J6.B18, J7.B18, J8.B18, J9.B18, J10.B18, J11.B18, J12.B18, U3.9
/B19: J1.B19, J2.B19, J3.B19, J4.B19, J5.B19, J6.B19, J7.B19, J8.B19, J9.B19, J10.B19, J11.B19, J12.B19, U3.8
/B20: J1.B20, J2.B20, J3.B20, J4.B20, J5.B20, J6.B20, J7.B20, J8.B20, J9.B20, J10.B20, J11.B20, J12.B20, U4.1
/B21: J1.B21, J2.B21, J3.B21, J4.B21, J5.B21, J6.B21, J7.B21, J8.B21, J9.B21, J10.B21, J11.B21, J12.B21, U4.2
/B22: J1.B22, J2.B22, J3.B22, J4.B22, J5.B22, J6.B22, J7.B22, J8.B22, J9.B22, J10.B22, J11.B22, J12.B22, U4.12
/B23: J1.B23, J2.B23, J3.B23, J4.B23, J5.B23, J6.B23, J7.B23, J8.B23, J9.B23, J10.B23, J11.B23, J12.B23, U4.9
/B24: J1.B24, J2.B24, J3.B24, J4.B24, J5.B24, J6.B24, J7.B24, J8.B24, J9.B24, J10.B24, J11.B24, J12.B24, U4.6
/B25: J1.B25, J2.B25, J3.B25, J4.B25, J5.B25, J6.B25, J7.B25, J8.B25, J9.B25, J10.B25, J11.B25, J12.B25, U4.8
/B26: J1.B26, J2.B26, J3.B26, J4.B26, J5.B26, J6.B26, J7.B26, J8.B26, J9.B26, J10.B26, J11.B26, J12.B26, U4.7
/B27: J1.B27, J2.B27, J3.B27, J4.B27, J5.B27, J6.B27, J7.B27, J8.B27, J9.B27, J10.B27, J11.B27, J12.B27, U6.14
/B28: J1.B28, J2.B28, J3.B28, J4.B28, J5.B28, J6.B28, J7.B28, J8.B28, J9.B28, J10.B28, J11.B28, J12.B28, U6.5
/B29: J1.B29, J2.B29, J3.B29, J4.B29, J5.B29, J6.B29, J7.B29, J8.B29, J9.B29, J10.B29, J11.B29, J12.B29, U6.6
/B30: J1.B30, J2.B30, J3.B30, J4.B30, J5.B30, J6.B30, J7.B30, J8.B30, J9.B30, J10.B30, J11.B30, J12.B30, U6.9
/C4: J1.C4, J2.C4, J3.C4, J4.C4, J5.C4, J6.C4, J7.C4, J8.C4, J9.C4, J10.C4, J11.C4, J12.C4, U1.14
/C5: J1.C5, J2.C5, J3.C5, J4.C5, J5.C5, J6.C5, J7.C5, J8.C5, J9.C5, J10.C5, J11.C5, J12.C5, U1.1
/C6: J1.C6, J2.C6, J3.C6, J4.C6, J5.C6, J6.C6, J7.C6, J8.C6, J9.C6, J10.C6, J11.C6, J12.C6, U1.2
/C7: J1.C7, J2.C7, J3.C7, J4.C7, J5.C7, J6.C7, J7.C7, J8.C7, J9.C7, J10.C7, J11.C7, J12.C7, U1.5
/C8: J1.C8, J2.C8, J3.C8, J4.C8, J5.C8, J6.C8, J7.C8, J8.C8, J9.C8, J10.C8, J11.C8, J12.C8, U1.6
/C9: J1.C9, J2.C9, J3.C9, J4.C9, J5.C9, J6.C9, J7.C9, J8.C9, J9.C9, J10.C9, J11.C9, J12.C9, U1.7
/C10: J1.C10, J2.C10, J3.C10, J4.C10, J5.C10, J6.C10, J7.C10, J8.C10, J9.C10, J10.C10, J11.C10, J12.C10, U2.14
/C11: J1.C11, J2.C11, J3.C11, J4.C11, J5.C11, J6.C11, J7.C11, J8.C11, J9.C11, J10.C11, J11.C11, J12.C11, U2.13
/C12: J1.C12, J2.C12, J3.C12, J4.C12, J5.C12, J6.C12, J7.C12, J8.C12, J9.C12, J10.C12, J11.C12, J12.C12, U2.5
/C13: J1.C13, J2.C13, J3.C13, J4.C13, J5.C13, J6.C13, J7.C13, J8.C13, J9.C13, J10.C13, J11.C13, J12.C13, U2.6
/C14: J1.C14, J2.C14, J3.C14, J4.C14, J5.C14, J6.C14, J7.C14, J8.C14, J9.C14, J10.C14, J11.C14, J12.C14, U2.7
/C15: J1.C15, J2.C15, J3.C15, J4.C15, J5.C15, J6.C15, J7.C15, J8.C15, J9.C15, J10.C15, J11.C15, J12.C15, U3.14
/C16: J1.C16, J2.C16, J3.C16, J4.C16, J5.C16, J6.C16, J7.C16, J8.C16, J9.C16, J10.C16, J11.C16, J12.C16, U3.13
/C17: J1.C17, J2.C17, J3.C17, J4.C17, J5.C17, J6.C17, J7.C17, J8.C17, J9.C17, J10.C17, J11.C17, J12.C17, U3.5
/C18: J1.C18, J2.C18, J3.C18, J4.C18, J5.C18, J6.C18, J7.C18, J8.C18, J9.C18, J10.C18, J11.C18, J12.C18, U3.6
/C19: J1.C19, J2.C19, J3.C19, J4.C19, J5.C19, J6.C19, J7.C19, J8.C19, J9.C19, J10.C19, J11.C19, J12.C19, U3.7
/C20: J1.C20, J2.C20, J3.C20, J4.C20, J5.C20, J6.C20, J7.C20, J8.C20, J9.C20, J10.C20, J11.C20, J12.C20, U4.14
/C21: J1.C21, J2.C21, J3.C21, J4.C21, J5.C21, J6.C21, J7.C21, J8.C21, J9.C21, J10.C21, J11.C21, J12.C21, U4.13
/C22: J1.C22, J2.C22, J3.C22, J4.C22, J5.C22, J6.C22, J7.C22, J8.C22, J9.C22, J10.C22, J11.C22, J12.C22, U4.5
/C23: J1.C23, J2.C23, J3.C23, J4.C23, J5.C23, J6.C23, J7.C23, J8.C23, J9.C23, J10.C23, J11.C23, J12.C23, U5.1
/C24: J1.C24, J2.C24, J3.C24, J4.C24, J5.C24, J6.C24, J7.C24, J8.C24, J9.C24, J10.C24, J11.C24, J12.C24, U5.14
/C25: J1.C25, J2.C25, J3.C25, J4.C25, J5.C25, J6.C25, J7.C25, J8.C25, J9.C25, J10.C25, J11.C25, J12.C25, U5.13
/C26: J1.C26, J2.C26, J3.C26, J4.C26, J5.C26, J6.C26, J7.C26, J8.C26, J9.C26, J10.C26, J11.C26, J12.C26, U5.2
/C27: J1.C27, J2.C27, J3.C27, J4.C27, J5.C27, J6.C27, J7.C27, J8.C27, J9.C27, J10.C27, J11.C27, J12.C27, U5.12
/C28: J1.C28, J2.C28, J3.C28, J4.C28, J5.C28, J6.C28, J7.C28, J8.C28, J9.C28, J10.C28, J11.C28, J12.C28, U5.9
/C29: J1.C29, J2.C29, J3.C29, J4.C29, J5.C29, J6.C29, J7.C29, J8.C29, J9.C29, J10.C29, J11.C29, J12.C29, U5.8
/C30: J1.C30, J2.C30, J3.C30, J4.C30, J5.C30, J6.C30, J7.C30, J8.C30, J9.C30, J10.C30, J11.C30, J12.C30, U5.7
/POWEROK: D4.2, J13.6, P1.A22, R2.2
/POWERON: J13.7, J14.1
/SPARE: C10.1, J13.4, TP1.1
/STANDBY: J13.5, R3.2
/Sheet6199673A/A2: J1.A2, J2.A2, J3.A2, J4.A2, J5.A2, J6.A2, J7.A2, J8.A2, J9.A2, J10.A2, J11.A2, J12.A2
/Sheet6199673A/A4: J1.A4, J2.A4, J3.A4, J4.A4, J5.A4, J6.A4, J7.A4, J8.A4, J9.A4, J10.A4, J11.A4, J12.A4
/Sheet6199673A/A5: J1.A5, J2.A5, J3.A5, J4.A5, J5.A5, J6.A5, J7.A5, J8.A5, J9.A5, J10.A5, J11.A5, J12.A5
/Sheet6199673A/A6: J1.A6, J2.A6, J3.A6, J4.A6, J5.A6, J6.A6, J7.A6, J8.A6, J9.A6, J10.A6, J11.A6, J12.A6
/Sheet6199673A/A7: J1.A7, J2.A7, J3.A7, J4.A7, J5.A7, J6.A7, J7.A7, J8.A7, J9.A7, J10.A7, J11.A7, J12.A7
/Sheet6199673A/A8: J1.A8, J2.A8, J3.A8, J4.A8, J5.A8, J6.A8, J7.A8, J8.A8, J9.A8, J10.A8, J11.A8, J12.A8
/Sheet6199673A/A9: J1.A9, J2.A9, J3.A9, J4.A9, J5.A9, J6.A9, J7.A9, J8.A9, J9.A9, J10.A9, J11.A9, J12.A9
/Sheet6199673A/A10: J1.A10, J2.A10, J3.A10, J4.A10, J5.A10, J6.A10, J7.A10, J8.A10, J9.A10, J10.A10, J11.A10, J12.A10
/Sheet6199673A/A11: J1.A11, J2.A11, J3.A11, J4.A11, J5.A11, J6.A11, J7.A11, J8.A11, J9.A11, J10.A11, J11.A11, J12.A11
/Sheet6199673A/A12: J1.A12, J2.A12, J3.A12, J4.A12, J5.A12, J6.A12, J7.A12, J8.A12, J9.A12, J10.A12, J11.A12, J12.A12
/Sheet6199673A/A13: J1.A13, J2.A13, J3.A13, J4.A13, J5.A13, J6.A13, J7.A13, J8.A13, J9.A13, J10.A13, J11.A13, J12.A13
/Sheet6199673A/A14: J1.A14, J2.A14, J3.A14, J4.A14, J5.A14, J6.A14, J7.A14, J8.A14, J9.A14, J10.A14, J11.A14, J12.A14
/Sheet6199673A/B2: J1.B2, J2.B2, J3.B2, J4.B2, J5.B2, J6.B2, J7.B2, J8.B2, J9.B2, J10.B2, J11.B2, J12.B2
/Sheet6199673A/B3: J1.B3, J2.B3, J3.B3, J4.B3, J5.B3, J6.B3, J7.B3, J8.B3, J9.B3, J10.B3, J11.B3, J12.B3
/Sheet6199673A/B4: J1.B4, J2.B4, J3.B4, J4.B4, J5.B4, J6.B4, J7.B4, J8.B4, J9.B4, J10.B4, J11.B4, J12.B4
/Sheet6199673A/B5: J1.B5, J2.B5, J3.B5, J4.B5, J5.B5, J6.B5, J7.B5, J8.B5, J9.B5, J10.B5, J11.B5, J12.B5
/Sheet6199673A/C2: J1.C2, J2.C2, J3.C2, J4.C2, J5.C2, J6.C2, J7.C2, J8.C2, J9.C2, J10.C2, J11.C2, J12.C2
/Sheet6199673A/C3: J1.C3, J2.C3, J3.C3, J4.C3, J5.C3, J6.C3, J7.C3, J8.C3, J9.C3, J10.C3, J11.C3, J12.C3
/T34: P1.C3, P2.A4
GND: C1.2, C2.2, C3.2, C4.2, C5.2, C6.2, C7.2, C8.2, C9.2, C10.2, C11.2, C12.2, C13.2, C14.2, C15.2, C16.2, C17.2, D1.1, D2.1, D3.1, H1.1, H2.1, H3.1, H4.1, H5.1, H6.1, H7.1, H8.1, H9.1, H10.1, H11.1, H12.1, H13.1, H14.1, H15.1, H16.1, H17.1, H18.1, H19.1, H20.1, H21.1, H22.1, H23.1, H23#2.1, H23#3.1, H24.1, H24#2.1, H24#3.1, J1.A31, J1.A32, J1.B31, J1.B32, J1.C31, J1.C32, J2.A31, J2.A32, J2.B31, J2.B32, J2.C31, J2.C32, J3.A31, J3.A32, J3.B31, J3.B32, J3.C31, J3.C32, J4.A31, J4.A32, J4.B31, J4.B32, J4.C31, J4.C32, J5.A31, J5.A32, J5.B31, J5.B32, J5.C31, J5.C32, J6.A31, J6.A32, J6.B31, J6.B32, J6.C31, J6.C32, J7.A31, J7.A32, J7.B31, J7.B32, J7.C31, J7.C32, J8.A31, J8.A32, J8.B31, J8.B32, J8.C31, J8.C32, J9.A31, J9.A32, J9.B31, J9.B32, J9.C31, J9.C32, J10.A31, J10.A32, J10.B31, J10.B32, J10.C31, J10.C32, J11.A31, J11.A32, J11.B31, J11.B32, J11.C31, J11.C32, J12.A31, J12.A32, J12.B31, J12.B32, J12.C31, J12.C32, J13.1, J13.2, J13.3, J14.2, P1.A31, P1.A32, P1.B4, P1.B5, P1.B31, P1.B32, P1.C31, P1.C32, P2.A31, P2.A32, P2.B31, P2.B32, P2.C31, P2.C32, U1.3, U1.4, U2.3, U2.4, U3.3, U3.4, U4.3, U4.4, U5.3, U5.4, U6.3, U6.4, U7.3, U7.4
unnamed: D1.2, R1.1
unnamed: D2.2, R2.1
unnamed: D3.2, R3.1

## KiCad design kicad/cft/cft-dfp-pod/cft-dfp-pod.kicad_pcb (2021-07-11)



Board: 2 copper layers, 50.8 x 43.2 mm, 23 parts (8 on the bottom side), 51 nets.

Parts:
C1, C2, C3, C4, C5: 100nF; SMD_0805_2012Metric_Pad1.15x1.40mm_HandSolder
C6, C7: 1uF; SMD_0805_2012Metric_Pad1.15x1.40mm_HandSolder
D1, D2: LED_ALT; LED_0805_2012Metric_Pad1.15x1.40mm_HandSolder
P1, P2: Conn_01x24_Male; PinHeader_2x12_P2.54mm_Vertical
P3: Conn_01x18_Male; PinHeader_2x09_P2.54mm_Vertical
R1, R2: 330Ω; R_SMD_0805_2012Metric_Pad1.15x1.40mm_HandSolder
RN1, RN2, RN3, RN4: 30Ω; R_Array_Convex_4x0402
U1, U2, U3, U4: 74HC574; SOIC-20W
U5: SN74ACT1073; SOIC-20W

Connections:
+5V: C1.1, C2.1, C3.1, C4.1, C5.1, C6.1, C7.1, P1.1, P1.2, P2.9, P2.10, P2.11, P2.12, R1.2, R2.1, U1.20, U2.20, U3.20, U4.20, U5.15, U5.16
/BUSCP: P1.9, U3.11, U4.11
/CP0: P1.10, U1.11
/CP1: P1.21, U2.11
/D0: P2.1, P3.1, U1.19, U3.2, U5.11
/D1: P2.2, P3.2, U1.18, U3.3, U5.10
/D2: P2.3, P3.3, U1.17, U3.4, U5.12
/D3: P2.4, P3.4, U1.16, U3.5, U5.9
/D4: P2.5, P3.5, U1.15, U3.6, U5.13
/D5: P2.6, P3.6, U1.14, U3.7, U5.8
/D6: P2.7, P3.7, U1.13, U3.8, U5.14
/D7: P2.8, P3.8, U1.12, U3.9, U5.7
/D8: P2.13, P3.11, U2.19, U4.2, U5.4
/D9: P2.14, P3.12, U2.18, U4.3, U5.19
/D10: P2.15, P3.13, U2.17, U4.4, U5.20
/D11: P2.16, P3.14, U2.16, U4.5, U5.17
/D12: P2.17, P3.15, U2.15, U4.6, U5.1
/D13: P2.18, P3.16, U2.14, U4.7, U5.18
/D14: P2.19, P3.17, U2.13, U4.8, U5.2
/D15: P2.20, P3.18, U2.12, U4.9, U5.3
/FPD0: P1.5, RN1.8, RN3.8, U1.2, U2.2
/FPD1: P1.6, RN1.7, RN3.7, U1.3, U2.3
/FPD2: P1.7, RN1.6, RN3.6, U1.4, U2.4
/FPD3: P1.8, RN1.5, RN3.5, U1.5, U2.5
/FPD4: P1.17, RN2.8, RN4.8, U1.6, U2.6
/FPD5: P1.20, RN2.7, RN4.7, U1.7, U2.7
/FPD6: P1.19, RN2.6, RN4.6, U1.8, U2.8
/FPD7: P1.22, RN2.5, RN4.5, U1.9, U2.9
/~OE0: P1.3, U1.1
/~OE1: D1.1, P1.15, U2.1
/~R0: P1.4, U3.1
/~R1: D2.1, P1.16, U4.1
GND: C1.2, C2.2, C3.2, C4.2, C5.2, C6.2, C7.2, P1.11, P1.12, P1.13, P1.14, P1.23, P1.24, P2.21, P2.22, P2.23, P2.24, P3.9, P3.10, U1.10, U2.10, U3.10, U4.10, U5.5, U5.6
unnamed: D1.2, R1.1
unnamed: D2.2, R2.2
unnamed: RN1.1, U3.19
unnamed: RN1.2, U3.18
unnamed: RN1.3, U3.17
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

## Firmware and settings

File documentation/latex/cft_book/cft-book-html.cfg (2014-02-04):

% -*- latex -*-
\Preamble{html4,css,charset=utf8,index=2,2,fn-in,next}
%html4,css2,index=2,2,sec-filename,next,charset=utf8,fn-in,frames}%
%, mouseover, javascript, sec-filename}

\Configure{@HEAD}{\HCode{<script type="text/javascript" src="jquery.js"></script>\Hnewline
<script type="text/javascript" src="cft-book.js"></script>\Hnewline
<link rel="stylesheet" type="text/css" href="style.css"> \Hnewline
}}

%%\TocAt{part,chapter}
%%\PauseCutAt{chapter}

%%%%%%%%%%%%%%%%%%%%%%%%%%%%%%%%%%%%%%%%%%%%%%%%%%%%%%%%%%%%%%%%%%%%%%%%%%%%%%%
%%
%% TABLE OF CONTENTS
%%
%%%%%%%%%%%%%%%%%%%%%%%%%%%%%%%%%%%%%%%%%%%%%%%%%%%%%%%%%%%%%%%%%%%%%%%%%%%%%%%

% Get rid of stupid <span>..<br/> pairs, use <ul> and <li>
\ConfigureToc{part}{\tocNesting{1}{part}\HCode{<li class="toc-part">}}{ }{}{\HCode{</li>\Hnewline<!-- end of part -->} }
\ConfigureToc{chapter}{\tocNesting{2}{chapter}\HCode{<li class="toc-chapter">}}{ }{}{\HCode{</li>\Hnewline <!-- end of chapter -->} }
\ConfigureToc{section}{\tocNesting{3}{section}\HCode{<li class="toc-section">}}{ }{}{\HCode{</li>\Hnewline <!-- end of section -->} }
\ConfigureToc{subsection}{\tocNesting{4}{subsection}\HCode{<li class="top-subsection">}}{ }{}{\HCode{</li>\Hnewline} }
\ConfigureToc{subsubsection}{\tocNesting{5}{subsubsection}\HCode{<li class="toc-subsubsection">}}{ }{}{</li>\HCode{\Hnewline} }

\ConfigureToc{part*}{\tocNesting{1}{part}\HCode{<li class="toc-part">}}{ }{}{\HCode{\Hnewline} }
\ConfigureToc{chapter*}{\tocNesting{2}{chapter}\HCode{<li class="toc-chapter">}}{ }{}{\HCode{\Hnewline} }
\ConfigureToc{section*}{\tocNesting{3}{section}\HCode{<li class="toc-section">}}{ }{}{\HCode{\Hnewline} }
\ConfigureToc{subsection*}{\tocNesting{4}{subsection}\HCode{<li class="top-subsection">}}{ }{}{\HCode{\Hnewline} }
\ConfigureToc{subsubsection*}{\tocNesting{5}{subsubsection}\HCode{<li class="toc-subsubsection">}}{ }{}{\HCode{\Hnewline} }

\Configure{tableofcontents}{} {\tocNesting{0}{top}} {} {} {}
\newcount\c
\def\tocNesting#1#2{%
  \expandafter\ifx \csname level#1\endcsname\relax
  \ifnum #1>0 \HCode{<ul class="toc toc-#2 level#1">}\fi
  \expandafter\def \csname level#1\endcsname{\HCode{</ul>}}
  \fi
  \c=#1 \advance\c by 1
  \loop
  \csname level\the\c\endcsname
  \expandafter\let \csname level\the\c\endcsname\relax
  \advance\c by 1
  \ifnum \c<10   \repeat
}

\Configure{crosslinks}
          {\HCode{<span class="crosslink">}}
          {\HCode{</span>}}{Next}{Prev}{PrevTail}{Front}{Tail}{Up}

\ConfigureList{description}
              {\HCode{<div class="description">}\def\descend{}}
              {\descend\HCode{</div>}}
              {\descend\HCode{<div class="description-item"><span class="description-term">}\def\descend{\HCode{</div>}}}
              {\HCode{</span>}}
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

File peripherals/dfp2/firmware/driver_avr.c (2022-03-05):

// -*- c -*-
// 
// driver_avr.c — AVR-specific DFP functionality
// 
// Copyright © 2012–2020 Alexios Chouchoulas
// 
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
///////////////////////////////////////////////////////////////////////////////
//
// HARDWARE DRIVER FOR DFP ON ATMEGA64
//
///////////////////////////////////////////////////////////////////////////////

#ifndef AVR
#  error "This driver is meant for an AVR only."
#endif // AVR

#include <stdlib.h>

#include <avr/interrupt.h>
#include <avr/pgmspace.h>
#include <avr/wdt.h>
#include <avr/cpufunc.h>

#include "dfp.h"
#include "utils.h"
#include "driver.h"

#define USE_ATOMIC_BLOCKS 

#ifdef USE_ATOMIC_BLOCKS
#include <util/atomic.h>
#else
#define ATOMIC_BLOCK(x)
#endif

// This 'driver' is only available on the AVR target.

// #include "hwcompat.h"
// #include "panel.h"
#include "proto.h"
#include "strings.h"
// #include "abstract.h"
// #include "bus.h"
// #include "buscmd.h"
// #include "utils.h"
// #include "serial.h"
#include "output.h"
// #include "switches.h"
// #include "panel.h"
#include "microcode_disassembly.h"


hwstate_t hwstate;

ringbuf_t rb;

///////////////////////////////////////////////////////////////////////////////
//
// FORWARD DEFINITIONS (AS NEEDED)
//
///////////////////////////////////////////////////////////////////////////////

// These are added as needed.
inline static void fp_scanner_stop();
inline static void fp_scanner_start();

static inline void sw_init();

static void dfp_diags();


///////////////////////////////////////////////////////////////////////////////
//
// PORT MAP
//
///////////////////////////////////////////////////////////////////////////////

// Key:
//
// O.     Output
// I.     Input
// AL.    Active Low
// RE.    Rising Edge
// OD.    Open Drain output.
// I/OD.  Open drain, also used as input when in Z state.
// FP     Front Panel

// Port A: XMEM Address and Data Bus

// Port B: Programming/Control

#define __SCK        PB1 /**/        // SCK (programming, not used)
#define __MOSI       PB2 /**/        // MOSI (programming, not used)
#define __MISO       PB3 /**/        // MISO (programming, not used)
                     
// Port C: Bus Enables & Control

// Port D: Panel & Run Control

#define D_NIOINT     PD0 /**/       // Used for incoming interrupts only.
#define D_NWAIT      PD1 /**/       // I. AL: Run/Stop/Step FSM is (µ)stepping, or reset in progress
#define D_LED_STOP   PD5 /**/       // O. to FP. Controls the STOP LED. (FP scanner must be running)
#define D_NSTEP_RUN  PD6 /**/       // O. to FP and Run/Stop/Step FSM. 0 = running (RUN LED on)
#define D_NMSTEP     PD7 /**/       // O. to Run/Stop/Step FSM. AL: request microstep.
                             
// Port E: Serial I/O, Panel, Control Vector enable

#define E_RXD        PE0 /**/       // USART, not used directly.
#define E_TXD        PE1 /**/       // USART, not used directly.
#define E_NFPIRQ     PE2 /**/       // O. AL: signal (jumper configurable) IRQ to processor
                             
// Port F: Front panel switches

#define F_SWA0       PF0 /**/       // O. FP switch address, bit 0.
#define F_SWA1       PF1 /**/       // O. FP switch address, bit 1.
#define F_SWA2       PF2 /**/       // O. FP switch address, bit 2.
#define F_SWA3       PF3 /**/       // O. FP switch address, bit 3.
#define F_SWD0       PF4 /**/       // I. FP switch data, bit 0.
#define F_SWD1       PF5 /**/       // I. FP switch data, bit 1.
#define F_SWD2       PF6 /**/       // I. FP switch data, bit 2.
#define F_SWD3       PF7 /**/       // I. FP switch data, bit 3.
                             
// Port G: XMEM bus control

#define G_WR         PG0 /**/       // O. XMEM or manual bus control
#define G_RD         PG1 /**/       // O. XMEM or manual bus control
#define G_ALE        PG2 /**/       // O. XMEM or manual bus control

// (**) There is an erratum in the fabricated R1939 DFP board where FPHALT# is
//      connected to the PEN pin, which can't be controlled by the MCU. This
//      trace has been cut on the board and patched to TP101 (pin 18, PG3).




// Key:
//
// O.     Output
// I.     Input
// AL.    Active Low
// RE.    Rising Edge
// OD.    Open Drain output.
// I/OD.  Open drain, also used as input when in Z state.
// FP     Front Panel

// (*) SCANEN# and PANELEN# work like this:
//
// SCANEN#    FPGRAB    What
// ----------------------------------------------------------------------------------
//    0          0       FP scanner samples the computer and updates the FP itself.
//    0          1       FP scanner on, but no panel updates. Pointless.
//    1          0       MCU can read from computer, panel updates as read.
//    1          1       MCU can write to front panel.

// Port B.
#define B_MFD0       PB1    // O. Set MFD value.
#define B_MFD1       PB2    // O. Set MFD value.
#define B_MFD2       PB3    // O. Set MFD value.
#define B_LED_STOP   PB4    // O. to FP. Controls the STOP LED. (FP scanner must be running)
#define B_NLTSON     PB6    // O. to FP. AL: all FP lights enabled.
#define B_LED        PB7    // O.    Built-in Arduino LED.

#define B_MFDMASK    (BV(B_MFD0) | BV(B_MFD1) | BV(B_MFD2)) // The MFD mask
#define B_MFDSHIFT   (E_MFD0)   // The MFD shift value

// Port C.
#define C_NBUSEN     PC0    // O.    0: DFP drives the FP bus. 1: autoscan drives.
#define C_NAUTOSCAN  PC1    // O.    AL: FP scan counter controls the bus & FP.
#define C_FPGRAB     PC2    // O.    1: DFP drives FP. 0: CFT drives FP.
//                   PC3    // (not used)
#define C_NW         PC4    // I/OD. AL: drive W# bus signal.
#define C_NR         PC5    // I/OD. AL: drive R# bus signal.
#define C_NIO        PC6    // I/OD. AL: drive IO# bus signal.
#define C_NMEM       PC7    // I/OD. AL: drive MEM# bus signal.

// Port E.
#define E_FPUSTEP    PE5    // O. Slow clock generator.

// Port H: FP OD Reset signals

#define H_NFPHALT    PH3    // O. AL: asserts FPHALT#.
#define H_NFPRESET   PH5    // O. OD: signals reset to processor.
#define H_NFPRSTHOLD PH6    // O. OD: asserts RSTHOLD#. (only use when CTL is absent)

// Port K: Bus enables etc.

#define K_CLRWS      PK0    // O. RE: done with transaction, clear WS
#define K_NIBOE      PK1    // O. AL: drive IBUS
#define K_NABOE      PK2    // O. AL: drive AB (Address Bus)
#define K_NDBOE      PK3    // O. AL: drive DB (Data Bus)
#define K_NUCVOE     PK4    // O. Drive Control Vector outputs (RADDR, WADDR & ACTION)
#define K_DFPDETECT  PK5    // I. MCU is plugged into DFP board if PK4 == PK5
//                   PK6    // (not used)
//                   PK7    // (not used)
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

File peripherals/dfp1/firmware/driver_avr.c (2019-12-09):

// -*- indent-c++ -*-
//

#ifdef AVR

#define USE_ATOMIC_BLOCKS

#include <avr/interrupt.h>
#include <avr/wdt.h>

#ifdef USE_ATOMIC_BLOCKS
#include <util/atomic.h>
#else
#define ATOMIC_BLOCK(x)
#endif

// This 'driver' is only available on the AVR target.

#include "hwcompat.h"
#include "panel.h"
#include "proto.h"
#include "abstract.h"
#include "bus.h"
#include "buscmd.h"
#include "utils.h"
#include "serial.h"
#include "output.h"
#include "switches.h"
#include "panel.h"

/*

  Pin assignments:

  PC0: in  DEBIN
  PC1: in  VPIN
  PC2: out ICLK
  PC3: out DOUT
  PC4: out CMD0
  PC5: out CMD1

  PD0: USART
  PD1: USART
  PD2: in  IOCMD + int
  PD3: out DB-OE#
  PD4: out AB-OE#
  PD5: out IBUS-OE#
  PD6: out CTL-OE#
  PD7: out COUT

  PB0: out CLR-WS
  PB1: out FPCLKEN-IN
  PB2: out FPUSTEP-IN
  PB3: out IOADDR0
  PB4: out IOADDR1
  PB5: out IOADDR2

 */

#define C_DEBIN     PC0
#define C_VPIN      PC1
#define C_ICLK      PC2
#define C_DOUT      PC3
#define C_CMD0      PC4
#define C_CMD1      PC5

#define C_IDLE      0
#define C_OUTPUTS   (_BV(C_ICLK) | _BV(C_DOUT) | _BV(C_CMD0) | _BV(C_CMD1))

#define D_IOCMD     PD2
#define D_NDBOE     PD3
#define D_NABOE     PD4
#define D_NIBUSOE   PD5
#define D_NCTLOE    PD6
#define D_COUT      PD7

#define D_IDLE      (_BV(D_NDBOE) | _BV(D_NABOE) | _BV(D_NIBUSOE) | _BV(D_NCTLOE))
#define D_OUTPUTS   (_BV(D_NDBOE) | _BV(D_NABOE) | _BV(D_NIBUSOE) | \
		     _BV(D_NCTLOE) | _BV(D_COUT))

#define B_CLRWS     PB0
#define B_FPCLKEN   PB1
#define B_FPUSTEP   PB2
#define B_IOADDR0   PB3
#define B_IOADDR1   PB4
#define B_IOADDR2   PB5

#define B_IDLE      (_BV(B_CLRWS))
#define B_IOADDR    (_BV(B_IOADDR0) | _BV(B_IOADDR1) | _BV(B_IOADDR2))
#define B_OUTPUTS   (_BV(B_CLRWS) | _BV(B_FPCLKEN) | _BV(B_FPUSTEP) | B_IOADDR)


// Note: values in octal (the 259s have eight values each)
#define CMD_SAMPLE  000
#define CMD_VPEN    001
#define CMD_DEBEN   002
//#define CMD_CTLOE   003
#define CMD_CLR     004
#define CMD_STEPRUN 005		// 0 = Running
#define CMD_USTEP   006
#define CMD_ORCLK   007

#define CMD_DBCLK   010
#define CMD_ABCLK   011
#define CMD_IBUSCLK 012
#define CMD_CTLCLK  013
#define CMD_STCP    015
#define CMD_BUSPU   017

// Prescaler values for CS10-12 bits.
#define PSV_1       1
#define PSV_8       2
#define PSV_64      3
#define PSV_256     4
#define PSV_1024    5

static uint16_t _ab;
static uint16_t _db;
static uint16_t _ir;
static uint16_t _pc;
static uint16_t _ac;
static uint8_t _flags;
volatile static uint16_t _swright, _swright0;
volatile static uint16_t _sr, _sr0;
volatile static uint16_t _swleft, _swleft0;
static uint16_t _or;
uint8_t defercb = 0;
static uint8_t _clk_prescale = PSV_1024;
static uint16_t _clk_div = 89;
static uint8_t _stopped = 1;

static union {
	uint8_t  uvec8[4];	// Microcode vector: 24 bits ([3] unused)
	uint32_t uvec32;	// Microcode vector as a 32-bit integer
} _uv;

uint8_t cb[3] = {
	CB0_OUTPUTS,
	CB1_OUTPUTS,
	CB2_OUTPUTS
};

uint16_t icr = 0;
uint8_t ifr6_operated = 0;
static uint8_t idle_addr = 0; // Used for diagnostics

ringbuf_t ringbuf;

#define actuated(bm, sw) (((bm) & (sw)) == 0)

///////////////////////////////////////////////////////////////////////////////
//
// WRITING COMMANDS TO THE 74x259 ADDRESSABLE LATCHES
//
///////////////////////////////////////////////////////////////////////////////


/*

  Waveform:
                         _________________
  IOADDRx    XXXXXXXXXX><_________________>XXXX
                                _______________
  COUT       __________________/ val 
                                   _______
  CMDx       XXXXXXXXXXXXXXXXXXXXX<_______>XXXX

 */

static void out_shift_registers(uint8_t val, uint8_t clk);

static void
outcmd(uint8_t addr, uint8_t val)
{
	// Interlock: never allow VPEN and DEBEN to be asserted
	// simultaneously. If one is asserted, deassert the
	// other. Note: these are inverted, so 1 = asserted, 0 =
	// deasserted.
	if (val) {
		if (addr == CMD_VPEN) outcmd(CMD_DEBEN, 0);
		else if (addr == CMD_DEBEN) outcmd(CMD_VPEN, 0);
	}

	// Clear the CMDx outputs.
	PORTC = PORTC |= _BV(C_CMD0) | _BV(C_CMD1);
	
	// Set the value first. The '259s are latches.
	bit(PORTD, D_COUT, val);
	
	// Then, set the address.
	// Note: the shift makes assumptions about the IOADDRx pins.
	PORTB = (PORTB & ~B_IOADDR) | ((addr & 7) << 3);

	// Now, strobe the CMDx bit
	clearbit(PORTC, addr & 8 ? C_CMD1 : C_CMD0);
	PORTC |= _BV(C_CMD0) | _BV(C_CMD1);

	// Clean up.
	PORTB = PORTB & ~B_IOADDR;
	PORTB = (PORTB & ~B_IOADDR) | ((idle_addr & 7) << 3);
}


/*

  Waveform:
                         _________________
  IOADDRx    XXXXXXXXXX><_________________>XXXX
                              ____________
  CMDx       XXXXXX__________<____________>XXXX
                                    __
  COUT       XXXXXXXXXX____________/  \________

 */



static inline void
_multistrobe_start(uint8_t addr)
{
	// Clear the CMDx outputs (they're active low).
	PORTC = PORTC |= _BV(C_CMD0) | _BV(C_CMD1);
	
	// Clear the value first. The '259s are latches.
	bit(PORTD, D_COUT, 0);
	
	// Then, set the address.
	// Note: the shift makes assumptions about the IOADDRx pins.
	PORTB = (PORTB & ~B_IOADDR) | ((addr & 7) << 3);

	// Enable the appropriate latch signal
	clearbit(PORTC, addr & 8 ? C_CMD1 : C_CMD0);
}

static inline void
_multistrobe_pulse()
{
	// Emit a positive pulse
	setbit(PORTD, D_COUT);
	asm("nop");		// Lengthen the pulse by ~140ns.
	clearbit(PORTD, D_COUT);
}


static inline void
_multistrobe_end()
{
	// Clear both enables for good measure.
	PORTC |= _BV(C_CMD0) | _BV(C_CMD1);
	PORTB = (PORTB & ~B_IOADDR) | ((idle_addr & 7) << 3);
}


static void
strobecmd(uint8_t addr)
{
	// Prepare the command latches for strobing
	_multistrobe_start(addr);

	// The latch has now picked up the 0 value. Strobe it. We have two
	// edges in total, so both types of edge sensitivity (rising/falling)
	// are catered for.
	_multistrobe_pulse();

	// Clear both enables for good measure.
	_multistrobe_end();
}


inline static void
strobe_clr()
{
	// The CLR output is inverted and fed back to its own reset pin, so
	// when it's set to 1 (high) the reset pin will go low, resetting the
	// CLR (and most other drivers on the PFP/DEB) to zero. However, we
	// also clear it manually just to be sure.
	strobecmd(CMD_CLR);
}


inline static void
clr_ws()
{
	// Clear the WS# output.
	PORTB &= ~ _BV(B_CLRWS);
	PORTB |= _BV(B_CLRWS);
}


#define CALC_FREQ(prescaler, hz) ((F_CPU) / (2 * (prescaler)) / (hz))
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

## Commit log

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2019-11-03 Typo fixes
    [alu_port_a.sch, alu_port_b.sch, cft-alu.sch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]
2019-11-03 Routing ALU board, fixing bugs in schematic.
    [Serial_Shifter.sch, cft-alu.kicad_pcb, cft-alu.sch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]
2019-11-04 Routing ALU Board. Looking nice.
    [Serial_Shifter.sch, alu_decoder.sch, alu_port_a.sch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]
2019-11-04 Added RUEN# and WUEN# signals to the expansion bus.
    [alu_decoder.sch, bus.sch, cft-alu.kicad_pcb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]
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2019-11-08 Routing ALU board. Numerous fixes to layout and schematics.
    [Serial_Shifter.sch, alu_decoder.sch, alu_port_a.sch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]
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2019-11-08 Fixed 3D model translation for TSSOP-8 footprint.
    [cft-alu.kicad_pcb]
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2019-11-08 Fixed a typo
    [cft-dfp.sch]
2019-11-10 ALU: Moved two wires, got two new rotate instructions.
    [Serial_Shifter.sch, alu_decoder.sch, alu_port_a.sch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]
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2019-11-12 Stitching ALU board, fine tuning.
    [cft-alu.kicad_pcb, cft-alu.sch, cft_reg_l_2019.sch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]
2019-11-13 Revision 1922 has a short. Fixed issue and stepped revision.
    [cft-backplane.kicad_pcb]
2019-11-14 Added copy of fabricated rev 1922 backplane for reference
    [cft-backplane-20191114-r1922.kicad_pcb]
2019-11-14 Documenting Backplane issue with pins A72 and A73.
    [cft-backplane.kicad_pcb, cft-backplane.sch, slot_164pin.sch]
2019-11-14 Reassigned A72 & A73 to GND
    [16bit-mask-generator.sch, Serial_Shifter.sch, alu.sch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]
2019-11-14 Fixing minor board issues.
    [cft-alu.kicad_pcb, mem.kicad_pcb]
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2019-11-15 Checking board fit, fixed minor issues.
    [cfg_reg_ir.sch, cft-pb0.kicad_pcb, cft-pb0.sch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]
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2019-11-15 Tried adding LEDs to MEM board. Failed, no space.
    [mem.kicad_pcb, mem.sch, mem_leds.sch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]
2019-11-16 Added missing parts to revision 1945
    [cft-backplane.kicad_pcb, cft-backplane.sch]
2019-11-16 Fine tuned board, fixed issues, ready for plotting.
    [bus.sch, mem.kicad_pcb, mem.sch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]
2019-11-16 Moved to new bus pinout, fixed DRC errors.
    [cft-dfp.sch, dfp-bus-left.sch, dfp-bus-right.sch]
2019-11-16 Fixed library bugs. Minor changes.
    [Serial_Shifter.sch, shifter.sch]
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2019-11-17 Fixed missing 74AC04
    [Serial_Shifter.sch]
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2019-11-17 Added new page layout, updated titles etc.
    [cft-dfp-bushold.sch, cft-dfp-scan.sch, cft-dfp.sch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]
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2019-11-23 Erratum in R1939: FPHALT# connected to PEN by mistake.
    [cft-dfp.kicad_pcb, cft-dfp.sch]
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2019-11-26 Patching bugs on board.
    [cft-dfp-bushold.sch, cft-dfp-scan.sch, cft-dfp.kicad_pcb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]
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2019-11-30 Added missing diodes. (duh)
    [cft-front-panel.kicad_pcb, cft-front-panel.sch, cft_front-panel-halfrow.sch]
2019-11-30 Minor fixes.
    [cft-dfp.kicad_pcb]
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2019-12-09 Attempting to fix simulator blocking bug.
    [dfp.h, driver_avr.c, simulate.c]
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2019-12-14 Added 4×8 bit register file schematic using '670 ICs.
    [regfile4x8.sch]
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2019-12-19 Increment to Rev E (1951), ready to manufacture
    [cft-front-panel.kicad_pcb, cft-front-panel.sch, cft_front-panel-halfrow.sch]
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2019-12-20 Improve reset circuitry
    [cft_clk.sch]
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2019-12-21 Add To Do to remove RUEN# and WUEN#
    [bus.sch, cfg_reg_ir.sch, cft-ctl.sch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]
2019-12-22 Work on potential simavr bug
    [driver_avr.c, simulate.c, simulate_uart.c]
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2019-12-26 Reworking MBU to reduce chip count.
    [bus.sch, cft-bus.sch, cft_ar.sch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]
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2019-12-29 Export two more signals to the flag unit, move things around.
    [mbu.sch]
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2020-01-02 Fix some bugs spotted by Verilog testing
    [bus.sch, cft-bus.sch, cft_ar.sch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]
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2020-01-04 Add nRUEN and nWUEN, reworking schematics.
    [bus.sch, cft-bus.sch, cft_ar.sch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]
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2020-01-05 Fix signal labelling error.
    [bus.sch, cfg_reg_ir.sch, cft-ctl.sch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]
2020-01-05 SBU improvements and fixes.
    [cft-ctl.sch, cft_sbl.sch]
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2020-01-12 Remove ACTION_CLL and ACTION_CPL, edge connector fine tuning.
    [cft-bus.sch]
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2020-01-14 Routing BUS board (and it's looking hopeless now).
    [cft-bus.kicad_pcb, cft-ctl.kicad_pcb, cft_clk.sch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]
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2020-02-02 Minor footprint changes, renumbering, and routing BUS board.
    [bus.sch, cft-bus.kicad_pcb, cft-bus.sch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]
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2020-02-05 Fixing possible MBU bugs.
    [bus.sch, cft-bus.kicad_pcb, cft-bus.sch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]
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2020-02-09 Fixed erroneous front panel buffers.
    [cft_microcode.sch, cpu_microcode_fp.sch]
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2020-02-15 Matched reg_ir.v to current schematics, reworked testbench.
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2020-02-16 Reworked the SBU.
    [bus.sch, cft-ctl.sch, cft_sbu.sch]
2020-02-16 Reworkd Interrupt FSM schematics.
    [cft-ctl.sch, cft_clk.sch, cft_int_fsm.sch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]
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2020-02-17 Bug fixes. Experimental board layout. Changed AGL and IR addresses to save two '138s.
    [cfg_reg_ir.sch, cft-ctl.kicad_pcb, cft-ctl.sch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]
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2020-02-17 Routing CTL board. Fixing schematic bugs.
    [bus.sch, cfg_reg_ir.sch, cft-ctl.kicad_pcb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]
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2020-02-19 Routing CTL board (and failing)
    [cft-ctl.kicad_pcb, flag_unit.sch]
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2020-02-22 Routing CTL board, basically ran out of board space.
    [cft-ctl.kicad_pcb]
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2020-02-23 Routing CTL board (looks like another failure).
    [cft-ctl.kicad_pcb, cft-ctl.sch, flag_unit.sch]
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2020-02-26 Coded microcode sequencer verification. Verififying other CTL board components.
    [cft_microcode.sch]
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2020-02-26 Refactoring CTL, BUS and MBU to add IDXEN.
    [bus.sch, cft-bus.kicad_pcb, cft-bus.sch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]
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2020-02-27 Fixed ERC issues, removed unneeded signals.
    [bus.sch, cft-bus.sch, cft_ar.sch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]
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2020-02-27 Disconnected ~RUEN and ~WUEN, marked FN is AC[15]
    [cft-reg.sch]
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2020-02-28 Added TODO notice to check schematics against working Verilog descriptions
    [cft-alu.sch, cft_reg_l_2019.sch, cft_reg_v_2019.sch]
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2020-03-02 Fixed bug with wrong ACTION addresses decoded.
    [alu_decoder.sch]
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2020-03-04 Fixed bug (heretofore undetected by the testbench!) in Flag Unit.
    [cft-ctl.kicad_pcb, cft_microcode.sch, flag_unit.sch]
2020-03-04 Fixing processor bugs.
    [cft-alu.kicad_pcb]
2020-03-05 Added reset interlock to disable bus transactions during reset.
    [cft-ctl.kicad_pcb, cpu_microcode_store.sch]
2020-03-05 Added ALU reset interlock, rerouted some of the PCB.
    [Serial_Shifter.sch, alu_decoder.sch, alu_port_a.sch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]
2020-03-05 Refactored ALU SRU reset interlock to match schematics.
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2020-03-06 Switched to DFP-like OK/FAIL output.
2020-03-06 Fixing minor issues with testbenches to allow for clean compilation.
    [dfp_run_control_tb.v]
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2020-03-18 Minor changes to the board to match debugging efforts.
    [bus.sch, cft-alu.sch, cft-bus.kicad_pcb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]
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2020-03-23 Reworking addressing modes to fix indexing bug.
    [cft-ctl.sch, cft_agl.sch, cft_int_fsm.sch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]
2020-03-23 Working on addressing mode bug fixes.
    [bus.sch, cft-bus.kicad_pcb, cft-bus.sch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]
2020-03-24 Simplified address decoder, looked at BUS routing feasibility.
    [cft-bus.kicad_pcb, cft-bus.sch, cft_ar.sch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]
2020-03-25 Fixed autoindexing bug, updated schematics.
    [bus.sch, cft-bus.kicad_pcb, cft-bus.sch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]
2020-03-25 Working on new tests, fixing bugs.
    [mbu.sch]
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2020-03-29 ACTION strobes synced to the rising edge of CLK3.
    [bus.sch, cft-reg-ac.sch, cft-reg-dr-sp.sch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]
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2020-04-03 A tiny amount of work on the BUS board.
    [cft-bus.kicad_pcb, mbu.sch]
2020-04-06 Fixed L bug, rerouted some signals.
    [alu_port_b.sch, cft-alu.kicad_pcb, cft-alu.sch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]
2020-04-06 Interim commit, working on fixing {SRU,ADD}→L operation
    [Serial_Shifter.sch, alu_decoder.sch, cft-alu.kicad_pcb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]
2020-04-07 Gated ALU ROM FV/FL set enables with nROMOE
    [cft_alu_rom.sch]
2020-04-10 Interim commit while trying to debug SRU-L linkage.
    [Serial_Shifter.sch, alu_port_b.sch, cft-alu.kicad_pcb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]
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2020-04-16 Reworking CTL board.
    [cft-ctl.kicad_pcb]
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2020-04-23 Fixed write decoding.
    [mbu.sch]
2020-04-24 Fixed interrupt registration bug in the ISM.
    [cft-ctl.kicad_pcb, cft_int_fsm.sch]
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2020-04-27 Working on ALU ROM timing issue
    [cft-alu.kicad_pcb, cft-alu.sch, cft_alu_rom.sch]
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2020-05-04 Fixing bugs caused by fixing ALU bugs.
    [Serial_Shifter.sch, alu_decoder.sch, cft-alu.kicad_pcb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]
2020-05-04 Reworking ALU board.
    [Serial_Shifter.sch, alu_decoder.sch, alu_port_b.sch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]
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2020-05-04 Reworking the ALU board.
    [cft-alu.kicad_pcb]
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2020-05-11 Verifying schematics and ALU PCB match Verilog description.
    [Serial_Shifter.sch, alu_decoder.sch, alu_port_b.sch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]
2020-05-11 Potential issue found with clock quadruppler.
    [Serial_Shifter.sch]
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2020-05-12 Added IRQ flip-flops.
    [irq_state_ffs.sch]
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2020-05-14 Cleaning up schematics, added notes, fine-tuned ALU PCB.
    [Serial_Shifter.sch, alu_decoder.sch, alu_port_a.sch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]
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2020-05-16 Adding safer write strobe generator. Working on board.
    [cft-bus.kicad_pcb, cft-bus.sch, cft_ar.sch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]
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2020-05-20 Reworking CTL and BUS boards. Added WAITING# signal to bus.
    [bus.sch, cfg_reg_ir.sch, cft-bus.sch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]
2020-05-22 Reworking boards for new bus definitions and control store.
    [bus.sch, cft-bus.kicad_pcb, cft-bus.sch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]
2020-05-24 Fixing serious potential processor bug by readjusting clocks and establishing standard waveforms.
    [bus.sch, cft-bus.sch, cft-ctl.sch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]
2020-05-24 Just four tests failing now, still working at processor timings.
    [alu_decoder.sch]
2020-05-25 Fixed timing issues with MBU, improving write waveforms.
    [cft-bus.kicad_pcb, cft_ws_busen.sch, mbu_control.sch]
2020-05-25 Worked out simpler Wait State and Write drivers.
    [cft-bus.kicad_pcb, cft_ws_busen.sch]
2020-05-25 Wait states working in Verilog, using greatly simplified circuitry.
    [bus.sch, cft-ctl.sch]
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2020-05-30 Reverted pinout to drop WEN. Routing BUS board.
    [bus.sch, cft-bus.kicad_pcb, cft-bus.sch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]
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2020-06-25 Fixed erratum: changed '00 to '32'.
    [cft-front-panel.kicad_pcb, cft-front-panel.sch, cft_front-panel-halfrow.sch]
2020-06-26 Generated rev F (2026) front panel module to fix wiring SNAFU.
    [cft-front-panel-1951.kicad_pcb, cft-front-panel-1951.sch, cft-front-panel.kicad_pcb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]
2020-06-26 Fixed position of C6
    [cft-front-panel.kicad_pcb]
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2020-07-07 Adding framework fixture to tests.
2020-07-09 Added true random power-on reset values to '670.
2020-07-09 Added TST sub-device, fixed I/O ticks and interrupts.
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2020-07-11 Minor fixes to the borad layout.
    [Serial_Shifter.sch, cft-alu.kicad_pcb, cft_alu_rom.sch]
2020-07-11 ALU, Interrupt and MEM bug fixes.
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2020-07-11 Minor fixes to the ALU board.
    [cft-alu.kicad_pcb]
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2020-07-11 Added interactive BOM to CTL, REG, ALU, BUS, and MEM.
    [cft-alu.kicad_pcb, cft-bus.kicad_pcb, cft-ctl.kicad_pcb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]
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2020-10-09 Fixed DFP hardware bug.
    [cft-dfp-scan.sch]
2020-10-09 Resolving DFP firmware bugs.
    [driver_avr.c]
2020-10-09 Fixing DFP hardware bug.
    [driver_avr.c]
2020-10-14 Corrected bug: using OR instead of NOR gates to enable frot panel latches.
    [cft-front-panel.kicad_pcb, cft_front-panel-halfrow.sch]
2020-10-14 Enabling front panel module enables when WR strobes or SCANEN# is asserted.
    [cft-dfp-scan.sch]
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2020-11-08 TIC board bug fix.
    [irc.sch, irq_ff.sch, tic.kicad_pcb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]
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2020-11-09 Remove 25% duty cycle from test patterns
    There are large decoupling capacitors installed on all four front panel
    modules now, so ground bounce shouldn't be an issue and we can punish the
    light assembly with the full brightness of the LEDs. Getting nearly 510mA
    of current draw now, with no apparent adverse effects.
    [driver_avr.c]
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2020-11-15 Debug REG card problem
    [driver_avr.c]
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2020-11-21 Fix REG 2021 erratum: PC.DEC# left floating
    Created REG board revision 2047 to fix issue. The floating DEC signal makes
    incrementing the PC unreliable as DEC has to be deasserted for INC to work.
    [bus.sch, cft-reg-2021.kicad_pcb, cft-reg-ac.sch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]
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2020-11-28 Add strings for cold reset and no confirmation error
    [proto.h]
2020-11-28 Fix errors in diagnostics
    1. Call wdt_reset() to keep the tests running past 2s.
    2. Add paranoid bus tristating during tests to avoid diagnostics failing
    due to e.g. IBus contention.
    [driver_avr.c]
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2020-12-01 Fix issues in character input and RADDR diagnostics
    [driver_avr.c]
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2020-12-05 Fix last CTL issues, prepare for manufacturing
    [cft-ctl.kicad_pcb, cft-ctl.sch, cft_clk.sch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]
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2020-12-07 Rework DFP schematics for Revision B
    [cft-dfp-bushold.sch, cft-dfp-scan.sch, cft-dfp.sch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]
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2021-01-02 Reconnect MEM and IO signals to peripheral bus
    [dfp-bus-right.sch, edge_connectors.sch]
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2021-02-12 Add Eurocard experiment
    This new Board0 is a 6U×28cm job and includes all of CTL, currently all of
    BUS, and half of REG (PC and DR). The other half (AC and SP) makes more
    sense near the ALU, and saves 16 control bus pins.
    [16bit-mask-generator.sch, Serial_Shifter.sch, V Register.sch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]
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2021-03-04 Bug fixes, work on MBU testbench
    [mbu_control_gal_tb.v]
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2021-03-20 Rework connector signal assignmenet
2021-03-21 Rework peripheral connector
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2021-05-02 Fix doubly-allocated pin
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2021-05-09 Add missing pull-down resistors
    [cpu_microcode_store.sch]
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2021-05-10 Fix interrupt tests
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2021-05-20 Drop CXO & 16 MHz driver Vcc, add series resistors
    [cft_clk.sch]
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2021-05-28 Add SRU GAL, layout and route Board 1
    [Serial_Shifter.sch, alu_decoder.sch, cft-board1.kicad_pcb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]
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2021-05-29 Fix IRC schematics and route Board 1
    [Serial_Shifter.sch, alu_decoder.sch, alu_port_a.sch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]
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2021-06-17 Minor schematic and board fixes
    [Serial_Shifter.sch, cft-board1.sch, cft-reg-ac.sch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]
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2021-06-22 Start MEM board schematic, clean up old files
    [bus.sch, cft-6U-card-bare.kicad_pcb, cft-ctl-dip.kicad_pcb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]
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2021-07-11 Modify DFP to accept Arduino Mega 2560, place and route
    [cft-dfp-bushold.sch, cft-dfp-scan.sch, cft-dfp.kicad_pcb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]
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2021-07-11 Move pins on peripheral connector pinout to allow for 12V supply
    [cft-board0.sch]
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2021-08-05 Rearrange front panel modules, add MFD2 and AB/DB to panel v.11
    [cft-dfp-scan.sch, cft-dfp.kicad_pcb, cft-dfp.sch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]
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2021-08-15 Fine-tuning DFP board, add signal conditioning, fix minor bugs
    [cft-dfp-bushold.sch, cft-dfp-scan.sch, cft-dfp.kicad_pcb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]
2021-08-15 Fix device name case
2021-08-15 Fix DRC/ERC bugs
    [cft-dfp-scan.sch, cft-dfp.kicad_pcb, cft-dfp.sch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]
2021-08-15 Restructure schematics, fix major I/O pod bug
    [cft-dfp-scan.sch, cft-dfp.kicad_pcb, cft-dfp.sch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]
2021-08-15 Fix DFP pod issues
    [cft-dfp.kicad_pcb, pod.sch, pods.sch]
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2021-08-16 Add DIN bus, move old board out of the way
    [bus.sch, tic-r2044.kicad_pcb]
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2021-08-21 Restore file deleted by mistake
    [edge_connectors.sch]
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2021-08-29 Fix silkscreen erratum (PC→DR)
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2021-09-14 Move capacitors to make space for subrack rail
    [cft-backplane-peripheral.kicad_pcb]
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2021-09-15 Fix bugs, prepare for manufacture
    [cft-dfp.kicad_pcb]
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2021-09-23 Fix eDIP socket 3D
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2021-09-25 Fix state output bug; add TRACE output level
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2021-10-10 Fix PB0 RN601 not connected to ground.
    [cft-board0.sch, cft_microcode.sch]
2021-10-10 Will try 74HC74, can't source AC family in DIP
    [cft_int_fsm.sch]
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2021-10-24 Move pod decoding to PLDs and reroute. Various other fixes
    [cft-dfp-scan.sch, cft-dfp.kicad_pcb, cft-dfp.sch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]
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2021-10-26 Plot DFP PCB (rev 2133a) and create order
    [bus_connectors.sch, cft_dfp_ws.sch, pod.sch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]
2021-10-29 Fix .gigignore pattern for Gerber outputs
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2021-10-31 Fix pin allocation erratum
    [driver_avr.c]
2021-11-01 Correct table of ALU operations
    [cft_alu_rom.sch]
2021-11-01 Fix signatures/filenames of DP decoder GALs
    [dfp_io.sch]
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2021-11-06 Fix LED definitions, add banner
    [driver_avr.c, proto.h]
2021-11-07 Fix DFP detection logic
    [driver_avr.c]
2021-11-07 Fix DFP board detection
    [driver_avr.c]
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2021-11-20 Fix IC values that changed due to Kicad bug
    [dfp_io.sch]
2021-11-21 Fix silkscreen error
    [dfp_io.sch]
2022-02-21 Resolve bus contention issue
    [driver_avr.c]
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

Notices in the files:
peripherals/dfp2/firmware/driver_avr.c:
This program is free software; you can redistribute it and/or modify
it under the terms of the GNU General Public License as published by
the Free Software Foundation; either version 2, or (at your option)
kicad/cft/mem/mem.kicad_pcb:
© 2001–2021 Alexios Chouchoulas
